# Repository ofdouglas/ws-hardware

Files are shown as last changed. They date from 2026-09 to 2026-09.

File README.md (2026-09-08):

# WireSpaces hardware

Status: draft · Owner: project maintainer · Updated: 2026-09-06

Hardware experiments for WireSpaces (WS), starting with a small four-MCU bench board. This repository is a design scaffold, not a fabrication release. Board1 has a complete draft KiCad schematic, reconciled counts and [initial unrouted PCB placement](boards/board1/kicad/placement.md). Schematic approval, detailed placement/routing and hardware qualification remain. This is not a validated fabrication or ordering package.

## Start here

1. Read [agent instructions](AGENTS.md) and [document/decision conventions](docs/DESIGN_PRINCIPLES.md).
2. Read [system context](docs/WIRESPACES_SYSTEM_CONTEXT.md) and [family architecture](docs/HARDWARE_ARCHITECTURE.md).
3. Check the [ADR index](docs/decisions/README.md) before changing a decision.
4. Work from [Board 1 requirements](boards/board1/requirements.md), then its [current design overview](boards/board1/README.md), [pinmap](boards/board1/pinmap.md) and [BOM](boards/board1/bom_internal.csv).

```text
ws-hardware/
├── AGENTS.md
├── README.md
├── docs/
│   ├── WIRESPACES_SYSTEM_CONTEXT.md
│   ├── HARDWARE_ARCHITECTURE.md
│   ├── DESIGN_PRINCIPLES.md
│   ├── PART_SELECTION_POLICY.md
│   ├── SOURCE_NOTES.md
│   └── decisions/                 # index, template, numbered ADRs
├── boards/board1/
│   ├── README.md
│   ├── requirements.md
│   ├── pinmap.md
│   ├── bom_internal.csv
│   └── kicad/                    # board CAD workspace; see board status
└── libraries/
    ├── symbols/
    └── footprints/
```

Board 1's Rev A networking scope has one STM32 gateway, three SAM leaves, two shared CAN-FD buses, an onboard multidrop UART, a private SAM UART ring, USB power/VCP, one external RS-485, signal terminals for both CANs and RS-485 with ground, and debug access. The full bench backbone is future work. Exact MVP inclusion is controlled by the requirements status rows, not by this overview.

Use **Host**, `HostId`, `SrcHostId`, and `DestHostId`. A PC is a PC/test controller; a WS Host is a protocol identity and need not be a PC.

See [source provenance](docs/SOURCE_NOTES.md). Source drafts provide context, not automatic approval for added hardware. Keep small, reviewable changes with requirement IDs and evidence. Resolve the blocking questions in Board 1 requirements before schematic freeze.

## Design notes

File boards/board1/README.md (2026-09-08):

# Board 1 Rev A

Status: complete Rev A schematic and initial unrouted PCB placement in KiCad 7.0.11; gateway corrected by ADR-043. Part acceptance does not establish electrical or fabrication readiness.

Board 1 is a four-MCU WireSpaces lab: one STM32G473RBT6 gateway and three ATSAMC21G17A-AUT leaves. Each MCU connects to both shared CAN-FD buses and the onboard multidrop UART; the SAMs also form a private UART ring. The gateway provides USB VCP and one external ST3485EBDR RS-485 port. Both CAN pairs and RS-485 have terminal-block access with ground.

USB-B powers an independent FT232HL bridge through the TPS22810 attachment ramp. FTDI PWREN# enables the TPS560430 main 3.3 V converter through MC74HC1G14DBVT1G. SN74LV125APWR isolates VCP TX/RX/RTS/CTS when main power is off. Rev A requires an active PC and must fit the 500 mA configured USB budget; full-load and startup qualification remain open.

The gateway targets 168 MHz and 12 Mbaud VCP. All four MCUs and the FTDI have independent selected 12 MHz crystals and initial load capacitors. Other link rates still need qualification. Each MCU has SWD, a dedicated 115200-baud text UART, a combined 1x8 timing/debug header and an LED; a fifth LED indicates board power. General-purpose breakouts are deferred under ADR-041. Seven 1×2 communications measurement headers expose both CAN pairs, RS-485, all three directed UART-ring hops and UART_MD per ADR-046; twelve rail/reset/boot/core pads and six ground headers remain.

## Current design documents

| Topic | Working document |
|---|---|
| Complete editable CAD and review PDF | [KiCad project](kicad/README.md) |
| Scope and authoritative question status | [Requirements](requirements.md) |
| Accepted decisions; do not routinely reopen | [ADR register](../../docs/decisions/README.md) |
| Parts, quantities, evidence | [BOM view](BOM.md), [CSV](bom_internal.csv), [remaining selections](remaining_parts.md) |
| Unfinished implementation choices | [Decision checklist](unfinished_decisions.md) |
| USB input, sequencing and current estimates | [USB input](usb_input.md), [model maintenance](models.md) |
| Bridge, EEPROM, VCP isolation and recovery | [USB VCP](usb_vcp.md) |
| Main converter and distributed capacitors | [Buck](buck_tps560430.md), [decoupling](decoupling.md) |
| PHYs, protection and UART_MD | [Interfaces](interfaces.md) |
| External bus networks | [Termination](termination.md), [RS-485 bias](rs485_bias.md) |
| Oscillators and clock trees | [Crystal networks](crystal_networks.md), [clocking](clocking.md) |
| MCU allocation and breakout details | [Pinmap](pinmap.md), [Timing headers](timing_headers.md) |
| Existing library artifacts and checks | [Symbol catalog](../../libraries/symbols/README.md), [IC coverage](../../libraries/symbols/remaining_ic_symbol_checks.md) |

Use Host/HostId terminology. Requirements own scope and question status; accepted ADRs own decisions; CSV owns parts and quantities. Topic notes explain the current implementation without accepting new circuitry. Reviewed symbols do not imply a completed, validated board schematic or layout.

## Deferred scope

External 24 V power, additional transceivers (including CAN3 and the second Board 1 point-to-point RS-485), the full bench backbone and FPGA/fault instrumentation are later work. RS_485_MULTIDROP is descoped for Board 1, retained in the overall bench architecture. No future footprint or pin reservation is implied.

All MCU, network and connector sections are captured. The review corrected STM32 physical-pad errors and finalized timing interrupts, ordinary reset/boot, interface defaults and probe access. All components are now approximately placed on the [native PCB](kicad/board1.kicad_pcb), with the terminal opposite USB; see [placement notes and preview](kicad/placement.md). Remaining work is schematic approval/ERC, detailed placement/routing and bring-up, as staged in the requirements register.

ADR-042 fixes the timing/debug header pin order and adds 330 ohm near each of its six MCU signal pins (24 total). Automated CBUS reset/BOOT0 recovery is deferred to Rev B; Rev A retains ordinary reset, BOOT0-low defaults and independent SWD programming.

Checks: native KiCad export and full-board checker pass for239 schematic objects / 879 pins; the PCB connectivity is checked against the same native schematic. Prior G474 MCU/workbook evidence is qualified by the ADR-043 correction note. Initial-placement DRC found no component collisions; expected unrouted connections, SWD internal pad-clearance findings and USB edge-silk cleanup remain. ERC has not run (KiCad7CLI lacks it); no hardware validation. See [complete capture notes](kicad/README.md) and [placement checks](kicad/placement.md#checks-performed).

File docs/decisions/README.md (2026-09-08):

# Decision register

Status: draft index · Authority: individual accepted ADRs

## Current authority map

Read this map before the chronological register. An accepted ADR may retain only some clauses; its historical decision text does not override later accepted decisions. Part selection never closes qualification questions. Retain both ADR-026 IDs and cite their filenames; no renumbering is authorized.

| Topic | Current authority and surviving scope | Implementation |
|---|---|---|
| Family terminology / Rev A boundary | ADR-003/004/007; RS_485_MULTIDROP deferred for Board 1, retained for family | [Requirements](../../boards/board1/requirements.md) |
| USB power / input | ADR-001 domain policy; ADR-013 isolation; ADR-040 direct PWREN# enable/startup; ADR-019 ramp topology; ADR-022 47 nF/no supervisor; ADR-024 inverter; ADR-015/016 ESD scope; ADR-027/028/029/030 passives | [Input](../../boards/board1/usb_input.md), [VCP](../../boards/board1/usb_vcp.md) |
| Main buck | ADR-021 TPS560430 and total 500 mA criterion; ADR-025 exact LC/passives; no 90% floor or SC189 Cout ceiling | [Buck](../../boards/board1/buck_tps560430.md) |
| Decoupling | ADR-010 MCU/bypass allocation only; [ADR-026 core](026-sam-core-ceramic.md) ceramic; ADR-027 MPNs; ADR-025 local output | [Decoupling](../../boards/board1/decoupling.md) |
| Crystals / clocks | ADR-005 timing targets; ADR-014 MCU crystals; ADR-017 separate FTDI strategy; ADR-030 exact FTDI crystal; ADR-031 initial load caps and REF correction | [Clocks](../../boards/board1/clocking.md), [crystals](../../boards/board1/crystal_networks.md) |
| CAN / RS-485 | ADR-002 TCAN3413; ADR-034 ST3485/termination; ADR-035 termination MPNs; ADR-036 bias; ADR-037 CAN TVS; ADR-038 restricted RS-485 TVS envelope; ADR-039 bias MPNs | [Interfaces](../../boards/board1/interfaces.md), [termination](../../boards/board1/termination.md), [bias](../../boards/board1/rs485_bias.md) |
| Onboard UART | ADR-033 second LV125 driver; ADR-039 support resistors; actual rate unqualified | [Interfaces](../../boards/board1/interfaces.md) |
| Debug / recovery / connectors | ADR-011 SWD; ADR-018 EEPROM; ADR-042 defers ADR-023 CBUS recovery; [ADR-026 connectors](026-reva-connectors.md); ADR-032 text UART; ADR-039 rail/reset/boot/core pads and ground access; ADR-046 communications headers; ADR-041/042 combined timing/debug headers and series resistors; USR-37 shared pull-downs (timing_headers.md) | [Pinmap](../../boards/board1/pinmap.md), [remaining work](../../boards/board1/remaining_parts.md) |
| LEDs / GPIO | ADR-007 scope; ADR-029 LEDs; ADR-039 LED resistors; ADR-041 timing interface replaces general GPIO breakouts | [BOM](../../boards/board1/BOM.md) |
| Assembly / sourcing | ADR-009 plus current maintainer package rules; DigiKey-only sourcing policy | [Part policy](../PART_SELECTION_POLICY.md) |

Completion of an earlier proposal (for example ADR-024 pulls by ADR-028/030) is not wholesale supersession. Metadata lists replacements only; implementation links and this map also show completions. New engineering changes still require explicit acceptance and a new ADR where applicable.

Allocation-note reconciliation (2026-09-07): [pinmap](../../boards/board1/pinmap.md) and its workbook now distinguish current selections from unfinished implementation. [Unfinished decisions](../../boards/board1/unfinished_decisions.md) references the existing board questions; this editorial cleanup adds no accepted decisions or verified allocations.

## Chronological register

| ID | Title | Status | Scope |
|---|---|---|---|
| [ADR-001](001-usb-power.md) | USB power and independent VCP bring-up (power/isolation architecture) | accepted | Board 1 MVP |
| [ADR-002](002-can-transceivers.md) | CAN-FD transceiver selection (TCAN3413DR) | accepted | Board 1 CAN1/CAN2 |
| [ADR-003](003-terminology-and-mvp-boundary.md) | Host terminology and reduced first PCBA | accepted | Repository / Board 1 |
| [ADR-004](004-board1-mcu-baseline.md) | MCU baseline (gateway corrected by ADR-043; SAM selection retained) | accepted | Board 1 |
| [ADR-005](005-clock-and-vcp-speed.md) | Crystal clocks and 12 Mbaud gateway VCP | accepted | Board 1 Spin A |
| [ADR-006](006-reva-external-buses.md) | Rev A links and terminal access | superseded | Board 1 Rev A |
| [ADR-007](007-board1-rs485-power-scope.md) | Board 1 RS-485 scope, LEDs and GPIO | accepted | Board 1; bench multidrop retained |
| [ADR-008](008-main-buck-efficiency.md) | Main buck efficiency proposal | superseded | Board 1 main 3.3 V rail |
| [ADR-009](009-assembly-package-policy.md) | Assembly and package policy | accepted | Project-wide |
| [ADR-010](010-sc189-and-decoupling.md) | SC189 and Rev A decoupling | accepted | Board 1 main rail |
| [ADR-011](011-swd-debug-access.md) | Independent Cortex SWD headers and owned probes | accepted | Board 1 debug |
| [ADR-012](012-common-12mhz-crystal.md) | Common leaded 12 MHz crystal | superseded | Board 1, five oscillators |
| [ADR-013](013-enable-control-uart-isolation.md) | SC189 enable control and SN74LV125APWR | accepted | Board 1 Rev A; replaces ADR-001 main-switch implementation |
| [ADR-014](014-smaller-12mhz-crystal.md) | Smaller leaded 12 MHz crystal | accepted | Four MCU crystals; FTDI scope superseded by ADR-017 |
| [ADR-015](015-usb-data-esd.md) | RCLAMP0504S.TCT USB data ESD | accepted | Board 1 Rev A |
| [ADR-016](016-usb-protection-scope.md) | USB ESD and hot-plug protection scope | accepted | Board 1 Rev A |
| [ADR-017](017-separate-ftdi-crystal.md) | Separate accurate FT232HL crystal | accepted | Strategy; exact MPN subsequently accepted ADR-030 |
| [ADR-018](018-ftdi-eeprom.md) | AT93C56B-SSHM-B configuration EEPROM | accepted | Board 1 FT232HL bridge |
| [ADR-019](019-simple-vbus-input.md) | Simple slew-controlled USB input | accepted | Board 1 Rev A; replaces direct input attachment in ADR-013 |
| [ADR-020](020-ftdi-supply-reset.md) | FTDI supply-qualified reset with TLV803E | superseded | Board 1 Rev A; adds supervision to ADR-019 |
| [ADR-021](021-tps560430-main-buck.md) | TPS560430 main buck and USB-current criterion | accepted | Replaces ADR-010 converter/filter and efficiency floor |
| [ADR-022](022-fast-input-ramp.md) | Fast TPS22810 ramp without external FTDI supervisor | accepted | Board 1 Rev A |
| [ADR-023](023-cbus-gateway-recovery.md) | Dedicated CBUS gateway reset and BOOT0 | superseded | Rev A recovery deferred by ADR-042 |
| [ADR-024](024-pwren-inverter.md) | MC74HC1G14DBVT1G PWREN# inverter | accepted | Implements ADR-013; SMF6.0A alone retained |
| [ADR-025](025-buck-passives.md) | TPS560430 local passive MPNs | accepted | Five components; four unique parts |
| [ADR-026](026-reva-connectors.md) | Rev A debug, bus and GPIO connector MPNs | accepted | Implements ADR-007/011; B1-B009/022/027 |
| [ADR-026](026-sam-core-ceramic.md) | Ceramic SAM VDDCORE capacitors | accepted | Supersedes ADR-010 dielectric restriction |
| [ADR-027](027-ceramic-capacitor-mpns.md) | General ceramic capacitor MPNs | accepted | Decoupling and input timing; completes SAM core selection |
| [ADR-028](028-10k-pullup-resistor.md) | Common 10 kohm pull-up resistor | accepted | B051/B054 and bridge support |
| [ADR-029](029-led-vbus-components.md) | Orange LEDs and VBUS damping parts | accepted | B024/025/046/047 |
| [ADR-030](030-usb-crystals-support.md) | USB connector, crystal finalization and support resistors | accepted | REF tolerance conflict resolved by ADR-031 |
| [ADR-031](031-crystal-caps-ref.md) | Crystal capacitors and corrected REF resistor | accepted | Resolves ADR-030 REF tolerance conflict |
| [ADR-032](032-debug-uarts.md) | Independent MCU text debug UARTs | accepted | Four 115200-baud TX/RX/GND headers |
| [ADR-033](033-open-drain-uart-buffer.md) | Second SN74LV125APWR for onboard open-drain UART | accepted | B1-B066; implements B1-R003 |
| [ADR-034](034-rs485-termination.md) | ST3485EBDR and Rev A bus termination | accepted | B1-B021/067–070; B1-R026 |
| [ADR-035](035-termination-parts.md) | Exact termination resistor and jumper MPNs | accepted | B1-B067–070; B1-R026 |
| [ADR-036](036-rs485-bias.md) | RS-485 330 ohm bias network | accepted | B1-B071; B1-R016/021 |
| [ADR-037](037-can-tvs.md) | ESD2CAN24DBZRQ1 CAN TVS arrays | accepted | B1-B072; B1-R009/017 |
| [ADR-038](038-rs485-tvs.md) | ESDS452DBZR and restricted bench voltage envelope | accepted | B1-B073; B1-R016/017 |
| [ADR-039](039-bom-closeout-selections.md) | Resistors, UART support, header cuts and test access | accepted | B1-B008/011/026/027/059/071/074/075 |
| [ADR-040](040-startup-and-vcp-enable.md) | Conventional FTDI startup and direct PWREN# VCP enable | accepted | Supersedes ADR-013 rail-valid /OE prerequisite only |
| [ADR-041](041-timing-debug-headers.md) | Combined per-MCU timing/debug headers; general breakouts deferred | accepted | B1-R025/027; B1-B027/059 |
| [ADR-042](042-header-resistors-recovery-scope.md) | Header series resistors and Rev A recovery scope | accepted | Exact pin order, 24 series resistors; automated recovery deferred to Rev B |

| [ADR-043](043-gateway-part-correction.md) | Gateway transcription correction to STM32G473RBT6 | accepted | Supersedes ADR-004 gateway MPN only |

| [ADR-044](044-yageo-crystal-load-capacitors.md) | YAGEO 33 pF crystal load capacitors | accepted | Supersedes ADR-031 33 pF MPN only |

| [ADR-045](045-yageo-27pf-crystal-capacitors.md) | YAGEO 27 pF FTDI crystal capacitors | accepted | Supersedes ADR-031 27 pF MPN only |

| [ADR-046](046-communications-measurement-headers.md) | Communications measurement headers | accepted | Supersedes ADR-039 communications copper-pad scope; seven 1x2 headers including all UART-ring hops |

Use [template.md](template.md); next ID: ADR-047. Numbering is permanent.

Historical collision: both [connector selection](026-reva-connectors.md) and [ceramic SAM core selection](026-sam-core-ceramic.md) carry ADR-026. Preserve both IDs and histories; use the filename-qualified reference to distinguish them. BOM references now do this explicitly.

ADR-027 accepts the exact SAM core capacitor. ADR-030 finalizes the FTDI crystal. ADR-031 resolves the REF tolerance conflict and accepts oscillator load capacitors. These subsequent decisions do not erase earlier history.

Before changing an accepted choice, read the ADR and its evidence. A superseding decision requires explicit maintainer acceptance; part-selection acceptance alone does not establish implementation verification.

Implementation evidence: [library migration and TPS22810 DBV symbol](../../libraries/symbols/README.md) implements ADR-004/019/022. Archived SC189 remains superseded by ADR-021. No ADR status or numbering changed; board qualification questions remain open.

Additional implementation evidence for ADR-002/018/021: [exact-part symbols and checks](../../libraries/symbols/symbol_checks.md). Existing accepted decisions and open board qualifications are unchanged.

Implementation evidence: [remaining IC symbols and BOM coverage](../../libraries/symbols/remaining_ic_symbol_checks.md) implements the existing selected parts, including ADR-037/038. No decision acceptance or electrical qualification is changed.

Full Rev A schematic implementation (2026-09-07): [complete native CAD](../../boards/board1/kicad/README.md) and corrected pinmap/BOM implement the existing accepted scope. Routine defaults and connector footprints are recorded as engineering choices. No ADR acceptance or scope changed.

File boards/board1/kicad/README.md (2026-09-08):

# Board 1 KiCad project — complete schematic and initial PCB placement

Gateway correction (2026-09-07): STM32G473RBT6 is selected and captured per [ADR-043](../../../docs/decisions/043-gateway-part-correction.md). DS12288 references and older workbook/PDF snapshots below are prior G474 evidence, not G473 qualification. Recheck exact G473 AF/electrical limits under B1-Q005/008 before schematic approval.

Completed 2026-09-07 with KiCad 7.0.11, native schematic format20230121, revision A-draft. Open [board1.kicad_pro](board1.kicad_pro). The editable source is the authority for implemented connectivity. The [native PCB](board1.kicad_pcb) now has all components approximately placed, with no tracks, vias or zones. See [placement notes and checks](placement.md) and the [preview](review/board1-initial-placement.png). The outline and placement are provisional; no fabrication outputs have been created.

| Page | Source | Contents |
|---|---|---|
| 1 | [Overview](board1.kicad_sch) | Hierarchy and scope |
| 2 | [Power](power.kicad_sch) | Preserved USB input/ramp, buck, enable and power LED |
| 3 | [USB](usb_bridge.kicad_sch) | Preserved FTDI/EEPROM and four-channel VCP isolation |
| 4 | [Gateway](gateway.kicad_sch) | STM32G473, supplies, crystal, reset/BOOT0, SWD and timing/debug |
| 5–7 | [SAM0](sam0.kicad_sch), [SAM1](sam1.kicad_sch), [SAM2](sam2.kicad_sch) | Three independent SAMC21 circuits and headers |
| 8–9 | [CAN A](can_a.kicad_sch), [CAN B](can_b.kicad_sch) | Eight PHYs, per-PHY standby defaults and endpoint termination |
| 10 | [Interfaces](interfaces.kicad_sch) | UART_MD quad driver, RS-485/defaults/bias/termination, shared timing pulls |
| 11 | [Access](access.kicad_sch) | External terminal block, three TVS arrays, six ground headers, twelve test pads and seven communications headers |

[Complete 11-page review PDF](review/board1-complete.pdf). The earlier two-page power/USB PDF and capture_manifest.json are retained as historical capture evidence; the complete PDF is also an older capture snapshot. Use native schematic files and [complete_manifest.json](complete_manifest.json) for current review. The revised access page is available as [SVG](review/board1-access.svg).

## Capture and component reconciliation

239 schematic component objects comprise 227 fitted components/connectors and 12 PCB copper test pads; two removable CAN shunts are assembly accessories without additional PCB footprints. The strip-stock purchase and testpad/shunt exceptions are explicit in [schematic_bom_allocations.json](schematic_bom_allocations.json). All populated components have MPNs, references and footprint assignments in [bom_internal.csv](../bom_internal.csv); no count remains TBD. Evidence status stays unverified until the relevant approval checks finish.

The original 52 power/USB components retain their pin mappings, MPNs and values. Only hierarchy and the VBUS_RAW global name scope changed. The four GW_VCP nets now reach the gateway.

PCB spacing follow-up: the SAM timing headers are farther from the terminal,
the lower IC groups use more of the lower-right area, and every testpad has
function silkscreen and nearby ground access. See [test access](placement.md#test-access).

Routine completion choices: four reset pull-ups, three SAM SWCLK pull-ups and gateway BOOT0 pull-down use10k B080; NRST uses100n B081 and each SAM RESET uses10n B082. Eight10k CAN STB pull-ups B083 establish explicit standby. Four RS-485 defaults B023 establish shutdown/idle, and four debug RX10k pull-ups B060 establish idle. These reuse selected MPNs; they are engineering choices within authorized scope, not newly maintainer-accepted decisions. No automatic CBUS recovery or future circuitry was added.

Each timing/debug header has six independent330ohm branches near its MCU. Shared SYNC/TRIG each have one10k pull-down before fanout. Six separately purchased two-pin ground headers reuse PRPC002SAAN-RC and do not consume the eight spare positions in the timing-header strip.

B036 reconciles to37 actual main-rail100n bypasses; two unused planning reserves were removed. Main nominal capacitance becomes34.41uF. B007/B010 residual aggregates now have zero parts; B023 andB060 are fully enumerated. [Decoupling](../decoupling.md) and the generated BOM use the captured counts.

## Evidence and corrections

The MCU review found and fixed an actual workbook error in STM32 pads19–29: LED PA5 is pad19, VSSA pad27, VREF+ pad28 and VDDA pad29. Stable physical-pad IDs were retained. [Pinmap](../pinmap.md) links the corrected workbook and [MCU capture plan](../mcu_capture_plan.json). All208 MCU pads were independently compared to that plan/workbook and a fresh KiCad netlist. Timing interrupts are GWPC0/PC1 EXTI0/1 and SAMPA02/PA03 EXTINT2/3; events use GWPC2/PC3 and SAMPB08/PB09.

The RS-485 RO-to-PC11 high-level screen passes: ST3485 VOH>=2.0V at4mA; PC11 FT_f supports alternate guaranteed VIH=0.49VDD+0.26, at most1.9015V with3.35V main DC rail (ST DS12288Rev6 Table54pp128–129). This is a static limit comparison, not a measured waveform margin. FTDI-to-LV125 still has the previously recorded55mV high-level DC headroom before ripple/ground error; use short paths and validate12Mbaud at bring-up.

[Footprint checks](footprint_checks.md) record manufacturer-drawing checks and the two new portable connector footprints. All source symbols are embedded. The standard STM32 exact variant is flattened from its KiCad library inheritance without changing its pins. The existing Board1 FT232HL symbol retains corrected VCCD/EECLK/EECS electrical types. PWR_FLAGs are annotations, not physical circuitry.

## Checks and remaining stages

Run `python3 scripts/check_board1_complete.py` from the repository root. It exports native KiCad XML and checks239 objects/879 pins, explicit NCs, fields, exact numbered-pad coverage, all BOM quantities and independent topology rules for MCU ownership, SWD, header branches, ring, UART_MD, CAN polarity/termination/protection, RS-485, separate SAM core rails and preserved power/USB circuitry. The fresh PCB/netlist comparison and independent topology checks pass. The full schematic/BOM check now stops at the preexisting B059 purchased-header MPN mismatch; see placement notes. The older PDF was rendered and reviewed at its original capture stage. Capture scripts are one-time provenance, not the editing authority; do not rerun over subsequent manual CAD edits.

ERC has not run: KiCad7 CLI exposes schematic export but no ERC command. Run Eeschema ERC before schematic approval. PCB DRC was run through the Python API for [initial placement](placement.md#checks-performed); it is not a clean fabrication DRC. Exact assembly/mating, detailed placement and routing remain layout checks. No hardware validation is claimed. The stale ADR-040 research link now points to its verified historical Git revision; the accepted decision text is unchanged. The current document and purchasing audits flag the preexisting B027/B059 purchase reconciliation; see ../digikey_upload_review.md.

Manual bench operating limits: external timing/debug sources must be3.3V, and drive only while3V3_SYS is on; connect after configuration and disconnect before power-off/suspend. Series resistors do not provide power-off isolation. Disable/disconnect the RS-485 peer before local power-off/suspend because the accepted330ohm bias can feed main power. SWD VTref is sense only. First programming uses connect-under-reset with external bus peers disconnected, then firmware establishes PHY defaults. These limits avoid adding automatic isolation to this prototype.

Bring-up: program/read back FTDI EEPROM per [USB VCP](../usb_vcp.md); check current/startup/suspend, MCU reset/boot, crystal start/frequency,12Mbaud VCP and chosen CAN/UART rates. SAM EIC uses synchronous active-run mode; clear flags after enable and heed DS80000740T errata for the fitted revision. Measurements are not draft-capture blockers.

Primary references: [STM32 DS12288](https://www.st.com/resource/en/datasheet/stm32g474rb.pdf), [SAM DS60001479J](https://ww1.microchip.com/downloads/aemDocuments/documents/MCU32/ProductDocuments/DataSheets/SAM-C20-C21-Family-Data-Sheet-DS60001479J.pdf), [TCAN3413](https://www.ti.com/lit/ds/symlink/tcan3413.pdf), [ST3485](https://www.st.com/resource/en/datasheet/st3485eb.pdf), [LV125](https://www.ti.com/lit/ds/symlink/sn74lv125a.pdf), [FT232H v2.2](https://www.ftdichip.cn/Support/Documents/DataSheets/ICs/DS_FT232H.pdf). FTDI current errata/on-hand silicon reconciliation remains an approval check; no retrieved source attachments were edited.

ADR-046 communications access: J19/J20 CAN H,L; J21 RS-485 A,B; J22/J23/J24 ring01/ring12/ring20 signal,GND; J25 UART_MD signal,GND. All are fitted 1×2 0.1-inch headers with function and pin-order silkscreen. TP1–TP12 remain copper pads.

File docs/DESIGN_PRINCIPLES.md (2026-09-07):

# Design principles and document conventions

Status: draft policy · Authority: repository workflow · Updated: 2026-09-06

Prefer a small board that brings up reliably, exposes the intended networking experiments, and can be inspected and reworked. Add complexity when a concrete experiment needs it. Provide debug, reset, rail measurements, and observable links before sophisticated instrumentation. Keep power-up and unpowered-interface behavior explicit.

## Authority

1. Explicit current maintainer instructions, with provenance recorded.
2. Accepted ADRs within their stated scope.
3. Accepted board requirement rows for implementation scope; family conventions apply only where that scope includes them.
4. Proposed requirements, architecture drafts, source notes, and diagrams are planning inputs.

If instructions and recorded decisions conflict, record the conflict and reconcile the affected records before implementation. An accepted ADR does not silently accept every row linked to it. Schematics encode implemented connectivity; verified pinmaps document reviewed allocation; the BOM records intended assembly. Disagreement among these is a defect to resolve, not a new decision.

## Status vocabulary

| Object | Allowed status | Meaning |
|---|---|---|
| Document | draft, reviewed | Editorial maturity; never bulk acceptance of its contents |
| Requirement / ADR | proposed, accepted, deferred, rejected, superseded | Candidate; explicit decision; outside current scope; declined; replaced with link |
| Pin/BOM evidence | unverified, verified | Primary-source checks absent or completed with evidence |
| Open question | open, resolved | Unanswered, or answered with decision/evidence link |

`TBD` means unknown; `NA` means inapplicable. Avoid blank cells except where a file schema explicitly permits them. Future means scope, not a promise to populate or reserve pins. DNP means a real designed footprint omitted from an assembly variant; it is not interchangeable with deferred.

Keep stable IDs: `B1-Nxx` nodes, `B1-Lxx` links, `B1-Rxxx` requirements, `B1-Qxxx` questions, `B1-Pxxx` pin rows, `B1-Bxxx` BOM rows, `ADR-NNN` decisions. IDs are never reused. Board requirements own question status; other documents reference question IDs rather than duplicate answers.

## Decision discipline

Check `docs/decisions/README.md` before proposing a choice. Accepted decisions stay settled until new evidence or an explicit changed requirement justifies a replacement ADR. New ADRs include alternatives, consequences, evidence, and precise acceptance criteria. Record accepted date and who/what instruction accepted it. Do not rewrite accepted history to resemble a fresh decision.

Proposals may guide reversible planning but do not authorize fabrication. Routine edits within accepted scope need no fresh decision. Keep one change focused; include requirement/ADR IDs and update derived files in the same change.

## Proportionate design and stopping rules

Rev A is a manually operated bench prototype. Use conventional manufacturer application circuits and the accepted operating scope. Distinguish behavior needed during normal operation from later bring-up observations and hypothetical faults. Do not silently strengthen requirements into guaranteed operation across arbitrary brownouts, corrupt configuration, abnormal external drive or every supply-collapse order. Actual absolute-maximum violations, incompatible logic levels and output contention in intended use remain material concerns.

A missing guarantee is uncertainty, not automatically a failure. Identify a plausible mechanism and material consequence before expanding research or proposing mitigation. Use existing engineering allowances for negligible contributions; refine a calculation when it can change a component, connection or budget decision. Do not repeatedly recheck settled evidence without a relevant change.

Routine reversible implementation choices can be made within accepted scope and documented in the circuit/BOM notes. Reserve ADRs for meaningful scope, architecture or durable policy decisions, and for changes to accepted ADRs. Maintainer acceptance and engineering evidence are separate; passing a pin check need not wait for bench tests, and an accepted circuit need not be called electrically verified.

Classify remaining work in the existing question's resolution text or working checklist without creating another authority register:

| Disposition | Treatment |
|---|---|
| Implementation detail | Resolve while capturing; record chosen wiring/value and rationale |
| Schematic check | Verify relevant pins, mux, limits and connectivity before schematic approval |
| Bring-up check | Measure on assembled hardware; does not block draft capture |
| Deferred / no change | Outside scope or insufficient reason to alter the conventional circuit |

For a blocker, state trigger, mechanism, consequence, evidence and affected gate. Block only the dependent work. A broad open question may contain a settled decision and pending measurements: record the settled subitem explicitly rather than repeatedly reopening it. No need to close the whole question prematurely.

Stop when the evidence supports an implementation and further research is unlikely to change it. If uncertainty is material, define one bounded next check. Reviews should prioritize concrete errors and can conclude “no change needed.” Extra complexity needs a demonstrated benefit against an accepted requirement.

## Review stages

- Draft capture: draw settled circuitry and resolve routine details; label unresolved connections/proposals. Do not require future measurements or complete layout qualification to start.
- Schematic approval: check exact package pins/mux, supply and logic compatibility, clocks/reset/debug, PHY behavior, connector numbering and symbol mappings; reconcile BOM and resolve or document actual ERC findings. Review relevant current/startup calculations. Mechanical footprint qualification must finish before layout commitment.
- Layout approval: review land patterns, placement/routing for intended rates, test access and silkscreen; reconcile CAD/pinmap/BOM and actual DRC findings.
- Prototype release: review assembly BOM and fabrication outputs tied to a revision, plus a finite bring-up checklist. Unperformed bring-up measurements are expected at this stage and must not be represented as passed.
- Bring-up: measure startup, power, clocks, programming and link performance under intended conditions. Investigate faults revealed by results. Broader production/compliance qualification is a separate scope decision.

These stages define when work is needed, not claims that checks have passed. Active summaries must show current decisions; remove withdrawn recommendations and their derived parts/calculations. Historical accepted ADR text remains with an explicit supersession notice.

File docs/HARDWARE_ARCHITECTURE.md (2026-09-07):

# Hardware family architecture

Status: draft · Authority: family direction, conditional on board scope · Source: SRC-ARCH

The September 1 bench draft describes a larger system than Board 1 MVP. Its “freeze summary” is not a blanket rev-1 requirement after USR-01. [Board 1 requirements](../boards/board1/requirements.md) own the MVP boundary.

## Conventions for the proposed MVP

| Area | Direction | Controlling record |
|---|---|---|
| Roles | One gateway and three leaves; physical labels are not HostIds | B1-R001; ADR-004 |
| CAN | Two independent shared CAN-FD buses, all four nodes on each | B1-R002; ADR-002 |
| UART | Shared open-drain medium plus private directed leaf ring | B1-R003, B1-R004 |
| Bring-up | USB 2.0 Standard-B power and dedicated FT232HL VCP; no dependency on native USB | B1-R005; ADR-001 |
| Power | Accepted independent bridge domain and controlled main-board power; TPS560430 selected ADR-021; TPS22810/47 nF input ramp ADR-022; SN74LV125APWR isolation ADR-013 and MC74HC1G14DBVT1G enable inverter ADR-024; qualification open | B1-R006; B1-Q002 |
| Debug | Independent SWD access to each MCU; accessible reset and rail measurements | B1-R007, B1-R008 |
| Connectors | Pinouts, polarity, voltage, and termination state documented at each interface | B1-Q004 |

No connector family, pin numbers, transceiver, oscillator, protection network, or supply capability is validated here.

## Future/full bench contract — excluded from MVP unless explicitly promoted

| Area | Inherited direction | MVP treatment |
|---|---|---|
| Signal backbone | 17 twisted pairs; short approximately 10 cm FFTP-style jumpers and polarized headers | Deferred; no connector or pin allocation implied |
| CAN1/2/3 | Passive IN-to-OUT paths; each independently terminable even without a local PHY | Applies to future backbone boards only |
| CAN3 local port | STM32 connection with initial DNP PHY in full draft | Deferred, including footprint and termination |
| RS-485 | RS_485_MULTIDROP (historical SHARED) passes through; RS_485_LEFT/RIGHT terminate separate p2p hop segments and require forwarding | Rev A one p2p port; expanded Board 1 LEFT/RIGHT only; bench multidrop retained |
| 24V_AUX | Optional separate two-conductor passive trunk; nominal 24 V, draft chain maximum 2 A | Deferred; not a Board 1 input rating |
| Local power tap | Protected branch converts to 5 V; downstream trunk never depends on local regulation/firmware | Deferred |
| Source protection | One external 24 V source per chain; reverse polarity/current protection at injection; isolate USB and local 5 V sources | Conditional on future multiple-input implementation |
| Auxiliary output | Protected 5 V, draft 500 mA maximum when supply budget permits | Deferred from Rev A; no USB-only guarantee |
| Test control | External single SPI master; ordinary DUT boards slaves; MCP23S17 family preference | Deferred |
| Triggers/timing | TEST_TRIG0/1, SYNC inputs; selected TIMING0/1 drivers, others high-Z | Deferred |
| Fault injection | External trigger plus local deterministic logic; safe inactive startup; independent of DUT firmware | Deferred |
| Ethernet/T1S | Ordinary Ethernet separately cabled; backbone pair reserved for T1S | Deferred |
| FPGA | Timing capture, traffic generation, segment bridges and controlled frame loss | Future separate instrumentation board |

The draft pair map is functional, not an approved connector pinout: 1–3 CAN1/2/3; 4 RS485_SHARED (RS_485_MULTIDROP, retained for bench); 5 RS485_HOP; 6 T1S_RESERVED; 7–10 TEST_SPI SCLK/MOSI/MISO/CS each with GND; 11 SYNC/GND; 12–13 TEST_TRIG0/1 with GND; 14–15 TIMING0/1 with GND; 16–17 spare. Pin order and electrical details remain unapproved.

Normal WS operation must remain useful without the test-control plane. A future backbone board must explicitly adopt the applicable contract; being a WireSpaces board alone does not impose every connector or PHY.

Board 1 clock/VCP requirements (ADR-005): 168 MHz gateway, 12 Mbaud VCP with RTS/CTS and four-signal power-off isolation; each MCU has its own external crystal. Crystal frequencies and remaining clock trees are implementation work in B1-Q008.

Rev A interface scope: ADR-007 includes both CANs and one RS-485 with ground, plus GPIO breakouts; additional transceivers and external power remain deferred. Canonical CAN names are FD_CAN_A/FD_CAN_B (historical CAN1/CAN2).

ADR-007 is Board 1-specific. Its omission of RS_485_MULTIDROP does not remove that function from the family architecture. Board 1 also requires five LEDs total and spare GPIO breakouts; parts and four GPIOs/MCU are selected under ADR-029/039; electrical qualification remains open.

## Future Board 1 power clarification — USR-12

The intended external-power chain is protected 24 V -> regulated 5 V -> FTDI supply branch and sequenced 3.3 V converter -> MCUs/transceivers. Thus the downstream 3.3 V converter need not accept 24 V. External power remains deferred from Rev A.

Implementation proposal for that later revision: select between USB VBUS and the locally generated 5 V with reverse-current blocking before feeding the system domains; never directly tie the two sources together. Revisit bridge USB-presence sensing, self-powered configuration and main-board enable policy for externally powered operation. Existing Rev A active-PC/suspend behavior stays authoritative until that revision adopts a new power contract. Two-stage efficiency is the product of stage efficiencies; Rev A efficiency is governed by the full-load 500 mA USB criterion in ADR-021, with no fixed 90% floor. The later 24 V path has no accepted converter efficiency target. See [current power model](../boards/board1/models.md).

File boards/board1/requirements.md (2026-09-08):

# Board 1 requirements

Status: draft · Authority: per-row status · Updated: 2026-09-07

All `proposed` rows are extracted or suggested starting requirements, not a frozen schematic specification. `accepted` applies only to explicit decisions. Unresolved values are staged according to DESIGN_PRINCIPLES.md; draft capture is now complete. Source IDs resolve in [SOURCE_NOTES](../../docs/SOURCE_NOTES.md).

The [unfinished implementation decisions](unfinished_decisions.md) checklist distinguishes remaining choices from verification of selected parts. Question status remains in this register; the 2026-09-07 allocation-note cleanup changes no acceptance or evidence status.

## Nodes — accepted MCU selection (B1-R001)

| ID | Label | Role | Exact selected MPN | Qty | Source |
|---|---|---|---|---:|---|
| B1-N01 | GW | Gateway | STM32G473RBT6 | 1 | ADR-043 maintainer correction |
| B1-N02 | SAM0 | Leaf | ATSAMC21G17A-AUT | 1 | SRC-ARCH §3.2; USR-15 / ADR-004 |
| B1-N03 | SAM1 | Leaf | ATSAMC21G17A-AUT | 1 | SRC-ARCH §3.2; USR-15 / ADR-004 |
| B1-N04 | SAM2 | Leaf | ATSAMC21G17A-AUT | 1 | SRC-ARCH §3.2; USR-15 / ADR-004 |

The PC is external test equipment. HostIds are deployment values, not physical node labels.

## Links — Rev A scope per ADR-007; implementation details pending

| ID | Net/group | Endpoints / direction | Medium | Rate | Requirement |
|---|---|---|---|---|---|
| B1-L01 | FD_CAN_A | GW, SAM0, SAM1, SAM2; shared | CAN-FD | TBD | B1-R002 |
| B1-L02 | FD_CAN_B | GW, SAM0, SAM1, SAM2; shared, separate from FD_CAN_A | CAN-FD | TBD | B1-R002 |
| B1-L03 | UART_MD | GW, SAM0, SAM1, SAM2; shared | Open-drain-equivalent UART; ADR-033 driver; ADR-039 pulls | TBD | B1-R003 |
| B1-L04 | RING_01 | SAM0 TX -> SAM1 RX | Point-to-point UART | TBD | B1-R004 |
| B1-L05 | RING_12 | SAM1 TX -> SAM2 RX | Point-to-point UART | TBD | B1-R004 |
| B1-L06 | RING_20 | SAM2 TX -> SAM0 RX | Point-to-point UART | TBD | B1-R004 |
| B1-L07 | UART_VCP | PC USB <-> bridge UART <-> GW | Dedicated USB-UART VCP | 12 Mbaud capability | B1-R005; B1-R014 |
| B1-L08 | RS485_EXT | GW <-> external endpoint | RS-485; point-to-point half-duplex; ADR-034 | Up to 12 Mbps | B1-R016; B1-R021 |
| B1-L09 | DEBUG_GW | GW MCU TX/RX to external adapter; GND | Dedicated 3.3 V logic UART proposal | 115200 baud | B1-R025 |
| B1-L10 | DEBUG_SAM0 | SAM0 MCU TX/RX to external adapter; GND | Dedicated 3.3 V logic UART proposal | 115200 baud | B1-R025 |
| B1-L11 | DEBUG_SAM1 | SAM1 MCU TX/RX to external adapter; GND | Dedicated 3.3 V logic UART proposal | 115200 baud | B1-R025 |
| B1-L12 | DEBUG_SAM2 | SAM2 MCU TX/RX to external adapter; GND | Dedicated 3.3 V logic UART proposal | 115200 baud | B1-R025 |

USR-04 targets several Mbaud for onboard UARTs, exact rates TBD. This replaces the older exploratory approximately 1 Mbit/s target; the open-drain electrical limit still requires validation. One ring UART per leaf uses TX to the next leaf and RX from the preceding leaf; GW is excluded from the ring.

## Requirement register

| ID | Scope | Status | Requirement | Verification / acceptance evidence | Basis / decision |
|---|---|---|---|---|---|
| B1-R001 | MVP | accepted | Populate exactly the four nodes above | Exact datasheets/errata, pin/resource review, schematic and BOM | USR-15; SRC-ARCH §3; ADR-004; B1-Q005 |
| B1-R002 | MVP | accepted | Attach all four nodes independently to CAN1 and CAN2; support simultaneous traffic | Eight PHY channels accounted for; electrical review; bench traffic at accepted rates | SRC-ARCH §4.1; ADR-002 |
| B1-R003 | MVP | accepted | Provide shared onboard open-drain UART among all four nodes | Review drive/pull-up/reset behavior; measure rise time and traffic at accepted rate | SRC-ARCH §5.1; USR-27; ADR-033; B1-Q003 |
| B1-R004 | MVP | accepted | Provide directed SAM0 -> SAM1 -> SAM2 -> SAM0 UART ring | Connectivity/pin review and traffic on each hop | SRC-ARCH §5.2 |
| B1-R005 | MVP | accepted | Provide USB 2.0 Standard-B power and dedicated FT232HL VCP to GW; native USB not required for bring-up | USB/interface review; PC enumeration and serial exchange | SRC-ARCH §7; USR-03; ADR-001 |
| B1-R006 | MVP | proposed | Operate normal networking from USB alone within a defined current budget | Approved startup/worst-case power analysis and measured rail/current limits | SRC-ARCH §8.4; ADR-001; B1-Q002 |
| B1-R007 | MVP | accepted | Give all four MCUs independent 10-pin Cortex SWD programming/debug headers and reset access | Independent connection, programming and reset of each MCU | USR-16; ADR-011; SRC-ARCH §7.3; B1-Q004 |
| B1-R008 | MVP | accepted | Expose twelve rail/reset/boot/core pads, six fitted ground headers and seven 1x2 0.1-inch communications headers: CAN A H/L, CAN B H/L, RS-485 A/B, each directed SAM ring hop signal/GND, and UART_MD signal/GND; provide concise functional silkscreen and local ground access | Schematic/layout accessibility, pin order and labeling review; probe access at bring-up | USR-33/38; ADR-039/046; B1-Q004 |
| B1-R009 | MVP | proposed | Define termination and protection for both CAN buses and any external interfaces | Electrical/topology review; observed bus waveforms at accepted limits | SRC-ARCH §4.3; B1-Q003/004 |
| B1-R010 | MVP boundary | accepted | Keep full inter-board signal/power backbone and deterministic fault injection out of first-PCBA requirements | Scope/BOM/CAD review shows no implicit inclusion | USR-01/02; ADR-003 |
| B1-R011 | MVP experiment | proposed | Support leaf bare-metal and RTOS experiments with simultaneous CAN/UART activity | Firmware demonstrations and recorded memory/queue use; quantitative thresholds TBD | SRC-ARCH §15; B1-Q006 |
| B1-R012 | MVP power | accepted | Use independent USB bridge power and controlled main-board power; provide power-off isolation on VCP TX/RX/RTS/CTS | Startup/suspend/resume and current/leakage measurements; circuit review | ADR-001; B1-Q002; B1-Q007 |
| B1-R013 | Spin A power scope | superseded | Exclusively USB-powered from an active PC; external connectors and advanced power architecture belong to later respins | Scope review; startup/suspend/resume validation of resulting circuit | User follow-up to USR-03; replaced by B1-R018 / ADR-006 |
| B1-R014 | Gateway VCP | accepted | Support 12 Mbaud with STM32 at 168 MHz, a 168 MHz USART kernel clock, short traces and available hardware RTS/CTS | Clock/mux review; full-duplex traffic, flow-control and isolation timing under load | USR-04; ADR-005; B1-Q008 |
| B1-R015 | MCU clocks | accepted | Give GW and each SAM its own external main crystal as the reference for high-speed link clocks | Oscillator/clock-tree review and startup/tolerance validation for all four MCUs | USR-04; ADR-005; B1-Q008 |
| B1-R016 | Rev A RS-485 | accepted | Provide one STM32 external RS-485 port alongside both CANs, all onboard UARTs and VCP | Peripheral/mux and schematic review; external link traffic | USR-05; ADR-006; B1-Q009 |
| B1-R017 | Rev A terminals | accepted | Expose FD_CAN_A, FD_CAN_B and RS-485 differential pairs plus one or two ground terminals | Connector continuity, labeling, termination and protection review | USR-05; ADR-006; B1-Q004 |
| B1-R018 | Rev A power/scope | superseded | USB-only active-PC operation; include B1-R017 signal terminals; defer external power, extra transceivers and further connectors to later revisions | Scope and power-state review | USR-03/05; ADR-001; ADR-006; replaced by B1-R022 |
| B1-R019 | Rev A LEDs | accepted | One controllable LED per MCU and one board power LED | Pin/resource and all-on current review | USR-06; ADR-007 |
| B1-R020 | Rev A GPIO | superseded | General spare-I/O breakouts deferred; replaced by B1-R027 timing interface | No general-breakout circuitry implied | USR-35; ADR-041 |
| B1-R021 | Board 1 RS-485 | accepted | External rate ceiling 12 Mbps; expanded Board 1 has LEFT/RIGHT p2p ports only; bench MULTIDROP remains in family architecture | Topology, rate and power review | USR-06; ADR-007; B1-Q009 |
| B1-R022 | Rev A power/scope | accepted | USB-only active-PC operation with bus terminals and timing/debug headers; external power and additional PHYs remain for later revisions | Scope and power-state review | ADR-001; ADR-007; replaces B1-R018 |
| B1-R023 | Main buck efficiency | accepted | Support conservative full networking load within 500 mA total USB current; no fixed 90% or light-load efficiency target | Full-load USB current and startup measurements; approx 70.7% steady-state break-even under current assumptions | ADR-021 |
| B1-R024 | Rev B recovery | deferred | Automated FTDI CBUS reset/BOOT0 recovery deferred; ordinary reset, BOOT0-low defaults and SWD remain in Rev A | Rev A has no B1-B053 parts or footprints; first programming uses SWD | USR-36; ADR-042 supersedes ADR-023; B1-Q013 |
| B1-R025 | MCU text debug | accepted | Give each MCU a dedicated 115200-baud TX/RX/GND UART on the combined eight-pin 0.1-inch header (B1-R027; ADR-041) | Pin/peripheral and clock review; simultaneous bidirectional debug/network traffic; header/adapter/off-state checks | USR-26; ADR-032; B1-Q014 |
| B1-R026 | Rev A termination | accepted | Implement the CAN fixed-plus-jumper endpoint arrangement and fixed local RS-485 120 ohm termination in ADR-034 | Review endpoint routing, jumper modes, resistor ratings and measured waveforms | USR-28; ADR-034; B1-Q003/004/009 |

| B1-R027 | Timing/debug access | accepted | One 1x8, 0.1-inch header per MCU: debug RX/TX, GND x2, shared SYNC/TRIG interrupt-capable inputs, private EVENT0/EVENT1 outputs; exact order in timing_headers.md; each of six signals has 330 ohm in series close to its MCU pin (24 total); shared SYNC and TRIG each have a pull-down to GND | Verify pads and interrupt lines before schematic approval; probe access at layout; timing response at bring-up | USR-35/36/37; ADR-041/042; B1-Q005/010/014 |

## Deferred / undecided features

| Feature | Status | MVP handling | Basis |
|---|---|---|---|
| Full 17-pair backbone, 24 V trunk/tap, test SPI, backbone trigger/fault hardware | deferred | No circuitry, connectors or reserved pins implied | ADR-003 |
| General ADC, SPI/I2C and spare GPIO breakouts | deferred | Revisit header design in later revision; no support footprints | USR-35; ADR-041 |
| CAN3 and its initial-DNP local PHY/termination | deferred | Excluded from proposed baseline; no footprint implied | SRC-ARCH §4.2; B1-Q001 |
| Second Board 1 RS-485 p2p port | deferred | Rev A has one; expanded Board 1 has LEFT/RIGHT, two total | ADR-007 |
| RS_485_MULTIDROP (historical RS485_SHARED) | deferred | Descoped for Board 1 currently; retained in overall bench architecture | USR-06 clarification; ADR-007 |
| Protected 5V_AUX_OUT | deferred | No external power output in Rev A estimate | SRC-ARCH §8.5; ADR-006 |
| Native STM32 USB option | deferred | No connector or pin reservation assumed | SRC-ARCH §7.2; B1-Q001 |
| T1S, FPGA instrumentation, wireless, Ethernet | deferred | Future experiments, no MVP implementation | SRC-ARCH §§9,14 |

## Open questions — authoritative register

| ID | Status | Owner | Question / required result | Blocks | Resolution |
|---|---|---|---|---|---|
| B1-Q001 | resolved | Maintainer | Rev A networking scope | Scope freeze | USR-05/06 / ADR-007: both CANs, onboard UARTs, VCP, one external RS-485, signal terminals and timing/debug headers; added PHYs deferred |
| B1-Q002 | open | Power designer | Complete USB-B/FT232HL/TPS560430 power proposal: budget, current datasheets/errata, support parts, protection, EN control/isolation and any auxiliary allowance | Power schematic approval; measurements at bring-up | TPS560430 selected ADR-021; ADR-040 settles startup/enable. Power/USB captured in kicad/ with enumerated support, defaults and shield bond. Electrical/errata approval remains; measurements are bring-up work |
| B1-Q003 | open | Interface designer | Choose CAN arbitration/data and onboard UART rates; qualify accepted multidrop driver/pulls, PHY behavior and termination | Interface timing and electrical review | Driver/defaults, all CAN/UART links and termination captured; pin allocation compared to exact devices. Rates, timing and firmware qualification remain. |
| B1-Q004 | open | Board designer | Define external bus access, connector pinouts, grounding/protection, debug/reset headers, test points and mechanical constraints | Connector allocation and layout | Connector numbering, twelve copper testpads, seven communications measurement headers and six ground headers are captured and approximately placed on the native PCB under ADR-046. Initial placement has no component collisions; see [placement checks](kicad/placement.md). Actual mating, final clip/mechanical clearance, SWD internal pad-clearance rule disposition and detailed placement/routing remain. |
| B1-Q005 | open | Board designer | Verify exact MCU/package peripherals, simultaneous mux use, clocks/boot/reset/debug, electrical compatibility and availability | Pinmap and schematic freeze | All208 MCU pins captured and independently compared with corrected workbook/plan; STM32pads19–29 error fixed. Ordinary reset/BOOT0/SWD complete; errata, firmware and approval checks remain. |
| B1-Q006 | open | Firmware/test owner | Define representative workloads, rates, queue/memory reporting and pass thresholds for simultaneous links and bare-metal/RTOS | Experiment acceptance | TBD |
| B1-Q007 | resolved | Maintainer | Spin A power operating scope | Power-state architecture | User: exclusively USB powered, requires PC on; advanced power deferred; bus terminals and timing/debug headers included. See current B1-R022 |
| B1-Q008 | open | Clock/firmware designer | Implement 168 MHz gateway and 12 Mbaud VCP; qualify selected crystals/load capacitors and PLL/peripheral clocks including CAN and onboard UART divisors | Clock and pinmap freeze | ADR-014/030 finalize MCU and FTDI crystal MPNs; ADR-031 accepts load capacitors; load/startup/drive and clock-tree/bench review pending |
| B1-Q009 | open | Interface designer | Qualify selected RS-485 PHY, half-duplex termination/bias/protection; finalize operating rate, DE-/RE control, cable and power-off assumptions | RS-485 schematic | ST3485EBDR and termination topology decided ADR-034; 12 Mbps ceiling retained. Bias investigation rs485_bias.md records accepted 330 ohm legs ADR-036; loading/leakage/power-off checks and owned Digi kit revision/rate remain open, alongside MCU thresholds/control/protection |
| B1-Q010 | open | Board designer | Qualify LED networks and assign SYNC/TRIG interrupt inputs plus private EVENT outputs per MCU; review external-drive and load contract | Schematic approval; waveform checks at bring-up | Timing GPIO/interrupt assignments and LEDs captured; GWEXTI0/1,SAMEXTINT2/3. Waveform/brightness/load tests remain bring-up. |
| B1-Q011 | open | Power designer | Qualify converter efficiency envelope, passives, layout and losses | Main power design approval | USR-13 limits efficiency qualification to full networking load; see buck_tps560430.md and decoupling.md; temperature/full-load corners and measurements pending |
| B1-Q012 | open | Interface designer | Qualify selected FTDI EEPROM: clock and word-program timing, supply ramp, reset/read delay, rapid power cycling, current datasheets/errata and SOIC footprint | USB bridge schematic freeze | AT93C56B-SSHM-B selected USR-23 / ADR-018; startup timing settled ADR-040. Support wiring is captured; EEPROM configuration and programming procedure are in usb_vcp.md. Program/readback and normal startup/replug measurements remain bring-up checks |
| B1-Q013 | resolved | Board designer | Rev A disposition of automated CBUS reset/BOOT0 recovery | No Rev A gate | USR-36 / ADR-042: defer to Rev B after confirmed PB14 ROM-startup/RS-485 DE conflict; no B1-B053 circuitry. Ordinary reset/boot/SWD checks remain B1-Q005. This is scope resolution, not electrical validation |
| B1-Q014 | open | Interface/firmware designer | Qualify debug UART pinmux, baud clocks, selected header cuts/footprint; implement the timing_headers.md pin order and finalize adapter interface and unpowered-input behavior | Debug UART schematic and bring-up | Four115200baud debug ports, private330ohm series branches and10k RX defaults captured. Powered3.3V bench-only adapter contract in timing_headers.md; baud and real interface behavior remain bring-up. |

Owners are roles, not assigned people. Close questions with evidence/ADR links; retain their IDs. No open question has been silently answered by a generated part or pin choice.

Naming: FD_CAN_A = historical CAN1; FD_CAN_B = historical CAN2. These are two physical buses, not additional buses.

USR-19 / ADR-014 selects the common MCU crystal for B1-R015; USR-22 / ADR-017 requires a separate accurate FTDI crystal for B1-R005, finalized by ADR-030; exact MPN and quantities are in BOM B1-B014/019/020. B1-Q008 remains open for oscillator qualification and load networks; crystal selection alone does not resolve it.

Draft implementation evidence for B1-R001/002/003/005/007/014/015/016/019/020/021: the STM32 sheet linked in [pinmap](pinmap.md#draft-stm32-gateway-allocation). All pin evidence remains unverified and no question is closed by this allocation.

USR-23 / ADR-018 selects B1-B013 for B1-R005/012. The new FTDI sheet covers bridge and EEPROM pads; B1-Q002/008/012 remain open for the linked implementation checks.

ADR-026 retains connector MPN selections. ADR-041 / USR-35 replaces the separate GPIO/debug headers with four combined 1x8 timing/debug headers. One selected 40-position strip supplies all 32 positions. General ADC, SPI/I2C and GPIO breakouts are deferred. Resistor selections and fitted scope-ground access from ADR-039 remain in force; ADR-046 replaces communications copper pads with seven headers while retaining twelve rail/reset/boot/core pads. Timing MCU pads and six ground-header assemblies are captured; electrical and physical placement checks remain under B1-Q004/005/010. B1-Q004/005 retain terminal numbering, footprints, SWD cable/key and adapter checks. See [timing headers](timing_headers.md).

[ADR-027](../../docs/decisions/027-ceramic-capacitor-mpns.md) accepts ceramic capacitor MPNs in B036–041/045/048 and bridge support mapping for B1-R001/012/023. B1-Q002/011 remain open for effective capacitance, core regulation, damping pulse and implementation qualification.

ADR-029 accepts exact LED and raw-VBUS damping MPNs for B1-R019/012; B1-Q002/010/011 retain qualification. [Remaining component decisions](remaining_parts.md) tracks unresolved procurement choices.

ADR-030 finalizes USB-B connector and crystal MPNs. The interim REF tolerance conflict was resolved by ADR-031 below; B1-Q008 retains loading/gain/drive/startup qualification. See crystal_networks.md for the accepted initial load capacitors.

ADR-031 resolves the B1-Q002 REF tolerance subissue with RMCF0805FT12K0 and accepts crystal capacitor MPNs; B1-Q002/008 remain open for other qualification. General-purpose breakouts and their support-resistor proposal are deferred by ADR-041.

BOM reconciliation exposes accepted ADR-027/028 bridge allocations as B1-B061–065, split from B1-B017 with no added scope. The power/USB capture settles rail enumeration and counts, including B1-B078/079; B1-Q002/012 retain electrical/errata and bring-up qualification. [Selected interfaces](interfaces.md) implements ADR-033/034/037/038/039; B1-Q003/009 remain open for electrical qualification.

USR-27 / [ADR-033](../../docs/decisions/033-open-drain-uart-buffer.md) accepts B1-B066 for B1-R003. B1-B008 support values are accepted by ADR-039; B1-Q003/005 remain open for timing, reset/power, thresholds and implementation. [Termination proposal](termination.md) records the CAN jumper and fixed local RS-485 evaluation under B1-Q003/004/009; topology and nominal 120 ohm values subsequently accepted by USR-28 / ADR-034 / B1-R026; exact resistor/jumper MPNs subsequently accepted ADR-035.

[ADR-035](../../docs/decisions/035-termination-parts.md) / USR-29 accepts the exact termination MPNs in B1-B067–070. [RS-485 bias investigation](rs485_bias.md) records the accepted network, calculations and remote-kit rate check; B1-Q009 remains open.

Library implementation evidence for B1-R001/006/012: [local symbols](../../libraries/symbols/README.md) and [migration/conflict record](../../libraries/imports/README.md). B1-Q002/005 remain open; the archived STM32G473 bench schematic does not supersede the accepted STM32G474 selection.

Symbol implementation evidence for B1-R002/005/006/012/023: [three exact-part library checks](../../libraries/symbols/symbol_checks.md), implementing ADR-002/018/021. This does not close B1-Q002/003/004/011/012 or change requirement status.

[ADR-036](../../docs/decisions/036-rs485-bias.md) / USR-30 accepts two 330 ohm 1% bias resistors in B1-B071: 3V3_SYS to A (ST3485EBDR pin6), B (pin7) to GND. Exact MPN and implementation remain unverified. [TVS selections](interfaces.md) are accepted ADR-037/038; qualification remains open under B1-Q004/009.

[ADR-037](../../docs/decisions/037-can-tvs.md) / USR-31 accepts B1-B072: two ESD2CAN24DBZRQ1 arrays near the CAN terminal pairs, DBZ pins1/2 to CANH/CANL and pin3 to GND, independent of termination jumpers. Exact CAD connectivity/footprint and transient qualification remain B1-Q004. [RS-485 TVS selection](interfaces.md) is accepted ADR-038; qualification remains open under B1-Q009.

[ADR-038](../../docs/decisions/038-rs485-tvs.md) / USR-32 accepts ESDS452DBZR B1-B073: DBZ pins1/2 to A/B, pin3 GND. Normal operation requires both RS-485 wires within +/-5.5 V of local Board 1 ground. Actual endpoint/offset and transient qualification remain B1-Q009. See [remaining selections and qualification](remaining_parts.md).

[Complete selected IC/array symbol coverage](../../libraries/symbols/remaining_ic_symbol_checks.md) supports schematic capture for the existing requirements. These library checks do not close B1-Q002/003/004/005/009 or change requirement acceptance/verification.

ADR-041 / USR-35 replaces the separate GPIO/debug headers with four combined 1x8 timing/debug headers. One selected 40-position strip supplies all 32 positions. General ADC, SPI/I2C and GPIO breakouts are deferred. Resistor selections and fitted scope-ground access from ADR-039 remain in force; ADR-046 replaces communications copper pads with seven headers while retaining twelve rail/reset/boot/core pads. Timing MCU pads and six ground-header assemblies are captured; electrical and physical placement checks remain under B1-Q004/005/010.

Current disposition: ADR-040 settles startup/direct PWREN# enable. [ADR-042](../../docs/decisions/042-header-resistors-recovery-scope.md) records the exact header wiring and defers automated recovery to Rev B. Remaining ordinary reset/boot wiring belongs to B1-Q005; no broad recovery review blocks Rev A capture.

Historical initial full-schematic completion (2026-09-07): eleven native sheets and 872 pins passed the then-current netlist checks, with a 208 MCU-pad comparison. ADR-046 adds communications headers, bringing current connectivity to 879 pins; see current CAD checks. Conventional defaults are fully enumerated; no new architecture or maintainer acceptance claimed. B1-Q002–012/014 retain their approval/bring-up portions.

Gateway correction: [ADR-043](../../docs/decisions/043-gateway-part-correction.md) supersedes ADR-004 for B1-N01/B1-B001 only. Native G473 symbol and BOM now agree; G474-specific prior evidence and workbook/PDF snapshots do not verify G473. B1-Q005/008 retain exact G473 pinmux/electrical/errata review before schematic approval.

[ADR-044](../../docs/decisions/044-yageo-crystal-load-capacitors.md) records the maintainer-selected YAGEO 33 pF MPN for B1-B042/043 under B1-R015. Values/counts/footprints remain unchanged; B1-Q008 retains oscillator qualification.

[ADR-045](../../docs/decisions/045-yageo-27pf-crystal-capacitors.md) selects YAGEO CC0805FRNPO9BN270 for the two B1-B058 FTDI load capacitors. Existing initial values and B1-Q008 qualification remain.

[ADR-046](../../docs/decisions/046-communications-measurement-headers.md) / USR-38 replaces communications copper pads with J19–J25, including all three UART-ring hops; exact pin order is in [pinmap](pinmap.md#communications-measurement-access). TP13–TP19 are retired, twelve copper pads and six ground headers retained. B1-Q004 retains final clip clearance, silkscreen and routed branch review.

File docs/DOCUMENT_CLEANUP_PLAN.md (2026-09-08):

# Proposed documentation cleanup

Status: steps 1–6 implemented through ADR-039. Maintainer instructed deletion instead of archiving for step 3; Git retains history. Data separation, reproducible BOM generation and cleanup audit complete; electrical qualification remains open. No ADR renumbering, hardware changes or qualification sign-off.

## Findings from the pre-cleanup review

- ST3485EBDR is already accepted in B1-B021/ADR-034; no duplicate selection ADR needed.
- BOM has 75 unique rows: 64 accepted (61 exact MPN rows and three category/non-purchased rows), five proposed residual networks and six zero-quantity superseded rows. Readable BOM covers every CSV row once. Counts are rows, not purchasing quantities; cut headers and PCB pads require special treatment.
- Board README still describes SC189 and a 90% efficiency target as current, then appends contradictory newer decisions. It also says crystals are unselected in older paragraphs.
- BOM.md tables are current, but trailing prose still says bias MPNs are open and B008 is residual support, both superseded by ADR-039. Similar overlays occur in research notes.
- decoupling.md mixes obsolete converter/Cout limits with still-current MCU decoupling rationale. It cannot be archived whole until that live material is extracted.
- ADR-010 and ADR-013 are partially superseded, but a flat accepted status obscures which clauses survive. Both connector and SAM-core decisions use ADR-026.
- Power JSON contains legacy and current models together; research notes contain old stock snapshots. Neither should silently drive new calculations or procurement.
- Libraries now contain real implementation artifacts and symbol checks. Old statements that no CAD/library work exists must be narrowed: no completed board schematic/layout validation is implied by symbol completion.

## Proposed sequence

1. **Completed — repair current entry points.** Rewrite board README as a short current topology/status/navigation page. Keep BOM.md generated from bom_internal.csv, with one allocation-notes section. Remove superseded prose rather than prepend more overrides. requirements.md remains the sole owner of open-question status; remaining_parts.md becomes its concise selection-focused index. Cross-link existing symbol validation instead of duplicating it.

2. **Completed — consolidate current implementation notes.** Retain buck_tps560430.md, crystal_networks.md, clocking.md, pinmap.md and current bus/protection details. Extract current MCU/core decoupling into decoupling.md from decoupling.md and the BOM. Consolidate USB/VCP and input sequencing into clearly named current notes (usb_vcp.md and usb_input.md). Merge termination.md + termination.md into termination.md; retain rs485_bias.md. Add one current interface/protection note covering the accepted ST PHY, CAN/RS485 TVS and UART_MD circuit. Preserve assumptions and open electrical checks.

3. **Completed — delete obsolete research after extraction.** At maintainer direction, removed 22 redundant research/review/legacy circuit notes. Current checks and primary evidence are consolidated into the live topic notes. ADR/source citations use immutable Git links to the original research. No archive directory created; source attachments and working symbol libraries retained.

4. **Completed — clarify decision authority without rewriting history.** Keep ADR files and stable IDs in place. Add a topic-based current-authority map to the ADR index: power, decoupling, clocks, buses, debug, assembly and sourcing. Record clause-level successors for partly superseded ADR-010/013/019; preserve still-active decisions. Add reciprocal supersedes/superseded_by metadata only where existing decisions provide evidence. Use filename-qualified ADR-026 references consistently; avoid silently renumbering previously referenced decisions. Later engineering changes still require new ADRs; editorial consolidation does not invent new acceptance.

5. **Completed — separate live data from historical scenarios.** Audit consumers of power_budget.json and vbus_hotplug_model.py before moving or renaming data keys. Give current Rev A calculations an explicit active entry; retain future expanded-board scenarios separately from obsolete converter assumptions. Keep machine-readable BOM status accepted/proposed and evidence unverified/verified independent. Make readable BOM generation reproducible and distinguish purchase quantity from placement quantity for B027/B059 and zero-purchase PCB pads. Do not infer unknown bridge counts or close qualification questions in this cleanup.

6. **Completed — check the result.** Validate internal links, unique IDs, BOM/view coverage, accepted MPN preservation, supersession references, symbol/footprint links and quantity exclusions. Search current documents for SC189/90%/30 uF/TLV803 and old candidate parts: retain only clearly labeled historical references. Confirm Board 1 RS_485_MULTIDROP stays deferred while remaining in family architecture. Run existing model checks if paths change. Preserve all source files, accepted design choices and open qualification requirements.

## Scope and completion criteria

Start with entry-point corrections and the authority map, then delete superseded research after extraction in a separate reviewable change. Finish data/model restructuring last. No new parts, schematic changes or electrical sign-off are included. Done means a new agent can identify the current design from README, requirements, BOM and topic notes without reading historical proposals; history remains accessible and no accepted choice is reopened.

## Implemented scope

Steps 1–2 add current usb_input.md, usb_vcp.md, decoupling.md, termination.md and interfaces.md; rewrite board entry points/BOM view; reconcile retained bias and buck notes. At step 2, historical bodies stayed in place with successor banners; step 3 subsequently removed these redundant notes. Root README maturity wording and the live converter-qualification pointer are corrected. Steps 1–2 did not change BOM CSV, ADR files/index, power data/models or question statuses. Basic link and BOM-view checks accompany these edits; the broader step-6 audit remains proposed.

## Steps 3–4 record

Deleted research is recoverable at Git revision `dbcaba10831ade0516dba825d2c97d3f0017e0f5`. Added a topic authority map and partial-supersession metadata/current-scope notes, preserving historical ADR decision bodies and both filename-qualified ADR-026 identities. Retained current electrical checks and repaired document citations. BOM selections, quantities, evidence status, question status and power model data are unchanged.

## Steps 5–6 record

Current Rev A power data is explicit schema v2; deferred expanded scenarios are separate and obsolete converter goals removed. Numerical assumptions/operating points remain unchanged. BOM CSV is unchanged; the generated view makes purchase/placement exceptions explicit. Standard-library generator/audit and model commands are documented in boards/board1/models.md. The exploratory hotplug snapshot is reproduced independently of current-board qualification. See [audit report](CLEANUP_AUDIT.md) for coverage and remaining limitations.

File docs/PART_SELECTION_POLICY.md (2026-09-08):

# Part selection policy

Status: draft policy · Authority: selection/review workflow

Prefer readily sourced parts, inspectable/reworkable packages, documented electrical behavior, and a small set of reusable library components. Existing MCU choices are accepted selections (USR-15 / ADR-004), not an invitation to re-optimize the architecture every session. Check ADR-004 before revisiting them.

Collect the following evidence at the relevant review stage in DESIGN_PRINCIPLES.md. Do not make procurement, layout or bench evidence a prerequisite for proposing or capturing a conventional circuit. Reuse existing checked evidence; investigate only limits relevant to the intended use.

For each selected part, record in the BOM or linked evidence:

- Exact manufacturer and orderable MPN, package, quantity, assembly variant, symbol and footprint.
- Primary manufacturer datasheet URL, revision/date and relevant pages; applicable errata.
- Required versus supported electrical limits: supply, I/O levels, timing, temperature, load, startup/reset, and unpowered behavior as relevant.
- Distributor, dated stock/price evidence, currency and quantity break when procurement is evaluated. Stock and prices expire; never infer them from a past architecture draft.
- Reason for selection, requirement/ADR references, evidence status, and any separately reviewed alternatives.

Compare PHYs against the actual bus rates, rails, common-mode/fault needs, control pins, package, termination, and power budget. Compare USB bridge options against target PC support and dependable bring-up. Do not fill missing specifications from memory or a neighboring part.

An alternate requires pin, footprint, electrical and firmware compatibility review; a similar name is insufficient. CAD library review must check pad numbering, exposed pads, orientation, package dimensions and land pattern against the exact part. Use project-local libraries and `${KIPRJMOD}`-relative paths; record upstream source/license for imported assets.

## BOM schema

`bom_internal.csv` is an initial functional planning BOM. `item_id` is stable. `quantity` is total per board for that row; `TBD` is permitted until resolved. `references=TBD` means schematic designators do not exist yet. Split grouped rows when actual parts/designators are assigned.

`assembly`: `fit` (planned populated), `dnp` (designed footprint, omitted), `tbd` (undecided). `selection_status`: `proposed`, `accepted`, `rejected`, `superseded`. `evidence_status`: `unverified`, `verified`. `TBD` marks unknown fields. A planned `fit` row is not evidence of an accepted design. Deferred architecture is omitted from the BOM rather than represented as DNP.

Do not order from this scaffold. Procurement readiness requires accepted selections, exact MPNs/quantities/references, verified packages and footprints, current availability evidence, and reconciliation against the released schematic/assembly variant.

## Assembly and package constraints — accepted USR-09 / ADR-009

- Available assembly/rework tools: soldering iron and hot-air station. Choose parts and layouts that can be assembled, inspected and reworked with these tools.
- Prefer SMT IC packages with exposed leads, such as SOIC, TSSOP/MSOP/VSSOP and appropriately sized SOT packages. An exposed thermal pad is not an exposed lead; evaluate any mandatory underside solder joint separately.
- QFN and other leadless packages can be considered only with a documented justification explaining why the benefit outweighs assembly/rework difficulty and why suitable leaded alternatives are inadequate.
- Exclude BGA unless it is existential to the intended function: no viable alternative can realize an essential requirement. Document that necessity and the required assembly/rework approach; convenience, density or incremental performance is insufficient.
- Accepted USR-17 size guidance: default to 0805 imperial (2012 metric), which the maintainer finds easy; 0603 (1608 metric) is acceptable but small. Use 1206 or larger where electrical requirements or handling warrant it. Exclude 0402 and smaller from new selections. Smaller crystal packages are acceptable if they retain accessible leads; package dimensions alone do not establish solderability.
- Judge the actual footprint, lead pitch and access for rework, not just the package-family name. Keep room around components for iron/hot-air access. Do not silently assume a reflow oven or outsourced BGA assembly is available.

## Sourcing constraint — accepted USR-12

Source all project parts from DigiKey for procurement simplicity. Record exact DigiKey order codes alongside manufacturer MPNs in the BOM or linked procurement evidence. Confirm current availability before purchase; a catalog listing alone does not establish stock. Do not select an alternative supplier without an explicit maintainer change to this constraint. Historical candidate notes are research history, not procurement approval; recheck any candidate against this constraint before selection.

## Decoupling value preference — USR-14

Prefer 100 nF, 1 uF and 4.7 uF for BOM consolidation when electrically appropriate. This is secondary to electrical requirements; retain justified exceptions such as buck input 10 uF and output 22 uF, analog 10 nF and crystal-load capacitors. Equal nominal values do not imply interchangeable dielectrics, ESR, packages or voltage ratings.

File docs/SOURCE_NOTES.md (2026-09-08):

# Source provenance and interpretation

Status: draft provenance record · Reviewed for this scaffold: 2026-09-06

The source attachments were read from the referenced conversation “Design Board 1 MVP”, conversation ID `6a9db131-0c14-83e8-a243-a4fee3e7eb7e`. Original files are not edited or copied into this repository. This scaffold is self-contained for planning; recover the exact originals from that conversation or the project source mirror for detailed review. Temporary attachment paths are not repository dependencies.

| ID | Source | Authority / treatment |
|---|---|---|
| SRC-ARCH | WireSpaces_Board1_Bench_Architecture_First_Draft_v2.md; dated 2026-09-01 | First draft; written MCU/topology baseline plus full future bench; not a schematic spec |
| SRC-INTRO | introduction.md; “WireSpaces — Introduction” | Provisional protocol orientation; normalize terminology in authored summaries |
| SRC-DIAGRAM | WS_Board1.drawio(1).png | Topology sketch; MCU labels differ from written source |
| USR-01 | Initial user message in referenced conversation | Explicit Host terminology and reduced first-PCBA scope |
| USR-02 | Current repository setup request | Requested tree, corrected context filename, concise status/authority conventions and ADR discipline |

## Source fingerprints (SHA-256)

- `SRC-ARCH`: `22bbe6904402d59bc3ea00866a3a29f58cf57fb0ac0338f02b116f973b3e5988`
- `SRC-INTRO`: `bf625af21dbffad43e1a756068084ceab8a076983a71b15e26e32f382d7e9ebb`
- `SRC-DIAGRAM`: `29028b82e6f701de227ac75ce9e915da4024b4e5d40087c3879c0641036911a4`

## Interpretation limits

The diagram labels STM32G473CBT6 and SAMC21E15A; the written draft specifies STM32G474RBT6 and ATSAMC21G17A-AUT. The MCU selection follows the written text and is now explicitly accepted by USR-15 (ADR-004). The written ring is directed and excludes the gateway; do not derive direction from the sketch's arrowheads.

The full draft's freeze summary includes backbone, power and test features beyond the user's reduced MVP. ADR-003 records the override; Board 1 requirements explicitly mark remaining scope questions. USB/VCP, debug and the four-node networking core are proposed carry-forward items, not newly claimed approvals.

No current manufacturer datasheet, erratum, distributor inventory, KiCad symbol or footprint was validated in this setup pass. Source-stated packages/resources and electrical targets remain unverified until the corresponding design work is completed. The protocol documents mentioned by the introduction were not supplied and are not treated as reviewed.

## USR-03 — USB design input (2026-09-06)

User has FT232HL (DigiKey 768-1101-1-ND) and is considering SC189ZSKTRT (SC189ZSKCT-ND; ownership corrected by USR-11), prefers USB-B, and requests USB power/VCP design. The circuit proposal records manufacturer-indexed evidence and retrieval limitations. Earlier statements about no datasheet validation describe the initial scaffold; this follow-up adds limited excerpt review, not complete part/pin validation.

User follow-up resolves B1-Q007: Board 1 Spin A can be exclusively USB-powered and requires the PC on; later respins add external connectors and advanced power. Prefer adaptable components but defer detailed future-power design. This accepts operating scope, not every part or circuit in the proposal.

## USR-04 — accepted power architecture, VCP speed and crystals (2026-09-06)

User accepts the power architecture and power-off UART isolation. Requests 12 Mbaud gateway VCP, STM32 at 168 MHz, short traces and hardware flow-control signals. All four MCUs must have external crystals. Onboard UARTs target several Mbaud with exact rates unspecified; only gateway VCP needs 12 Mbaud. ADR-001 records power acceptance; ADR-005 records clock/speed requirements. Calculations and reviewed primary-source excerpts are linked in boards/board1/clocking.md; acceptance is distinct from component/pin/bench validation.

## USR-05 — Rev A external buses and expanded USB estimate (2026-09-06)

User specifies FD_CAN_A, FD_CAN_B, all onboard UARTs, VCP and one external RS-485 in Rev A. Both CANs and RS-485 go to terminal connections with ground(s). Added transceivers and connections belong to later revisions. Requests a transceiver search and 500 mA USB estimate for all planned RS-485 plus STM32-only CAN3. Expanded calculation assumes three total RS-485 PHYs from the full draft and nine CAN PHYs total. Primary-source links, dated sourcing limitations and numerical assumptions are in https://github.com/ofdouglas/ws-hardware/blob/dbcaba10831ade0516dba825d2c97d3f0017e0f5/boards/board1/transceivers_and_power.md. ADR-006 records scope; part choices remain proposed.

## USR-06 — Board 1 power reduction and family-scope clarification

User selects TCAN3413DR, limits external RS-485 to 12 Mbps, and descopes the multidrop RS-485 from Board 1's expanded design while retaining LEFT/RIGHT p2p ports. Explicit follow-up: this does not remove RS_485_MULTIDROP from the overall WS bench architecture. Requires one LED per MCU, a board power LED and a few GPIOs per MCU on breakouts. LED current, exact GPIO count/load allowance and THVD1420 selection are assistant proposals, not accepted component specifications.

## USR-07 — Rev A dual-gateway lab rationale

User reaffirms one external STM32 RS-485 port in Rev A after considering its removal for power savings. User owns a Digi ConnectCore 93 development kit, reported to expose two CAN-FD interfaces and one RS-485 interface. Connecting Board 1 to all three enables a dual-gateway lab. This is user-provided equipment context; exact kit revision, pinout, electrical mode, supported rates and termination have not been verified. The zero-RS485 alternative was discussed but not accepted. Existing USB-only Rev A scope remains in force; adding 24 V was discussed, not accepted.

## USR-08 — converter efficiency design target

User requests a concrete buck converter design to meet the new 90% worst-case efficiency target and permits an alternate IC. This accepts the efficiency objective, not the assistant-proposed TPS62902, passive choices, 92% internal qualification margin or temperature/load envelope. Manufacturer sources and USB maximum-voltage correction are recorded in https://github.com/ofdouglas/ws-hardware/blob/dbcaba10831ade0516dba825d2c97d3f0017e0f5/boards/board1/buck_converter.md.

## USR-09 — assembly constraints and brief converter search

User finds the proposed QFN difficult to solder and requests a brief search for efficient, easier-to-solder bucks. Explicit project rule: prefer exposed SMT leads; QFN needs justification; BGA excluded unless existential. Available tools are soldering iron and hot air; avoid the smallest passives. ADR-009 records this. No replacement converter is selected by this instruction.

## USR-10 — SC189 evaluation

User supplies typical SC189 efficiency plots and requests further evaluation. The plots are reference data, not instructions or approval. Full SOT23-specific curves and passive/startup constraints are discussed in https://github.com/ofdouglas/ws-hardware/blob/dbcaba10831ade0516dba825d2c97d3f0017e0f5/boards/board1/sc189_evaluation.md. No MPN is newly accepted and the 90% target is not narrowed.

## USR-11 — SC189 ownership correction and TPS62046 candidate

User explicitly corrects earlier ownership interpretation: SC189 is not on hand and was only being considered. FT232HL ownership is unchanged. User proposes TPS62046DGQR for evaluation, noting its underside pad. No converter is selected by this message. Current notes have been corrected; ADR-001 historical text has a correction addendum.

## USR-12 — DigiKey sourcing and future two-stage power

User requires all parts to be sourced from DigiKey, proposes TPSM84203EAB for consideration, and clarifies the intended future power chain: 24 V input -> protection -> 5 V buck -> bridge/sequencing and 3.3 V buck -> MCUs/transceivers. This records future direction, not promotion of external power into Rev A or acceptance of the candidate converter. See https://github.com/ofdouglas/ws-hardware/blob/dbcaba10831ade0516dba825d2c97d3f0017e0f5/boards/board1/tpsm84203_evaluation.md.

## USR-13 — full-load efficiency and SC189 capacitance

User clarifies that light-load efficiency is irrelevant: efficiency matters to support all transceivers at full load from VBUS. SC189 is promising if capacitance permits; asks for a decoupling proposal under 30 uF. B1-R023 now explicitly uses this full-load criterion. Earlier 100–600 mA efficiency-floor interpretations are superseded by this clarification; no exact SC189/passive selection is accepted yet.

## USR-14 — SC189 selection and current BOM

User accepts proceeding with SC189 and the proposed decoupling, and requests a readable BOM containing exact and category-only selections. The accepted conversation revision shares STM32 analog bulk and increases each SAM bulk to 1 uF. Retain the 10 uF buck capacitor; 2x4.7 uF was not accepted. Preferred values are a convenience, not a reason to violate electrical requirements. ADR-010 records selection separately from pending validation.

## USR-15 — official MCU selection (2026-09-06)

In the current MCU-pinout task, the maintainer states: “`STM32G474RBT6` and three `ATSAMC21G17A-AUT` are officially selected, update the documents to record that.” This accepts one gateway and three leaves under ADR-004 / B1-R001. The accompanying request for oscillator and SWD/debug/flash options authorizes proposals, not acceptance of those implementation choices. Pin allocations and exact-device implementation evidence remain unverified.

## USR-16 — owned probes, SWD headers and common crystal preference

Maintainer owns a J-Link EDU and plans to use it for this project, has a PICkit 5 if needed, and accepts the proposed 10-pin Cortex SWD headers. ADR-011 records the debug access choice. Maintainer prefers the same 12 MHz crystal for all devices and requests candidates available from DigiKey in quantity one. No exact crystal MPN is selected.

## USR-17 — common crystal selection and assembly sizes

Maintainer accepts ECS-120-18-5PX-CKM-TR in the context of a common crystal for the gateway, three SAMs and FT232HL. Smaller crystal packages are acceptable if they have leads. Maintainer finds 0805 easy, 0603 doable but small, and 0402 or smaller too small. The abbreviated “06” and “04” are interpreted as imperial 0603 and 0402 in this package discussion. ADR-012 records the crystal selection; ADR-009 has an assembly-preference clarification. Electrical qualification and load capacitors remain open.

## USR-18 — enable-only main power and UART buffer selection

Maintainer explicitly accepts omission of AP22653 from Rev A and selects SN74LV125APWR. USB protection remains open; previously suggested ESD options were unavailable at DigiKey. See ADR-013.

## USR-19 — smaller crystal selection and draft SAM allocation

On 2026-09-06 the maintainer explicitly says “commit to ECS-120-20-3X-EN-TR” after the smaller-package comparison, and requests a draft SAMC21 pin-allocation spreadsheet. ADR-014 records the replacement common-part selection. The previously disclosed FT232HL accuracy conflict remains open; this instruction does not establish electrical compatibility or acceptance of the generated pin assignments.

## USR-20 — USB ESD selection and protection scope

Maintainer selects RCLAMP0504S.TCT and requests polarity protection plus an assessment of required overvoltage robustness against USB 2.0. SMF6.0A is not selected. ADR-015 records data ESD selection; exact VBUS polarity/overvoltage circuit remains open.

## USR-21 — Rev A ESD / hot-plug scope

Maintainer explicitly omits polarity and high-voltage protection, retaining only ESD / hot-plug protection. ADR-016 records this scope. USB ESD source and ADR identifiers were renumbered to resolve collisions with the independent crystal records; crystal decisions are unchanged.

## USR-22 — FT232HL crystal accuracy exception

Maintainer asks to continue the SAM spreadsheet and find a crystal within the FT232HL accuracy budget. This authorizes a separate FTDI candidate while retaining the smaller selected MCU crystals. The proposed exact FTDI replacement is not yet expressly selected. See ADR-017.

## USR-23 — FTDI EEPROM selection and pin allocation

Maintainer has AT93C56B-SSHM-B selected on DigiKey and instructs: review it and, if suitable, commit to using it and add an FTDI pinout sheet to the existing workbook. ADR-018 records selection following compatibility review. The generated per-pad allocation is a draft, not maintainer acceptance of implemented connectivity.

## USR-24 — dedicated CBUS recovery controls

Maintainer explicitly instructs: “add dedicated CBUS GPIOs for both reset and BOOT0,” accepting the preceding ACBUS5/reset and ACBUS6/BOOT0 proposal. The maintainer confirms UART buffers are enabled after USB configuration, with the main 3.3 V domain off beforehand. ADR-023 records the selection; interface components/polarity and hardware qualification remain open.

## USR-25 — Rev A connector MPN selections (2026-09-06)

In the connector-selection task, the maintainer explicitly requests adding CNC Tech 3220-10-0100-00 (DigiKey 1175-1627-ND), Phoenix Contact 1989803, and Sullins PRPC040SAAN-RC (DigiKey S1011EC-40-ND) to the BOM as “decided.” ADR-026 (026-reva-connectors.md) records these exact MPNs as accepted in the existing debug, bus-terminal and GPIO rows. This does not accept the preceding proposed terminal order or GPIO cut schedule, or assert verified footprints/pin allocations.

## USR-26 — per-MCU debug UARTs

Maintainer requests each MCU expose a TX/RX/GND text-debug UART, assumes 115200 baud, and accepts 0.1-inch headers. ADR-032 records the scope; 8N1, electrical interface and numbered header order are implementation proposals.

## BOM reconciliation request (2026-09-06)

Maintainer requests review/correction of the BOM, promotion of already-decided choices, and candidate research for RS-485 and UART multidrop. This authorizes documentation reconciliation and proposals, not acceptance of new driver/transceiver parts. Existing ADR-027/028 authority supports splitting bridge allocations into B1-B061–065.

## USR-27 — second buffer for open-drain UART

Maintainer explicitly instructs: “commit the second SN74LV125APWR for OD UART to record,” following the grounded-A/TX-to-/OE discussion and confirmation that all four MCUs are close together. ADR-033 records the selected extra quad buffer separately from the VCP device. The accompanying CAN jumper/RS-485 fixed-termination note is a topology question and proposal, not acceptance of exact termination parts or final topology.

## USR-28 — RS-485 PHY and termination acceptance

2026-09-06: Maintainer instructs “Commit to ST3485EBDR. Commit to the termination proposal. Suggest parts for the termination resistors and jumpers.” ADR-034 accepts the PHY and previously proposed topology/counts/120 ohm value; exact resistor, header and shunt candidates remain proposed.

## USR-29 — termination part acceptance and bias investigation

2026-09-06: Maintainer asks to commit all three recommended termination parts to the BOM and investigate RS-485 idle-bus bias. ADR-035 records explicit MPN acceptance. Bias values remain recommendations pending review.

## USR-30 — RS-485 bias acceptance and TVS research

2026-09-06: Maintainer accepts the recommended 330 ohm RS-485 bias and requests CAN/RS-485 TVS recommendations. ADR-036 accepts network/value, not an unspecified bias MPN or TVS selection.

## USR-31 — CAN TVS acceptance and RS-485 TVS alternatives

2026-09-06: Maintainer selects TI ESD2CAN24DBZRQ1 and asks for another RS-485 part that fits better. In the TVS discussion this authorizes alternative protection research; it does not select a replacement transceiver or restricted common-mode envelope. ADR-037 records CAN acceptance.

## USR-32 — RS-485 TVS acceptance and remaining BOM review

2026-09-06: Maintainer accepts TI ESDS452DBZR following disclosure of its +/-5.5 V working range, then requests suggestions for unresolved BOM items. ADR-038 records selection and its disclosed interface restriction. Additional closeout proposals are not accepted.

## USR-33 — closeout selections and scope ground pins

2026-09-06: Maintainer accepts TE CRGP0805F330R, RK73H2ATTD3301F, the multidrop plan and header plan. Regular PCB test pads are accepted with an explicit addition: pins for clipping scope-probe ground leads. ADR-039 records selections; ground-pin MPN/count remain open.

## USR-34 — startup/enable resolution and proportional design workflow

2026-09-07: Maintainer states FTDI startup timing is fine and VCP buffers can be enabled by PWREN#, then explicitly requests correction of both settled items and the workflow rules. ADR-040 records the circuit decision. Design workflow now prioritizes conventional bench-prototype circuits, concrete failure evidence and stage-appropriate checks. This does not accept other research proposals or claim bench validation.

## USR-35 — combined timing/debug headers

Maintainer requests one 1x8, 0.1-inch header per MCU: debug UART RX/TX, two grounds, shared SYNC and TRIG inputs routed to interrupt-capable GPIO on each MCU, and private EVENT0/EVENT1 outputs for timing response measurements. General ADC, SPI/I2C and GPIO breakouts can wait for a later revision. ADR-041 records this replacement scope; exact pin order and MCU pad choices were not specified by the maintainer.

## USR-36 — exact header wiring and bounded recovery work

2026-09-07: Maintainer specifies header pins 1 debug RX, 2 debug TX, 3 GND, 4 SYNC, 5 TRIG, 6 GND, 7 EVENT0, 8 EVENT1. SYNC/TRIG are global MCU inputs; EVENT0/1 are private outputs. Each non-ground signal requires 330 ohm in series close to its MCU pin. Maintainer asks to resolve reset/BOOT0 easily or defer it to Rev B. ADR-042 records the exact header requirements and the engineering decision to exercise that conditional recovery deferral after checking ROM pin behavior.

## USR-37 — shared timing input pull-downs

2026-09-07: Maintainer requires pull-down resistors on global SYNC and TRIG and asks whether anything else must be settled before draft schematic capture. One pull-down on each shared net is recorded under B1-R027/B1-B077; the 10 kohm value and existing RMCF0805FT10K0 MPN are routine implementation choices, not separately maintainer-specified values.

## USR-38 — communications measurement headers

2026-09-07: In this conversation the maintainer states: “communications test points should use 2-pin 0.1" headers” and “we need test points for the UART ring”. The supplied table specifies CAN A CANH/CANL, CAN B CANH/CANL, RS-485 A/B, each of SAM0→SAM1, SAM1→SAM2, SAM2→SAM0 signal/GND, and shared UART_MD signal/GND. ADR-046 records this explicit replacement/addition scope. Reference assignments J19–J25 and reuse of selected PRPC002SAAN-RC are routine implementation choices; the maintainer did not separately select that MPN. The preceding placement feedback requests logical measurement locations, uncrowded probe access, nearby ground headers and concise function silkscreen.

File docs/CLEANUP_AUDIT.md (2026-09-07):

# Documentation cleanup audit

2026-09-07 · Scope: cleanup steps 5–6; no electrical sign-off.

- Preserved all 75 CSV BOM rows byte-for-byte, including MPNs, quantities, acceptance and unverified evidence. Generated view covers every row once and explicitly excludes superseded purchases.
- Added repeatable generation and drift detection. ADR-039 strip cuts total 32/40 positions: one purchased strip, four GPIO and four included debug pieces. PCB pad purchases are zero; actual pad count and fitted scope-ground pin count stay TBD.
- Current Rev A numerical operating points, load assumptions and approximately 70.71% break-even are preserved and checked against the DC path equation. Expanded scenarios retain original no-path-loss arithmetic separately. Obsolete converter targets are removed, recoverable from Git.
- Reproduced all 81 exploratory cable/RC cases and their retained JSON snapshot exactly. That model excludes the protection/switch/load circuit and cannot qualify the FTDI rail.
- Checked repository Markdown local file targets, ADR identifier references and the explicitly retained duplicate ADR-026 filenames. Reviewed the partial-supersession map for ADR-010/013/019/021 and its reciprocal records; completion references remain distinct from supersession.
- Checked local symbol file references and existing selected footprint resources. This is resource availability, not pin/geometry/ERC/DRC verification. B1-B004 FTDI footprint and other TBD allocations remain unresolved.
- Corrected stale TPS62902/SC189 references in the pinmap resource overview and the obsolete 90% target in family architecture. Remaining SC189/30 uF/TLV803 mentions are explicit history, exclusions or supersession boundaries. Family RS_485_MULTIDROP remains retained and Board 1-deferred.
- Requirement and question statuses and ADR IDs/statuses are preserved; current resolution prose reflects existing accepted GPIO/header choices. No fresh parts, rate approval or source-CAD changes.

Run `python3 scripts/board1_documents.py` and `python3 boards/board1/vbus_hotplug_model.py --check` from the repository root. See [model maintenance](../boards/board1/models.md) for inputs and generation commands.

Limits: external links/stock, every Markdown fragment, workbook internals, physical footprints, circuit behavior and hardware immunity were not requalified. Library research history is retained as explicitly labeled implementation evidence. Existing B1-Q002–006 and B1-Q008–014 remain open. The power model still needs real load, bias, startup/suspend and efficiency qualification; reproducing its arithmetic does not close those questions.

## Review follow-up — 2026-09-07

Corrected the GPIO follow-up allocation to B1-B027 and the unallocated resistor proposal (B1-Q010), and restored immutable TPS62902 research links for historical B1-B032–035. The pinmap converter overview was already corrected by PR #5. Quantity overrides now validate CSV purchase/placement meaning and header cut counts under ADR-039. Power results explicitly identify scenarios and validate their load/bridge inputs, including the conservative break-even allowance under ADR-021. Added seven regression tests covering rejected inconsistencies and valid data updates. No selected parts, counts, numerical power results, ADR authority or hardware qualification changed.

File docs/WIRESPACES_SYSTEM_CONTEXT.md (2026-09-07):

# WireSpaces system context

Status: draft · Authority: orientation only · Sources: SRC-INTRO, USR-01

WireSpaces (WS) is a lightweight embedded communication fabric for small MCU networks, gateways, multicore devices, and FPGA implementations. It carries bounded datagrams such as commands, telemetry, events, logs, and firmware segments across different physical media while preserving an Endpoint/Service model.

A **Wire** is a loop-free logical bus formed from configured Links. It may span heterogeneous Links, coincide with one Link, or exist inside one device. Several Wires may overlap on a Link. Forwarding follows static/read-mostly Wire topology; destination identity controls acceptance rather than ordinary next-hop routing.

An Endpoint Domain has one deployment-scoped **HostId**, used on every Wire it joins. Addressed PDUs identify `SrcHostId` and `DestHostId`. Multiple Hosts can originate traffic. Gateway/leaf are hardware roles, not distinct identity classes. Physical node labels such as `SAM0` do not assign numeric HostIds; deployment configuration does that.

The model favors bounded storage, visible resource exhaustion, simple local execution, and PC-side configuration/validation. A single PC-to-device Link should be useful before a full deployment is modeled. `kLocalBus` supports local one-Link bring-up with valid Host identity; it is not transparently forwarded. Exact packet layouts, bindings, and protocol conformance belong to the protocol project, not this hardware repository.

## Why these boards exist

Board 1 provides real simultaneous links on constrained MCUs so WS can be measured while forwarding, buffering, and servicing traffic. It supports comparisons between bare-metal/superloop and RTOS execution. It does not establish the smallest supported WS device.

The proposed first platform is a PC/VCP-connected STM32 gateway and three SAM leaves. All four share two CAN-FD buses and an open-drain UART; the leaves additionally form a directed UART ring. See the board requirements for node/link IDs and inclusion status.

A physical ring or two parallel CAN buses do not make cyclic logical Wires valid. Firmware deployment must construct loop-free propagation domains even when the hardware offers cycles or redundant paths.
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

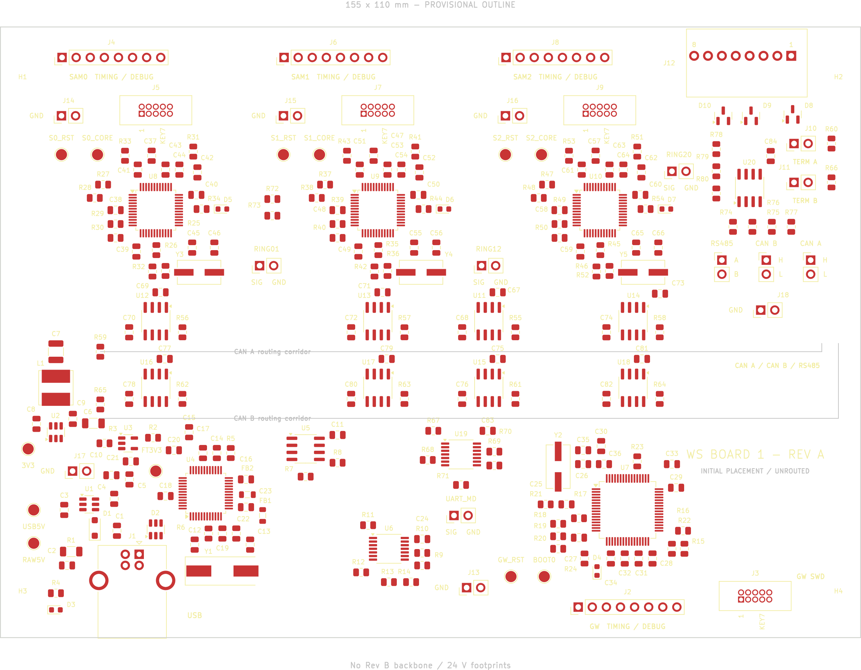
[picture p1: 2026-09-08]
boards/board1/kicad/review/board1-initial-placement.png

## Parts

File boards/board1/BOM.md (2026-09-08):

# Board 1 Rev A bill of materials

<!-- Generated by scripts/board1_documents.py; edit bom_internal.csv, bom_quantity_rules.json or bom_allocation_notes.md. -->

Status: planning BOM; selected baseline through ADR-042. [CSV](bom_internal.csv) owns parts and evidence. [Quantity rules](bom_quantity_rules.json) distinguish purchased source stock from placed pieces. Unknown counts stay TBD. All sourcing is through DigiKey; refresh order codes/stock before purchase. Acceptance is not electrical verification or an ordering release.

## Accepted selections

| ID | Buy qty | Place qty | Function | MPN | Value / package | Quantity basis | Evidence | Authority |
|---|---:|---:|---|---|---|---|---|---|
| B1-B001 | 1 | 1 | Gateway MCU | STM32G473RBT6 | NA; LQFP64 (source; verify) | components; planning allocation | unverified | ADR-004; ADR-043 |
| B1-B002 | 3 | 3 | Leaf MCU | ATSAMC21G17A-AUT | NA; TQFP48 (source; verify) | components; planning allocation | unverified | ADR-004 |
| B1-B003 | 8 | 8 | CAN-FD PHYs | TCAN3413DR | TBD; SOIC-8; footprint review pending | components; planning allocation | unverified | ADR-002 |
| B1-B004 | 1 | 1 | USB-UART bridge | FT232HL-REEL | TBD; LQFP48; footprint review pending | components; planning allocation | unverified | ADR-001 |
| B1-B005 | 1 | 1 | USB 2.0 Standard-B receptacle | USB-B1HSB6 | TBD; TBD | components; planning allocation | unverified | ADR-001; ADR-030 |
| B1-B006 | 1 | 1 | VBUS TVS | SMF6.0A | Unidirectional TVS; 6 V standoff; 200 W (10/1000 us); SOD-123FL | components; planning allocation | unverified | ADR-019; ADR-022; ADR-024 |
| B1-B008 | 4 | 4 | UART_MD driver /OE pull-up resistors | RMCF0805FT10K0 | 10 kohm +/-1%; 0.125 W; 0805 | components; planning allocation | unverified | ADR-033; ADR-039 |
| B1-B009 | 4 | 4 | Independent Cortex SWD/reset headers | 3220-10-0100-00 | 10 positions; Through-hole; 2 x 5; 1.27 mm; shrouded keyed header; footprint TBD | components; planning allocation | unverified | ADR-011; ADR-026 (026-reva-connectors.md) |
| B1-B011 | 0 | 12 | PCB test pads; no purchased components | NA | 2 mm exposed copper test pad; 12 placements; PCB copper pads | PCB pads; no purchased part | unverified | ADR-039; ADR-046 |
| B1-B012 | 1 | 1 | 3.3 V buck regulator | TPS560430X3FDBVR | 3.3 V fixed; 600 mA; 1.1 MHz FPWM; SOT-23-6 | components; planning allocation | unverified | ADR-021 |
| B1-B013 | 1 | 1 | FTDI configuration EEPROM | AT93C56B-SSHM-B | 2 Kbit; 128 x 16; 3.3 V; SOIC-8; 3.9 mm body; 1.27 mm pitch; footprint TBD | components; planning allocation | unverified | ADR-001; ADR-018 |
| B1-B014 | 1 | 1 | FTDI crystal | ECS-120-18-5PX-CKM-TR | 12 MHz; CL 18 pF; HC-49/US leaded SMT; 11.4 x 4.8 x 4.3 mm; footprint TBD | components; planning allocation | unverified | ADR-001; ADR-017; ADR-030 |
| B1-B015 | 1 | 1 | Main buck enable control | MC74HC1G14DBVT1G | Single Schmitt inverter; SC-74A; 0.95 mm pitch | components; planning allocation | unverified | ADR-013; ADR-024 |
| B1-B016 | 1 | 1 | UART power-off isolation | SN74LV125APWR | TBD; TSSOP-14; footprint review pending | components; planning allocation | unverified | ADR-001; ADR-013 |
| B1-B018 | 1 | 1 | USB data-line ESD protection | RCLAMP0504S.TCT | TBD; SOT-23-6; footprint review pending | components; planning allocation | unverified | ADR-015 |
| B1-B019 | 1 | 1 | Gateway main crystal | ECS-120-20-3X-EN-TR | 12 MHz; CL 20 pF; Miniature HC-49/US leaded SMT; 7.0 x 4.1 x 2.3 mm; footprint TBD | components; planning allocation | unverified | ADR-005; ADR-014 |
| B1-B020 | 3 | 3 | SAM main crystals | ECS-120-20-3X-EN-TR | 12 MHz; CL 20 pF; Miniature HC-49/US leaded SMT; 7.0 x 4.1 x 2.3 mm; footprint TBD | components; planning allocation | unverified | ADR-005; ADR-014 |
| B1-B021 | 1 | 1 | Rev A external RS-485 PHY | ST3485EBDR | 3.0-3.6 V; half-duplex; guaranteed 12 Mbps; SO8; 3.9 mm body; footprint review pending | components; planning allocation | unverified | ADR-007; ADR-034 |
| B1-B022 | 1 | 1 | Signal terminal block | 1989803 | PTSA 0.5/8-2.5-F; Through-hole; 8 positions; 2.5 mm pitch; 45-degree wire entry; footprint TBD | components; planning allocation | unverified | ADR-007; ADR-026 (026-reva-connectors.md) |
| B1-B024 | 4 | 4 | MCU status LEDs | CSL1901DW1 | Orange LED; 1.8 V typ at 2 mA; 0603; 1.6 x 0.8 x 0.55 mm | components; planning allocation | unverified | ADR-007; ADR-029 |
| B1-B025 | 1 | 1 | Board main-power LED | CSL1901DW1 | Orange LED; 1.8 V typ at 2 mA; 0603; 1.6 x 0.8 x 0.55 mm | components; planning allocation | unverified | ADR-007; ADR-029 |
| B1-B026 | 5 | 5 | LED resistors | RK73H2ATTD3301F | 3.3 kohm +/-1%; 0.25 W; 0805 | components; planning allocation | unverified | ADR-007; ADR-039 |
| B1-B028 | 1 | 1 | Buck inductor | SRN6045TA-120M | 12 uH +/-20%; 6 x 6 mm semi-shielded SMT | components; planning allocation | unverified | ADR-021; ADR-025 |
| B1-B029 | 1 | 1 | Buck input capacitor | C3216X7R1V106K160AC | 10 uF 35 V X7R +/-10%; 1206 | components; planning allocation | unverified | ADR-021; ADR-025 |
| B1-B030 | 1 | 1 | Buck output capacitor | C3225X7R1C226M250AC | 22 uF 16 V X7R +/-20%; 1210 | components; planning allocation | unverified | ADR-021; ADR-025 |
| B1-B031 | 1 | 1 | TPS560430 bootstrap capacitor | C0805C104K5RACTU | 100 nF 50 V X7R +/-10%; 0805 | components; planning allocation | unverified | ADR-021; ADR-025 |
| B1-B036 | 37 | 37 | Main 3.3 V pin bypass capacitors | KGM21NR71E104KT | 100 nF 25 V X7R +/-10%; 0805 | components; planning allocation | unverified | ADR-010; ADR-027 |
| B1-B037 | 4 | 4 | Shared STM32 analog bulk and SAM local bulk | CL21B105KAFNFNE | 1 uF 25 V X7R +/-10%; 0805 | components; planning allocation | unverified | ADR-010; ADR-027 |
| B1-B038 | 1 | 1 | STM32 digital bulk | GRM21BR71C475KE51L | 4.7 uF 16 V X7R +/-10%; 0805 | components; planning allocation | unverified | ADR-010; ADR-027 |
| B1-B039 | 1 | 1 | STM32 VDDA HF bypass | CL21B103KBANNNC | 10 nF 50 V X7R +/-10%; 0805 | components; planning allocation | unverified | ADR-010; ADR-027 |
| B1-B040 | 3 | 3 | SAM VDDCORE regulator capacitors | CL21B105KAFNFNE | 1 uF 25 V X7R +/-10%; 0805 | components; planning allocation | unverified | ADR-010; ADR-026 (026-sam-core-ceramic.md); ADR-027 |
| B1-B041 | 3 | 3 | SAM VDDCORE HF bypass | KGM21NR71E104KT | 100 nF 25 V X7R +/-10%; 0805 | components; planning allocation | unverified | ADR-010; ADR-027 |
| B1-B042 | 2 | 2 | Gateway crystal load capacitors | CC0805FRNPO9BN330 | 33 pF +/-1%; 50 V C0G; 0805 | components; planning allocation | unverified | ADR-005; ADR-014; ADR-031; ADR-044 |
| B1-B043 | 6 | 6 | Three SAM crystal load capacitors (two per MCU) | CC0805FRNPO9BN330 | 33 pF +/-1%; 50 V C0G; 0805 | components; planning allocation | unverified | ADR-005; ADR-014; ADR-031; ADR-044 |
| B1-B044 | 1 | 1 | Input attachment-ramp switch | TPS22810DBVT | NA; SOT-23-6 | components; planning allocation | unverified | ADR-019; ADR-022 |
| B1-B045 | 1 | 1 | Raw VBUS direct bypass | CL21B105KAFNFNE | 1 uF 25 V X7R +/-10%; 0805 | components; planning allocation | unverified | ADR-019; ADR-027 |
| B1-B046 | 1 | 1 | Raw VBUS damping capacitor | CL21A475KBQNNNE | 4.7 uF 50 V X5R +/-10%; 0805 | components; planning allocation | unverified | ADR-019; ADR-029 |
| B1-B047 | 1 | 1 | Raw VBUS damping resistor | SG73P2BTTD1R0J | 1 ohm +/-5%; anti-surge pulse resistor; 1206 | components; planning allocation | unverified | ADR-019; ADR-029 |
| B1-B048 | 1 | 1 | Input switch slew capacitor | CL21B473KBCNNNC | 47 nF 50 V X7R +/-10%; 0805 | components; planning allocation | unverified | ADR-022; ADR-027 |
| B1-B051 | 1 | 1 | FTDI reset pull-up | RMCF0805FT10K0 | 10 kohm +/-1%; 0.125 W; 0805 | components; planning allocation | unverified | ADR-022; ADR-028 |
| B1-B052 | 1 | 1 | Buck input HF bypass | C0805C104K5RACTU | 100 nF 50 V X7R +/-10%; 0805 | components; planning allocation | unverified | ADR-021; ADR-025 |
| B1-B054 | 1 | 1 | PWREN# inverter input pull-up | RMCF0805FT10K0 | 10 kohm +/-1%; 0.125 W; 0805 | components; planning allocation | unverified | ADR-024; ADR-028 |
| B1-B055 | 1 | 1 | Main buck EN pull-down | ERJ-6GEYJ473V | 47 kohm +/-5%; 0.125 W; 0805 | components; planning allocation | unverified | ADR-024; ADR-030 |
| B1-B056 | 1 | 1 | EEPROM DO series resistor | RC0805FR-072K2L | 2.2 kohm +/-1%; 0.125 W; 0805 | components; planning allocation | unverified | ADR-030 |
| B1-B057 | 1 | 1 | FTDI REF resistor | RMCF0805FT12K0 | 12 kohm +/-1%; 0.125 W; 0805 | components; planning allocation | unverified | ADR-030; ADR-031 |
| B1-B058 | 2 | 2 | FTDI crystal load capacitors | CC0805FRNPO9BN270 | 27 pF +/-1%; 50 V C0G; 0805 | components; planning allocation | unverified | ADR-031; ADR-045 |
| B1-B059 | 0 | 4 | Per-MCU combined timing/debug headers | PH1-08-UA | 1x8; 2.54 mm; Through-hole; 1x8 discrete male header; 2.54 mm pitch | four 1x8 timing/debug sections included in B1-B027 | unverified | ADR-032; ADR-039; ADR-041; ADR-042 |
| B1-B061 | 11 | 11 | Bridge-domain 100 nF bypass capacitors | KGM21NR71E104KT | 100 nF 25 V X7R +/-10%; 0805 | components; planning allocation | unverified | ADR-027 |
| B1-B062 | 0 | 0 | Bridge-domain 1 uF capacitors | CL21B105KAFNFNE | 1 uF 25 V X7R +/-10%; 0805 | components; planning allocation | unverified | ADR-027 |
| B1-B063 | 2 | 2 | Bridge-domain 4.7 uF capacitors | GRM21BR71C475KE51L | 4.7 uF 16 V X7R +/-10%; 0805 | components; planning allocation | unverified | ADR-027 |
| B1-B064 | 1 | 1 | FTDI RESET# capacitor | CL21B103KBANNNC | 10 nF 50 V X7R +/-10%; 0805 | components; planning allocation | unverified | ADR-022; ADR-027 |
| B1-B065 | 1 | 1 | EEPROM DO pull-up resistor | RMCF0805FT10K0 | 10 kohm +/-1%; 0.125 W; 0805 | components; planning allocation | unverified | ADR-028 |
| B1-B066 | 1 | 1 | Onboard open-drain UART quad driver | SN74LV125APWR | 4 channels; A=GND; TX drives /OE; TSSOP-14; footprint review pending | components; planning allocation | unverified | ADR-033 |
| B1-B067 | 4 | 4 | CAN termination resistors | CRGP0805F120R | 120 ohm +/-1%; 1/3 W; 0805 | components; planning allocation | unverified | ADR-034; ADR-035 |
| B1-B068 | 1 | 1 | Fixed local RS-485 termination resistor | CRGP0805F120R | 120 ohm +/-1%; 1/3 W; 0805 | components; planning allocation | unverified | ADR-034; ADR-035 |
| B1-B069 | 2 | 2 | CAN termination jumper headers | PRPC002SAAN-RC | 2 positions; gold flash; Through-hole; 1x2; 2.54 mm | components; planning allocation | unverified | ADR-034; ADR-035 |
| B1-B070 | 2 | 2 | CAN termination shunts | SPC02SYAN | Gold flash; 1x2; 2.54 mm; closed-top shunt | components; planning allocation | unverified | ADR-034; ADR-035 |
| B1-B071 | 2 | 2 | RS-485 idle-bus bias resistors | CRGP0805F330R | 330 ohm +/-1%; 1/3 W; 0805 | components; planning allocation | unverified | ADR-036; ADR-039 |
| B1-B072 | 2 | 2 | External CAN pair TVS arrays | ESD2CAN24DBZRQ1 | Two channels; +/-24 V standoff; SOT-23-3 DBZ; footprint review pending | components; planning allocation | unverified | ADR-037 |
| B1-B073 | 1 | 1 | External RS-485 pair TVS array | ESDS452DBZR | Two channels; +/-5.5 V standoff; SOT-23-3 DBZ; footprint review pending | components; planning allocation | unverified | ADR-038 |
| B1-B074 | 1 | 1 | UART_MD shared bus pull-up resistor | RMCF0805FT470R | 470 ohm +/-1%; 0.125 W; 0805 | components; planning allocation | unverified | ADR-039 |
| B1-B075 | 6 | 6 | Fitted scope-probe ground clip pins | PRPC002SAAN-RC | 2 positions; gold flash; Through-hole; 1x2; 2.54 mm | components; planning allocation | unverified | ADR-039 |
| B1-B076 | 24 | 24 | Per-MCU timing/debug signal series resistors | CRGP0805F330R | 330 ohm +/-1%; 1/3 W; 0805 | components; planning allocation | unverified | ADR-042 |
| B1-B077 | 2 | 2 | Shared SYNC and TRIG pull-down resistors | RMCF0805FT10K0 | 10 kohm +/-1%; 0.125 W; 0805 | components; planning allocation | unverified | ADR-041; ADR-042 |
| B1-B084 | 7 | 7 | Communications measurement headers | PRPC002SAAN-RC | 2 positions; gold flash; Through-hole; 1x2; 2.54 mm | components; planning allocation | unverified | ADR-046 |

## Draft engineering selections and residual records

| ID | Buy qty | Place qty | Function | MPN | Value / package | Quantity basis | Evidence | Authority |
|---|---:|---:|---|---|---|---|---|---|
| B1-B007 | 0 | 0 | Remaining CAN interface protection | TBD | TBD; TBD | components; planning allocation | unverified | ADR-002; ADR-034; ADR-037 |
| B1-B010 | 0 | 0 | Remaining MCU boot/reset support | TBD | TBD; TBD | components; planning allocation | unverified | ADR-004 |
| B1-B017 | 0 | 0 | Remaining unenumerated USB/bridge support network | TBD | TBD; TBD | components; planning allocation | unverified | ADR-001; ADR-018; ADR-024 |
| B1-B023 | 4 | 4 | RS-485 logic default resistors | RMCF0805FT10K0 | 10 kohm +/-1%; 0.125 W; 0805 | components; planning allocation | unverified | ADR-007; ADR-034; ADR-036; ADR-038 |
| B1-B060 | 4 | 4 | Debug RX idle pull-up resistors | RMCF0805FT10K0 | 10 kohm +/-1%; 0.125 W; 0805 | components; planning allocation | unverified | ADR-032 |
| B1-B078 | 2 | 2 | FTDI VPHY/VPLL supply ferrites | BLM21AG601SN1D | 600 ohm at 100 MHz; 0805 | components; planning allocation | unverified | ADR-001 |
| B1-B079 | 6 | 6 | VCP receiving-domain idle/default pull-ups | RMCF0805FT10K0 | 10 kohm +/-1%; 0.125 W; 0805 | components; planning allocation | unverified | ADR-024; ADR-040 |
| B1-B080 | 8 | 8 | MCU reset/boot and SAM SWCLK defaults | RMCF0805FT10K0 | 10 kohm +/-1%; 0.125 W; 0805 | components; planning allocation | unverified | ADR-004; ADR-011; ADR-042 |
| B1-B081 | 1 | 1 | Gateway NRST filter capacitor | KGM21NR71E104KT | 100 nF 25 V X7R +/-10%; 0805 | components; planning allocation | unverified | ADR-004; ADR-011; ADR-042 |
| B1-B082 | 3 | 3 | SAM reset filter capacitors | CL21B103KBANNNC | 10 nF 50 V X7R +/-10%; 0805 | components; planning allocation | unverified | ADR-004; ADR-011; ADR-042 |
| B1-B083 | 8 | 8 | CAN standby default pull-ups | RMCF0805FT10K0 | 10 kohm +/-1%; 0.125 W; 0805 | components; planning allocation | unverified | ADR-002 |

## Superseded; excluded from assembly and procurement

| ID | Buy qty | Place qty | Function | MPN | Value / package | Quantity basis | Evidence | Authority |
|---|---:|---:|---|---|---|---|---|---|
| B1-B027 | 0 | 0 | Superseded timing/debug header source strip; historical allocation only | PRPC040SAAN-RC | 40 positions; 32 allocated; Through-hole; 1 x 40 breakaway male strip; 2.54 mm pitch; cut lengths/footprints TBD | excluded | unverified | ADR-007; ADR-026 (026-reva-connectors.md); ADR-039; ADR-041; ADR-042 |
| B1-B032 | 0 | 0 | Buck mode strap | TBD | 61.9 kohm 1%; 0603 | excluded | unverified | ADR-008 |
| B1-B033 | 0 | 0 | Buck output strap | TBD | 249 kohm 1%; 0603 | excluded | unverified | ADR-008 |
| B1-B034 | 0 | 0 | Buck soft-start capacitor | TBD | 10 nF 5% C0G; 0603 | excluded | unverified | ADR-008 |
| B1-B035 | 0 | 0 | Buck PG pullup | TBD | 100 kohm; 0603 | excluded | unverified | ADR-008 |
| B1-B049 | 0 | 0 | FTDI USB_5V reset supervisor | TLV803EA42RDBZR | 4.2 V falling threshold; 200 ms nominal; SOT-23-3; R pinout | excluded | unverified | ADR-020; ADR-022 |
| B1-B050 | 0 | 0 | Supervisor supply bypass | TBD | 100 nF X7R; <=10%; >=10 V; 0805 preferred | excluded | unverified | ADR-020; ADR-022 |
| B1-B053 | 0 | 0 | Deferred Rev B CBUS reset/BOOT0; excluded from Rev A | TBD | TBD; TBD | excluded | unverified | ADR-023; ADR-042 |

## Allocation and sourcing notes

- B1-B027 buys one 40-position PRPC040SAAN-RC strip; B1-B059 counts four included 1x8 timing/debug placement pieces (32 positions). Eight positions remain unallocated. Dedicated CAN jumper headers B1-B069 are separate.
- B1-B011 represents PCB test pads and has zero purchased components. B1-B011 has 12 CAD pads (TP1–TP12); TP13–TP19 are retired. B1-B084 adds seven fitted communications measurement headers J19–J25 under ADR-046, reusing PRPC002SAAN-RC. B1-B075 is six dedicated two-post PRPC002SAAN-RC ground headers; spare strip posts remain unallocated.
- B1-B061–065 expose existing bridge allocations formerly in B1-B017. Power/USB capture settles B1-B061=11, B1-B062=0 and B1-B063=2; B1-B017 has zero residual parts after adding ferrites B1-B078 and VCP defaults B1-B079. B1-B053 is excluded from Rev A by ADR-042 (zero components/footprints).
- B1-B036 contains37 actual main-rail100nF positions, including one each at VCP/UART_MD. Two unused auxiliary reserves were removed. [Decoupling](decoupling.md) owns the allocation explanation and 34.41 uF nominal main-rail calculation. Core, bridge, buck-input and bootstrap capacitance are separate.
- Two SN74LV125APWR ICs serve VCP and UART_MD separately. B1-B008 is exactly four accepted 10 kohm /OE pull-ups; B1-B074 is the accepted shared 470 ohm pull-up.
- [Termination](termination.md), [bias](rs485_bias.md) and [interfaces](interfaces.md) describe accepted bus networks. B1-B007 has zero residual parts; B1-B023 is four RS-485 logic-default10k resistors. B1-B010 has zero residual parts after split into B080/B081/B082; B083 holds eight CAN STB pull-ups.
- Superseded rows preserve stable IDs with zero quantities. Their assembly=tbd field does not authorize fitted or DNP footprints.
- [Symbol catalog](../../libraries/symbols/README.md), [exact-part checks](../../libraries/symbols/symbol_checks.md) and [remaining IC coverage](../../libraries/symbols/remaining_ic_symbol_checks.md) describe real library artifacts. Library checks do not verify board allocation or complete schematic/layout sign-off.
- [Remaining selections](remaining_parts.md) indexes unresolved work; [requirements](requirements.md) owns question status. The generated view reflects the CSV; capture details and complete references are in [KiCad notes](kicad/README.md).

- B1-B076 adds 24 CRGP0805F330R series resistors: six per MCU beside its signal pins. B1-B071 retains two separate RS-485 bias resistors, giving 26 of this MPN total. B1-B060 excludes the eight debug series resistors already in B1-B076. No static pull-up load is added by a series resistor alone; retain the existing provisional external-load allowance until actual loads are specified.

- B1-B077 is two shared timing-input pull-downs, one per global SYNC/TRIG net. Each is 10 kohm to GND, on the header side of the four series branches. Reuse RMCF0805FT10K0; these are additional to existing FTDI/UART pull resistors. Their high-state load is supplied by the external timing driver, so no permanent 3V3_SYS pull-up current is added.

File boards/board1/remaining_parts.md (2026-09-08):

# Board 1 remaining qualification

Complete schematic capture has enumerated all components, connectors and support networks. [CSV](bom_internal.csv) owns quantities/MPNs; [CAD notes](kicad/README.md) describe 239 objects / 879 pins and checks. No fitted-component count or connectivity choice remains TBD. B007/B010/B017 are zero residual aggregates; B023/B060 are actual default resistors; B075 is six dedicated two-post ground headers. B084 is seven communications headers; B011 retains twelve rail/reset/boot/core copper pads.

Remaining work is approval and bring-up: Eeschema ERC, exact electrical/errata checks, final connector sample/cable/land-pattern and probe-clearance review, layout/DRC, power/current/startup measurements, oscillator qualification, firmware and link-rate tests. [Requirements](requirements.md) owns question status. Measurements and physical layout do not prevent complete draft capture.

Selection/evidence status is intentionally not upgraded merely because a part was captured. New default networks reuse existing selected MPNs as routine engineering choices. All sourcing remains DigiKey, with stock refresh before ordering. No fabrication release or procurement-ready BOM is claimed.

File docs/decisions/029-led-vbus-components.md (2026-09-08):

---
id: ADR-029
title: Orange LEDs and raw-VBUS damping components
status: accepted
scope: Board 1 Rev A
created: 2026-09-06
accepted_by: Explicit user instruction "Commit to those candidates."
supersedes: ADR-019 raw damping capacitor dielectric/package and resistor tolerance requirements only
superseded_by: none
---

Accept CSL1901DW1 for four MCU LEDs plus the main-power LED, CL21A475KBQNNNE for B046 (4.7 uF, 50 V, X5R, +/-10%, 0805), and SG73P2BTTD1R0J for B047 (1 ohm, +/-5%, pulse-rated, 1206). X5R replaces X7R for B046 only; 5% replaces 1% for B047. The LED's 0603 body is accepted. Sources and exact allocation are in bom_internal.csv and https://github.com/ofdouglas/ws-hardware/blob/dbcaba10831ade0516dba825d2c97d3f0017e0f5/boards/board1/passive_review.md.

No topology or nominal capacitance changes. At maximum simple capacitor tolerance/temperature screen, B046 is 5.9455 uF; ideal 5.5 V step energy is 89.93 uJ. With Rmin 0.95 ohm, initial power is 31.84 W. Effective capacitance, local temperature, pulse/ringing/repeated-hotplug validation and LED visibility remain open under B1-Q002/010/011. No hardware qualification is claimed.

RK73H2ATTD3301F is a new recommended LED-resistor candidate, not accepted by this instruction. Preserve the approximately 0.5 mA-per-LED budget until actual worst-case current is reconciled.

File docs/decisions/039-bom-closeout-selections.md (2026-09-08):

---
id: ADR-039
title: Bias and LED resistors, UART support, headers and test access
status: accepted
scope: Board 1 Rev A
created: 2026-09-06
accepted_on: 2026-09-06
accepted_by: Explicit maintainer instruction USR-33
supersedes: none
superseded_by: ADR-041 (header/general-breakout clauses only); ADR-046 (communications copper-testpad scope only)
requirements: [B1-R003, B1-R008, B1-R019, B1-R020, B1-R025]
questions: [B1-Q003, B1-Q004, B1-Q009, B1-Q010, B1-Q014]
sources: [USR-33]
---

# ADR-039: BOM closeout selections

Accept two TE CRGP0805F330R for RS-485 bias B1-B071 and five KOA RK73H2ATTD3301F LED resistors B1-B026.

Accept the multidrop support plan: four Stackpole RMCF0805FT10K0 pull-ups from driver /OE to 3V3_SYS in B1-B008, and one RMCF0805FT470R shared UART_MD bus pull-up in B1-B074. The second SN74LV125APWR and allocated bypass remain separately counted. Acceptance does not qualify a baud rate or rail-ramp behavior.

Accept the header plan: four 1x5 GPIO headers (four GPIOs plus ground per MCU) and four 1x3 debug UART headers from one PRPC040SAAN-RC 40-position strip. B1-B027 is the one-strip purchasing allocation; B1-B059 is four cut placement pieces included in that strip, not four extra purchases. 32 positions are allocated; actual cuts and final GPIO mux remain to verify. No GPIO series-resistor MPN is accepted by agreeing to the header plan.

Accept ordinary PCB signal/rail test pads B1-B011, with no purchased component for those pads. The maintainer additionally requires fitted pins for scope-probe ground clips, recorded separately as B1-B075. Exact pin MPN, count and positions remain TBD until layout/clip access is resolved. Spare strip posts are a proposal only; do not assume their consumption or silently add a new connector purchase.

[Closeout review](https://github.com/ofdouglas/ws-hardware/blob/dbcaba10831ade0516dba825d2c97d3f0017e0f5/boards/board1/bom_closeout.md) supplies part and sourcing references. Retain thermal, bias, reset, timing, GPIO load and debug power-off qualification questions. No ERC/DRC or hardware validation was performed; evidence remains unverified.

Header/general-breakout clauses are partially superseded by [ADR-041](041-timing-debug-headers.md). Other decisions remain in force.

The communications copper-testpad scope is superseded by [ADR-046](046-communications-measurement-headers.md). Rail/reset/boot/core copper pads and fitted scope-ground access remain in force.

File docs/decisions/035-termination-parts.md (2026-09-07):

---
id: ADR-035
title: Exact termination resistor and jumper parts
status: accepted
scope: Board 1 Rev A
created: 2026-09-06
accepted_on: 2026-09-06
accepted_by: Explicit maintainer instruction USR-29
supersedes: none
superseded_by: none
requirements: [B1-R026]
questions: [B1-Q003, B1-Q004, B1-Q009]
sources: [USR-29]
---

# ADR-035: Termination parts

Accept all three previously recommended MPNs: five TE CRGP0805F120R resistors across B1-B067/068, two Sullins PRPC002SAAN-RC headers B1-B069, and two Sullins SPC02SYAN shunts B1-B070. Counts and topology remain ADR-034. Use the dedicated two-pin headers, without counting additional GPIO strip consumption for these placements.

[Part specifications, manufacturer drawings and dated DigiKey evidence](https://github.com/ofdouglas/ws-hardware/blob/dbcaba10831ade0516dba825d2c97d3f0017e0f5/boards/board1/termination_parts.md) remain the supporting record. Selection does not establish thermal, fault, mating or CAD-footprint qualification; evidence remains unverified. No ERC/DRC or hardware validation performed.

The accompanying instruction to investigate idle-bus bias authorizes research, not acceptance of new bias resistor MPNs or a change to termination. See [bias investigation](../../boards/board1/rs485_bias.md), B1-Q009.

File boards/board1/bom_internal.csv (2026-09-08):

item_id | references | quantity | function | manufacturer | mpn | package | value | assembly | selection_status | evidence_status | symbol | footprint | requirements | adr | datasheet_evidence | sourcing_evidence | notes
B1-B001 | U7 | 1 | Gateway MCU | STMicroelectronics | STM32G473RBT6 | LQFP64 (source; verify) | NA | fit | accepted | unverified | MCU_ST_STM32G4:STM32G473RBTx | Package_QFP:LQFP-64_10x10mm_P0.5mm | B1-R001 | ADR-004; ADR-043 | ST DS12712 Rev5 https://www.st.com/resource/en/datasheet/stm32g473rb.pdf; exact G473 AF/electrical review pending B1-Q005; native symbol 64-pin geometry/name/type matches prior symbol | TBD | Maintainer correction 2026-09-07 / ADR-043: G473 was intended; G474 was transcription error. Draft U7 symbol/MPN corrected without wire changes; electrical/errata qualification remains unverified.
B1-B002 | U8; U9; U10 | 3 | Leaf MCU | Microchip | ATSAMC21G17A-AUT | TQFP48 (source; verify) | NA | fit | accepted | unverified | ATSAMC21G17A-AUT:ATSAMC21G17A-AUT | Package_QFP:TQFP-48_7x7mm_P0.5mm | B1-R001 | ADR-004 | DS60001479J sec.4.2.1 p.22; Table 6-2 pp.29-30; draft spreadsheet linked from pinmap.md; errata/footprint/electrical qualification pending B1-Q005; ../../libraries/symbols/ATSAMC21G17A-AUT/README.md (symbol evidence only; allocation remains unverified) | TBD | Selected USR-15 / ADR-004; exact-device implementation and sourcing verification pending
B1-B003 | U11; U12; U13; U14; U15; U16; U17; U18 | 8 | CAN-FD PHYs | Texas Instruments | TCAN3413DR | SOIC-8; footprint review pending | TBD | fit | accepted | unverified | TCAN3413DR:TCAN3413DR | Package_SO:SOIC-8_3.9x4.9mm_P1.27mm | B1-R002 | ADR-002 | usb_input.md; TI SLLSFS8A; ../../libraries/symbols/TCAN3413DR/README.md (symbol pin evidence; board allocation unverified) | 2026-09-06 TI active; distributor stock/price TBD | TCAN3413DR selected USR-06; eight Rev A; ninth only in expanded Board 1; implementation unverified
B1-B004 | U4 | 1 | USB-UART bridge | FTDI | FT232HL-REEL | LQFP48; footprint review pending | TBD | fit | accepted | unverified | Board1:FT232HL_BusPowered | Package_QFP:LQFP-48_7x7mm_P0.5mm | B1-R005 | ADR-001 | FT232H DS_FT232H v2.2 pp.6-10 and Fig.6.1 p.45; kicad/README.md; full current errata/inventory reconciliation pending | Maintainer reports purchase of 5 FT232HL in this conversation; attached eBay purchase screenshot: seller CIDITTO; five-piece listing USD 33.00. Purchase inventory only; fitted quantity remains 1. Original DigiKey code 768-1101-1-ND retained as reference; purchased packaging suffix not established. | Captured U4 with project-local bus-powered symbol correcting VCCD/EECLK/EECS electrical types; pin numbers unchanged. Purchased FT232HL per maintainer; receipt and exact inventory suffix/silicon revision remain to reconcile. FT232HL-REEL remains the design ordering MPN; screenshot does not establish REEL packaging. Workbook B1-P233-280 remains unverified; see pinmap.md for CAD naming mapping.
B1-B005 | J1 | 1 | USB 2.0 Standard-B receptacle | On Shore Technology Inc. | USB-B1HSB6 | TBD | TBD | fit | accepted | unverified | Connector:USB_B | Connector_USB:USB_B_OST_USB-B1HSxx_Horizontal | B1-R005 | ADR-001; ADR-030 | TBD | DigiKey ED2983-ND; https://www.digikey.com/en/products/detail/on-shore-technology-inc/USB-B1HSB6/2677744 | J1 pins 1 VBUS, 2 DM, 3 DP, 4 GND, 5 shell. Draft connects shell directly to ground at entry. KiCad OST USB-B1HSxx footprint selected; exact housing/drill/land-pattern approval before layout remains B1-Q004.
B1-B006 | D1 | 1 | VBUS TVS | Shenzhen Slkormicro Semicon Co., Ltd. | SMF6.0A | SOD-123FL | Unidirectional TVS; 6 V standoff; 200 W (10/1000 us) | fit | accepted | unverified | Device:D | Diode_SMD:D_SOD-123F | B1-R006 | ADR-019; ADR-022; ADR-024 | https://www.slkoric.com/upload/file/20240826/SMF11CA%20SOD-123FL.PDF ; SMF5.0A(CA)-SMF58A(CA) family sheet pp.1-2, SMF6.0A row; revision not stated; 6.67-7.37 V breakdown at 10 mA; 10.3 V clamp at 19.4 A; 400 uA maximum leakage at 6 V. Schematic/footprint approval remains B1-Q002/004. | DigiKey 5399-SMF6.0ACT-ND (cut tape); https://www.digikey.com/en/products/detail/shenzhen-slkormicro-semicon-co-ltd/SMF6-0A/26370977 ; substitution purchased per maintainer in this conversation. | Slkor replaces Littelfuse by explicit maintainer instruction in this conversation to record purchased cheaper substitutions. Earlier ADRs retain circuit authority; this instruction changes manufacturer selection only. Cathode to VBUS_RAW; anode to GND. ESD/hotplug only; not a guaranteed <=6 V clamp or polarity/OVP circuit. CAD manufacturer field still names Littelfuse and needs reconciliation before release. Evidence remains unverified; existing schematic/footprint approval and bring-up transient checks remain.
B1-B007 | NA | 0 | Remaining CAN interface protection | TBD | TBD | TBD | TBD | tbd | proposed | unverified | TBD | TBD | B1-R009 | ADR-002; ADR-034; ADR-037 | termination.md; B1-Q003/004 | TBD | Residual allocation fully enumerated in completed schematic; no unassigned components or DNP footprints. See complete capture notes.
B1-B008 | R67; R68; R69; R70 | 4 | UART_MD driver /OE pull-up resistors | Stackpole Electronics Inc. | RMCF0805FT10K0 | 0805 | 10 kohm +/-1%; 0.125 W | fit | accepted | unverified | Device:R | Resistor_SMD:R_0805_2012Metric | B1-R003 | ADR-033; ADR-039 | https://www.seielect.com/Catalog/SEI-RMCF_RMCP.pdf ; ADR-033; B1-Q003 | RMCF0805FT10K0CT-ND; refresh before purchase | USR-33 accepts multidrop plan. Four /OE pull-ups to 3V3_SYS, one per driver channel. Shared bus pull-up split to B1-B074; driver B1-B066 and bypass B1-B036 counted separately. Reset/ramp/timing and baud remain unverified.
B1-B009 | J3; J5; J7; J9 | 4 | Independent Cortex SWD/reset headers | CNC Tech | 3220-10-0100-00 | Through-hole; 2 x 5; 1.27 mm; shrouded keyed header; footprint TBD | 10 positions | fit | accepted | unverified | Connector_Generic:Conn_02x05_Odd_Even | Board1:CNC_Tech_3220-10-0100-00_2x05_P1.27mm_Vertical | B1-R007 | ADR-011; ADR-026 (026-reva-connectors.md) | https://www.cnctech.us/pdfs/3220-XX-0100-00_.pdf ; p.1; revision and footprint review TBD B1-Q004 | DigiKey 1175-1627-ND; https://www.digikey.com/en/products/detail/cnc-tech/3220-10-0100-00/3883661 ; refresh stock/price before purchase | Exact MPN selected USR-25 / ADR-026; four independent MCU headers. All ten contacts supplied; review position-7 removal against actual cable. Adapter/probe support and USB-only target-power behavior pending B1-Q004/005. Manufacturer drawing matched to native footprint; see kicad/footprint_checks.md. Physical sample/mating checks remain before layout approval.
B1-B010 | NA | 0 | Remaining MCU boot/reset support | TBD | TBD | TBD | TBD | tbd | proposed | unverified | TBD | TBD | B1-R001 | ADR-004 | TBD | TBD | Residual allocation fully enumerated in completed schematic; no unassigned components or DNP footprints. See complete capture notes.
B1-B011 | TP1; TP2; TP3; TP4; TP5; TP6; TP7; TP8; TP9; TP10; TP11; TP12 | 0 | PCB test pads; no purchased components | NA | NA | PCB copper pads | 2 mm exposed copper test pad; 12 placements | tbd | accepted | unverified | Connector:TestPoint | TestPoint:TestPoint_Pad_D2.0mm | B1-R008 | ADR-039; ADR-046 | TBD | TBD | Twelve rail/reset/boot/core pads, zero purchased parts. TP13-TP19 retired by ADR-046; seven communications headers now in B1-B084. Concise functional silkscreen and nearby ground access required.
B1-B012 | U2 | 1 | 3.3 V buck regulator | Texas Instruments | TPS560430X3FDBVR | SOT-23-6 | 3.3 V fixed; 600 mA; 1.1 MHz FPWM | fit | accepted | unverified | TPS560430X3FDBVR:TPS560430X3FDBVR | Package_TO_SOT_SMD:SOT-23-6 | B1-R006; B1-R012; B1-R023 | ADR-021 | https://www.ti.com/lit/ds/symlink/tps560430.pdf; ../../libraries/symbols/TPS560430X3FDBVR/README.md (symbol pin evidence; board allocation unverified) | DigiKey 296-51994-1-ND | Explicit user selection ADR-021; replaces SC189. Filter MPNs accepted ADR-025; electrical filter/startup qualification remains open. Captured in KiCad power/USB section; see kicad/README.md. Evidence remains unverified pending schematic/footprint approval.
B1-B013 | U5 | 1 | FTDI configuration EEPROM | Microchip Technology | AT93C56B-SSHM-B | SOIC-8; 3.9 mm body; 1.27 mm pitch; footprint TBD | 2 Kbit; 128 x 16; 3.3 V | fit | accepted | unverified | AT93C56B-SSHM-B:AT93C56B-SSHM-B | Package_SO:SOIC-8_3.9x4.9mm_P1.27mm | B1-R005; B1-R006; B1-R012 | ADR-001; ADR-018 | DS20006260B pp.3-9 and 31; FT_000288 v2.2 Table 3.3 and section 7; ADR-018; ../../libraries/symbols/AT93C56B-SSHM-B/README.md (symbol pin evidence; board allocation unverified) | DigiKey AT93C56B-SSHM-B-ND; https://www.digikey.com/en/products/detail/microchip-technology/AT93C56B-SSHM-B/3046221 ; quantity-one tube listing; refresh stock/price before purchase | Selected USR-23; ORG to VCC for x16; powered from FTDI VCCD. B1-P281-288 draft sheet. Clock/startup/word-program/footprint qualification B1-Q012; supports 1 MHz at 3.3 V. DO series resistor B1-B056; pull-up B1-B065; bypass B1-B061; residual support B1-B017. Captured in KiCad power/USB section; see kicad/README.md. Evidence remains unverified pending schematic/footprint approval.
B1-B014 | Y1 | 1 | FTDI crystal | ECS Inc. | ECS-120-18-5PX-CKM-TR | HC-49/US leaded SMT; 11.4 x 4.8 x 4.3 mm; footprint TBD | 12 MHz; CL 18 pF | fit | accepted | unverified | Device:Crystal | Crystal:Crystal_SMD_HC49-SD | B1-R005; B1-R006; B1-R012 | ADR-001; ADR-017; ADR-030 | CSM-7X Rev.2020 p.1; 25 ppm first-year screen before loading; crystal_networks.md | DigiKey 50-ECS-120-18-5PX-CKM-CT-ND; 2026-09-06 browser stock 2149; qty1 USD 0.54; recheck before purchase | Exact ECS-120-18-5PX-CKM-TR finalized by user ADR-030. Loading/startup/drive and temperature/lifetime qualification remain B1-Q008. Captured in KiCad power/USB section; see kicad/README.md. Evidence remains unverified pending schematic/footprint approval.
B1-B015 | U3 | 1 | Main buck enable control | onsemi | MC74HC1G14DBVT1G | SC-74A; 0.95 mm pitch | Single Schmitt inverter | fit | accepted | unverified | MC74HC1G14DBVT1G:MC74HC1G14DBVT1G | Package_TO_SOT_SMD:SOT-23-5 | B1-R005; B1-R006; B1-R012 | ADR-013; ADR-024 | https://www.onsemi.com/pdf/datasheet/mc74hc1g14-d.pdf; ../../libraries/symbols/MC74HC1G14DBVT1G/README.md (symbol evidence only; allocation unverified) | TBD | Selected by explicit user instruction; FTDI_3V3 supply; pin1 NC pin2 PWREN# pin3 GND pin4 buck EN pin5 VCC. Support resistors selected in B1-B054/055; local bypass in B1-B061; startup qualification remains B1-Q002. Captured in KiCad power/USB section; see kicad/README.md. Evidence remains unverified pending schematic/footprint approval.
B1-B016 | U6 | 1 | UART power-off isolation | Texas Instruments | SN74LV125APWR | TSSOP-14; footprint review pending | TBD | fit | accepted | unverified | SN74LV125APWR:SN74LV125APWR | Package_SO:TSSOP-14_4.4x5mm_P0.65mm | B1-R005; B1-R006; B1-R012 | ADR-001; ADR-013 | https://www.ti.com/lit/ds/symlink/sn74lv125a.pdf; ../../libraries/symbols/SN74LV125APWR/README.md (symbol evidence only; allocation unverified) | TBD | Selected USR-18; two channels each direction TX/RX/RTS/CTS; VCC=3V3_SYS; default-disabled /OE; one 100 nF from B1-B036 auxiliary reserve; level/ramp/timing qualification pending Captured in KiCad power/USB section; see kicad/README.md. Evidence remains unverified pending schematic/footprint approval.
B1-B017 | NA | 0 | Remaining unenumerated USB/bridge support network | TBD | TBD | TBD | TBD | tbd | proposed | unverified | TBD | TBD | B1-R005; B1-R006; B1-R012 | ADR-001; ADR-018; ADR-024 | usb_vcp.md; full circuit/pin verification pending | TBD | Residual allocation closed by power/USB capture: all support enumerated in B1-B051/054-058/061-065/078/079. Zero purchases/placements; aggregate is not a physical part. No DNP footprints.
B1-B018 | D2 | 1 | USB data-line ESD protection | Semtech Corporation | RCLAMP0504S.TCT | SOT-23-6; footprint review pending | TBD | fit | accepted | unverified | RCLAMP0504S.TCT:RCLAMP0504S.TCT | Package_TO_SOT_SMD:SOT-23-6 | B1-R005; B1-R006; B1-R012 | ADR-015 | https://www.semtech.com/products/circuit-protection/low-capacitance/rclamp0504s; ../../libraries/symbols/RCLAMP0504S.TCT/README.md (symbol evidence only; allocation unverified) | TBD | Selected USR-20; D+/D- ESD; internal TVS reference (pin 5 NC) proposal; unused I/O NC; not VBUS overvoltage protection; placement and ESD qualification pending Captured in KiCad power/USB section; see kicad/README.md. Evidence remains unverified pending schematic/footprint approval.
B1-B019 | Y2 | 1 | Gateway main crystal | ECS Inc. | ECS-120-20-3X-EN-TR | Miniature HC-49/US leaded SMT; 7.0 x 4.1 x 2.3 mm; footprint TBD | 12 MHz; CL 20 pF | fit | accepted | unverified | Device:Crystal | Crystal:Crystal_SMD_ECS_CSM3X-2Pin_7.6x4.1mm | B1-R015 | ADR-005; ADR-014 | crystal_networks.md; CSM-3X Rev.2017 pp.1-2; qualification pending | DigiKey XC1787CT-ND; 2026-09-06 observed stock 499092; qty1 USD 0.37; recheck before purchase | Selected USR-19; common MPN for four independent MCU crystals; FTDI separate ADR-017; load/startup/drive pending B1-Q008 Manufacturer drawing matched to native footprint; see kicad/footprint_checks.md. Physical sample/mating checks remain before layout approval.
B1-B020 | Y3; Y4; Y5 | 3 | SAM main crystals | ECS Inc. | ECS-120-20-3X-EN-TR | Miniature HC-49/US leaded SMT; 7.0 x 4.1 x 2.3 mm; footprint TBD | 12 MHz; CL 20 pF | fit | accepted | unverified | Device:Crystal | Crystal:Crystal_SMD_ECS_CSM3X-2Pin_7.6x4.1mm | B1-R015 | ADR-005; ADR-014 | crystal_networks.md; CSM-3X Rev.2017 pp.1-2; qualification pending | DigiKey XC1787CT-ND; 2026-09-06 observed stock 499092; qty1 USD 0.37; recheck before purchase | Selected USR-19; common MPN for four independent MCU crystals; FTDI separate ADR-017; load/startup/drive pending B1-Q008 Manufacturer drawing matched to native footprint; see kicad/footprint_checks.md. Physical sample/mating checks remain before layout approval.
B1-B021 | U20 | 1 | Rev A external RS-485 PHY | STMicroelectronics | ST3485EBDR | SO8; 3.9 mm body; footprint review pending | 3.0-3.6 V; half-duplex; guaranteed 12 Mbps | fit | accepted | unverified | ST3485EBDR:ST3485EBDR | Package_SO:SOIC-8_3.9x4.9mm_P1.27mm | B1-R016; B1-R017; B1-R021 | ADR-007; ADR-034 | https://www.st.com/resource/en/datasheet/st3485eb.pdf ; DS2947 Rev12 March 2021 pp.2-6/16/18; B1-Q009; ../../libraries/symbols/ST3485EBDR/README.md (symbol evidence only; allocation unverified) | DigiKey 497-2080-1-ND; https://www.digikey.com/en/products/detail/stmicroelectronics/ST3485EBDR/599328 ; 2026-09-06 observed 23827 stock; USD 1.48 qty1; refresh before order | Selected USR-28. Replaces unaccepted THVD1420DR candidate. Existing B1-B036 RS485 bypass allocation retained. Floating-input fail-safe only; terminated-idle bias, MCU thresholds, DE-/RE defaults/timing, protection, loaded current and exact footprint remain B1-Q009. Termination split to B1-B068.
B1-B022 | J12 | 1 | Signal terminal block | Phoenix Contact | 1989803 | Through-hole; 8 positions; 2.5 mm pitch; 45-degree wire entry; footprint TBD | PTSA 0.5/8-2.5-F | fit | accepted | unverified | Connector_Generic:Conn_01x08 | Board1:PhoenixContact_PTSA_0.5_8-2.5-F_1989803 | B1-R016; B1-R017 | ADR-007; ADR-026 (026-reva-connectors.md) | https://www.phoenixcontact.com/en-us/products/printed-circuit-board-terminal-ptsa-05-8-25-f-1989803 ; technical data and dimensions; revision/footprint review TBD B1-Q004 | DigiKey 277-7678-ND; https://www.digikey.com/en/products/detail/phoenix-contact/1989803/3597015 ; order code checked 2026-09-06; refresh stock/price before purchase | Exact MPN selected USR-25 / ADR-026; one fixed push-in block for two CAN pairs plus one RS-485 pair and two grounds. Terminal order/polarity and mechanical qualification pending B1-Q004; no power/backbone terminal added. Manufacturer drawing matched to native footprint; see kicad/footprint_checks.md. Physical sample/mating checks remain before layout approval.
B1-B023 | R74; R75; R76; R77 | 4 | RS-485 logic default resistors | Stackpole Electronics Inc. | RMCF0805FT10K0 | 0805 | 10 kohm +/-1%; 0.125 W | fit | proposed | unverified | Device:R | Resistor_SMD:R_0805_2012Metric | B1-R016; B1-R017; B1-R021 | ADR-007; ADR-034; ADR-036; ADR-038 | https://www.seielect.com/Catalog/SEI-RMCF_RMCP.pdf | DigiKey RMCF0805FT10K0CT-ND; refresh before purchase | 10k DE pulldown, /RE pullup, DI pullup and RO pullup; conventional reset shutdown and idle-high RX.
B1-B024 | D4; D5; D6; D7 | 4 | MCU status LEDs | ROHM Semiconductor | CSL1901DW1 | 0603; 1.6 x 0.8 x 0.55 mm | Orange LED; 1.8 V typ at 2 mA | fit | accepted | unverified | Device:LED | LED_SMD:LED_0603_1608Metric | B1-R019 | ADR-007; ADR-029 | https://www.rohm.com/products/led/chip-leds-mono-color-type/standard/csl1901dw-product | https://www.digikey.com/en/products/detail/rohm-semiconductor/CSL1901DW1/16685592 | Exact LED selected ADR-029; target approximately 0.5 mA; brightness and resistor/current qualification pending. One independently controlled per MCU.
B1-B025 | D3 | 1 | Board main-power LED | ROHM Semiconductor | CSL1901DW1 | 0603; 1.6 x 0.8 x 0.55 mm | Orange LED; 1.8 V typ at 2 mA | fit | accepted | unverified | Device:LED | LED_SMD:LED_0603_1608Metric | B1-R019 | ADR-007; ADR-029 | https://www.rohm.com/products/led/chip-leds-mono-color-type/standard/csl1901dw-product | https://www.digikey.com/en/products/detail/rohm-semiconductor/CSL1901DW1/16685592 | Exact LED selected ADR-029; target approximately 0.5 mA; brightness and resistor/current qualification pending. Powered from 3V3_SYS; off during suspend. Captured in KiCad power/USB section; see kicad/README.md. Evidence remains unverified pending schematic/footprint approval.
B1-B026 | R4; R24; R34; R44; R54 | 5 | LED resistors | KOA Speer Electronics Inc. | RK73H2ATTD3301F | 0805 | 3.3 kohm +/-1%; 0.25 W | fit | accepted | unverified | Device:R | Resistor_SMD:R_0805_2012Metric | B1-R019 | ADR-007; ADR-039 | https://www.koaspeer.com/catimages/Products/RK73H/RK73H.pdf | DigiKey 2019-RK73H2ATTD3301FCT-ND | USR-33 accepts five RK73H2ATTD3301F LED resistors. Low-current LED brightness and GPIO output drop remain unverified. Captured in KiCad power/USB section; see kicad/README.md. Evidence remains unverified pending schematic/footprint approval.
B1-B027 | TBD | 1 | Superseded timing/debug header source strip; historical allocation only | Sullins Connector Solutions | PRPC040SAAN-RC | Through-hole; 1 x 40 breakaway male strip; 2.54 mm pitch; cut lengths/footprints TBD | 40 positions; 32 allocated | tbd | superseded | unverified | TBD | TBD | B1-R025; B1-R027 | ADR-007; ADR-026 (026-reva-connectors.md); ADR-039; ADR-041; ADR-042 | https://mm.digikey.com/Volume0/opasdata/d220001/medias/docus/386/xRxCzzzSxxN-RC_ST_11635-B.pdf ; drawing 11635 Rev.B p.1; cut-footprint review TBD B1-Q004/010 | Historical DigiKey S1011EC-40-ND; do not purchase. Replaced by four discrete Adam Tech PH1-08-UA headers in B1-B059. | Explicit maintainer instruction in this conversation replaces the cut-strip purchase with discrete 1x8 headers. Quantity 1 is retained unchanged as historical source-strip allocation only; it is not an active purchase or placement. B1-B059 now owns all four fitted and purchased headers. No spare strip positions remain allocated. Existing bom_quantity_rules.json and cut-strip documents still describe the old purchase scheme and need reconciliation before regenerating procurement outputs.
B1-B028 | L1 | 1 | Buck inductor | Bourns | SRN6045TA-120M | 6 x 6 mm semi-shielded SMT | 12 uH +/-20% | fit | accepted | unverified | Device:L | Inductor_SMD:L_Bourns_SRN6045TA | B1-R023 | ADR-021; ADR-025 | buck_tps560430.md; manufacturer sources linked there | DigiKey 118-SRN6045TA-120MCT-ND; listing found 2026-09-06; recheck at purchase | 65 milliohm +/-20%; Irms 3 A typ; Isat 4 A typ at 30% L drop. Semi-shielded, not fully shielded. User accepted exact part; electrical qualification remains open. Captured in KiCad power/USB section; see kicad/README.md. Evidence remains unverified pending schematic/footprint approval.
B1-B029 | C6 | 1 | Buck input capacitor | TDK | C3216X7R1V106K160AC | 1206 | 10 uF 35 V X7R +/-10% | fit | accepted | unverified | Device:C | Capacitor_SMD:C_1206_3216Metric | B1-R023 | ADR-021; ADR-025 | buck_tps560430.md; manufacturer sources linked there | DigiKey 445-14799-1-ND; listing found 2026-09-06; recheck at purchase | Retains accepted nominal 10 uF category; exact MPN accepted by ADR-025; verify effective input capacitance. User accepted exact part; electrical qualification remains open. Captured in KiCad power/USB section; see kicad/README.md. Evidence remains unverified pending schematic/footprint approval.
B1-B030 | C7 | 1 | Buck output capacitor | TDK | C3225X7R1C226M250AC | 1210 | 22 uF 16 V X7R +/-20% | fit | accepted | unverified | Device:C | Capacitor_SMD:C_1210_3225Metric | B1-R023 | ADR-021; ADR-025 | buck_tps560430.md; manufacturer sources linked there | DigiKey 445-3955-1-ND; listing found 2026-09-06; recheck at purchase | Local output capacitor; effective C, total rail C and transient/loop verification pending; no SC189 30 uF limit. User accepted exact part; electrical qualification remains open. Captured in KiCad power/USB section; see kicad/README.md. Evidence remains unverified pending schematic/footprint approval.
B1-B031 | C8 | 1 | TPS560430 bootstrap capacitor | KEMET | C0805C104K5RACTU | 0805 | 100 nF 50 V X7R +/-10% | fit | accepted | unverified | Device:C | Capacitor_SMD:C_0805_2012Metric | B1-R023 | ADR-021; ADR-025 | buck_tps560430.md; manufacturer sources linked there | DigiKey 399-C0805C104K5RACTUCT-ND; listing found 2026-09-06; recheck at purchase | VIN-to-GND bypass adjacent to chip. User accepted exact part; electrical qualification remains open. Captured in KiCad power/USB section; see kicad/README.md. Evidence remains unverified pending schematic/footprint approval. Function description reconciled to existing CAD: C8 is bootstrap (B031), C9 input bypass (B052); identical selected 100n MPN, no circuit/value change.
B1-B032 | NA | 0 | Buck mode strap | TBD | TBD | 0603 | 61.9 kohm 1% | tbd | superseded | unverified | TBD | TBD | B1-R023 | ADR-008 | https://github.com/ofdouglas/ws-hardware/blob/dbcaba10831ade0516dba825d2c97d3f0017e0f5/boards/board1/buck_converter.md | TBD | Historical TPS62902-only part; excluded from current procurement/population; ADR-010
B1-B033 | NA | 0 | Buck output strap | TBD | TBD | 0603 | 249 kohm 1% | tbd | superseded | unverified | TBD | TBD | B1-R023 | ADR-008 | https://github.com/ofdouglas/ws-hardware/blob/dbcaba10831ade0516dba825d2c97d3f0017e0f5/boards/board1/buck_converter.md | TBD | Historical TPS62902-only part; excluded from current procurement/population; ADR-010
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

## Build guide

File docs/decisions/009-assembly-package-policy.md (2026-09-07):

---
id: ADR-009
title: Packages compatible with available assembly and rework tools
status: accepted
scope: Hardware project part selection and layout
created: 2026-09-06
accepted_on: 2026-09-06
accepted_by: Explicit user instruction USR-09
supersedes: none
superseded_by: none
requirements: []
questions: []
sources: [USR-09]
---

# ADR-009: Assembly and package policy

## Decision
Prefer SMT packages with exposed leads. QFN can be considered only with justification. Exclude BGA unless it is existential to an essential function. Available tools are a soldering iron and hot-air station. Avoid the smallest SMT passives; medium sizes are suitable.

## Consequences
Apply [part selection policy](../PART_SELECTION_POLICY.md#assembly-and-package-constraints--accepted-usr-09--adr-009) to new selections. The proposed TPS62902 is not accepted and must not become the default without package justification. Evaluate leaded alternatives first. Future FPGA interest does not itself authorize BGA or change this rule. Numeric passive-size defaults in the policy are an implementation interpretation, not separately user-frozen dimensions.

## Revisit trigger
An essential function cannot be realized under these constraints, or the user changes available tools/preferences. Record evidence; do not reopen merely for a smaller footprint.

## Maintainer clarification — USR-17

0805 imperial is easy to hand solder; 0603 is doable but small; exclude 0402 and smaller from new selections. Smaller crystal packages are acceptable when they have accessible leads. This makes the earlier medium-passive preference explicit; it does not accept leadless crystals or reopen the existing QFN/BGA policy. Historical text is retained.

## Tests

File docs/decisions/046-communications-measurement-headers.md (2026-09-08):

---
id: ADR-046
title: Communications measurement headers
status: accepted
scope: Board 1 Rev A measurement access
created: 2026-09-07
accepted_on: 2026-09-07
accepted_by: Explicit maintainer instruction USR-38 in this conversation
supersedes: ADR-039 (communications copper-testpad scope only)
superseded_by: none
requirements: [B1-R008, B1-R004]
questions: [B1-Q004]
sources: [USR-38]
---

# ADR-046: Communications measurement headers

The maintainer requests: “communications test points should use 2-pin 0.1\" headers” and “we need test points for the UART ring”, then supplies the seven interface arrangements below. This explicitly authorizes replacing communications copper pads and adding three UART-ring observation headers. It supersedes only the communications copper-pad portion of ADR-039; ordinary rail/reset/boot/core pads, fitted ground headers and its other surviving decisions remain.

| Header | Interface | Pin 1 | Pin 2 |
|---|---|---|---|
| J19 | CAN A | FD_CAN_A_H | FD_CAN_A_L |
| J20 | CAN B | FD_CAN_B_H | FD_CAN_B_L |
| J21 | RS-485 | RS485_A | RS485_B |
| J22 | SAM0 → SAM1 UART ring | RING_01 | GND |
| J23 | SAM1 → SAM2 UART ring | RING_12 | GND |
| J24 | SAM2 → SAM0 UART ring | RING_20 | GND |
| J25 | Shared UART_MD | UART_MD | GND |

Retire TP13–TP19 without reusing their designators. Retain TP1–TP12 and the six dedicated two-post ground headers J13–J18. B1-B011 therefore has twelve PCB pads and no purchased components. New stable BOM item B1-B084 contains seven fitted headers. Reuse the already selected Sullins PRPC002SAAN-RC and its 1×2 2.54 mm vertical through-hole footprint as a routine implementation choice, not a separately maintainer-specified MPN. Existing manufacturer references are in [termination notes](../../boards/board1/termination.md).

Place headers near the measured link with short observation branches, reasonable clip clearance, concise function/polarity silkscreen and nearby ground access for differential headers. UART headers carry their own ground. These are observation connectors, not termination jumpers; fit no shunts. No resistor, PHY, protection or termination circuit changes follow from this decision. Layout approval checks physical access, polarity and routing; link waveform qualification remains bring-up work. Header selection does not assert ERC/DRC, mechanical qualification or hardware validation.

The alternatives were retaining the copper pads or using larger connectors. The requested 1×2 headers provide removable probe/lead access with a small conventional footprint and add seven purchased pieces. No additional architecture review is needed for this bounded bench-access change.

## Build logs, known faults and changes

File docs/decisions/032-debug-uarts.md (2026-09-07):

---
id: ADR-032
title: Independent MCU text debug UARTs
status: accepted
scope: Board 1 all four MCUs
created: 2026-09-06
accepted_by: Explicit maintainer instruction USR-26
supersedes: none
superseded_by: ADR-041 (header/general-breakout clauses only)
requirements: [B1-R025]
questions: [B1-Q014]
---

# Decision

Expose a dedicated TX/RX/GND text-debug UART for each of the four MCUs at 115200 baud, on a three-position 0.1-inch (2.54 mm) header. These are additional to SWD, gateway VCP, multidrop, ring and RS-485. Header category and rate are accepted by USR-26; exact header MPN and implemented pin allocation remain unverified.

Propose 3.3 V non-inverted logic, idle high, 8N1 and no flow control. Number each header 1=MCU TX, 2=MCU RX, 3=GND; no power pin. Silkscreen identifies GW/SAM0/SAM1/SAM2 and directions from the MCU perspective. Adapter RX connects to MCU TX and adapter TX to MCU RX. Use a 3.3 V logic USB-UART adapter, not an RS-232-voltage interface. Off-state adapter drive and protection require B1-Q014 review before connection to an unpowered target.

# Draft allocation and evidence

SAM0/1/2 each use SERCOM2: PA12 pad21 TX/PAD0 and PA13 pad22 RX/PAD1, mux C, TXPO=0 and RXPO=1. This leaves SERCOM0 multidrop and SERCOM1 ring intact. [DS60001479J](https://ww1.microchip.com/downloads/en/DeviceDoc/SAM-C20-C21-Family-Data-Sheet-DS60001479J.pdf), p.22, Table 6-2 p.30 and USART CTRLA p.505.

STM32G474RBT6 uses LPUART1: PB11 pad33 TX and PB10 pad30 RX, AF8. The low-power UART can serve as an ordinary asynchronous debug port; this does not replace USART2 VCP. [DS12288 Rev.6](https://www.st.com/resource/en/datasheet/stm32g474vb.pdf), pp.50,63,74. LPUART kernel source/prescaler/baud and SAM SERCOM baud setup still need validation at 115200.

# Consequences and remaining checks

Eight unused MCU pads become debug signals; existing link and breakout allocations remain intact. Keep stable per-pad IDs in the workbook. B1-B059 covers four fitted headers (source strip MPN/cut quantity TBD), B1-B060 covers support/protection as required. Do not count cut headers and source strips twice or reuse occupied UART-buffer channels.

B1-Q014 covers header order/footprint/MPN, input defaults, off-state/back-power behavior, short bench cable assumptions, current limits, clock/baud error, firmware resource use and simultaneous UART/CAN traffic. Confirm exact current datasheets/errata, electrical compatibility and footprint before marking any row verified. No schematic, ERC/DRC or hardware validation is claimed.

Alternatives: multiplexing debug over network/VCP would not provide the requested dedicated per-MCU interface; SWD remains complementary. 8N1 and header ordering are implementation proposals, not separately accepted maintainer requirements.

Header/general-breakout clauses are partially superseded by [ADR-041](041-timing-debug-headers.md). Other decisions remain in force.

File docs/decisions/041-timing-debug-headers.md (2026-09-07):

---
id: ADR-041
title: Combined per-MCU timing and debug headers
status: accepted
scope: Board 1 Rev A
created: 2026-09-07
accepted_by: Explicit maintainer instruction USR-35
supersedes: ADR-007 general breakout scope; ADR-032 three-pin connector format; ADR-039 header cut plan only
requirements: [B1-R020, B1-R025, B1-R027]
sources: [USR-35]
---

# Current authority

ADR-042 records the maintainer-specified pin order and series resistors. Header scope and cut plan below remain accepted; the historical description of pin order as an engineering choice is superseded.

# Decision

Provide one 1x8, 0.1-inch male header per MCU: debug UART RX/TX, two grounds, global SYNC and TRIG inputs to interrupt-capable GPIO on every MCU, and two private EVENT0/EVENT1 outputs per MCU. General ADC, SPI/I2C and GPIO breakouts are deferred to a later revision; no associated support parts or DNP footprints are implied.

Retain the selected Sullins PRPC040SAAN-RC. Four eight-position pieces use 32 positions from one 40-position strip. B1-B027 owns the source-strip purchase; B1-B059 owns all four placed headers. Eight spare positions remain unallocated. Keep independent SWD headers, 115200-baud text UARTs, LEDs, selected resistors and scope-ground access.

[Timing header implementation](../../boards/board1/timing_headers.md) defines the routine pin order and implementation checks. Exact timing pads are not yet verified. The requested interface is accepted; the engineering pin order is a reversible implementation choice. No schematic connectivity or hardware validation is claimed.

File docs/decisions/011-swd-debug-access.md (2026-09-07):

---
id: ADR-011
title: Independent Cortex SWD headers and owned debug probes
status: accepted
scope: Board 1 programming and debug access
created: 2026-09-06
accepted_on: 2026-09-06
accepted_by: Explicit maintainer instruction USR-16
supersedes: none
superseded_by: none
requirements: [B1-R007]
questions: [B1-Q004, B1-Q005]
sources: [USR-16]
---

# Independent Cortex SWD headers and owned debug probes

Use the four independent keyed 10-pin, 1.27 mm Cortex SWD headers proposed in https://github.com/ofdouglas/ws-hardware/blob/dbcaba10831ade0516dba825d2c97d3f0017e0f5/boards/board1/oscillator_debug_options.md, one per MCU, with individual reset access. The maintainer accepts the 10-pin Cortex SWD header approach and plans to use an owned J-Link EDU; a PICkit 5 is also on hand if necessary. These are external bench tools, not new onboard circuitry or procurement items.

Exact connector MPN/footprint, numbering, cable/adapter compatibility, probe revision/software device support and unpowered-target behavior remain B1-Q004/005. No successful flashing or debug test is asserted. Preserve USB-only target power. Do not infer an additional onboard debug connector for PICkit 5; evaluate an external adapter if needed.

The accompanying preference for one common 12 MHz crystal MPN is a selection objective, not acceptance or qualification of a crystal. See the candidate research in https://github.com/ofdouglas/ws-hardware/blob/dbcaba10831ade0516dba825d2c97d3f0017e0f5/boards/board1/crystal_candidates.md.

## Implementation selection — USR-25 / ADR-026 (026-reva-connectors.md)

[ADR-026](026-reva-connectors.md) selects the exact B1-B009 connector MPN. The original decision and its history remain intact; footprint, numbering, adapter/cable and probe behavior checks remain B1-Q004/005.

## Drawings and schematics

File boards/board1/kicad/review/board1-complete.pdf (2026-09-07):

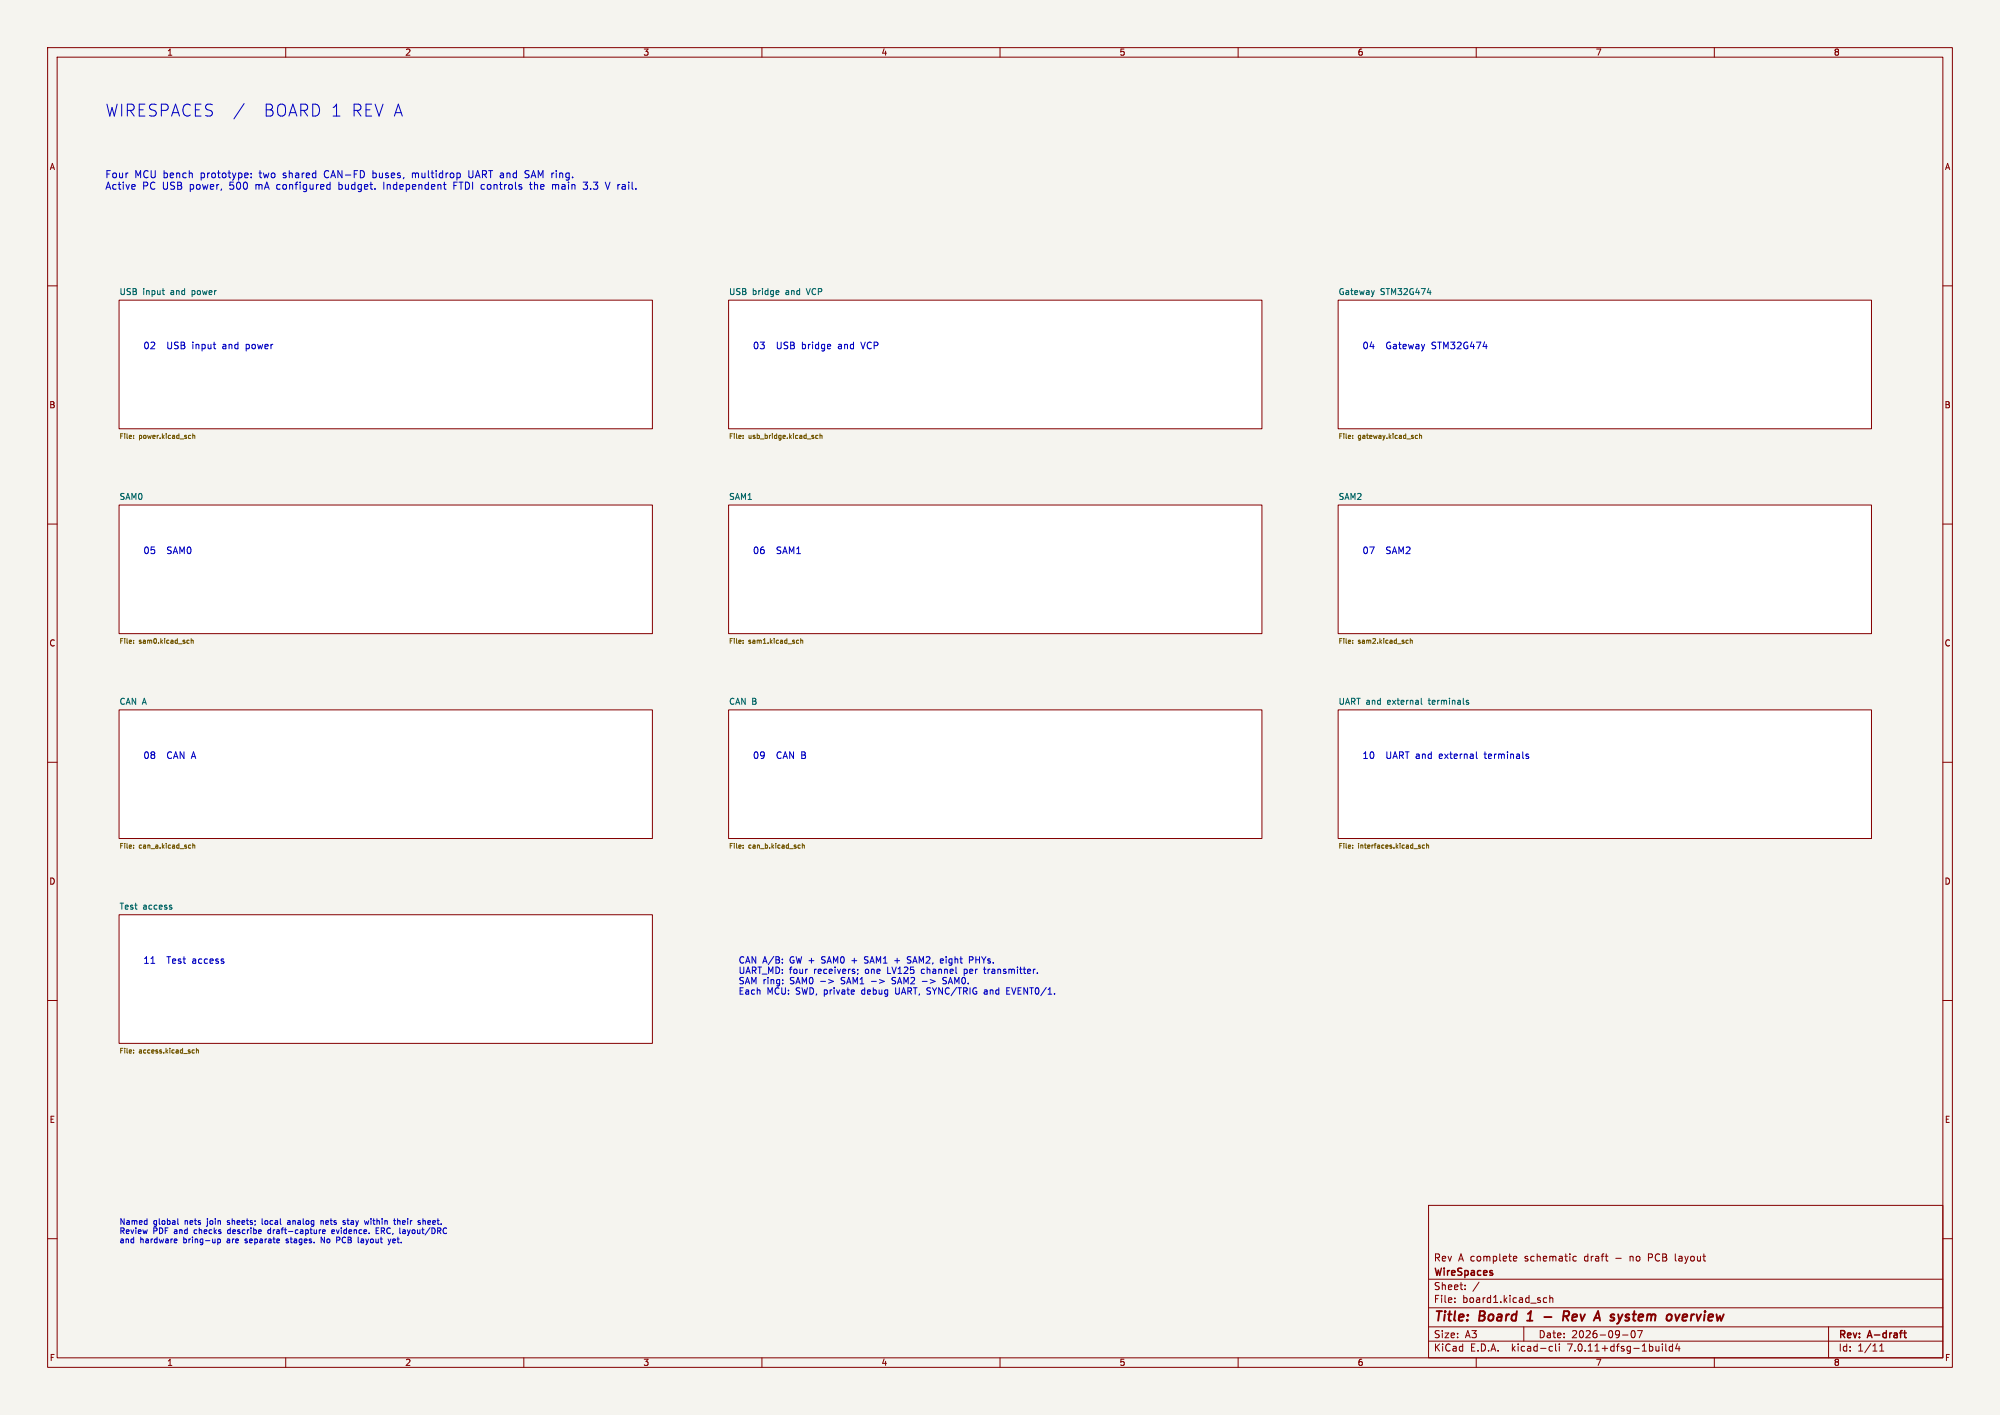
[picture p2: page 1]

USB input and power File: power.kicad_sch Test access

Id: 1/11 Title: Board 1 - Rev A system overview

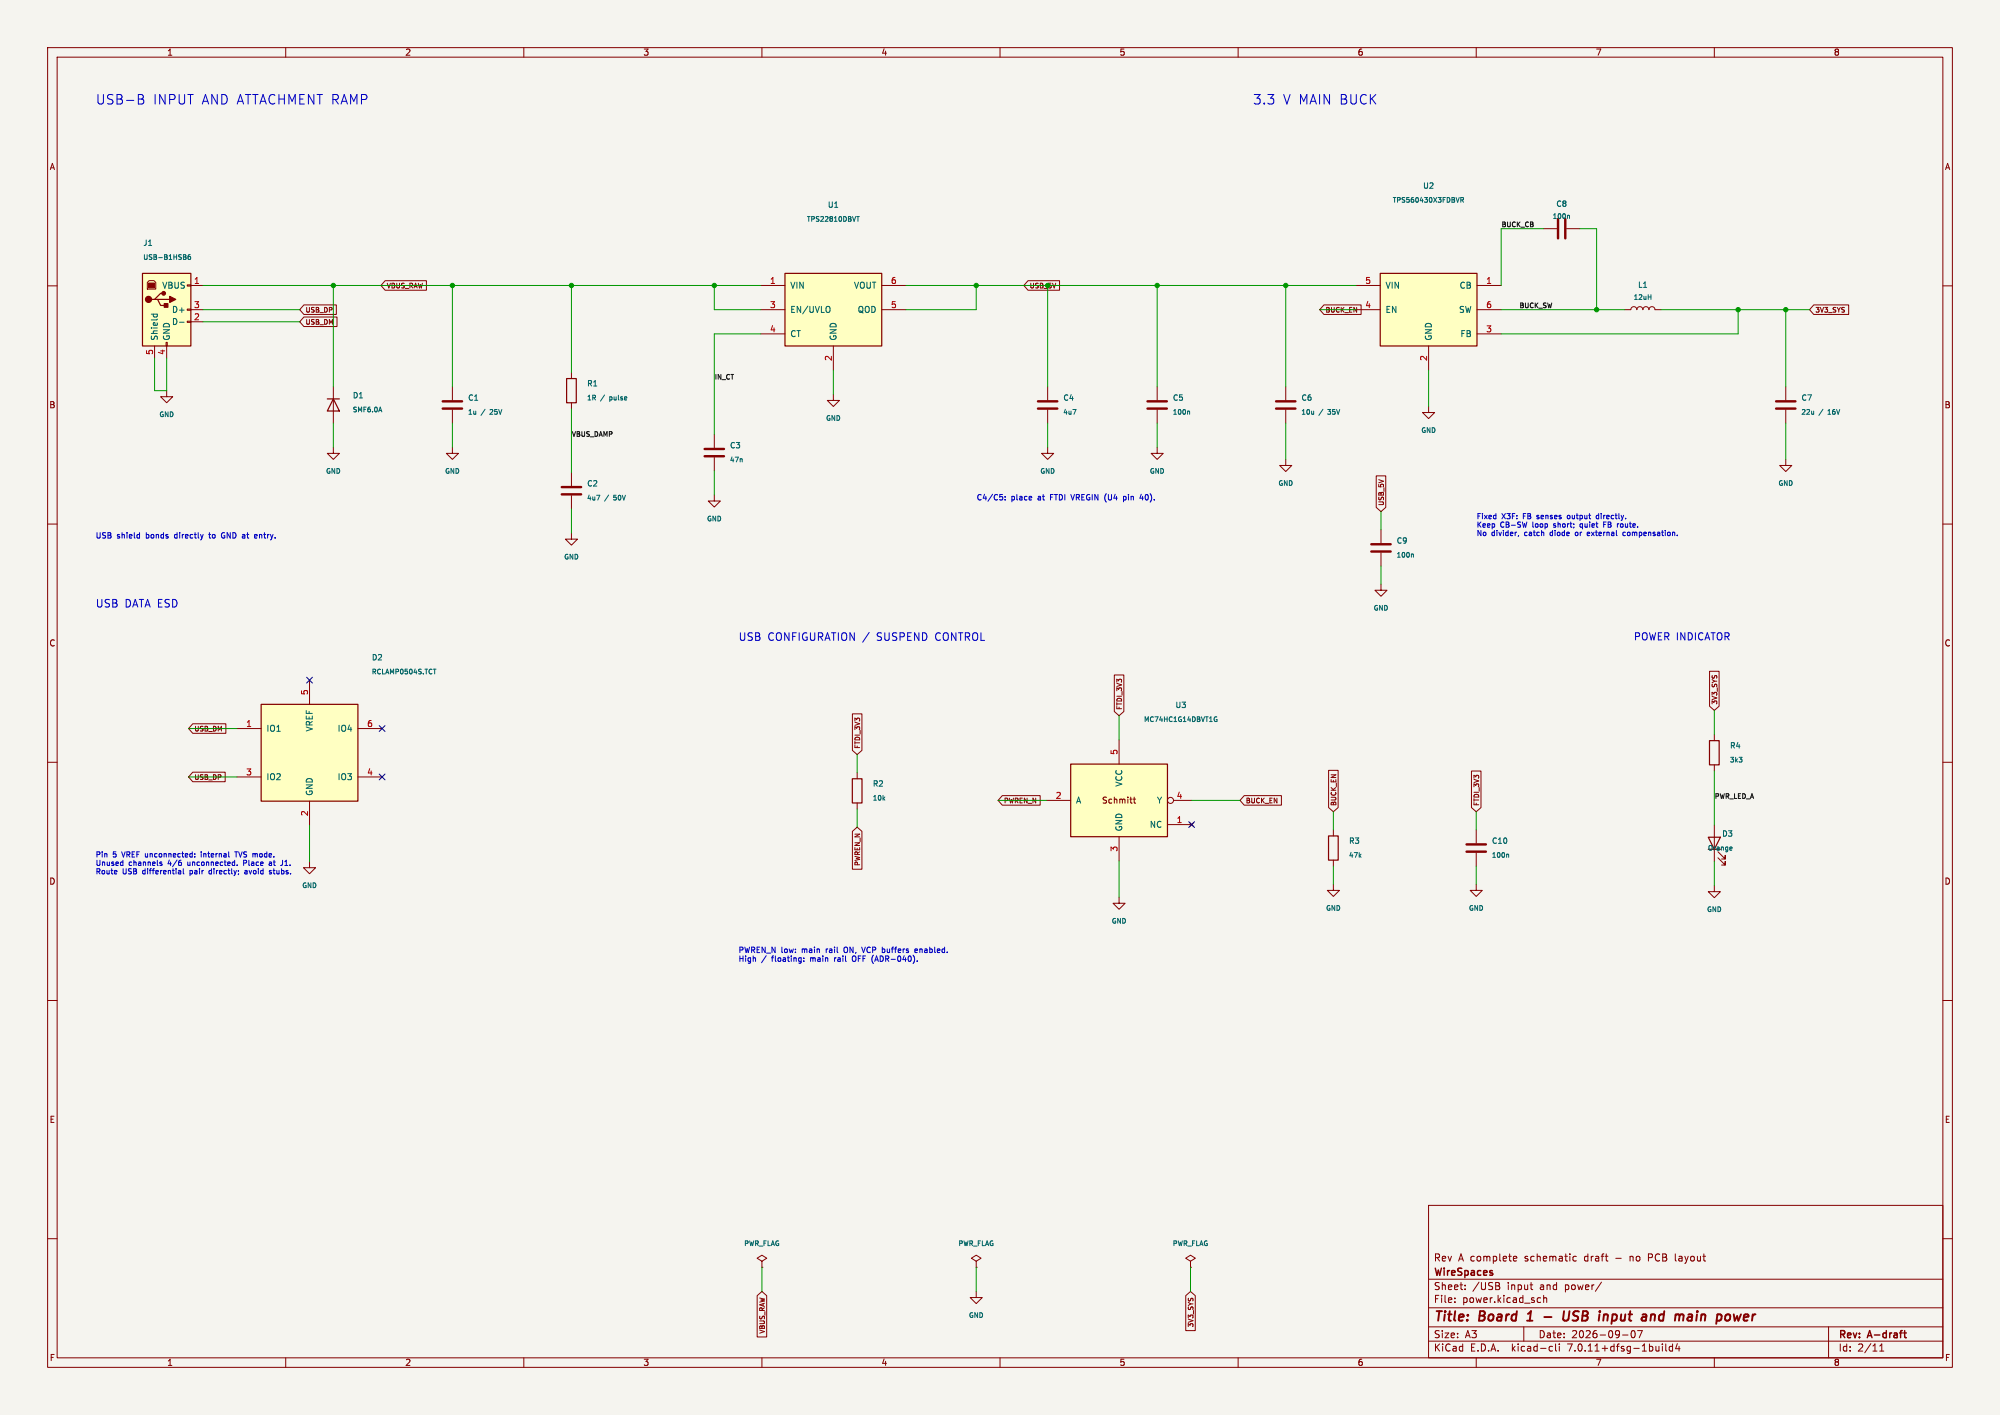
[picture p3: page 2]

USB-B INPUT AND ATTACHMENT RAMP

2 FB 3 EN 4 VIN 5 SW 6 U2

2 EN/UVLO 3 CT 4 QOD 5 VOUT 6 U1

USB CONFIGURATION / SUSPEND CONTROL

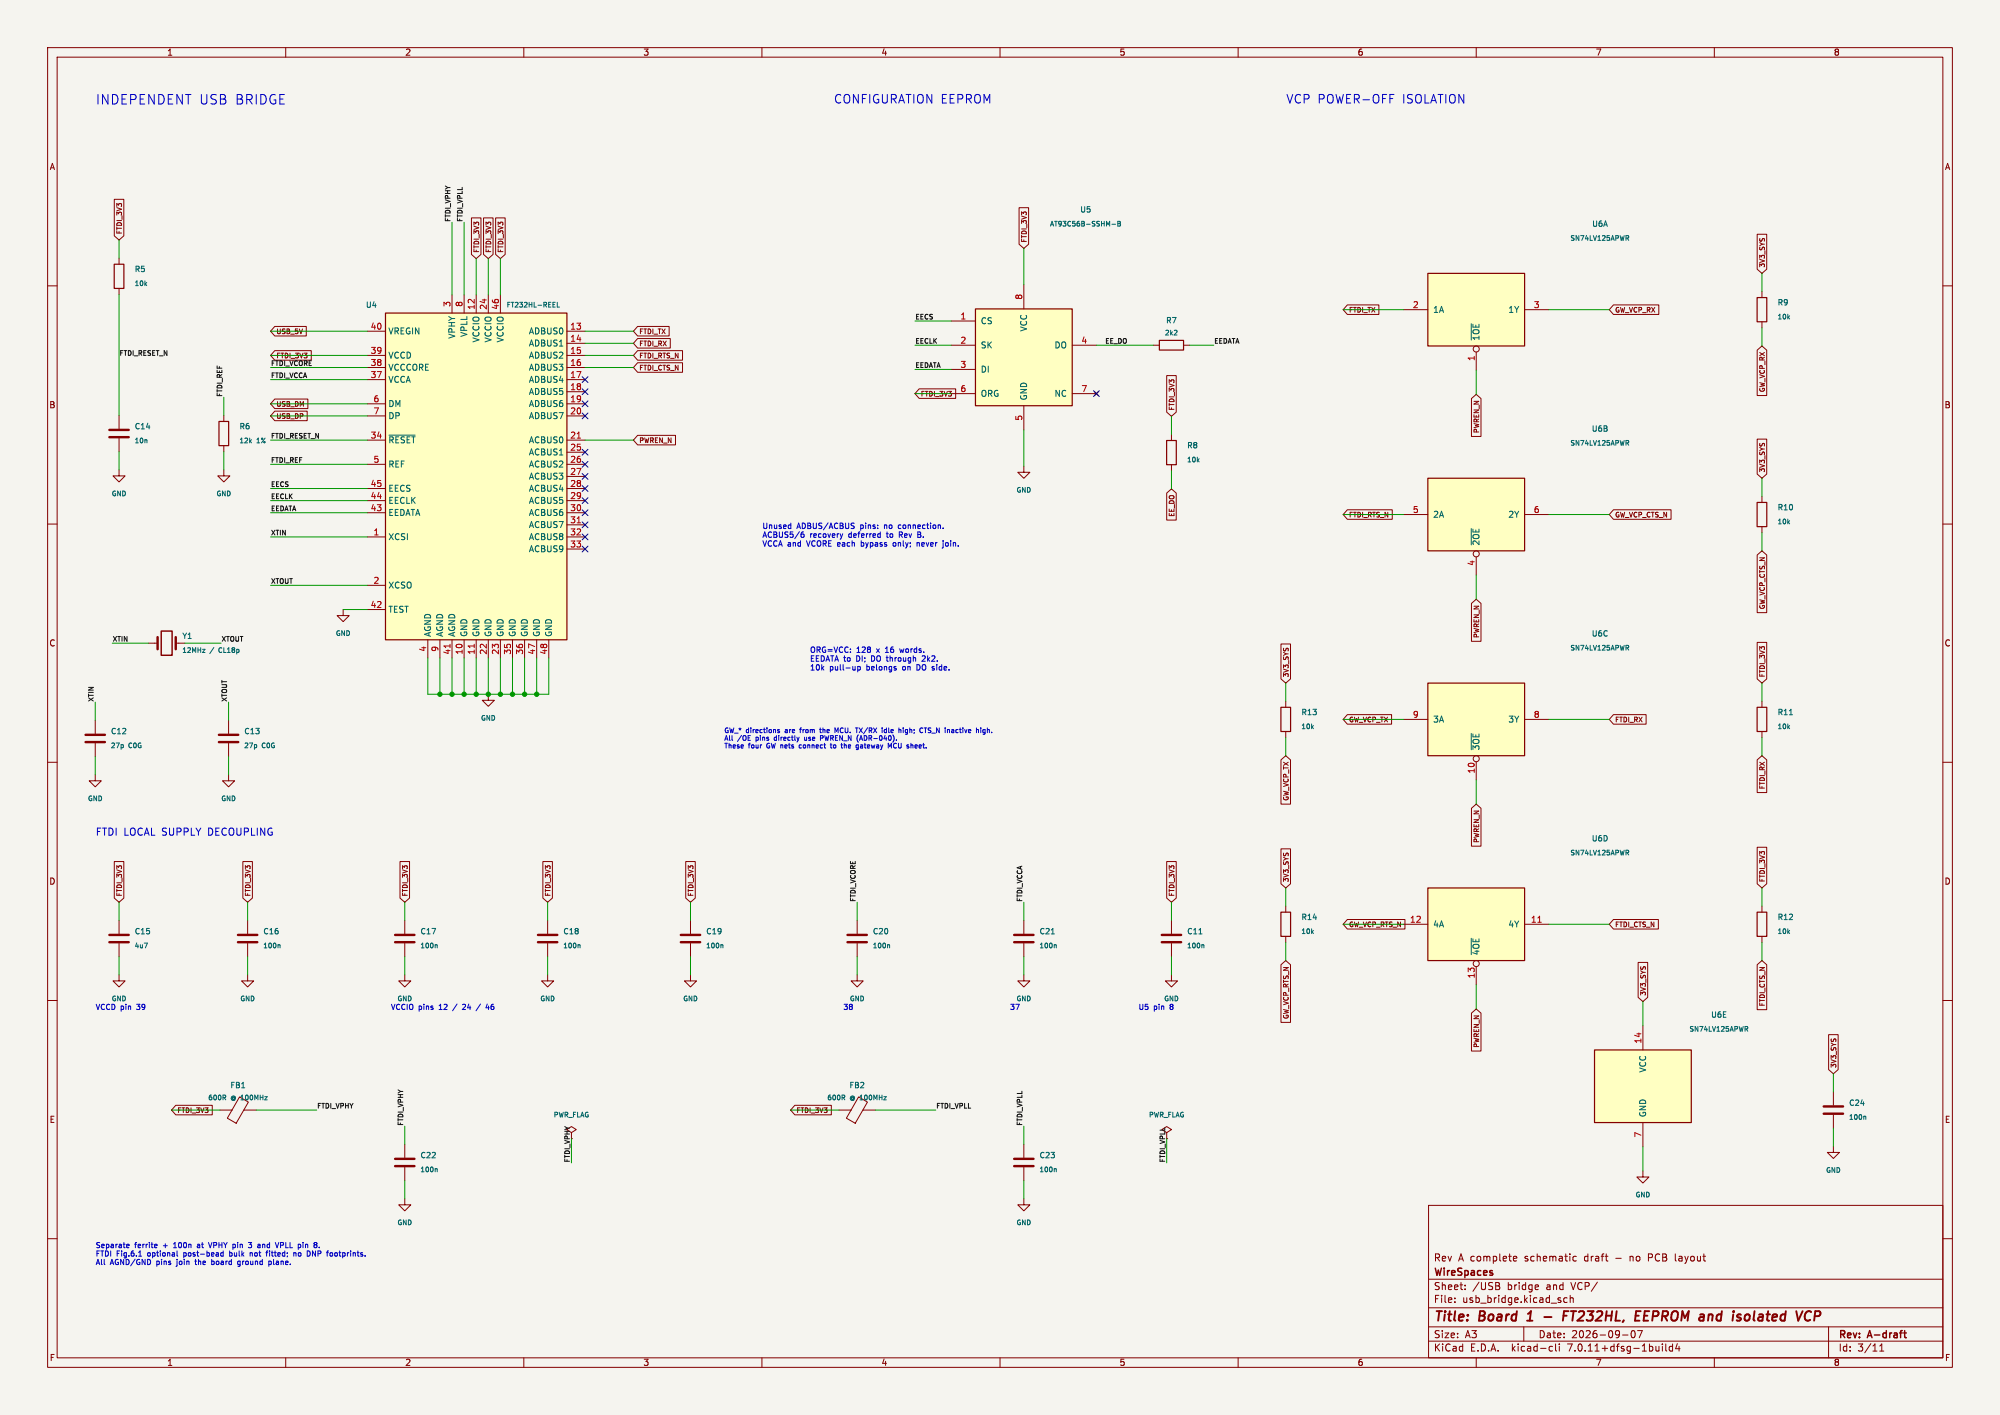
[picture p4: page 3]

VCP POWER-OFF ISOLATION

4 VREGIN 40 AGND 41 TEST 42 EEDATA 43 EECLK 44 EECS 45 VCCIO 46 GND 47 GND 48 REF 5 DM 6 DP 7 VPLL

3 ACBUS6 30 ACBUS7 31 ACBUS8 32 ACBUS9 33 ~{RESET} 34 GND 35 GND 36 VCCA 37 VCCCORE 38 VCCD 39 AGND

U5 pin 8 FTDI LOCAL SUPPLY DECOUPLING

Id: 3/11 Title: Board 1 - FT232HL, EEPROM and isolated VCP

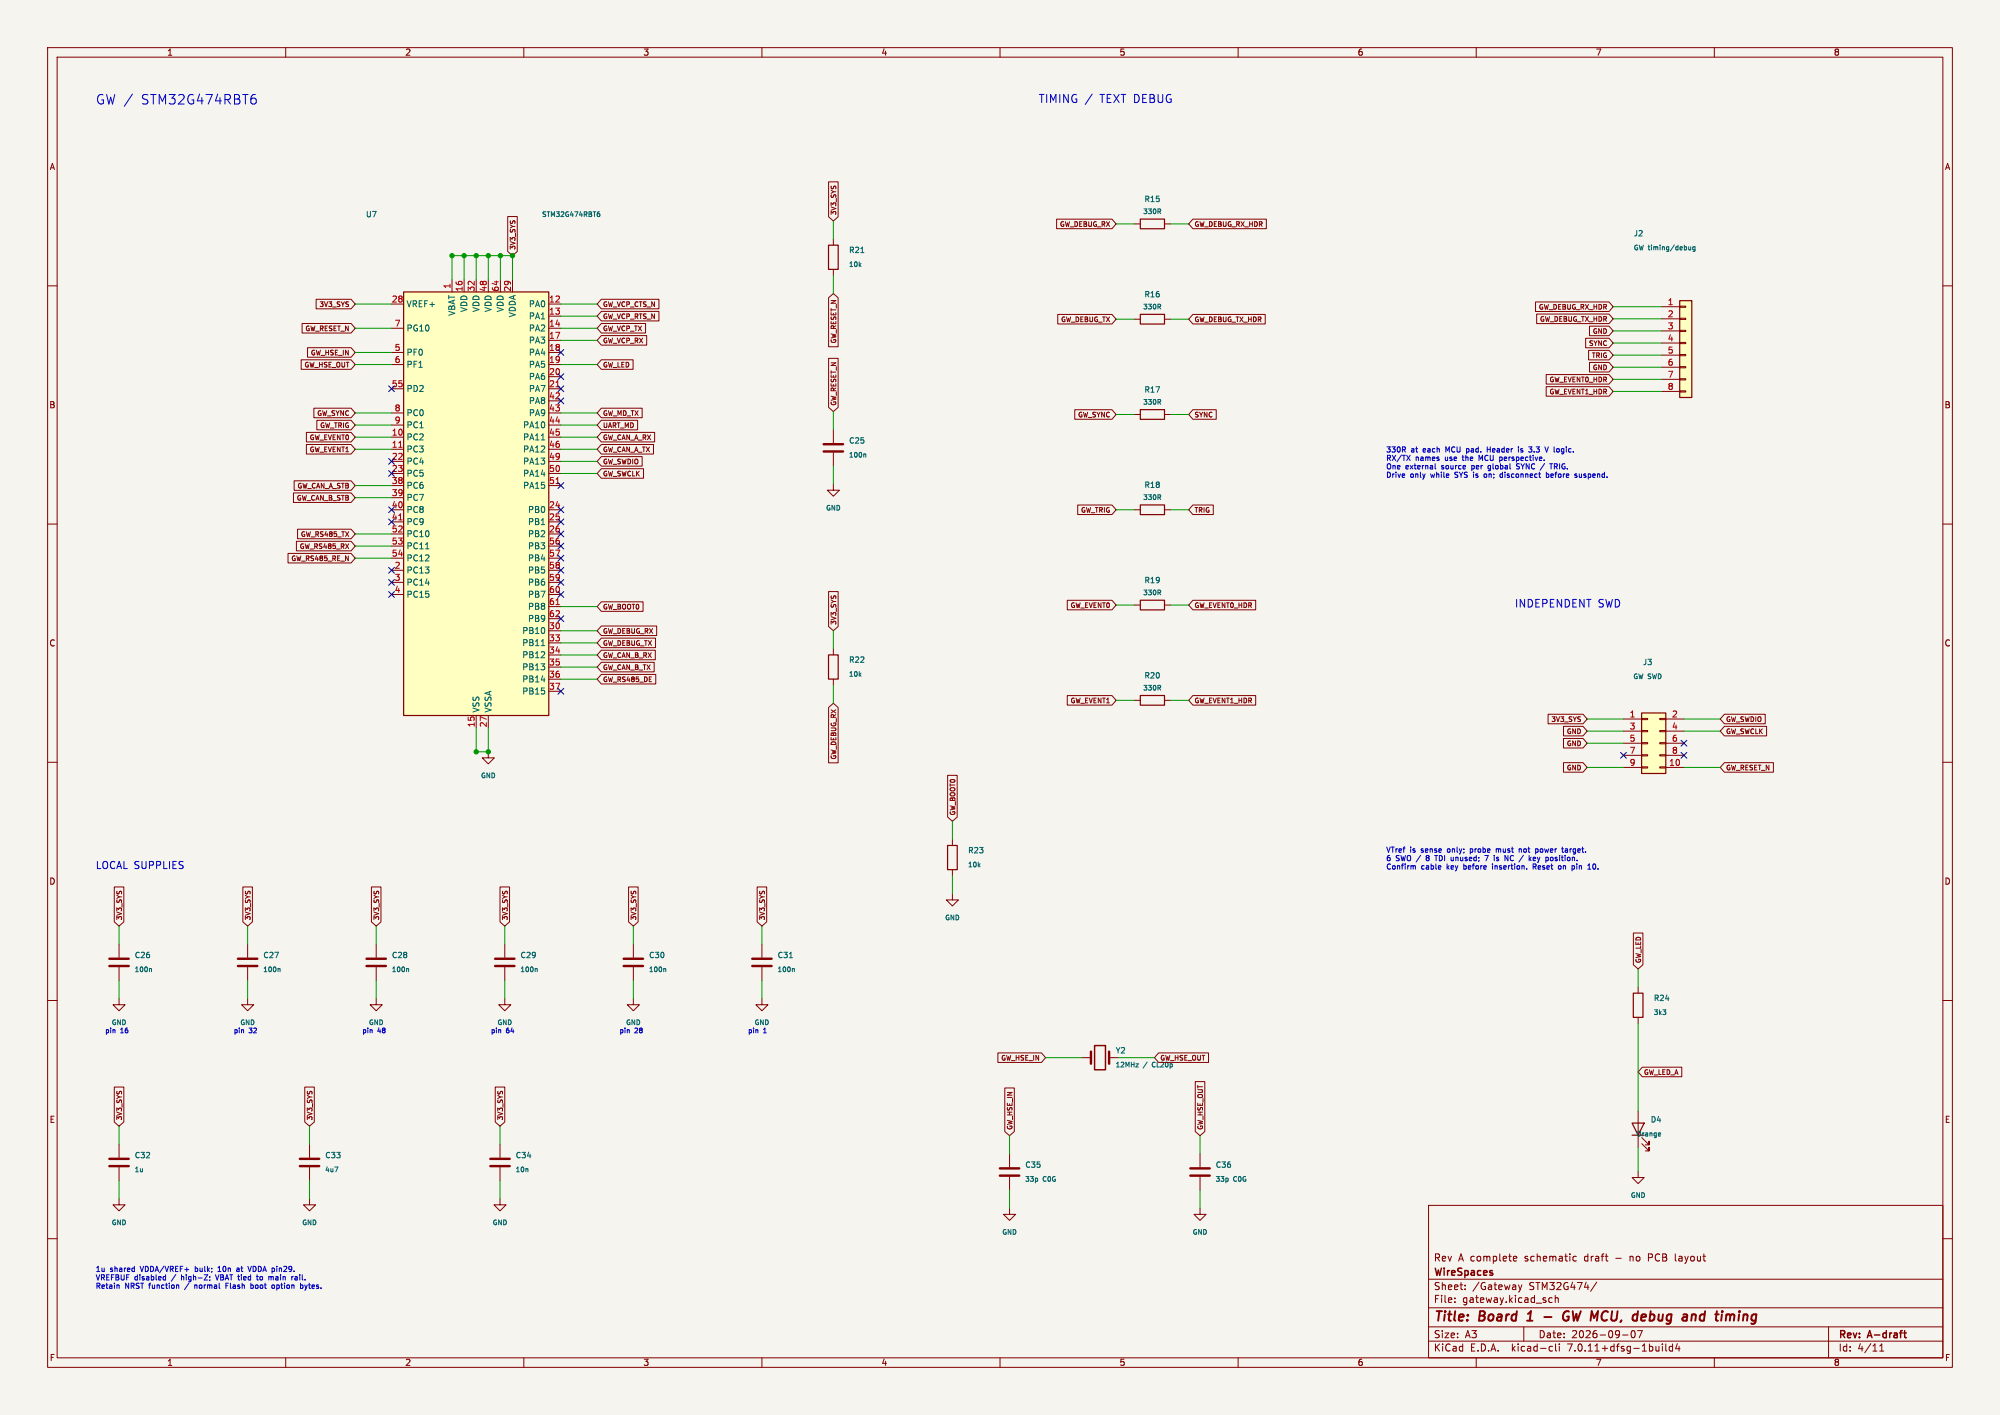
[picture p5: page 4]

1 PC2 10 PC3 11 PA0 12 PA1 13 PA2 14 VSS 15 VDD 16 PA3 17 PA4 18 PA5 19 PC13 2 PA6 20 PA7 21 PC4 22 PC5 23 PB0 24 PB1 25 PB2 26 VSSA 27 VREF+ 28 VDDA 29 PC14 3 PB10 30 VDD 32 PB11 33 PB12 34 PB13 35 PB14 36 PB15 37 PC6 38 PC7 39 PC15 4 PC8 40 PC9 41 PA8 42 PA9 43 PA10 44 PA11 45 PA12 46 VDD 48 PA13 49 PF0 5 PA14 50 PA15 51 PC10 52 PC11 53 PC12 54 PD2 55 PB3 56 PB4 57 PB5 58 PB6 59 PF1 6 PB7 60 PB8 61 PB9 62 VDD 64 PG10 7 PC0 8 PC1 9 U7 STM32G474RBT6

Id: 4/11 Title: Board 1 - GW MCU, debug and timing

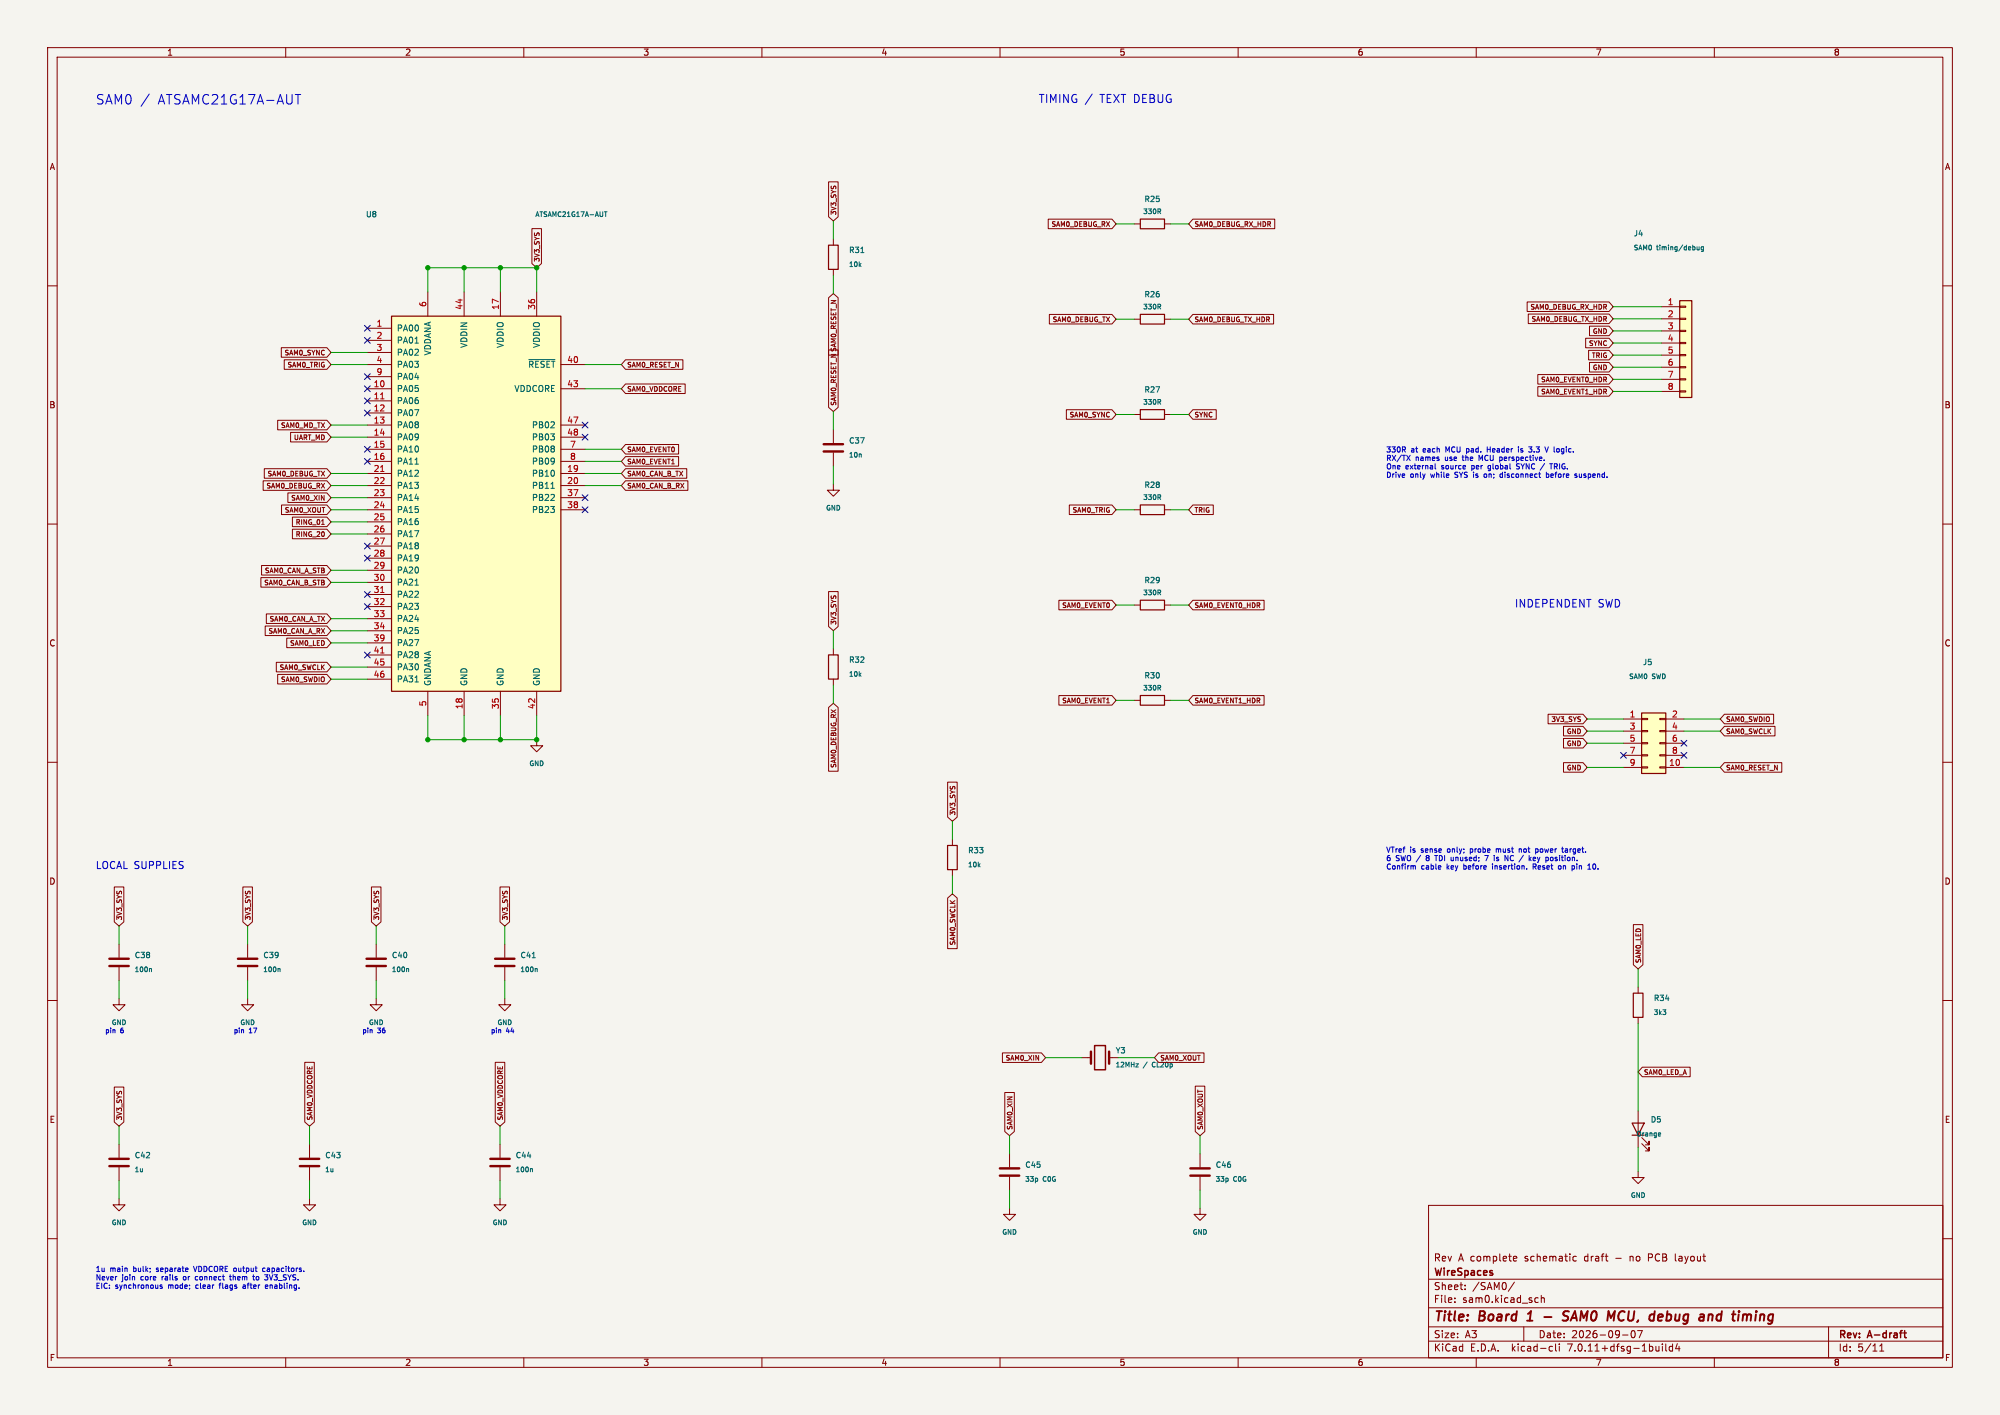
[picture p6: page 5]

Id: 5/11 Title: Board 1 - SAM0 MCU, debug and timing

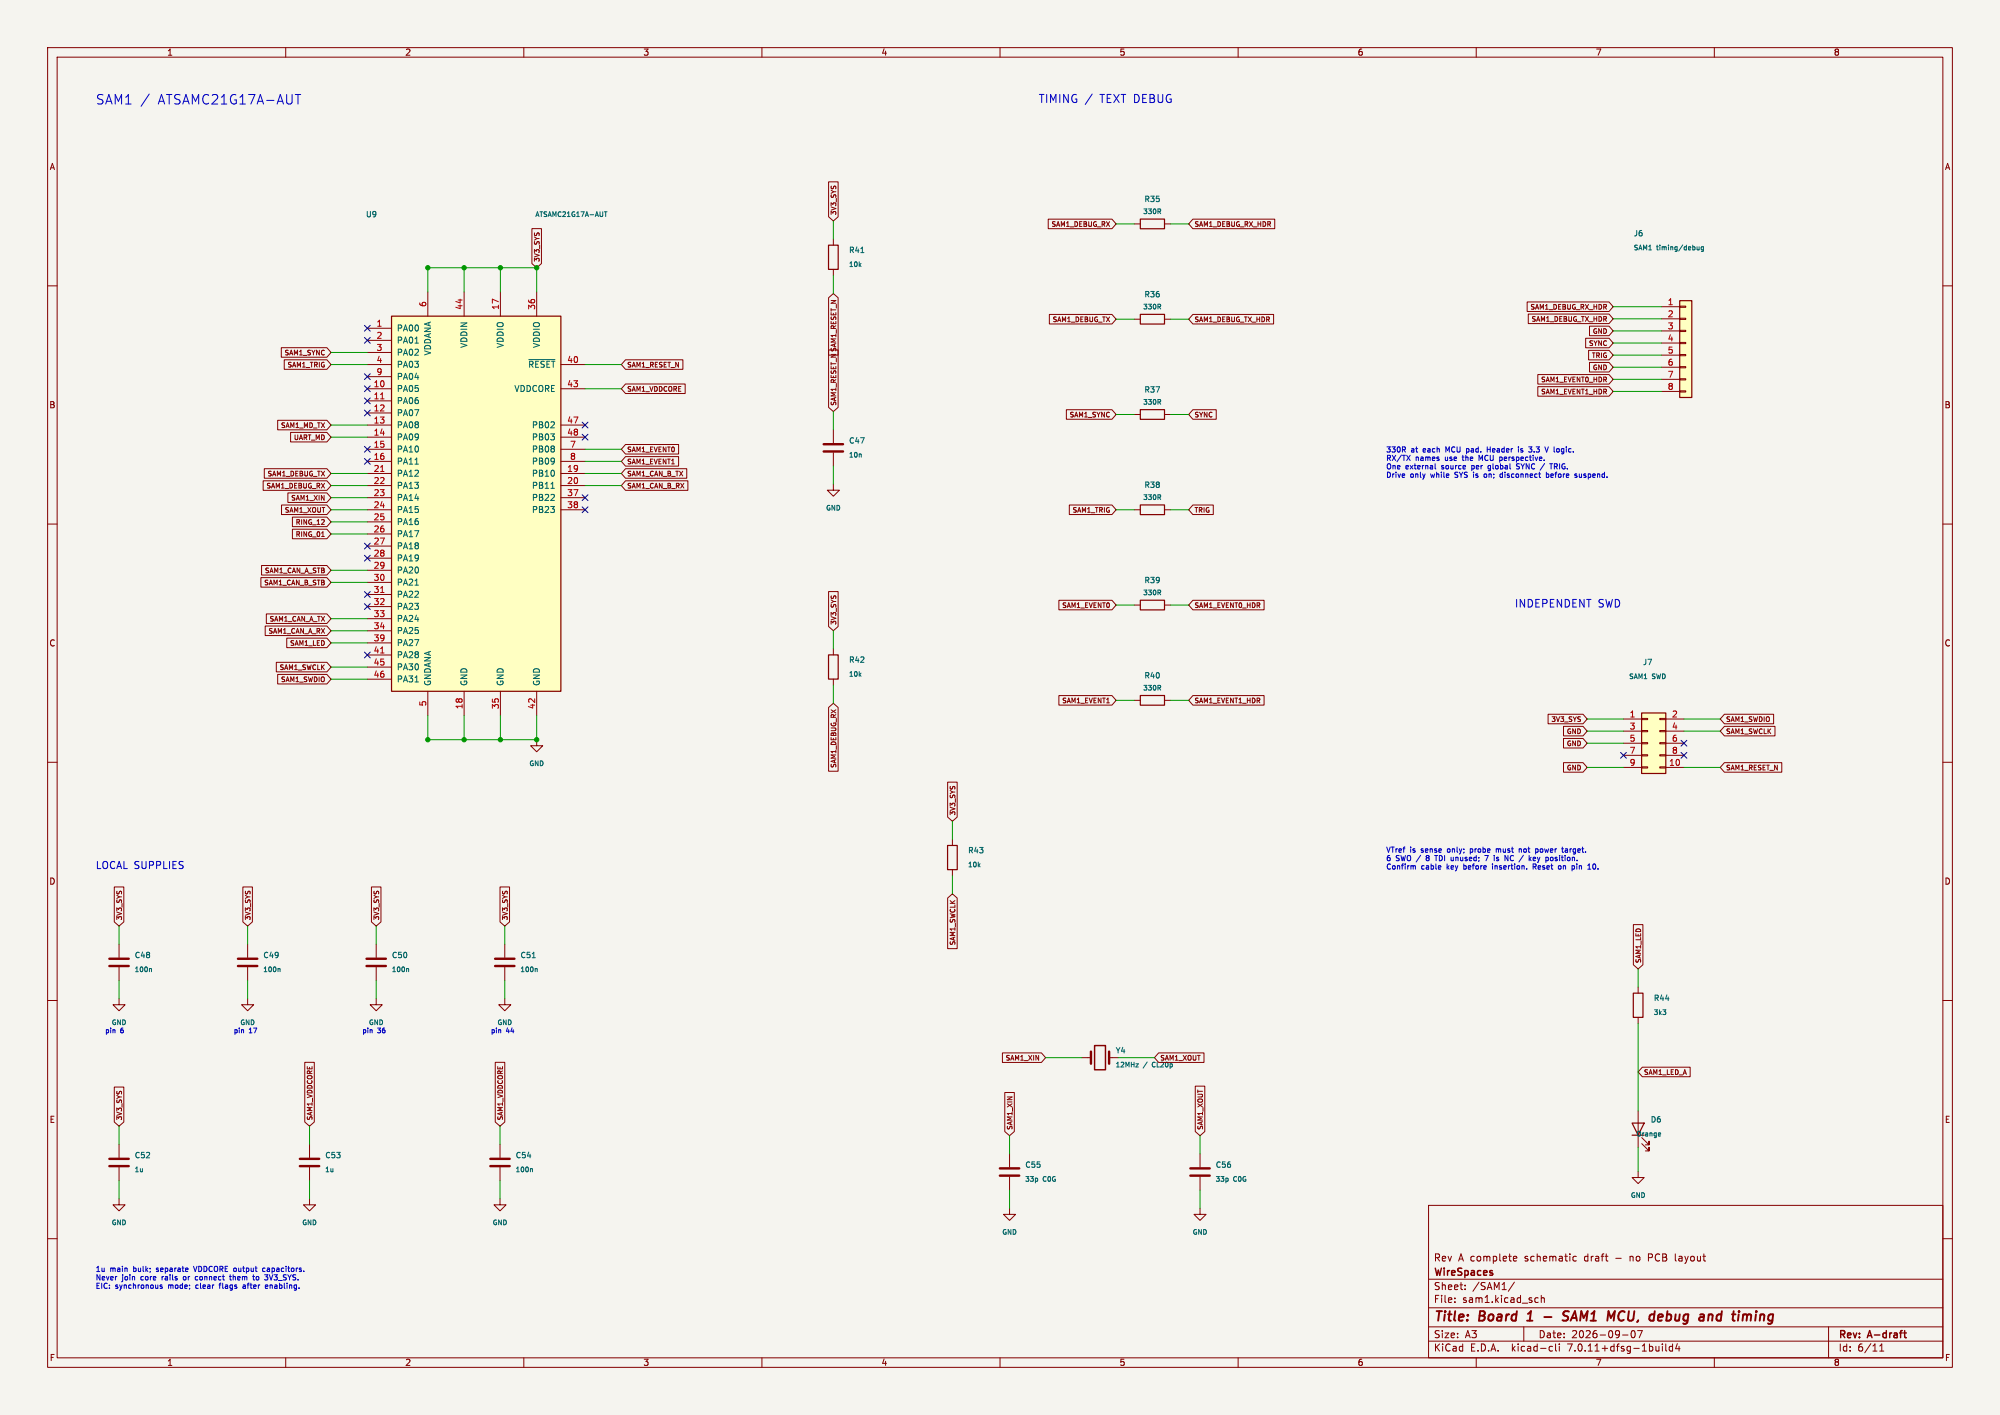
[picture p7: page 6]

Id: 6/11 Title: Board 1 - SAM1 MCU, debug and timing

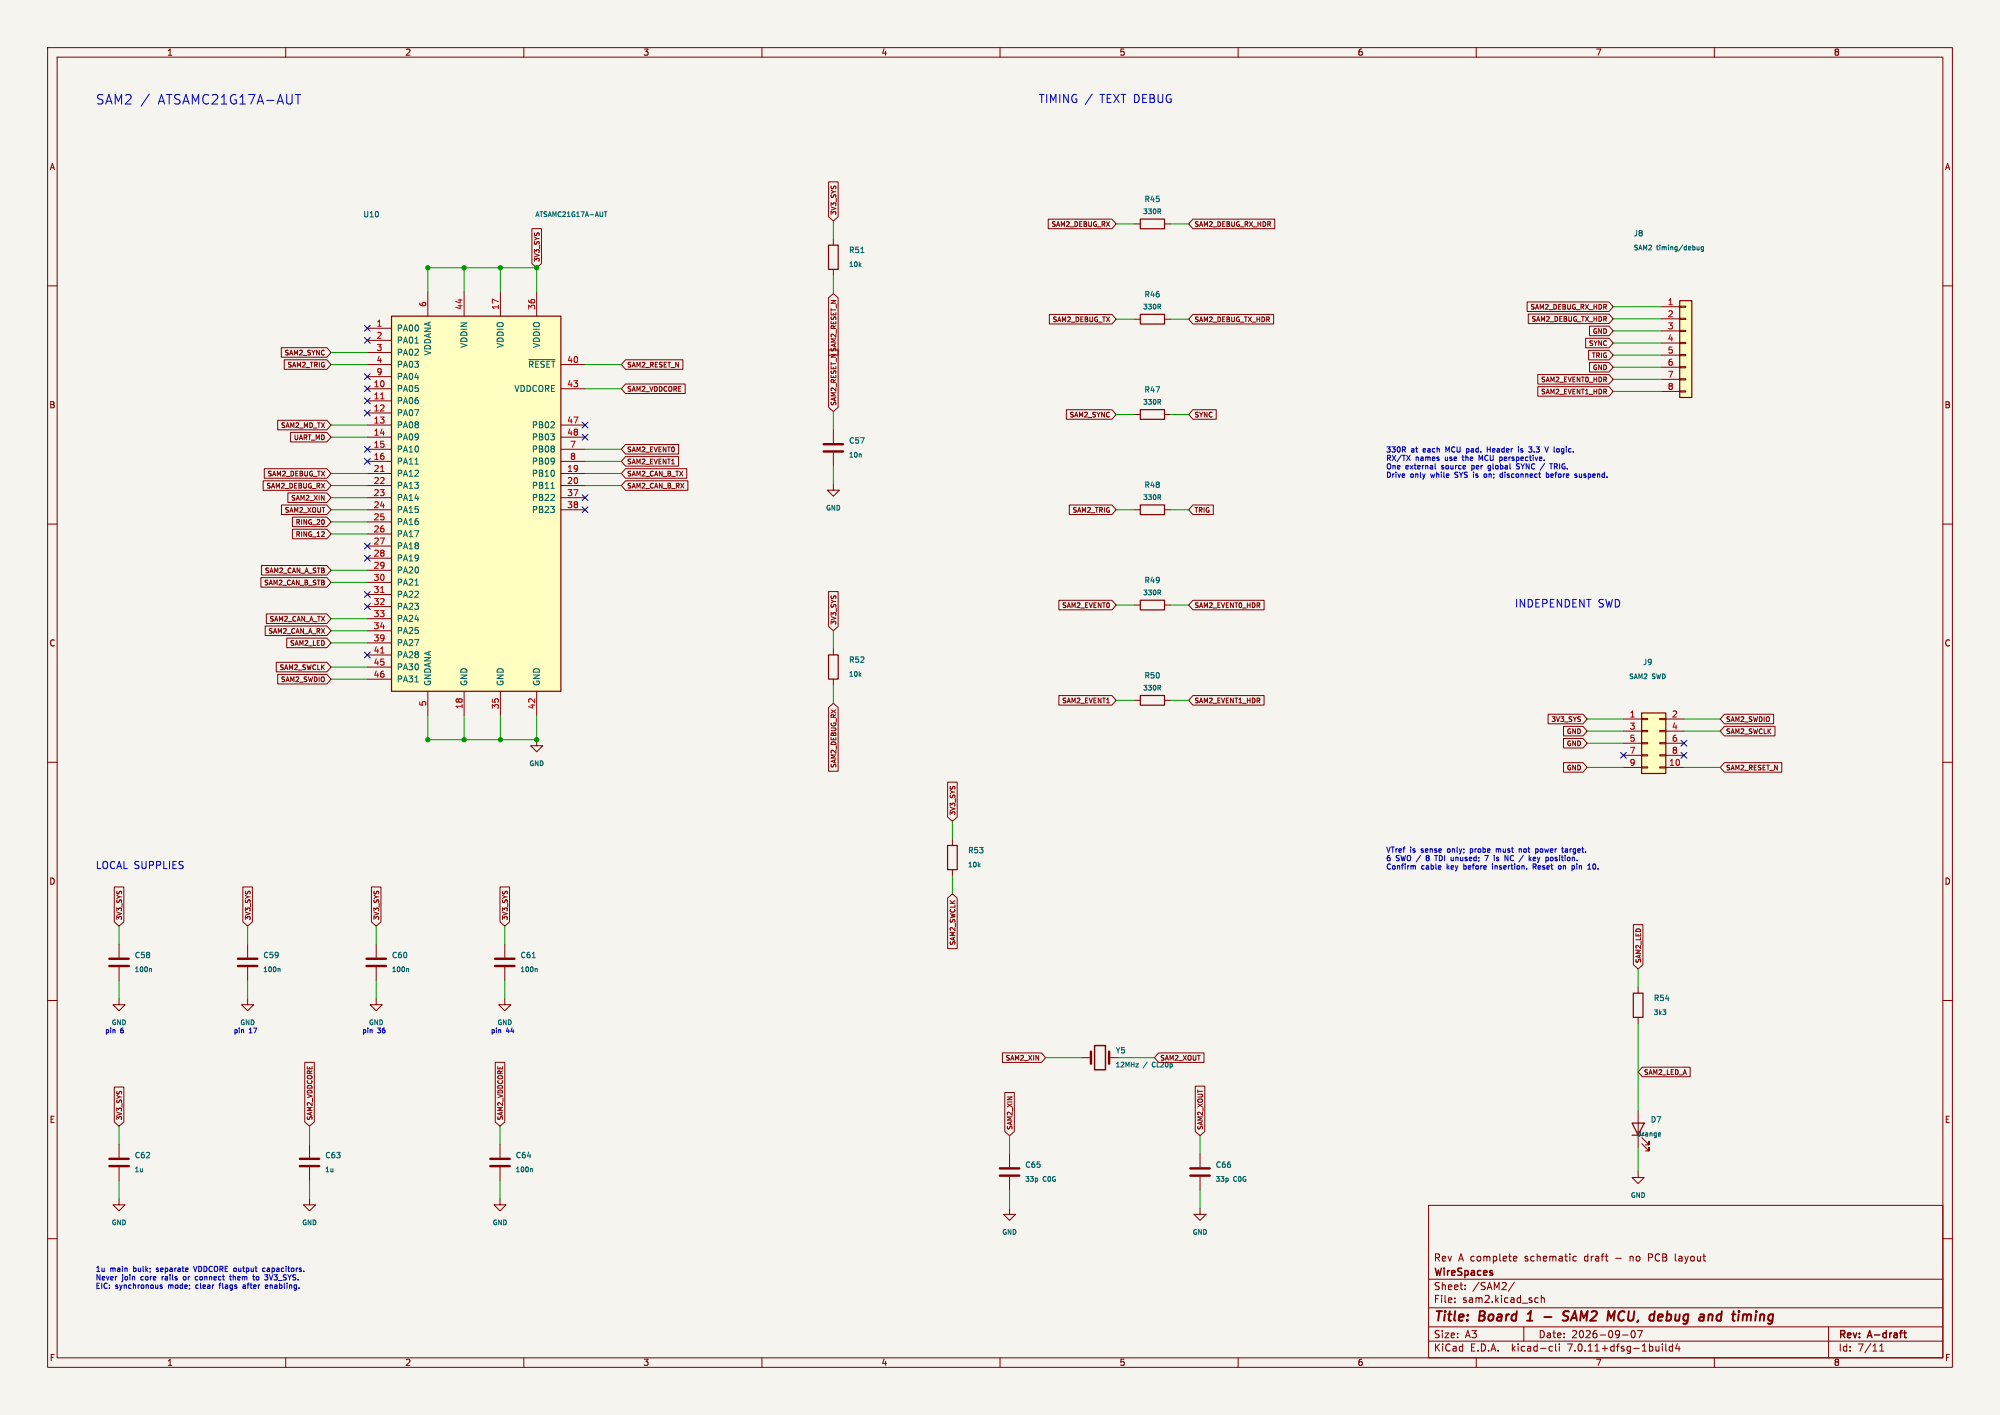
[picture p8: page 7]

Id: 7/11 Title: Board 1 - SAM2 MCU, debug and timing

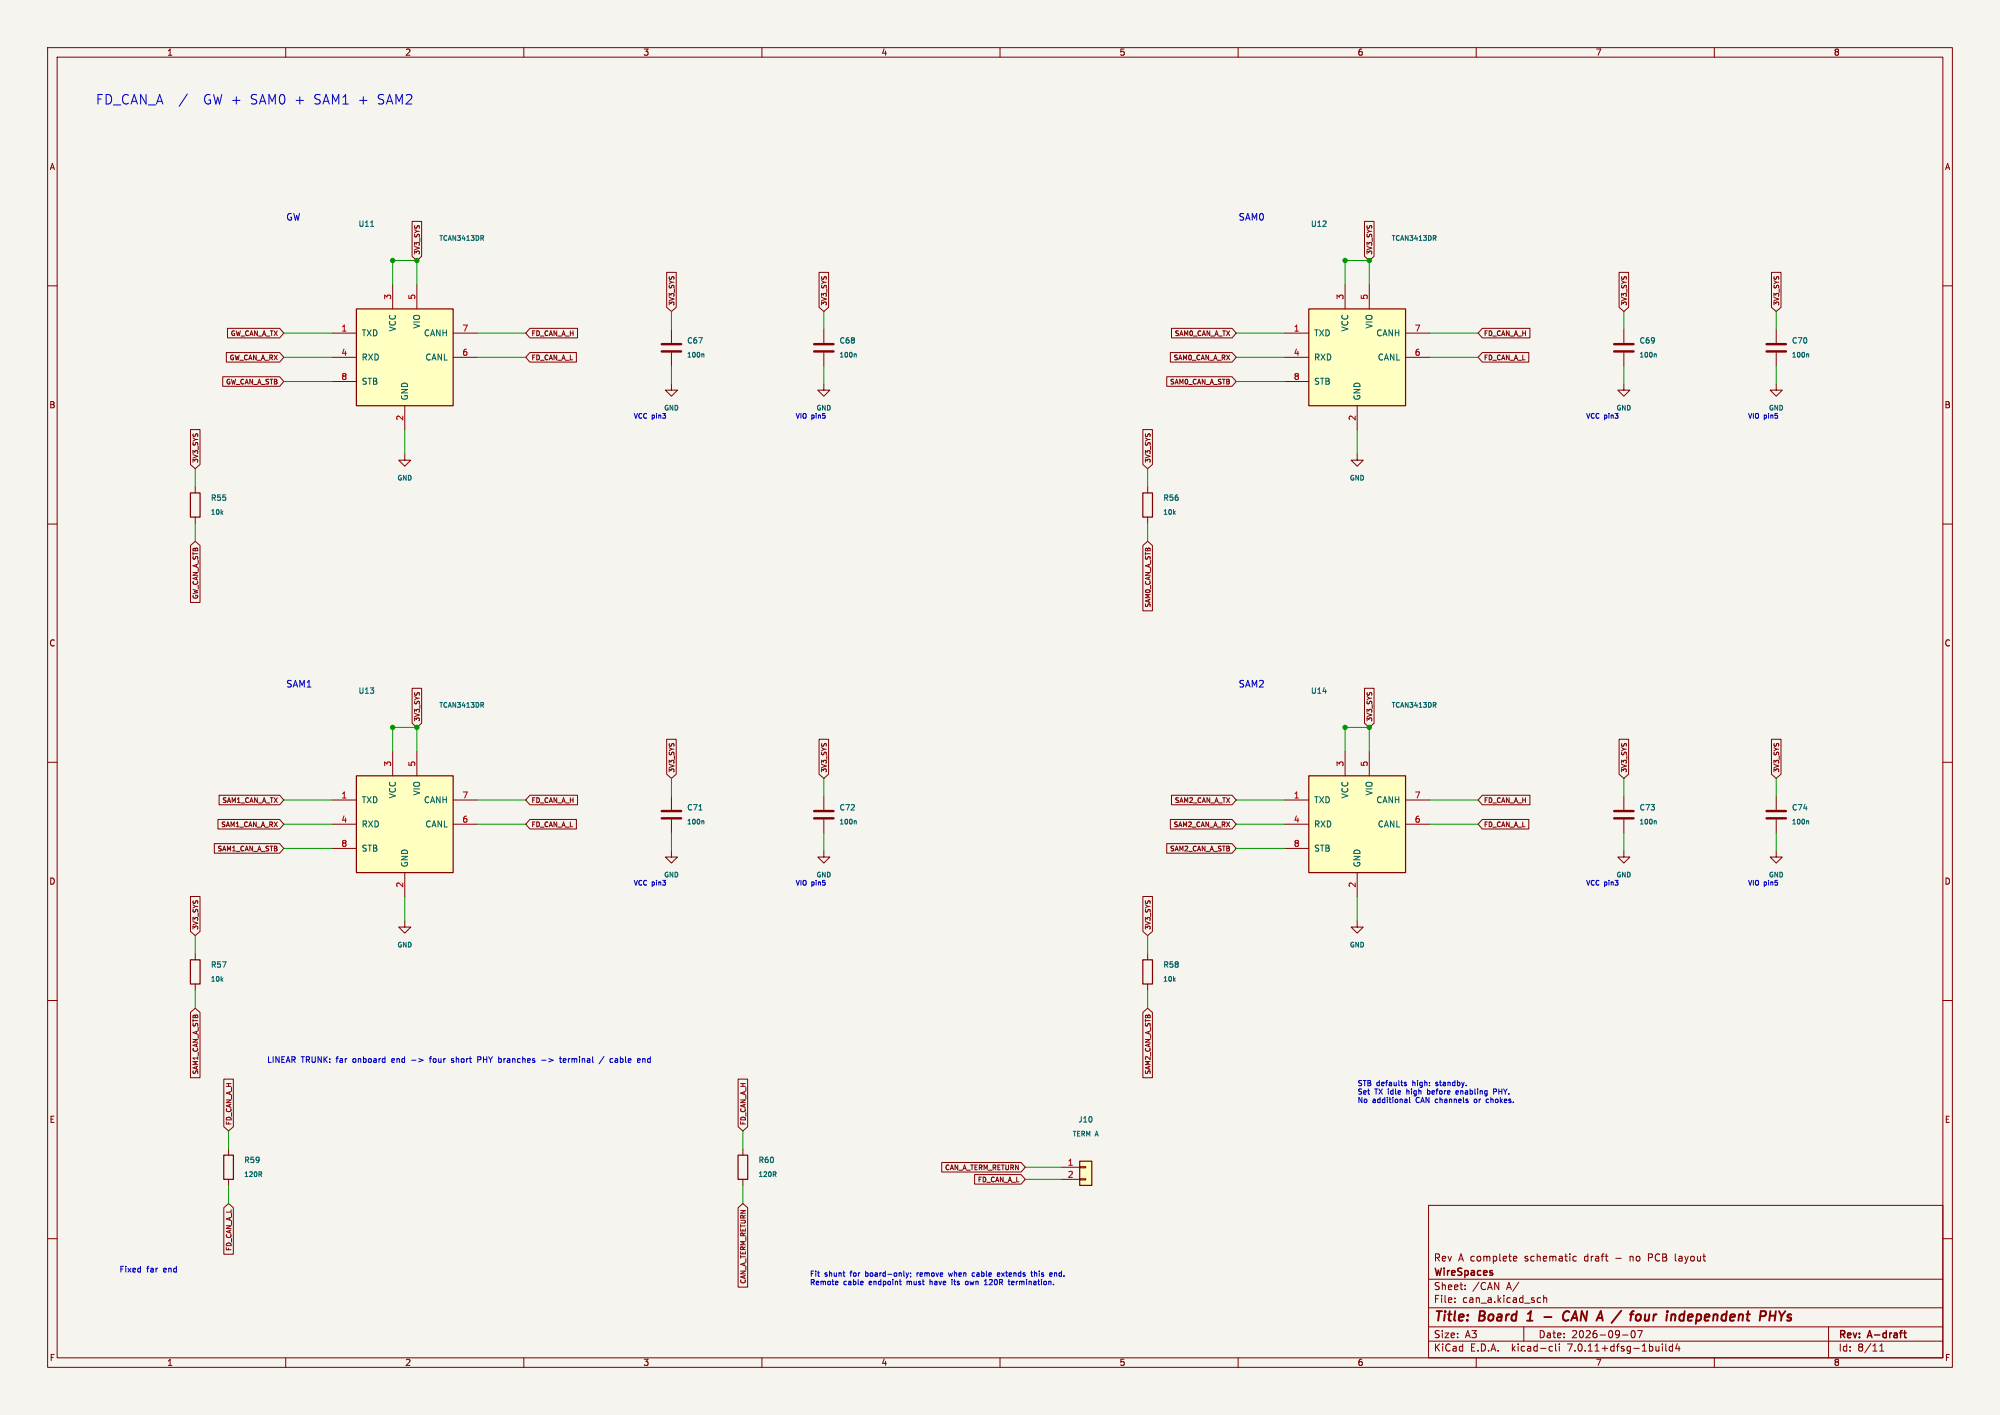
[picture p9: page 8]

Id: 8/11 Title: Board 1 - CAN A / four independent PHYs

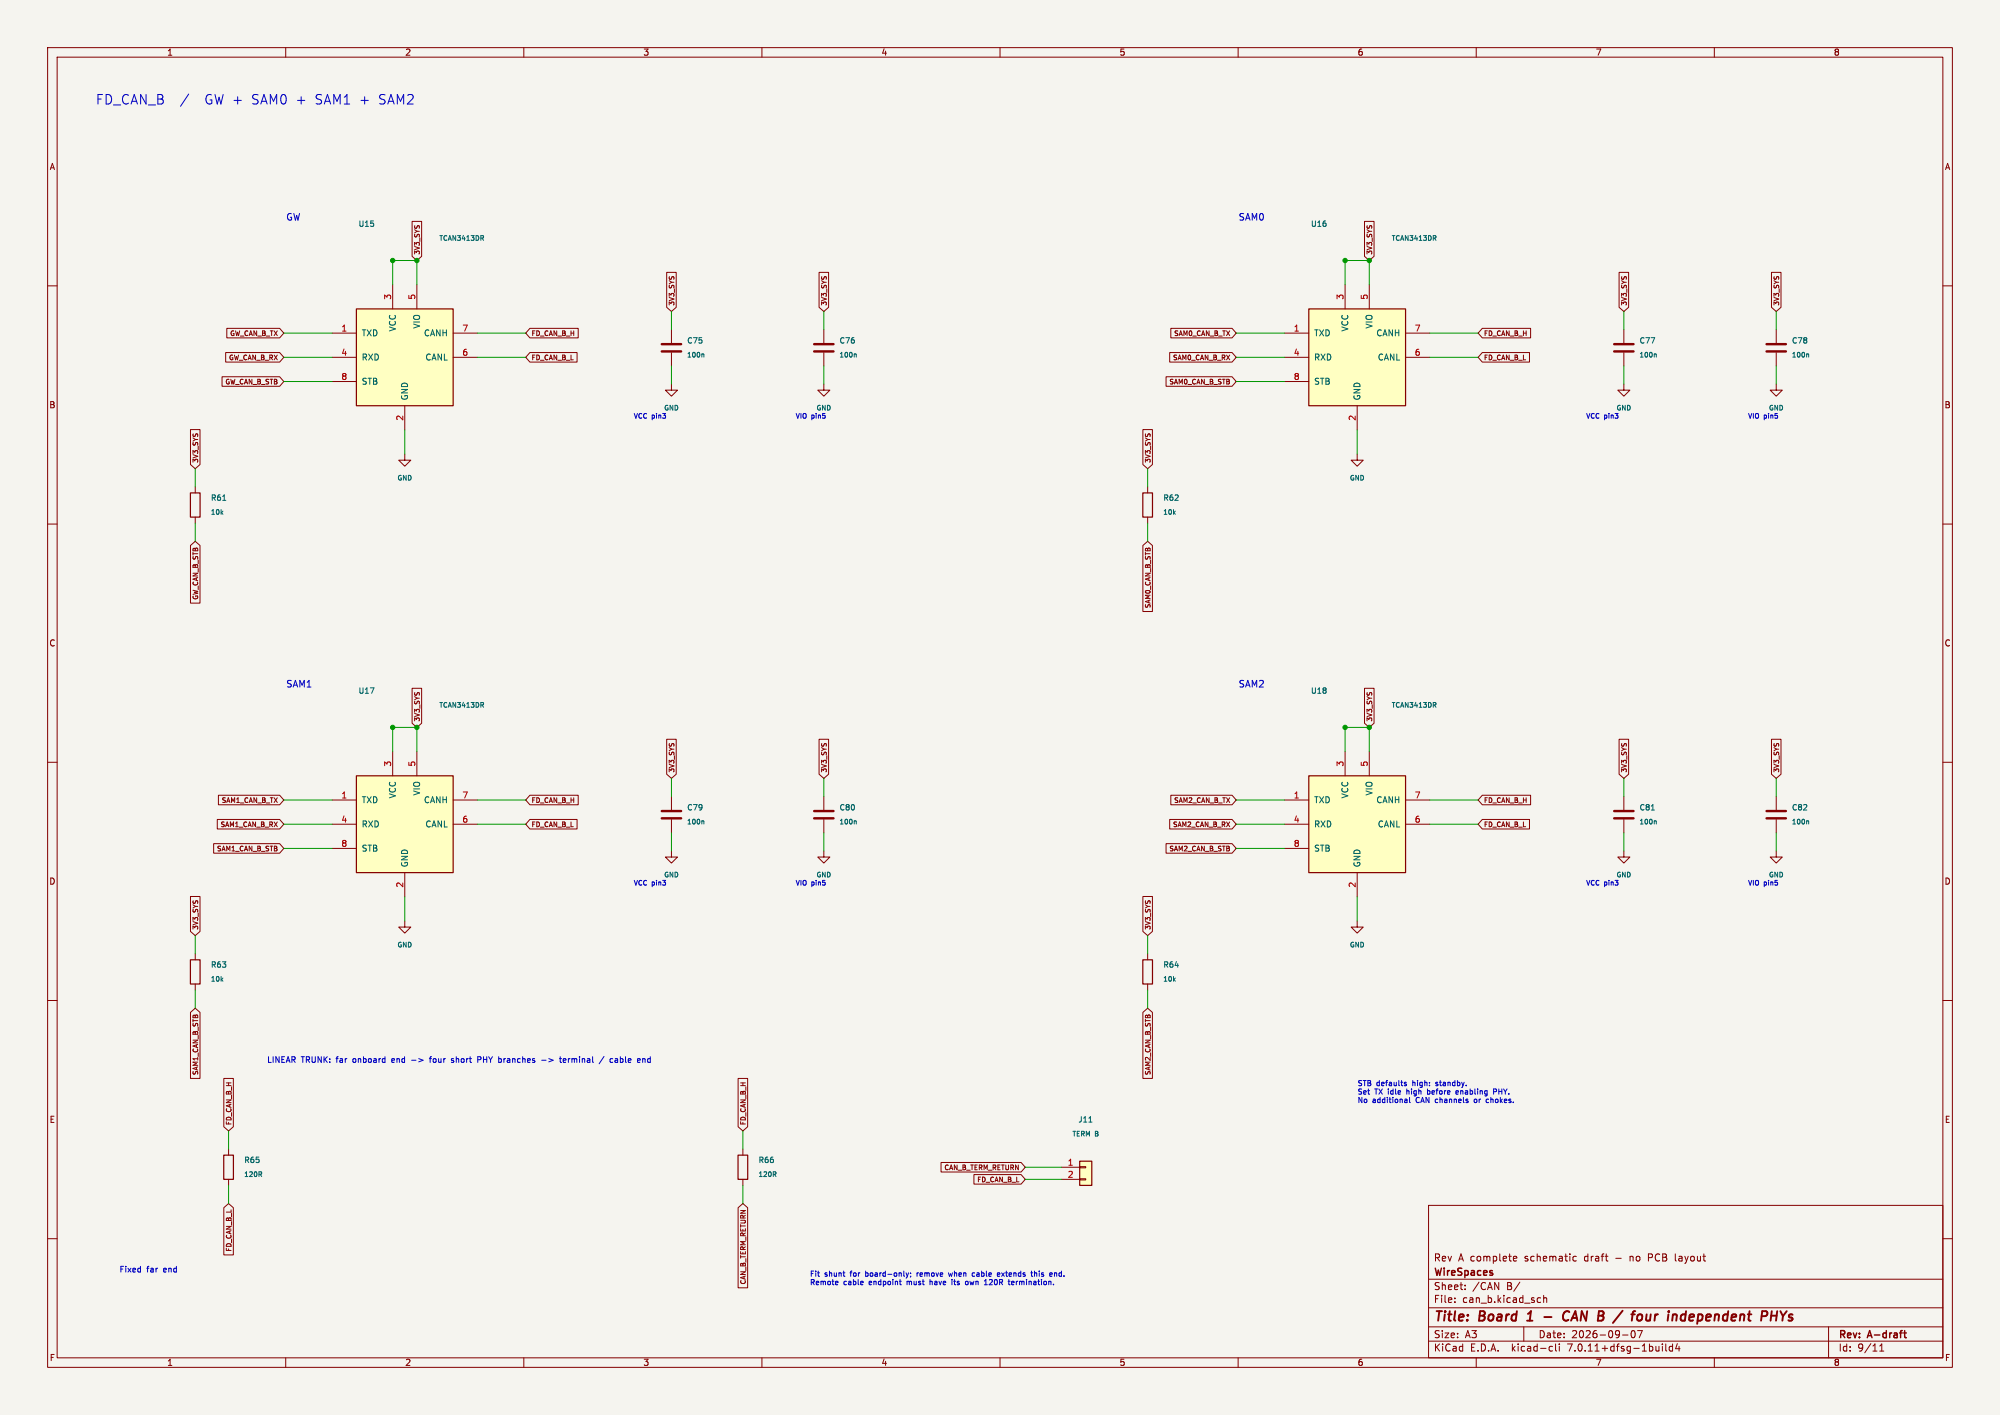
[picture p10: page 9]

Id: 9/11 Title: Board 1 - CAN B / four independent PHYs

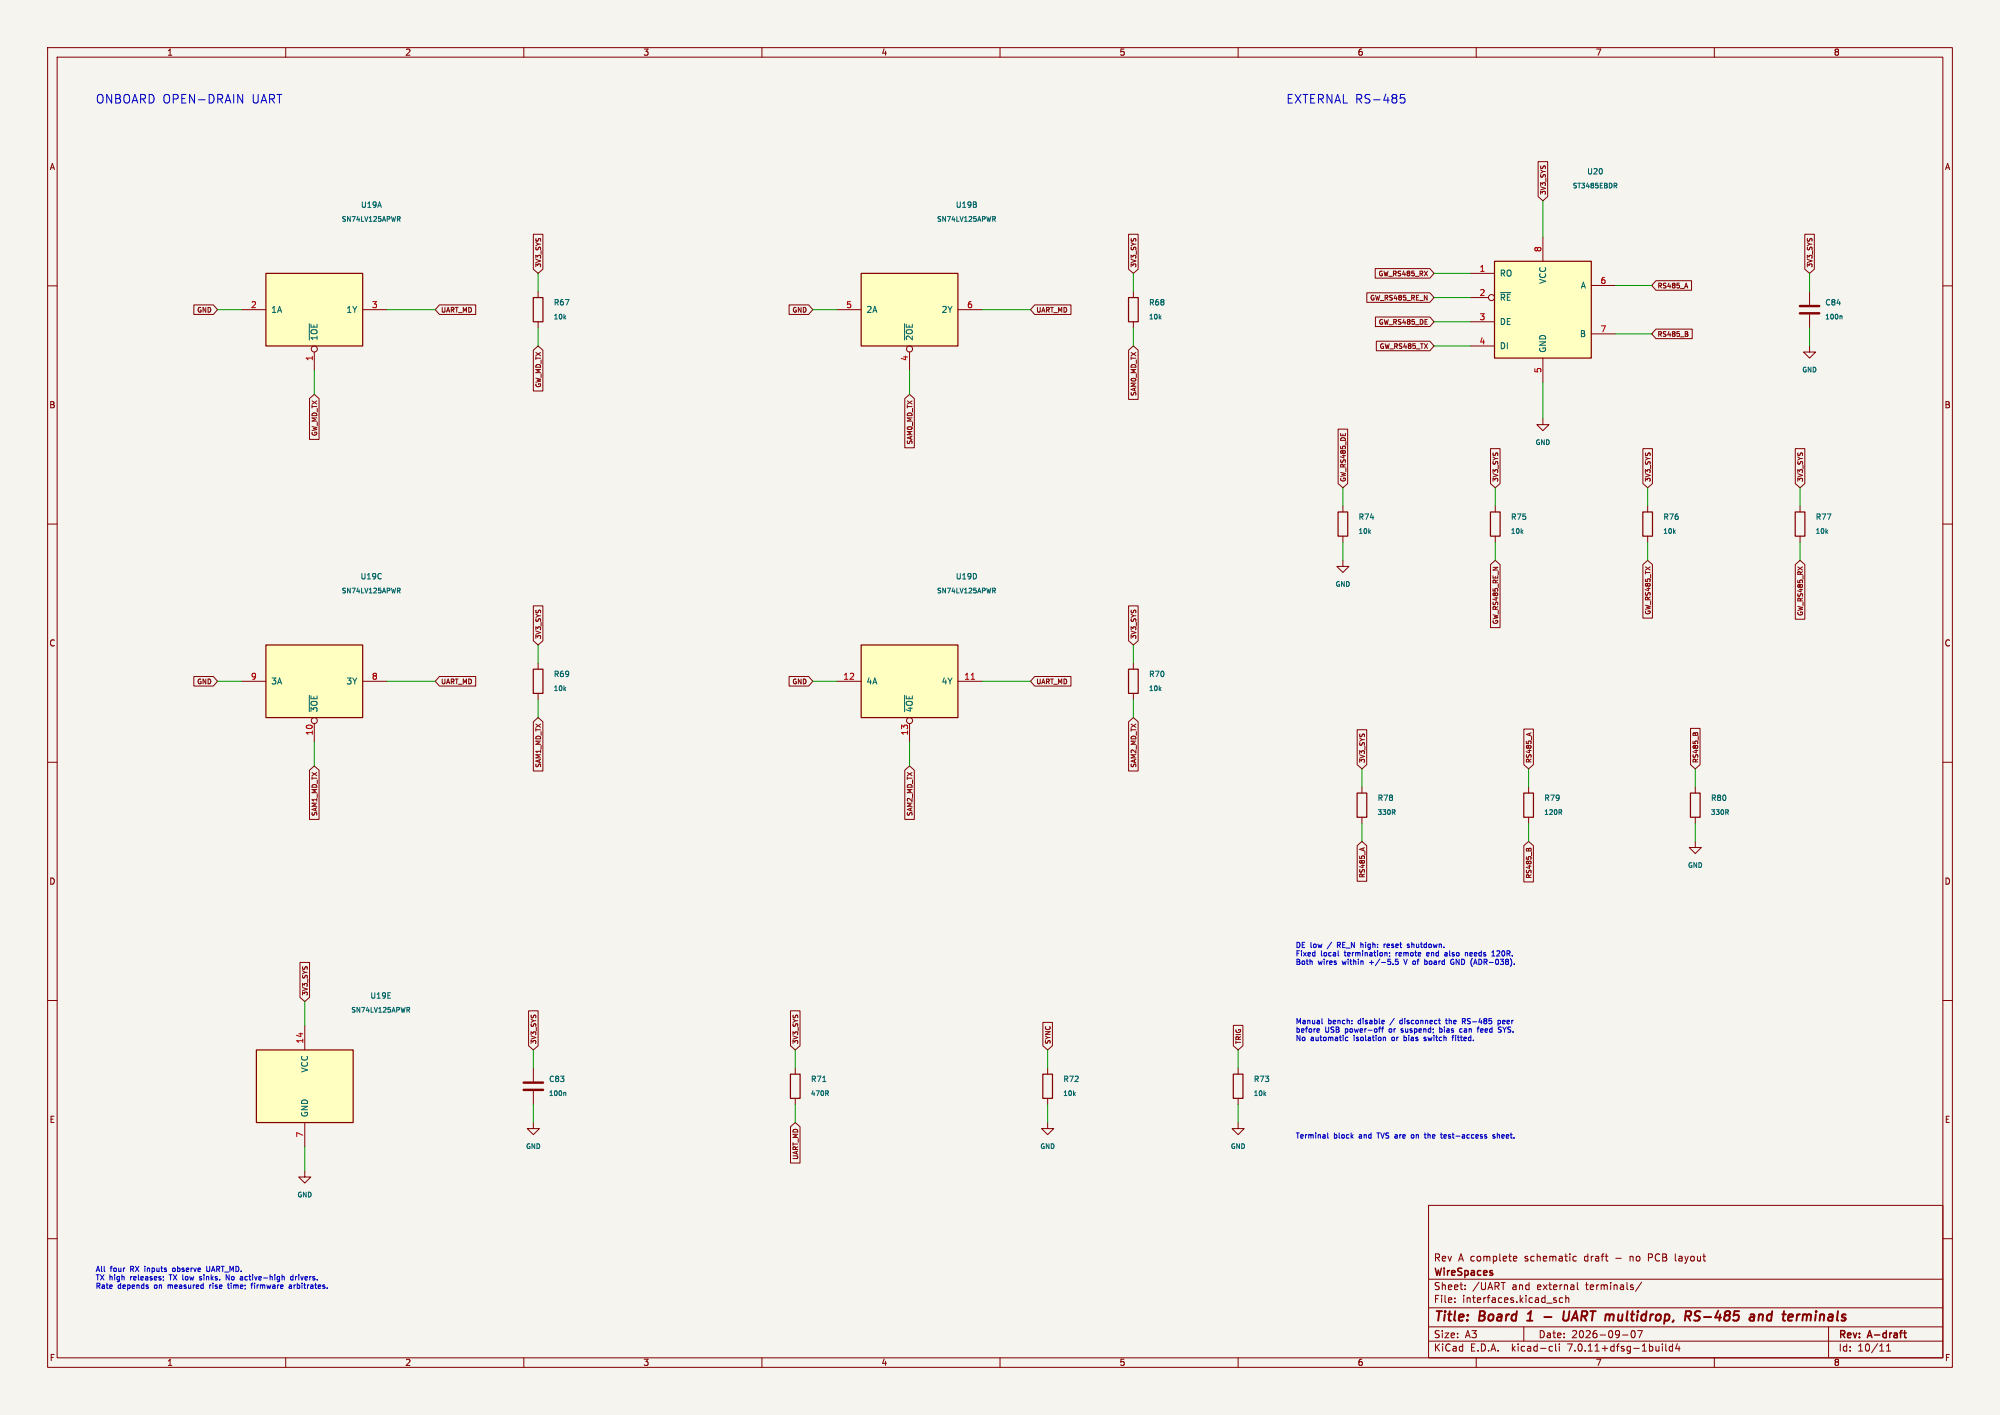
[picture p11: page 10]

ONBOARD OPEN-DRAIN UART

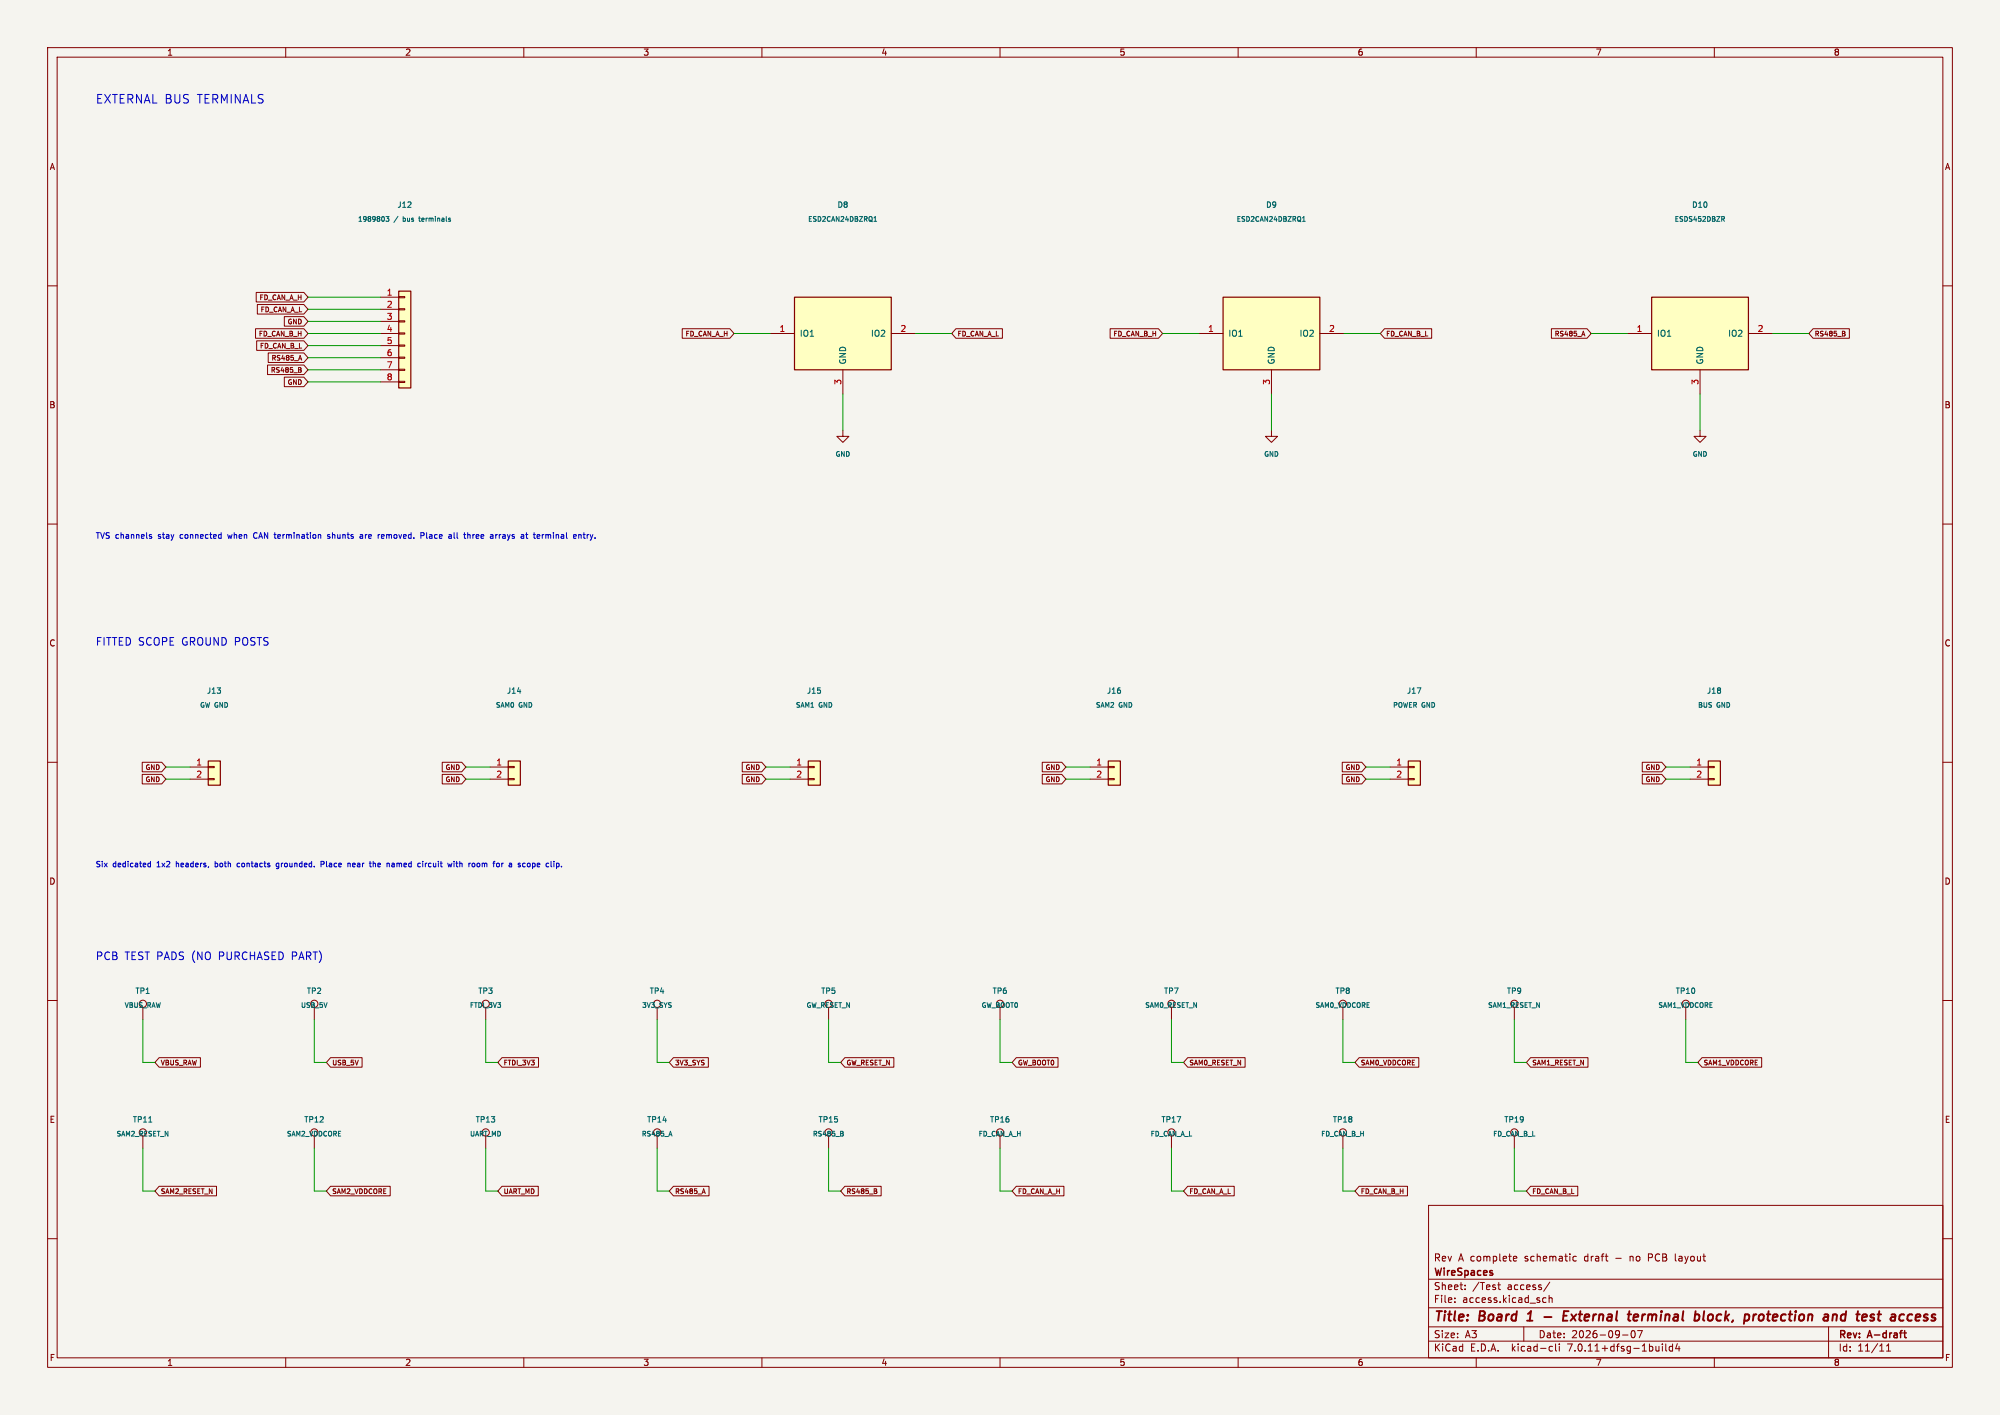
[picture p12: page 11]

FITTED SCOPE GROUND POSTS

RS485_B PCB TEST PADS (NO PURCHASED PART)

Id: 11/11 Title: Board 1 - External terminal block, protection and test access

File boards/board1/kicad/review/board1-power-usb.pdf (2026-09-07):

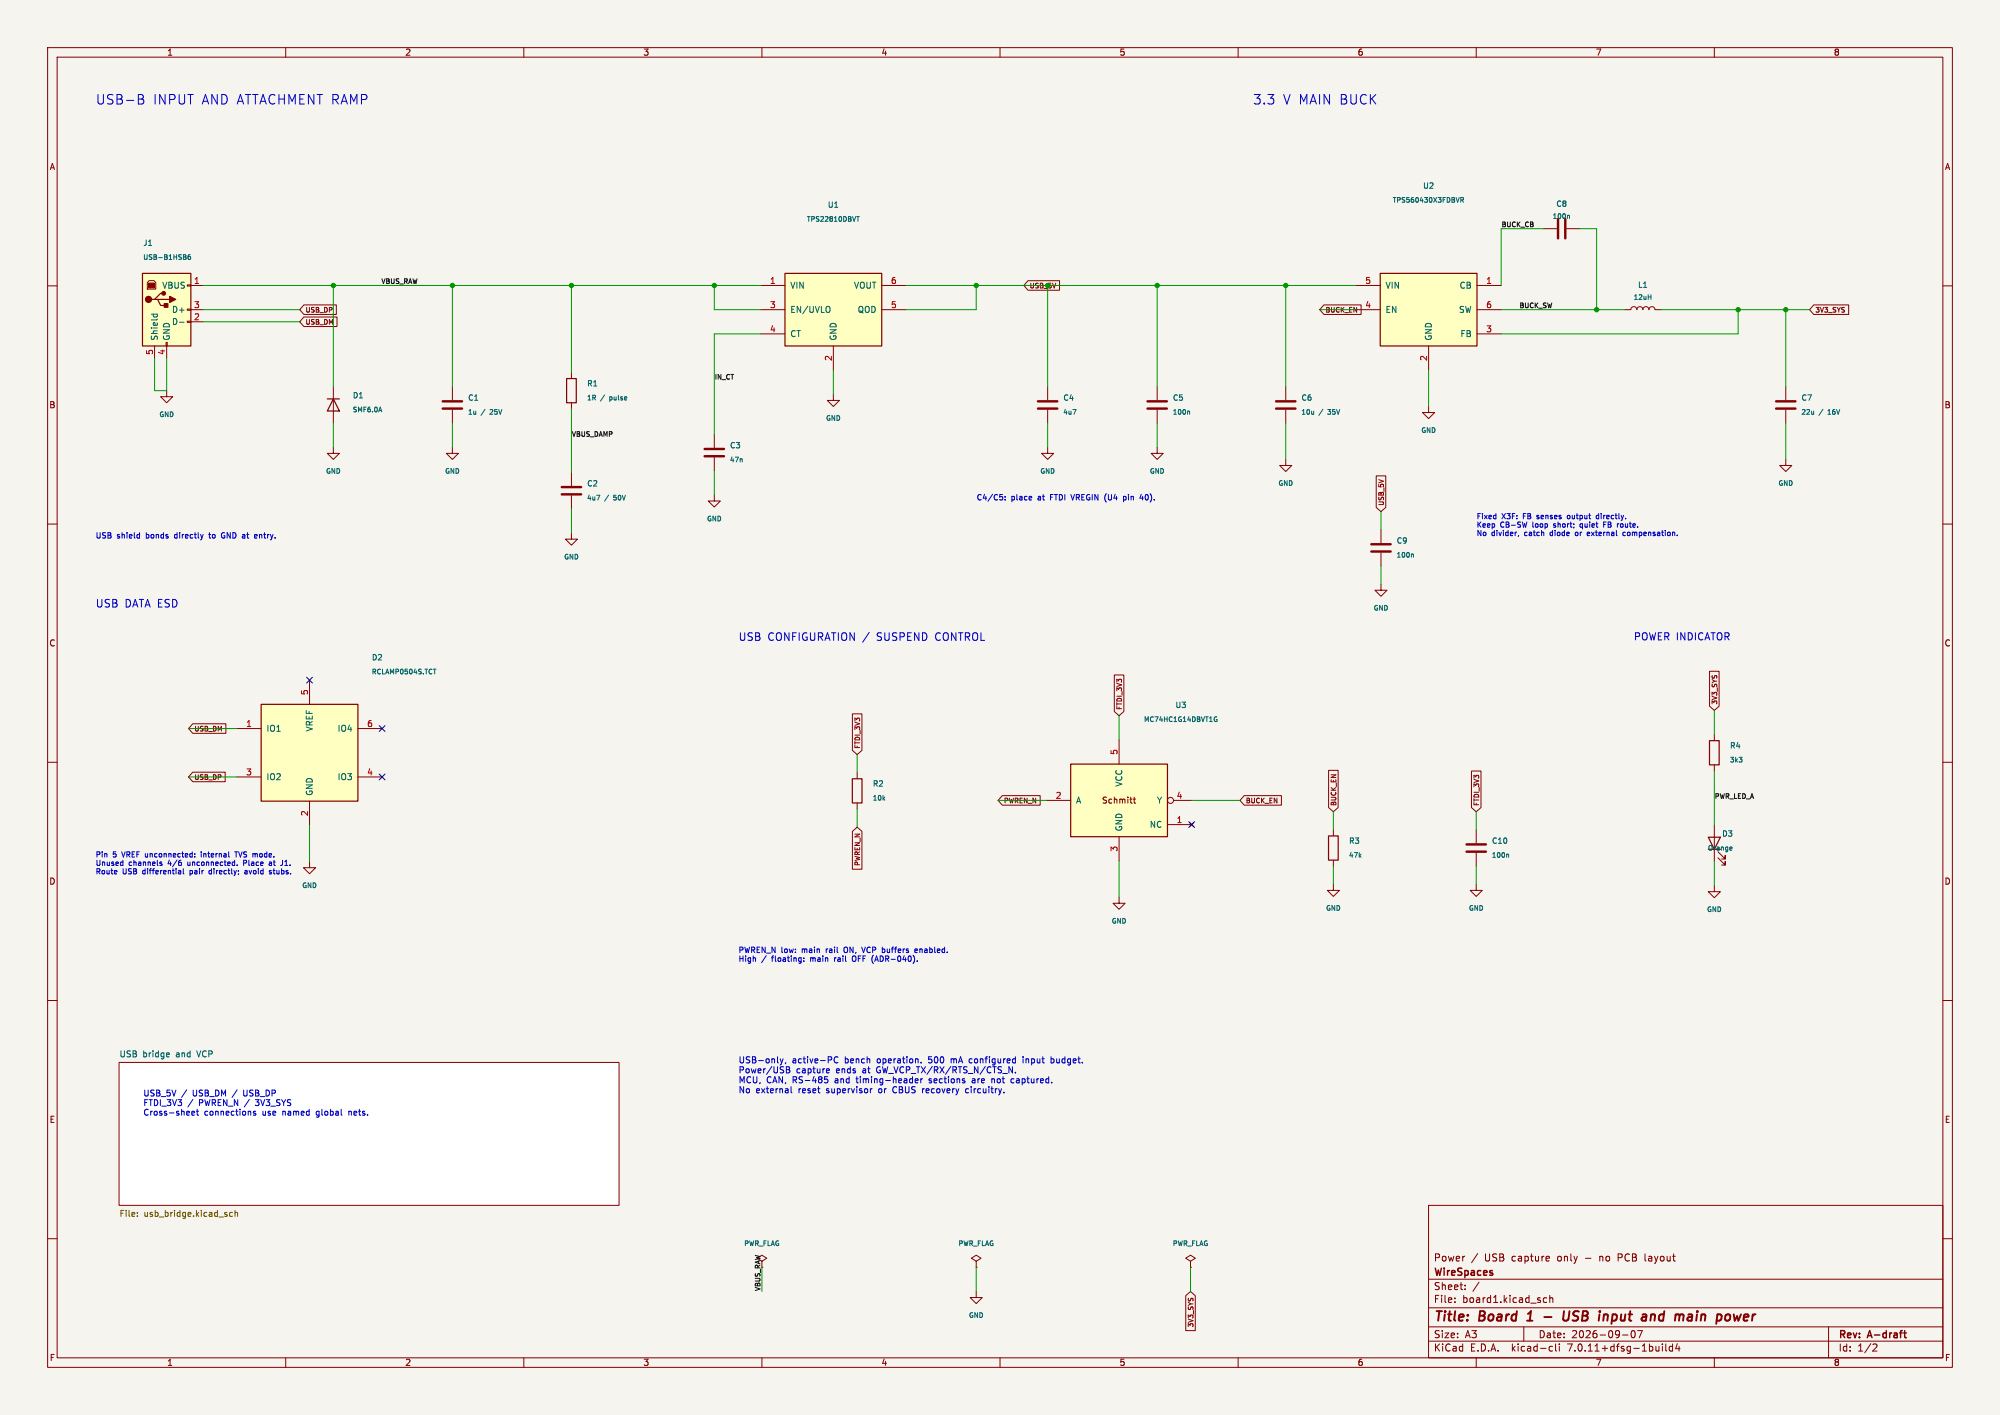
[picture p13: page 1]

USB-B INPUT AND ATTACHMENT RAMP

2 FB 3 EN 4 VIN 5 SW 6 U2

2 EN/UVLO 3 CT 4 QOD 5 VOUT 6 U1
TPS22810DBVT GND


VCP POWER-OFF ISOLATION

4 VREGIN 40 AGND 41 TEST 42 EEDATA 43 EECLK 44 EECS 45 VCCIO 46 GND 47 GND 48 REF 5 DM 6 DP 7 VPLL

3 ACBUS6 30 ACBUS7 31 ACBUS8 32 ACBUS9 33 ~{RESET} 34 GND 35 GND 36 VCCA 37 VCCCORE 38 VCCD 39 AGND

U5 pin 8 FTDI LOCAL SUPPLY DECOUPLING

Id: 2/2 Title: Board 1 - FT232HL, EEPROM and isolated VCP

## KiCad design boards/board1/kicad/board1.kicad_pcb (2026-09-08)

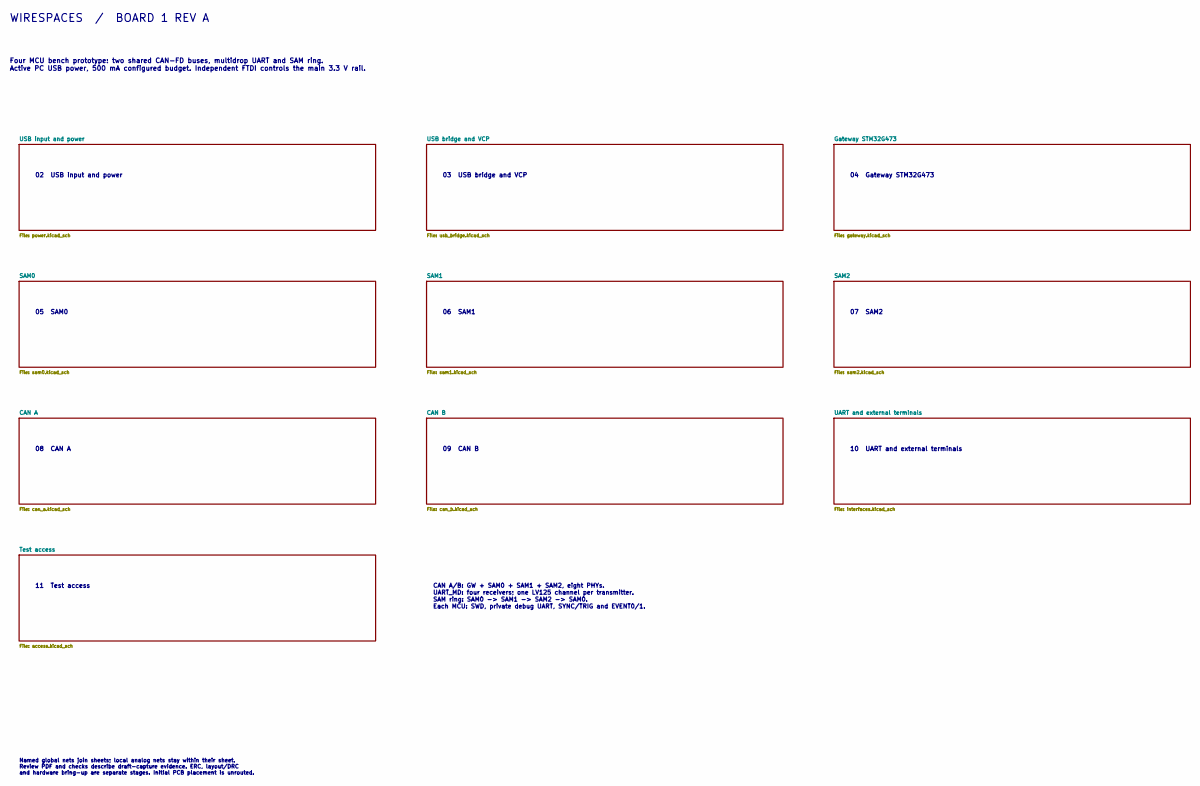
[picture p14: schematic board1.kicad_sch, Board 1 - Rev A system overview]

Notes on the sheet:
WIRESPACES / BOARD 1 REV A
Four MCU bench prototype: two shared CAN-FD buses, multidrop UART and SAM ring. Active PC USB power, 500 mA configured budget. Independent FTDI controls the main 3.3 V rail.
02 USB input and power
03 USB bridge and VCP
04 Gateway STM32G473
05 SAM0
06 SAM1
07 SAM2
08 CAN A
09 CAN B
10 UART and external terminals
11 Test access
CAN A/B: GW + SAM0 + SAM1 + SAM2, eight PHYs. UART_MD: four receivers; one LV125 channel per transmitter. SAM ring: SAM0 -> SAM1 -> SAM2 -> SAM0. Each MCU: SWD, private debug UART, SYNC/TRIG and EVENT0/1.
Named global nets join sheets; local analog nets stay within their sheet. Review PDF and checks describe draft-capture evidence. ERC, layout/DRC and hardware bring-up are separate stages. Initial PCB placement is unrouted.

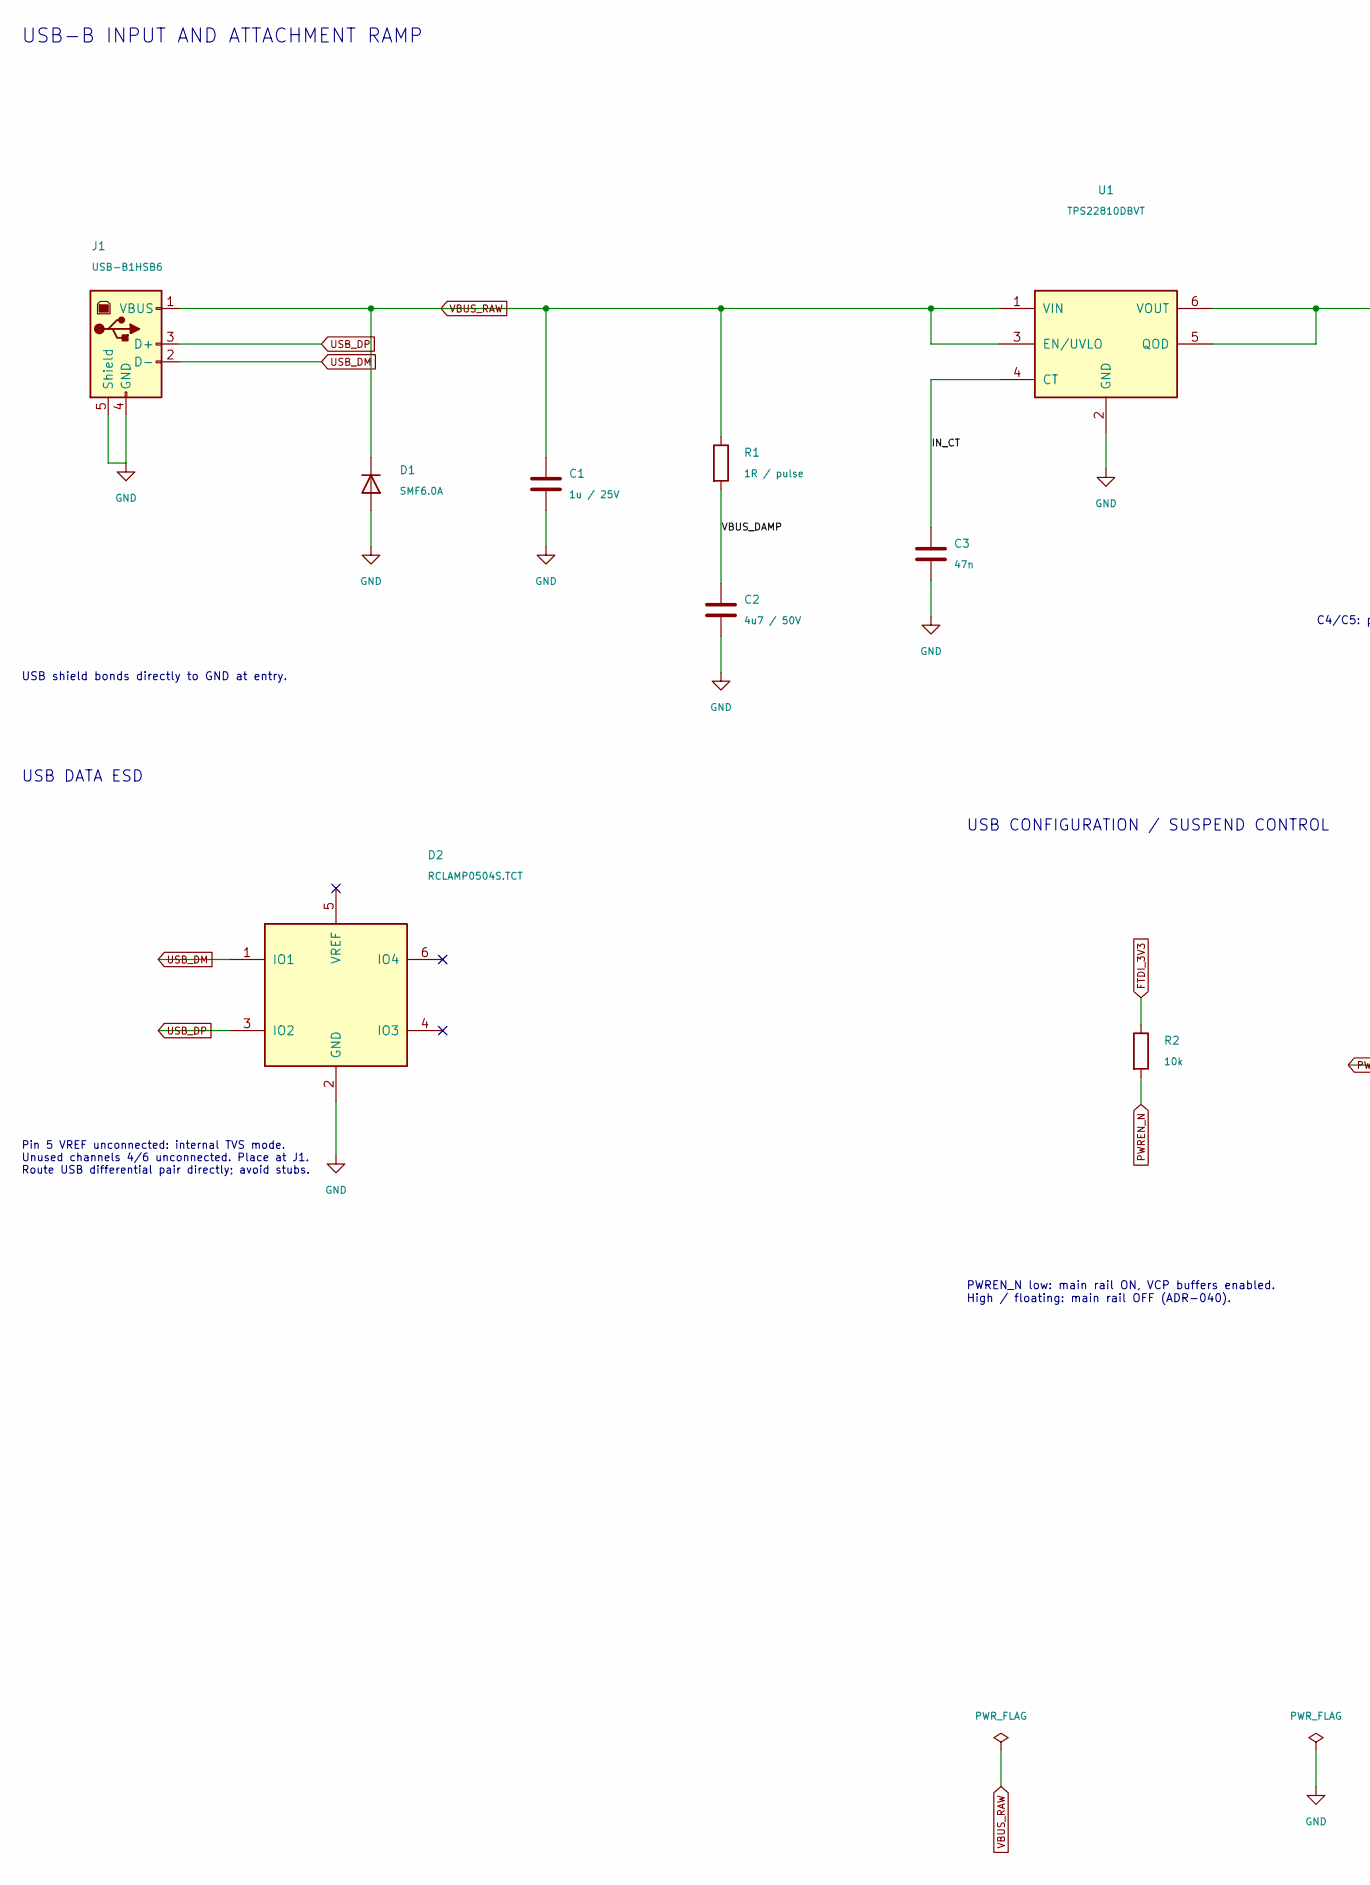
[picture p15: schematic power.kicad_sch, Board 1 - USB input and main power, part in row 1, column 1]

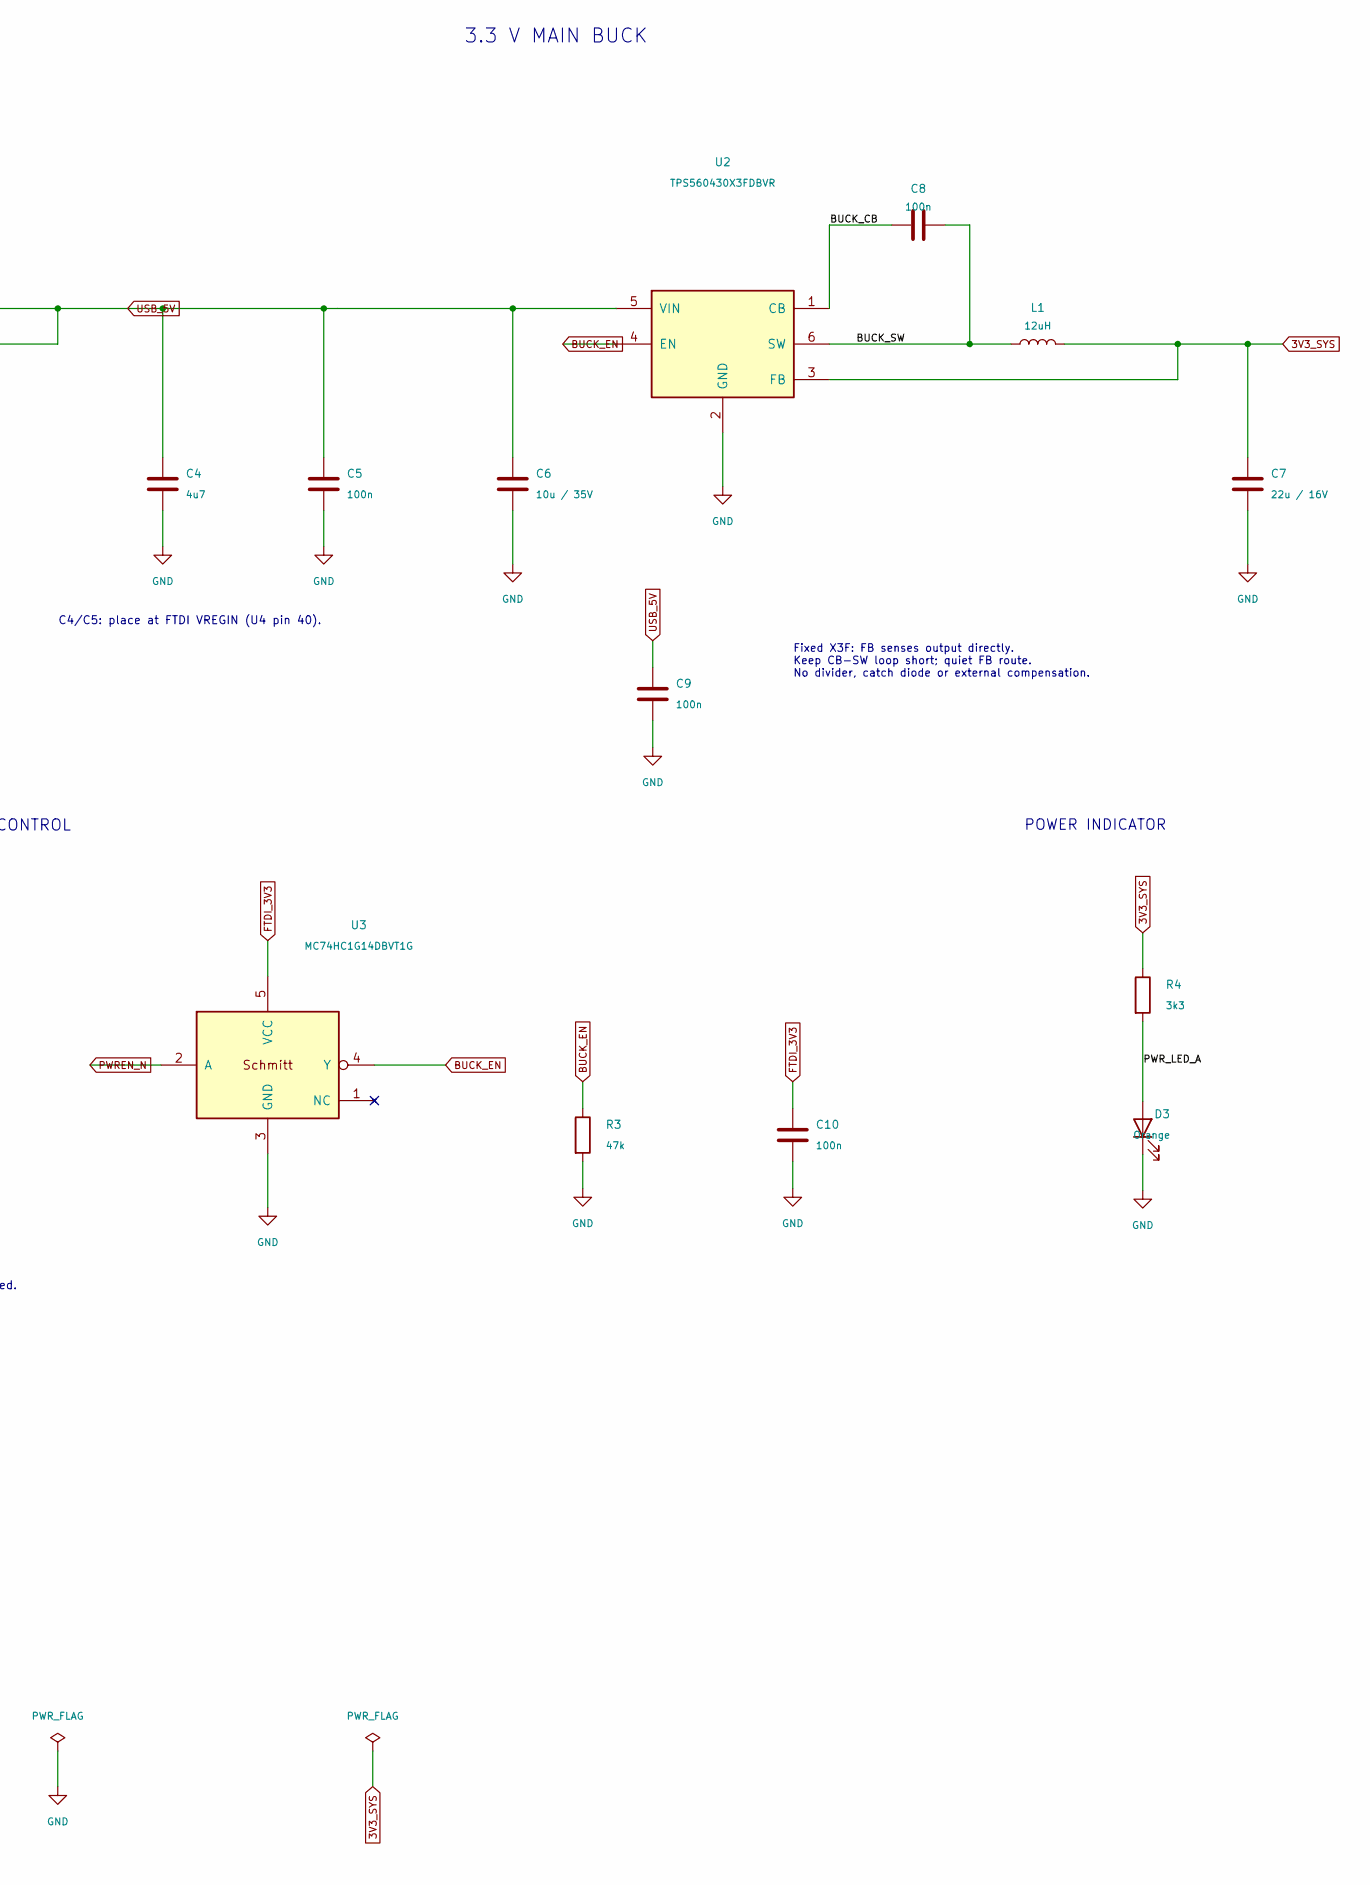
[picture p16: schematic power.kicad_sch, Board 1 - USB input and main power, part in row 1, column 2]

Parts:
C1: 1u / 25V; C_0805_2012Metric; MPN CL21B105KAFNFNE
C2: 4u7 / 50V; C_0805_2012Metric; MPN CL21A475KBQNNNE
C3: 47n; C_0805_2012Metric; MPN CL21B473KBCNNNC
C4: 4u7; C_0805_2012Metric; MPN GRM21BR71C475KE51L
C5, C10: 100n; C_0805_2012Metric; MPN KGM21NR71E104KT
C6: 10u / 35V; C_1206_3216Metric; MPN C3216X7R1V106K160AC
C7: 22u / 16V; C_1210_3225Metric; MPN C3225X7R1C226M250AC
C8, C9: 100n; C_0805_2012Metric; MPN C0805C104K5RACTU
D1: SMF6.0A; D_SOD-123F; MPN SMF6.0A
D2: RCLAMP0504S.TCT; SOT-23-6; MPN RCLAMP0504S.TCT
D3: Orange; LED_0603_1608Metric; MPN CSL1901DW1
J1: USB-B1HSB6; USB_B_OST_USB-B1HSxx_Horizontal; MPN USB-B1HSB6
L1: 12uH; L_Bourns_SRN6045TA; MPN SRN6045TA-120M
R1: 1R / pulse; R_1206_3216Metric; MPN SG73P2BTTD1R0J
R2: 10k; R_0805_2012Metric; MPN RMCF0805FT10K0
R3: 47k; R_0805_2012Metric; MPN ERJ-6GEYJ473V
R4: 3k3; R_0805_2012Metric; MPN RK73H2ATTD3301F
U1: TPS22810DBVT; SOT-23-6; MPN TPS22810DBVT
U2: TPS560430X3FDBVR; SOT-23-6; MPN TPS560430X3FDBVR
U3: MC74HC1G14DBVT1G; SOT-23-5; MPN MC74HC1G14DBVT1G

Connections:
3V3_SYS: C7.1, L1.2, R4.1, U2.3 (FB); also elsewhere on the board
/USB input and power/BUCK_CB: C8.1, U2.1 (CB)
/USB input and power/BUCK_SW: C8.2, L1.1, U2.6 (SW)
/USB input and power/IN_CT: C3.1, U1.4 (CT)
/USB input and power/PWR_LED_A: D3.2 (A), R4.2
/USB input and power/VBUS_DAMP: C2.1, R1.2
BUCK_EN: R3.1, U2.4 (EN), U3.4 (Y)
FTDI_3V3: C10.1, R2.1, U3.5 (VCC); also elsewhere on the board
GND: C1.2, C2.2, C3.2, C4.2, C5.2, C6.2, C7.2, C9.2, C10.2, D1.2 (A), D2.2 (GND), D3.1 (K), J1.4 (GND), J1.5 (Shield), R3.2, U1.2 (GND), U2.2 (GND), U3.3 (GND); also elsewhere on the board
PWREN_N: R2.2, U3.2 (A); also elsewhere on the board
USB_5V: C4.1, C5.1, C6.1, C9.1, U1.5 (QOD), U1.6 (VOUT), U2.5 (VIN); also elsewhere on the board
USB_DM: D2.1 (IO1), J1.2 (D-); also elsewhere on the board
USB_DP: D2.3 (IO2), J1.3 (D+); also elsewhere on the board
VBUS_RAW: C1.1, D1.1 (K), J1.1 (VBUS), R1.1, U1.1 (VIN), U1.3 (EN/UVLO); also elsewhere on the board

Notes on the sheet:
USB-B INPUT AND ATTACHMENT RAMP
3.3 V MAIN BUCK
C4/C5: place at FTDI VREGIN (U4 pin 40).
USB shield bonds directly to GND at entry.
USB DATA ESD
Pin 5 VREF unconnected: internal TVS mode. Unused channels 4/6 unconnected. Place at J1. Route USB differential pair directly; avoid stubs.
Fixed X3F: FB senses output directly. Keep CB-SW loop short; quiet FB route. No divider, catch diode or external compensation.
USB CONFIGURATION / SUSPEND CONTROL
PWREN_N low: main rail ON, VCP buffers enabled. High / floating: main rail OFF (ADR-040).
POWER INDICATOR

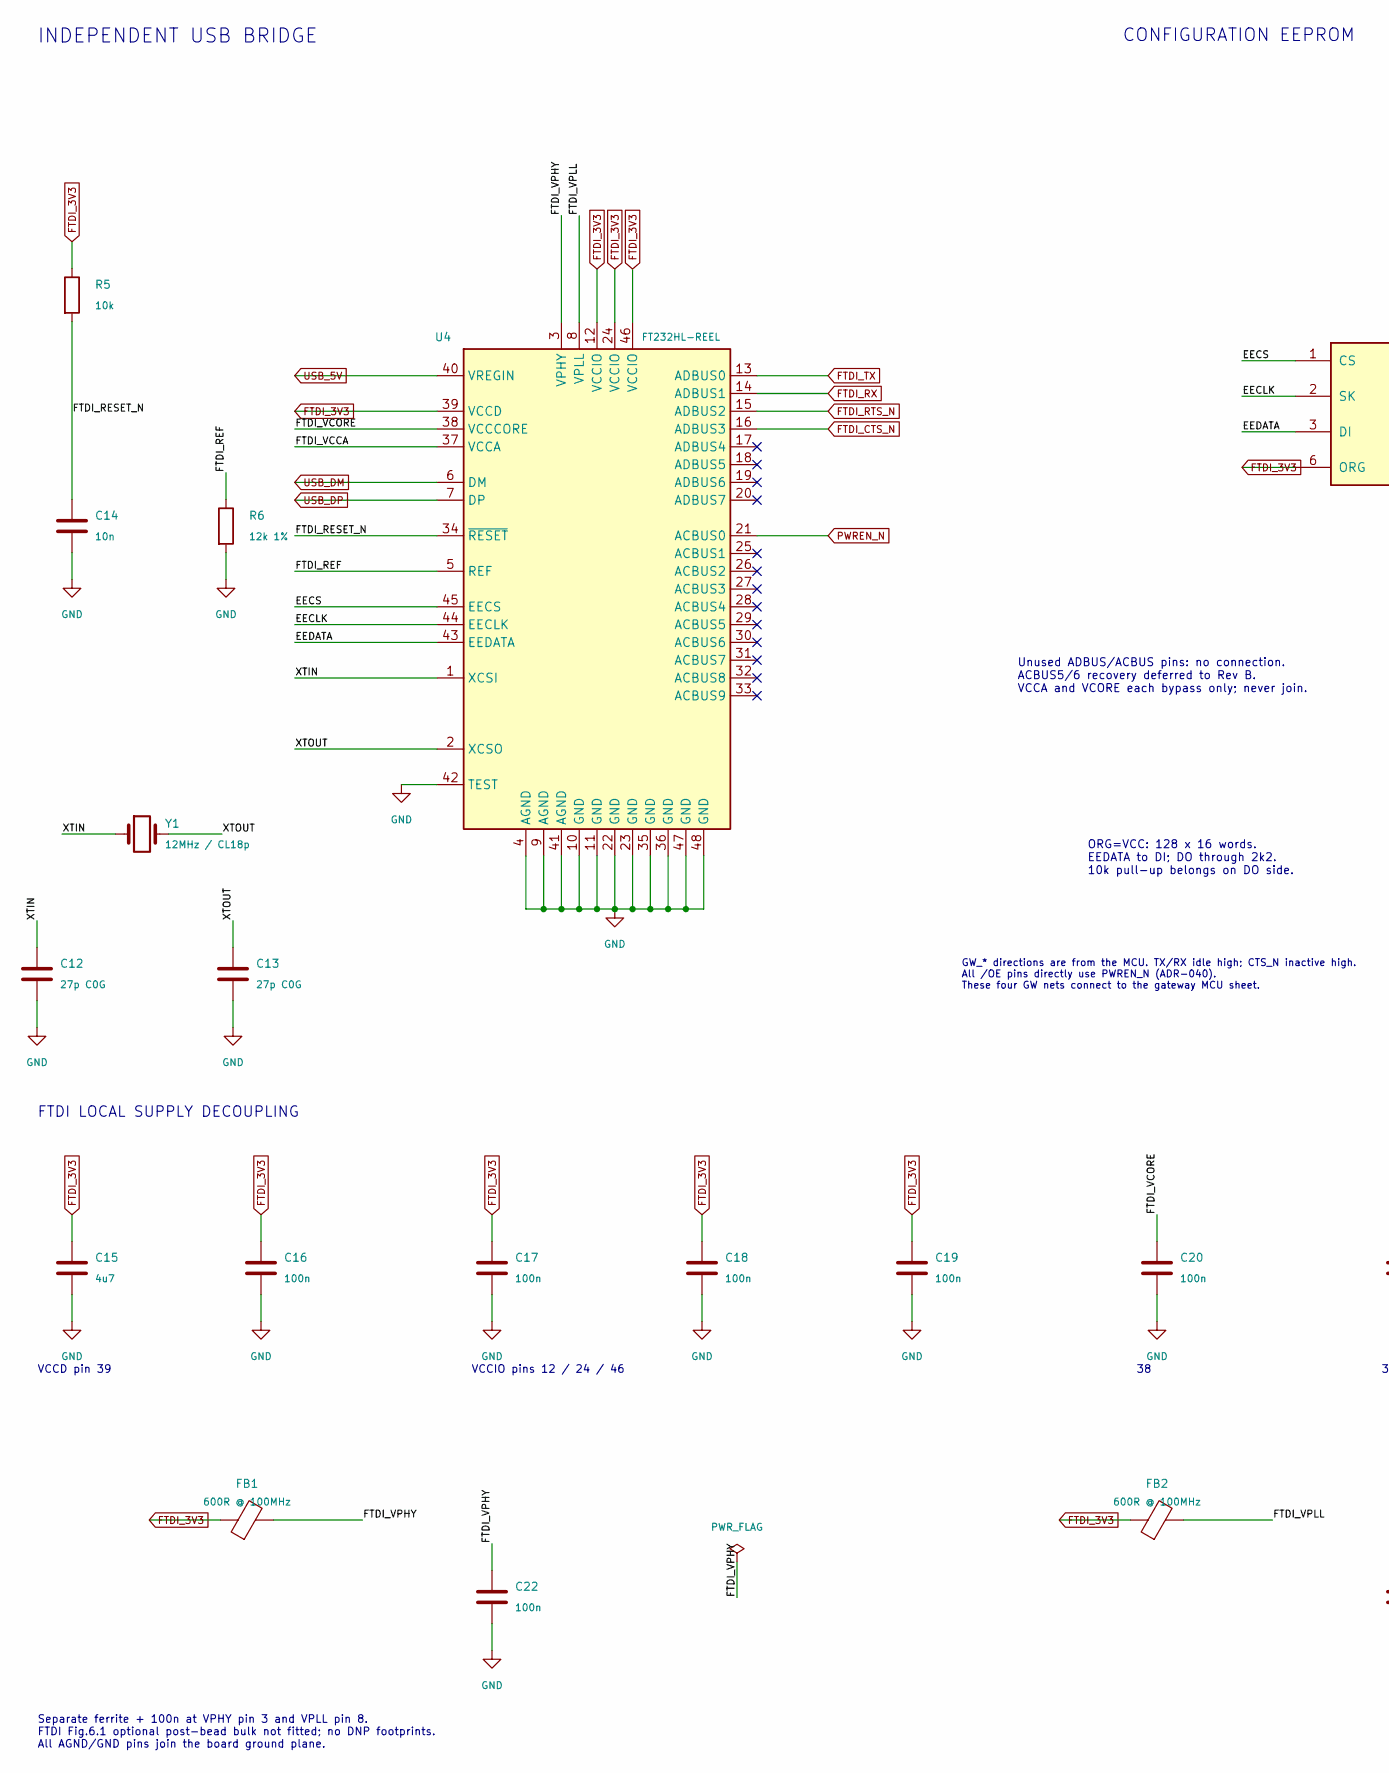
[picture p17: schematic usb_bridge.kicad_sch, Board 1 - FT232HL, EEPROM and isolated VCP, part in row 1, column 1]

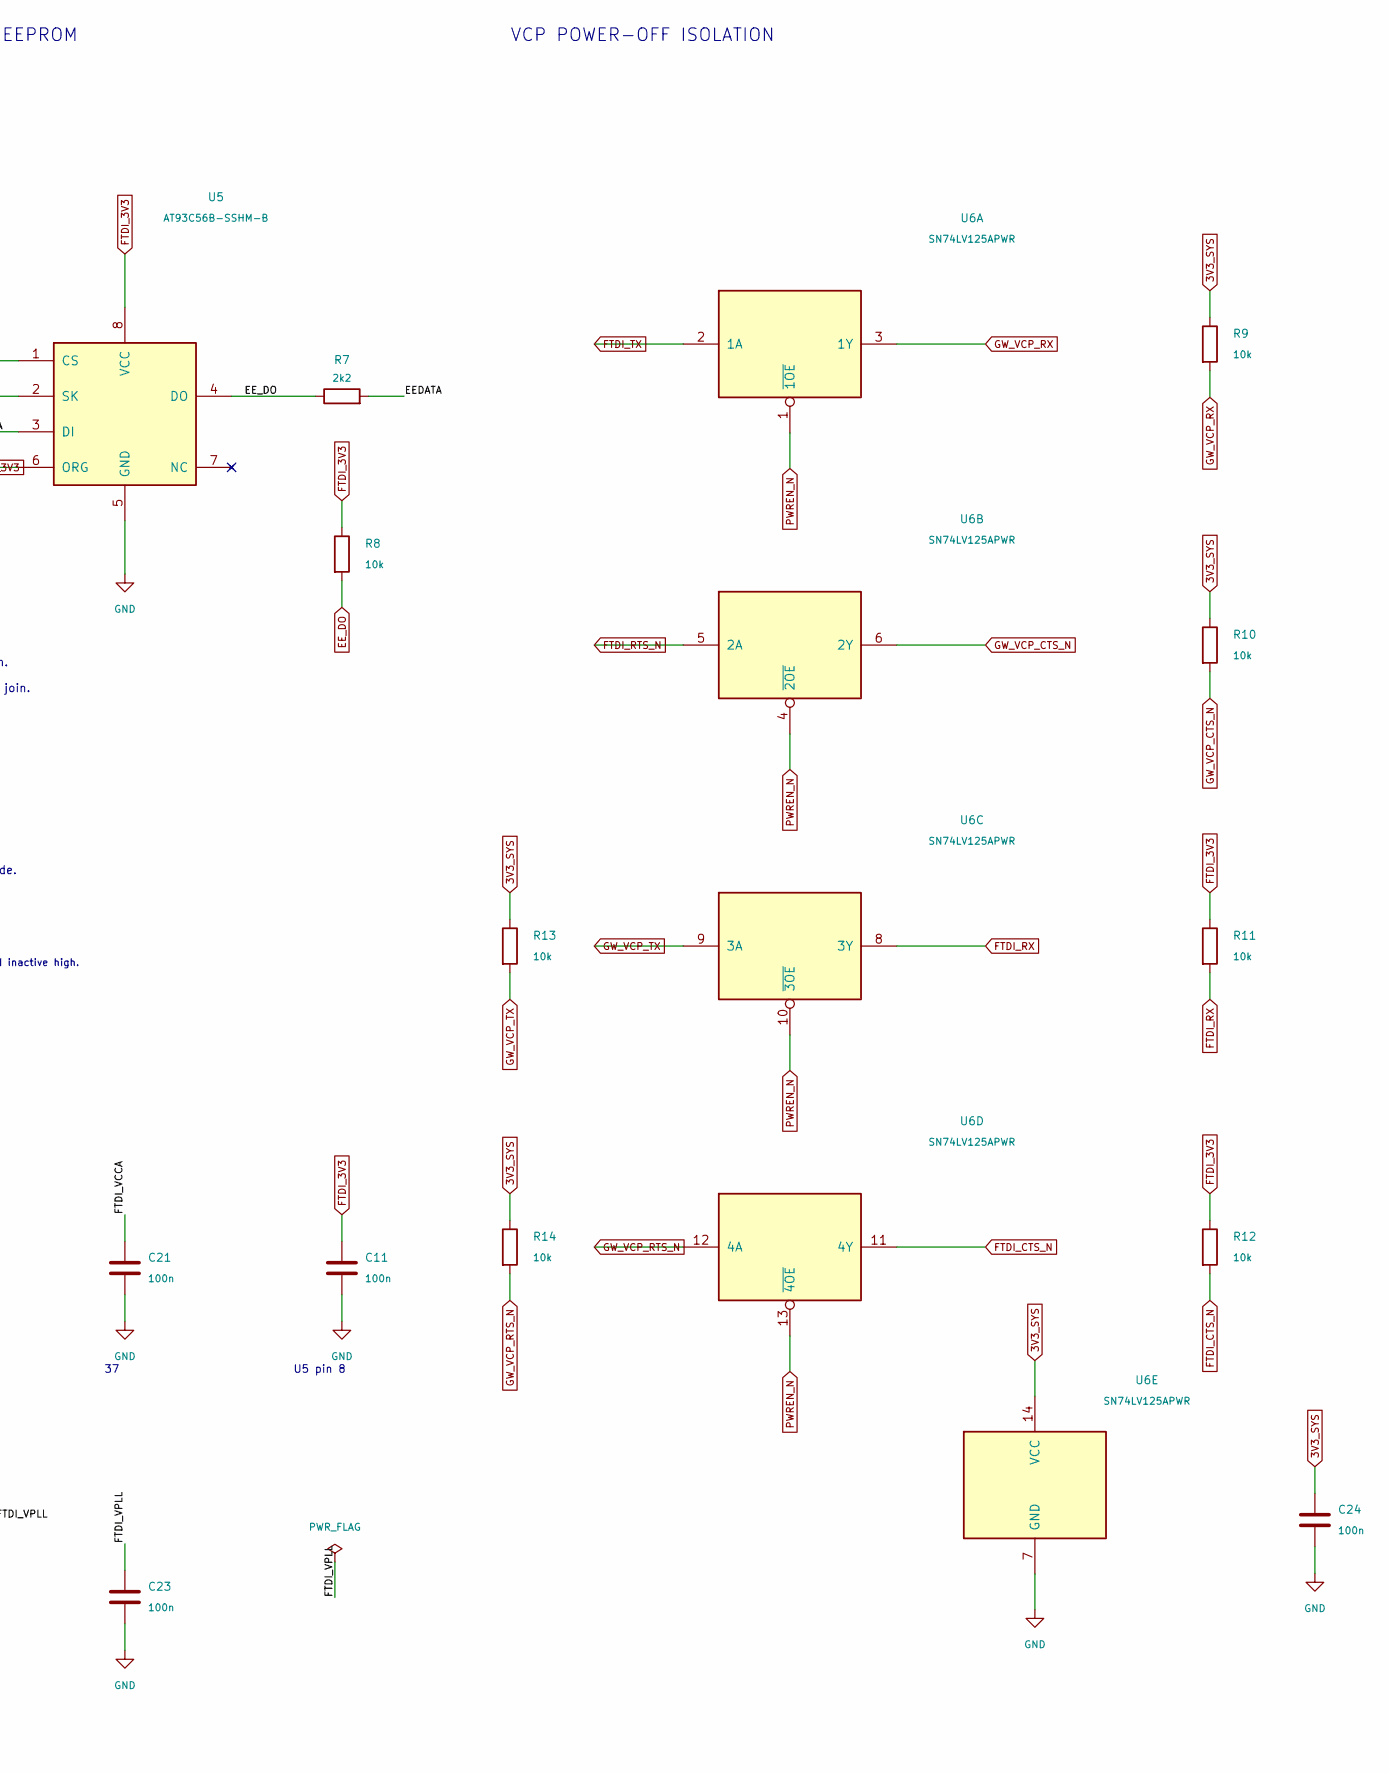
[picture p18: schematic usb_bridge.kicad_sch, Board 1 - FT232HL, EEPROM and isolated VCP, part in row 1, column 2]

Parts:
C11, C16, C17, C18, C19, C20, C21, C22, C23, C24: 100n; C_0805_2012Metric; MPN KGM21NR71E104KT
C12, C13: 27p C0G; C_0805_2012Metric; MPN CC0805FRNPO9BN270
C14: 10n; C_0805_2012Metric; MPN CL21B103KBANNNC
C15: 4u7; C_0805_2012Metric; MPN GRM21BR71C475KE51L
FB1, FB2: 600R @ 100MHz; L_0805_2012Metric; MPN BLM21AG601SN1D
R5, R8, R9, R10, R11, R12, R13, R14: 10k; R_0805_2012Metric; MPN RMCF0805FT10K0
R6: 12k 1%; R_0805_2012Metric; MPN RMCF0805FT12K0
R7: 2k2; R_0805_2012Metric; MPN RC0805FR-072K2L
U4: FT232HL-REEL; LQFP-48_7x7mm_P0.5mm; MPN FT232HL-REEL
U5: AT93C56B-SSHM-B; SOIC-8_3.9x4.9mm_P1.27mm; MPN AT93C56B-SSHM-B
U6: SN74LV125APWR; TSSOP-14_4.4x5mm_P0.65mm; MPN SN74LV125APWR
Y1: 12MHz / CL18p; Crystal_SMD_HC49-SD; MPN ECS-120-18-5PX-CKM-TR

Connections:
3V3_SYS: C24.1, R9.1, R10.1, R13.1, R14.1, U6.14 (VCC); also elsewhere on the board
/USB bridge and VCP/EECLK: U4.44 (EECLK), U5.2 (SK)
/USB bridge and VCP/EECS: U4.45 (EECS), U5.1 (CS)
/USB bridge and VCP/EEDATA: R7.2, U4.43 (EEDATA), U5.3 (DI)
/USB bridge and VCP/FTDI_REF: R6.1, U4.5 (REF)
/USB bridge and VCP/FTDI_RESET_N: C14.1, R5.2, U4.34 (~RESET)
/USB bridge and VCP/FTDI_VCCA: C21.1, U4.37 (VCCA)
/USB bridge and VCP/FTDI_VCORE: C20.1, U4.38 (VCCCORE)
/USB bridge and VCP/FTDI_VPHY: C22.1, FB1.2, U4.3 (VPHY)
/USB bridge and VCP/FTDI_VPLL: C23.1, FB2.2, U4.8 (VPLL)
/USB bridge and VCP/XTIN: C12.1, U4.1 (XCSI), Y1.1
/USB bridge and VCP/XTOUT: C13.1, U4.2 (XCSO), Y1.2
EE_DO: R7.1, R8.2, U5.4 (DO)
FTDI_3V3: C11.1, C15.1, C16.1, C17.1, C18.1, C19.1, FB1.1, FB2.1, R5.1, R8.1, R11.1, R12.1, U4.12 (VCCIO), U4.24 (VCCIO), U4.39 (VCCD), U4.46 (VCCIO), U5.6 (ORG), U5.8 (VCC); also elsewhere on the board
FTDI_CTS_N: R12.2, U4.16 (ADBUS3), U6.11 (4Y)
FTDI_RTS_N: U4.15 (ADBUS2), U6.5 (2A)
FTDI_RX: R11.2, U4.14 (ADBUS1), U6.8 (3Y)
FTDI_TX: U4.13 (ADBUS0), U6.2 (1A)
GND: C11.2, C12.2, C13.2, C14.2, C15.2, C16.2, C17.2, C18.2, C19.2, C20.2, C21.2, C22.2, C23.2, C24.2, R6.2, U4.4 (AGND), U4.9 (AGND), U4.10 (GND), U4.11 (GND), U4.22 (GND), U4.23 (GND), U4.35 (GND), U4.36 (GND), U4.41 (AGND), U4.42 (TEST), U4.47 (GND), U4.48 (GND), U5.5 (GND), U6.7 (GND); also elsewhere on the board
GW_VCP_CTS_N: R10.2, U6.6 (2Y); also elsewhere on the board
GW_VCP_RTS_N: R14.2, U6.12 (4A); also elsewhere on the board
GW_VCP_RX: R9.2, U6.3 (1Y); also elsewhere on the board
GW_VCP_TX: R13.2, U6.9 (3A); also elsewhere on the board
PWREN_N: U4.21 (ACBUS0), U6.1 (~1OE), U6.4 (~2OE), U6.10 (~3OE), U6.13 (~4OE); also elsewhere on the board
USB_5V: U4.40 (VREGIN); also elsewhere on the board
USB_DM: U4.6 (DM); also elsewhere on the board
USB_DP: U4.7 (DP); also elsewhere on the board

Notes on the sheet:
INDEPENDENT USB BRIDGE
CONFIGURATION EEPROM
VCP POWER-OFF ISOLATION
Unused ADBUS/ACBUS pins: no connection. ACBUS5/6 recovery deferred to Rev B. VCCA and VCORE each bypass only; never join.
ORG=VCC: 128 x 16 words. EEDATA to DI; DO through 2k2. 10k pull-up belongs on DO side.
FTDI LOCAL SUPPLY DECOUPLING
VCCD pin 39
VCCIO pins 12 / 24 / 46
U5 pin 8
Separate ferrite + 100n at VPHY pin 3 and VPLL pin 8. FTDI Fig.6.1 optional post-bead bulk not fitted; no DNP footprints. All AGND/GND pins join the board ground plane.
GW_* directions are from the MCU. TX/RX idle high; CTS_N inactive high. All /OE pins directly use PWREN_N (ADR-040). These four GW nets connect to the gateway MCU sheet.

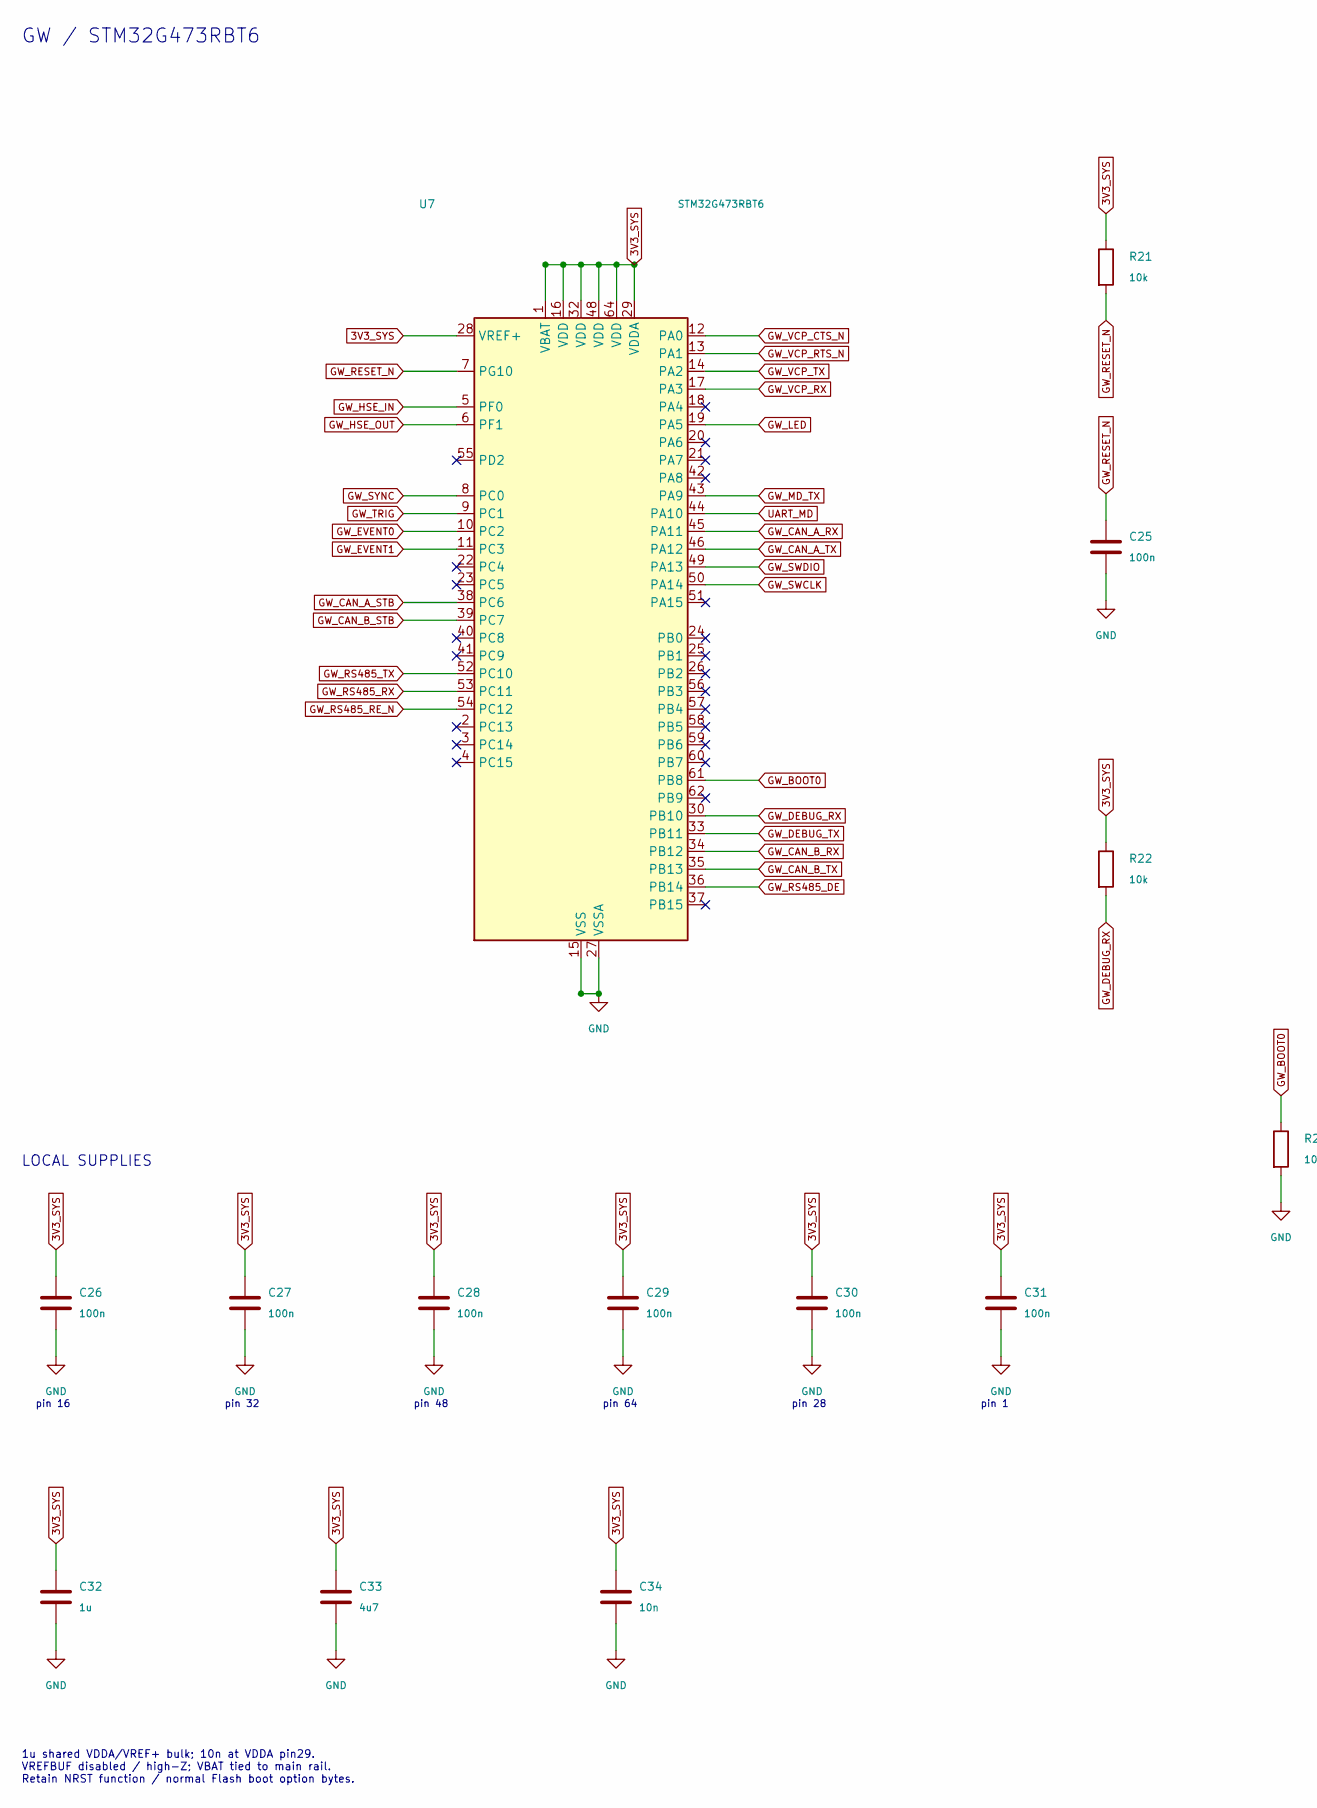
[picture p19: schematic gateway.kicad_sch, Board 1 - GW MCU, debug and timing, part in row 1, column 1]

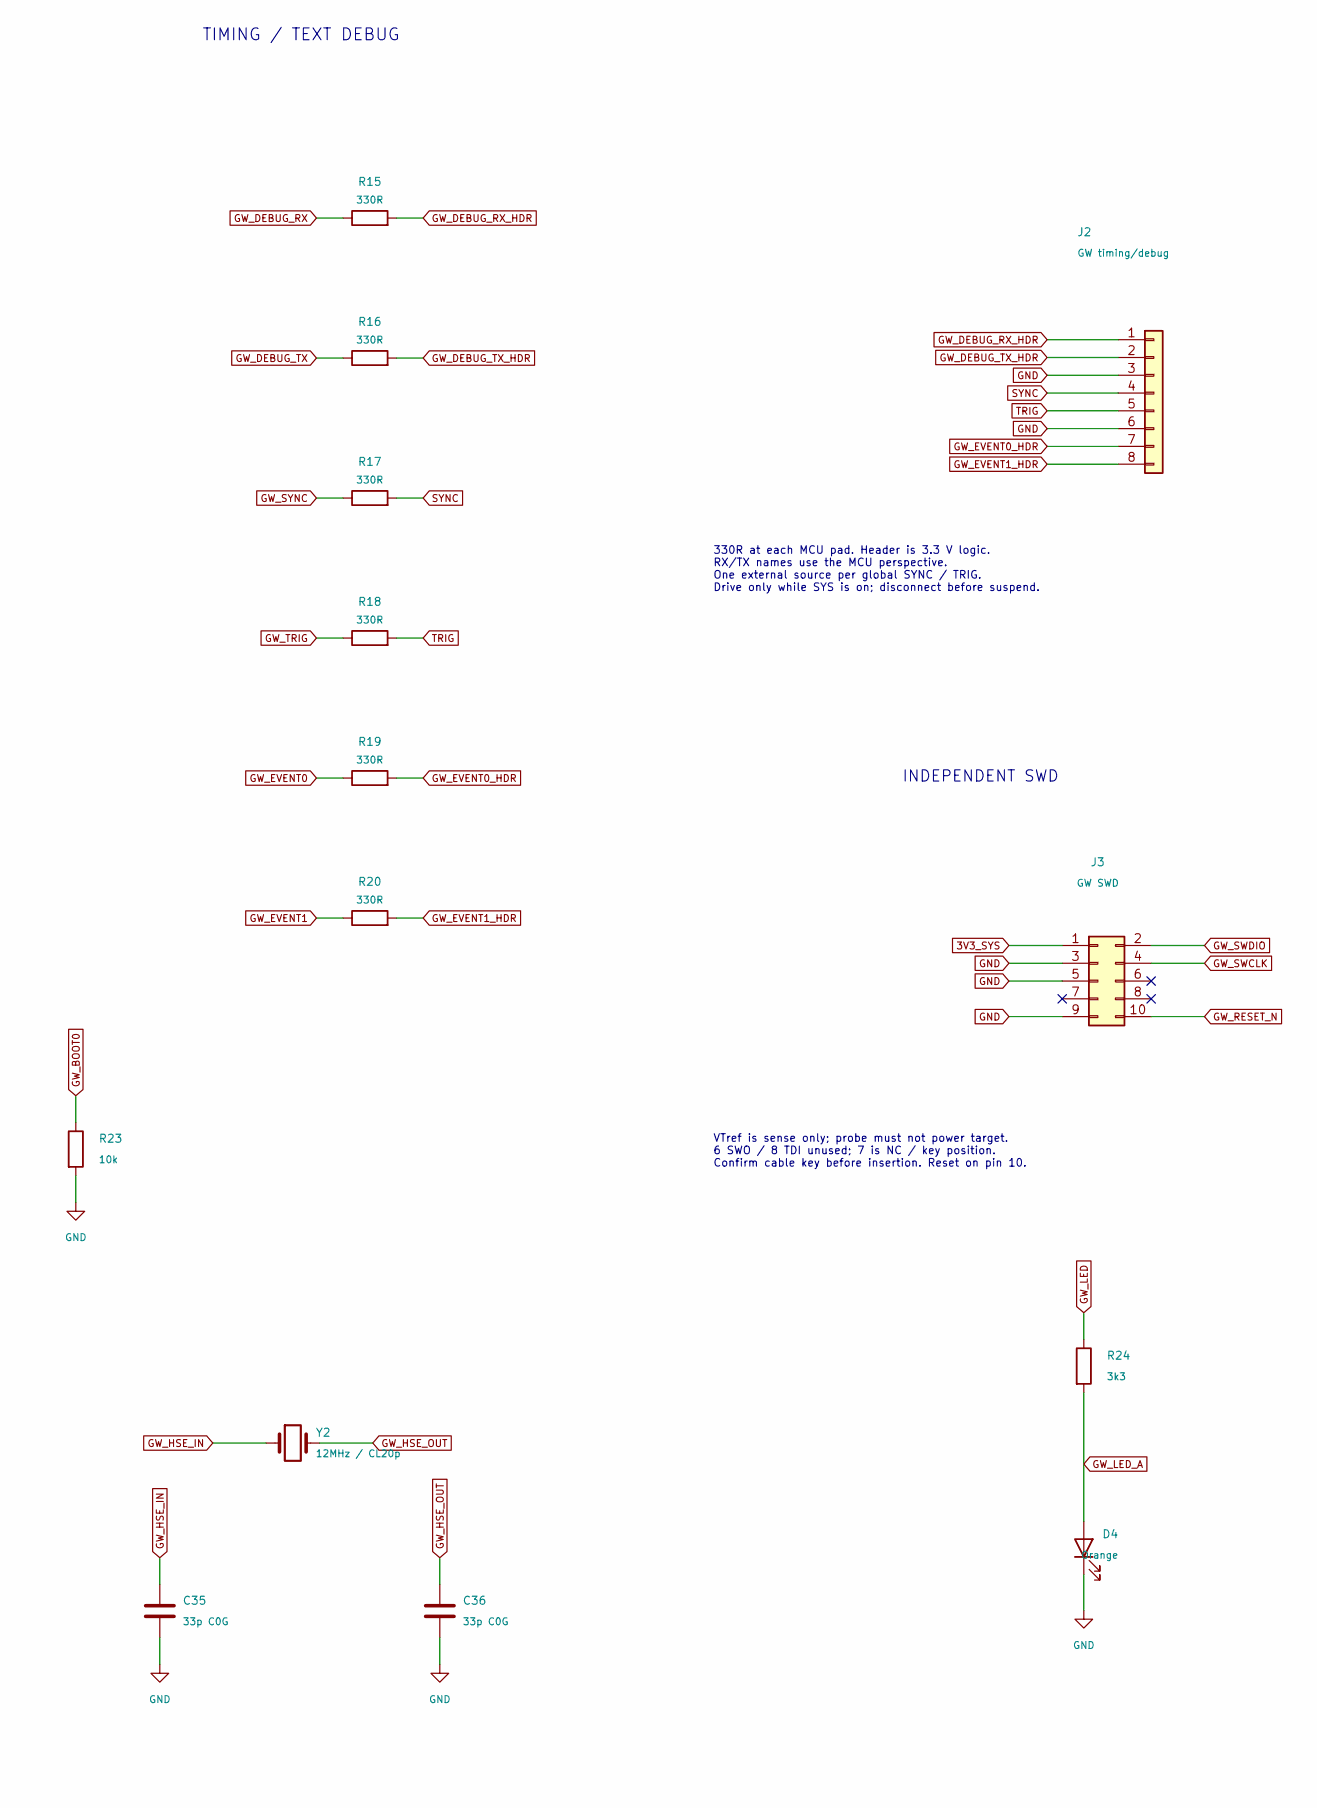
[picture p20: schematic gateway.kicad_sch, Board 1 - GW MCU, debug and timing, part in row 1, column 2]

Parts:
C25, C26, C27, C28, C29, C30, C31: 100n; C_0805_2012Metric; MPN KGM21NR71E104KT
C32: 1u; C_0805_2012Metric; MPN CL21B105KAFNFNE
C33: 4u7; C_0805_2012Metric; MPN GRM21BR71C475KE51L
C34: 10n; C_0805_2012Metric; MPN CL21B103KBANNNC
C35, C36: 33p C0G; C_0805_2012Metric; MPN CC0805FRNPO9BN330
D4: Orange; LED_0603_1608Metric; MPN CSL1901DW1
J2: GW timing/debug; PinHeader_1x08_P2.54mm_Vertical; MPN PRPC040SAAN-RC
J3: GW SWD; CNC_Tech_3220-10-0100-00_2x05_P1.27mm_Vertical; MPN 3220-10-0100-00
R15, R16, R17, R18, R19, R20: 330R; R_0805_2012Metric; MPN CRGP0805F330R
R21, R22, R23: 10k; R_0805_2012Metric; MPN RMCF0805FT10K0
R24: 3k3; R_0805_2012Metric; MPN RK73H2ATTD3301F
U7: STM32G473RBT6; LQFP-64_10x10mm_P0.5mm; MPN STM32G473RBT6
Y2: 12MHz / CL20p; Crystal_SMD_ECS_CSM3X-2Pin_7.6x4.1mm; MPN ECS-120-20-3X-EN-TR

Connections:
3V3_SYS: C26.1, C27.1, C28.1, C29.1, C30.1, C31.1, C32.1, C33.1, C34.1, J3.1, R21.1, R22.1, U7.1 (VBAT), U7.16 (VDD), U7.28 (VREF+), U7.29 (VDDA), U7.32 (VDD), U7.48 (VDD), U7.64 (VDD); also elsewhere on the board
GND: C25.2, C26.2, C27.2, C28.2, C29.2, C30.2, C31.2, C32.2, C33.2, C34.2, C35.2, C36.2, D4.1 (K), J2.3, J2.6, J3.3, J3.5, J3.9, R23.2, U7.15 (VSS), U7.27 (VSSA), U7.31 (VSS), U7.47 (VSS), U7.63 (VSS); also elsewhere on the board
GW_BOOT0: R23.1, U7.61 (PB8); also elsewhere on the board
GW_CAN_A_RX: U7.45 (PA11); also elsewhere on the board
GW_CAN_A_STB: U7.38 (PC6); also elsewhere on the board
GW_CAN_A_TX: U7.46 (PA12); also elsewhere on the board
GW_CAN_B_RX: U7.34 (PB12); also elsewhere on the board
GW_CAN_B_STB: U7.39 (PC7); also elsewhere on the board
GW_CAN_B_TX: U7.35 (PB13); also elsewhere on the board
GW_DEBUG_RX: R15.1, R22.2, U7.30 (PB10)
GW_DEBUG_RX_HDR: J2.1, R15.2
GW_DEBUG_TX: R16.1, U7.33 (PB11)
GW_DEBUG_TX_HDR: J2.2, R16.2
GW_EVENT0: R19.1, U7.10 (PC2)
GW_EVENT0_HDR: J2.7, R19.2
GW_EVENT1: R20.1, U7.11 (PC3)
GW_EVENT1_HDR: J2.8, R20.2
GW_HSE_IN: C35.1, U7.5 (PF0), Y2.1
GW_HSE_OUT: C36.1, U7.6 (PF1), Y2.2
GW_LED: R24.1, U7.19 (PA5)
GW_LED_A: D4.2 (A), R24.2
GW_MD_TX: U7.43 (PA9); also elsewhere on the board
GW_RESET_N: C25.1, J3.10, R21.2, U7.7 (PG10); also elsewhere on the board
GW_RS485_DE: U7.36 (PB14); also elsewhere on the board
GW_RS485_RE_N: U7.54 (PC12); also elsewhere on the board
GW_RS485_RX: U7.53 (PC11); also elsewhere on the board
GW_RS485_TX: U7.52 (PC10); also elsewhere on the board
GW_SWCLK: J3.4, U7.50 (PA14)
GW_SWDIO: J3.2, U7.49 (PA13)
GW_SYNC: R17.1, U7.8 (PC0)
GW_TRIG: R18.1, U7.9 (PC1)
GW_VCP_CTS_N: U7.12 (PA0); also elsewhere on the board
GW_VCP_RTS_N: U7.13 (PA1); also elsewhere on the board
GW_VCP_RX: U7.17 (PA3); also elsewhere on the board
GW_VCP_TX: U7.14 (PA2); also elsewhere on the board
SYNC: J2.4, R17.2; also elsewhere on the board
TRIG: J2.5, R18.2; also elsewhere on the board
UART_MD: U7.44 (PA10); also elsewhere on the board

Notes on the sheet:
GW / STM32G473RBT6
TIMING / TEXT DEBUG
INDEPENDENT SWD
330R at each MCU pad. Header is 3.3 V logic. RX/TX names use the MCU perspective. One external source per global SYNC / TRIG. Drive only while SYS is on; disconnect before suspend.
VTref is sense only; probe must not power target. 6 SWO / 8 TDI unused; 7 is NC / key position. Confirm cable key before insertion. Reset on pin 10.
LOCAL SUPPLIES
pin 16
pin 32
pin 48
pin 64
pin 28
pin 1
1u shared VDDA/VREF+ bulk; 10n at VDDA pin29. VREFBUF disabled / high-Z; VBAT tied to main rail. Retain NRST function / normal Flash boot option bytes.

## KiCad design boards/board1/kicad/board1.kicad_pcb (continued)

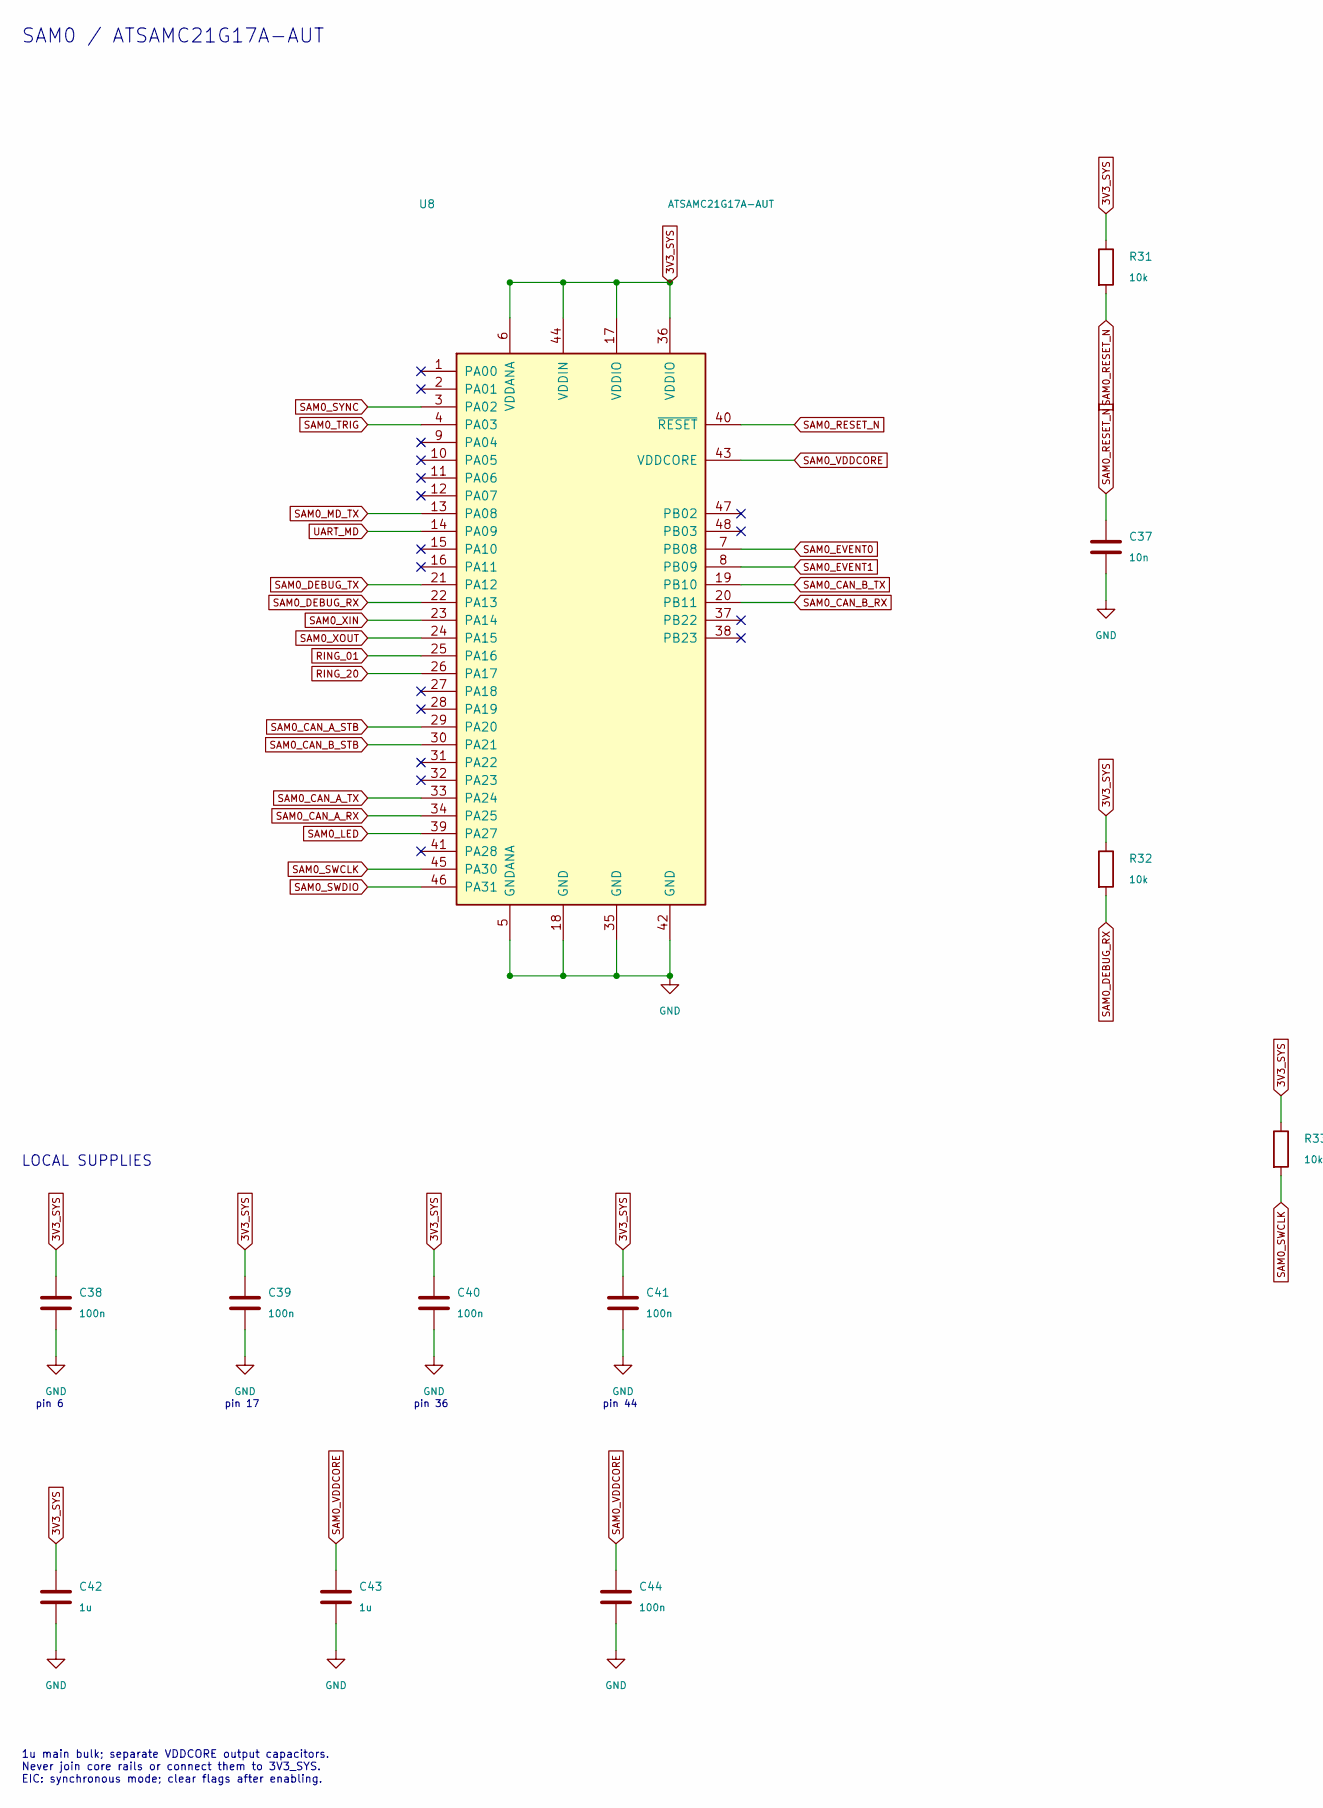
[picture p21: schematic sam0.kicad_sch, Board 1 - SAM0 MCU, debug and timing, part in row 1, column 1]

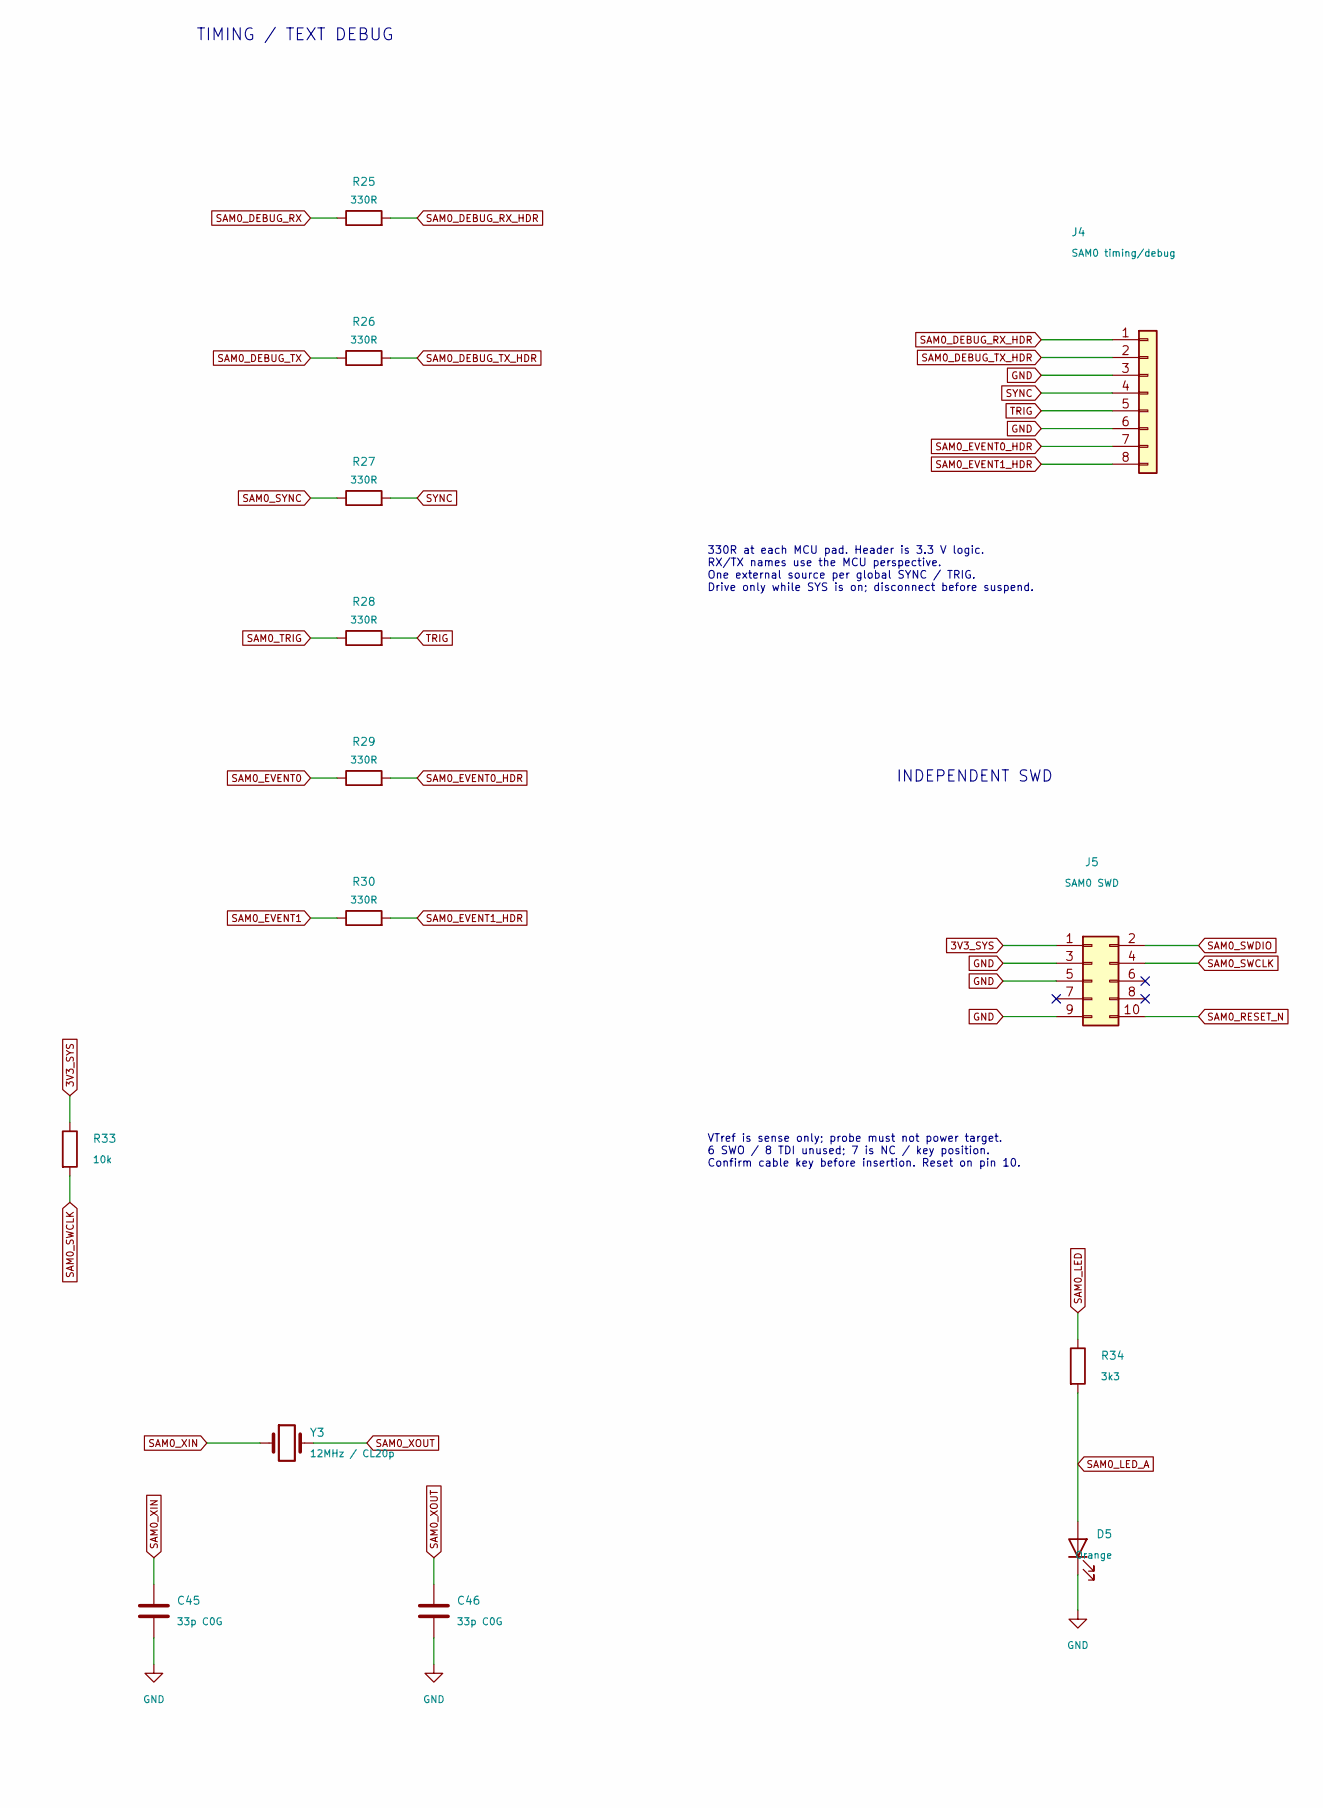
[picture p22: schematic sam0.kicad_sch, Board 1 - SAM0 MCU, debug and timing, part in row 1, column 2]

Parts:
C37: 10n; C_0805_2012Metric; MPN CL21B103KBANNNC
C38, C39, C40, C41, C44: 100n; C_0805_2012Metric; MPN KGM21NR71E104KT
C42, C43: 1u; C_0805_2012Metric; MPN CL21B105KAFNFNE
C45, C46: 33p C0G; C_0805_2012Metric; MPN CC0805FRNPO9BN330
D5: Orange; LED_0603_1608Metric; MPN CSL1901DW1
J4: SAM0 timing/debug; PinHeader_1x08_P2.54mm_Vertical; MPN PRPC040SAAN-RC
J5: SAM0 SWD; CNC_Tech_3220-10-0100-00_2x05_P1.27mm_Vertical; MPN 3220-10-0100-00
R25, R26, R27, R28, R29, R30: 330R; R_0805_2012Metric; MPN CRGP0805F330R
R31, R32, R33: 10k; R_0805_2012Metric; MPN RMCF0805FT10K0
R34: 3k3; R_0805_2012Metric; MPN RK73H2ATTD3301F
U8: ATSAMC21G17A-AUT; TQFP-48_7x7mm_P0.5mm; MPN ATSAMC21G17A-AUT
Y3: 12MHz / CL20p; Crystal_SMD_ECS_CSM3X-2Pin_7.6x4.1mm; MPN ECS-120-20-3X-EN-TR

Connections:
3V3_SYS: C38.1, C39.1, C40.1, C41.1, C42.1, J5.1, R31.1, R32.1, R33.1, U8.6 (VDDANA), U8.17 (VDDIO), U8.36 (VDDIO), U8.44 (VDDIN); also elsewhere on the board
GND: C37.2, C38.2, C39.2, C40.2, C41.2, C42.2, C43.2, C44.2, C45.2, C46.2, D5.1 (K), J4.3, J4.6, J5.3, J5.5, J5.9, U8.5 (GNDANA), U8.18 (GND), U8.35 (GND), U8.42 (GND); also elsewhere on the board
RING_01: U8.25 (PA16); also elsewhere on the board
RING_20: U8.26 (PA17); also elsewhere on the board
SAM0_CAN_A_RX: U8.34 (PA25); also elsewhere on the board
SAM0_CAN_A_STB: U8.29 (PA20); also elsewhere on the board
SAM0_CAN_A_TX: U8.33 (PA24); also elsewhere on the board
SAM0_CAN_B_RX: U8.20 (PB11); also elsewhere on the board
SAM0_CAN_B_STB: U8.30 (PA21); also elsewhere on the board
SAM0_CAN_B_TX: U8.19 (PB10); also elsewhere on the board
SAM0_DEBUG_RX: R25.1, R32.2, U8.22 (PA13)
SAM0_DEBUG_RX_HDR: J4.1, R25.2
SAM0_DEBUG_TX: R26.1, U8.21 (PA12)
SAM0_DEBUG_TX_HDR: J4.2, R26.2
SAM0_EVENT0: R29.1, U8.7 (PB08)
SAM0_EVENT0_HDR: J4.7, R29.2
SAM0_EVENT1: R30.1, U8.8 (PB09)
SAM0_EVENT1_HDR: J4.8, R30.2
SAM0_LED: R34.1, U8.39 (PA27)
SAM0_LED_A: D5.2 (A), R34.2
SAM0_MD_TX: U8.13 (PA08); also elsewhere on the board
SAM0_RESET_N: C37.1, J5.10, R31.2, U8.40 (~RESET); also elsewhere on the board
SAM0_SWCLK: J5.4, R33.2, U8.45 (PA30)
SAM0_SWDIO: J5.2, U8.46 (PA31)
SAM0_SYNC: R27.1, U8.3 (PA02)
SAM0_TRIG: R28.1, U8.4 (PA03)
SAM0_VDDCORE: C43.1, C44.1, U8.43 (VDDCORE); also elsewhere on the board
SAM0_XIN: C45.1, U8.23 (PA14), Y3.1
SAM0_XOUT: C46.1, U8.24 (PA15), Y3.2
SYNC: J4.4, R27.2; also elsewhere on the board
TRIG: J4.5, R28.2; also elsewhere on the board
UART_MD: U8.14 (PA09); also elsewhere on the board

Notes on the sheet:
SAM0 / ATSAMC21G17A-AUT
TIMING / TEXT DEBUG
INDEPENDENT SWD
330R at each MCU pad. Header is 3.3 V logic. RX/TX names use the MCU perspective. One external source per global SYNC / TRIG. Drive only while SYS is on; disconnect before suspend.
VTref is sense only; probe must not power target. 6 SWO / 8 TDI unused; 7 is NC / key position. Confirm cable key before insertion. Reset on pin 10.
LOCAL SUPPLIES
pin 6
pin 17
pin 36
pin 44
1u main bulk; separate VDDCORE output capacitors. Never join core rails or connect them to 3V3_SYS. EIC: synchronous mode; clear flags after enabling.

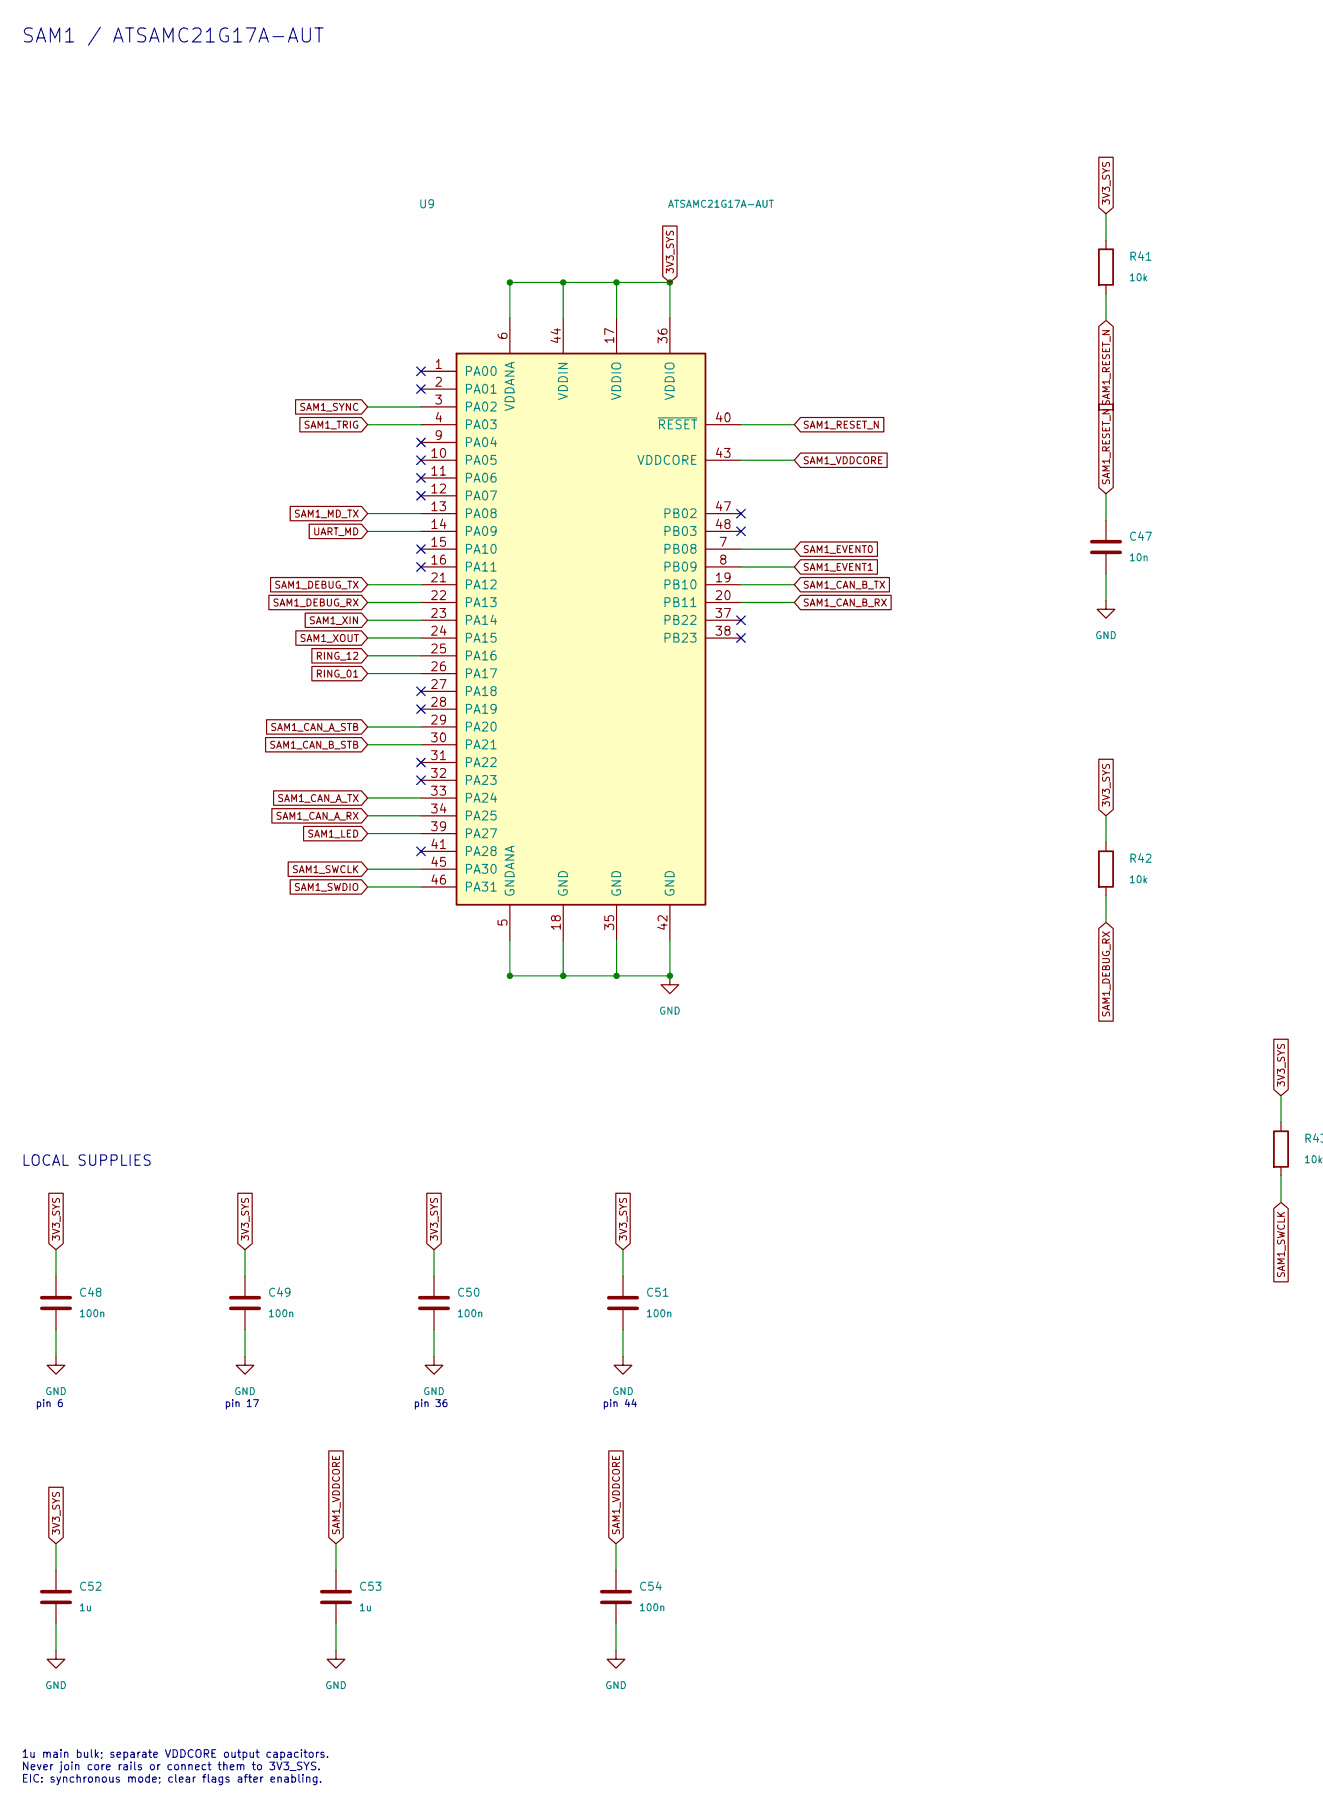
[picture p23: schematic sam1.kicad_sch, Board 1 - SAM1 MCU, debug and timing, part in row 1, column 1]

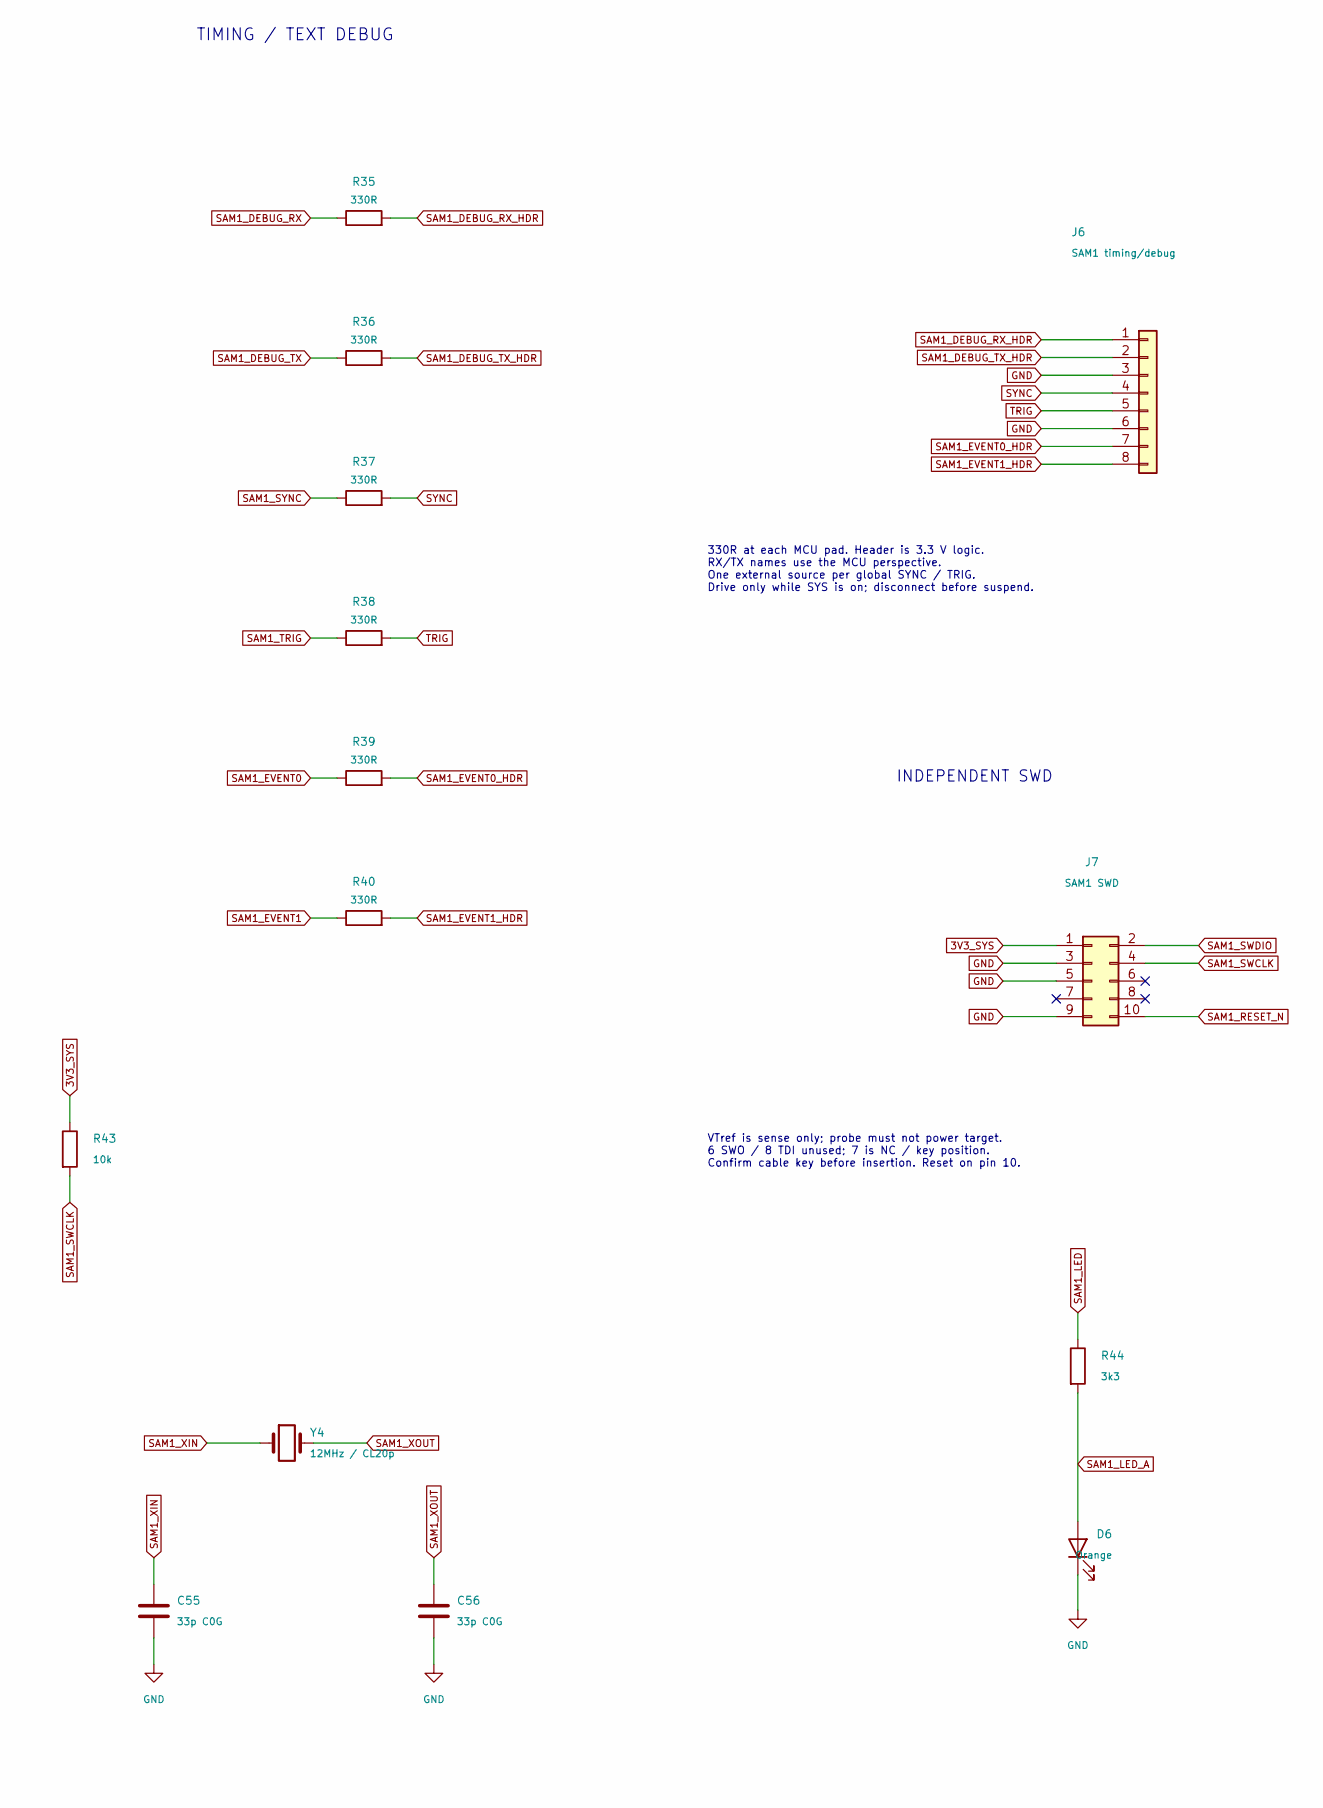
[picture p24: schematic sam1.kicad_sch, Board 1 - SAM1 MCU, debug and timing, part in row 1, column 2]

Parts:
C47: 10n; C_0805_2012Metric; MPN CL21B103KBANNNC
C48, C49, C50, C51, C54: 100n; C_0805_2012Metric; MPN KGM21NR71E104KT
C52, C53: 1u; C_0805_2012Metric; MPN CL21B105KAFNFNE
C55, C56: 33p C0G; C_0805_2012Metric; MPN CC0805FRNPO9BN330
D6: Orange; LED_0603_1608Metric; MPN CSL1901DW1
J6: SAM1 timing/debug; PinHeader_1x08_P2.54mm_Vertical; MPN PRPC040SAAN-RC
J7: SAM1 SWD; CNC_Tech_3220-10-0100-00_2x05_P1.27mm_Vertical; MPN 3220-10-0100-00
R35, R36, R37, R38, R39, R40: 330R; R_0805_2012Metric; MPN CRGP0805F330R
R41, R42, R43: 10k; R_0805_2012Metric; MPN RMCF0805FT10K0
R44: 3k3; R_0805_2012Metric; MPN RK73H2ATTD3301F
U9: ATSAMC21G17A-AUT; TQFP-48_7x7mm_P0.5mm; MPN ATSAMC21G17A-AUT
Y4: 12MHz / CL20p; Crystal_SMD_ECS_CSM3X-2Pin_7.6x4.1mm; MPN ECS-120-20-3X-EN-TR

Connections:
3V3_SYS: C48.1, C49.1, C50.1, C51.1, C52.1, J7.1, R41.1, R42.1, R43.1, U9.6 (VDDANA), U9.17 (VDDIO), U9.36 (VDDIO), U9.44 (VDDIN); also elsewhere on the board
GND: C47.2, C48.2, C49.2, C50.2, C51.2, C52.2, C53.2, C54.2, C55.2, C56.2, D6.1 (K), J6.3, J6.6, J7.3, J7.5, J7.9, U9.5 (GNDANA), U9.18 (GND), U9.35 (GND), U9.42 (GND); also elsewhere on the board
RING_01: U9.26 (PA17); also elsewhere on the board
RING_12: U9.25 (PA16); also elsewhere on the board
SAM1_CAN_A_RX: U9.34 (PA25); also elsewhere on the board
SAM1_CAN_A_STB: U9.29 (PA20); also elsewhere on the board
SAM1_CAN_A_TX: U9.33 (PA24); also elsewhere on the board
SAM1_CAN_B_RX: U9.20 (PB11); also elsewhere on the board
SAM1_CAN_B_STB: U9.30 (PA21); also elsewhere on the board
SAM1_CAN_B_TX: U9.19 (PB10); also elsewhere on the board
SAM1_DEBUG_RX: R35.1, R42.2, U9.22 (PA13)
SAM1_DEBUG_RX_HDR: J6.1, R35.2
SAM1_DEBUG_TX: R36.1, U9.21 (PA12)
SAM1_DEBUG_TX_HDR: J6.2, R36.2
SAM1_EVENT0: R39.1, U9.7 (PB08)
SAM1_EVENT0_HDR: J6.7, R39.2
SAM1_EVENT1: R40.1, U9.8 (PB09)
SAM1_EVENT1_HDR: J6.8, R40.2
SAM1_LED: R44.1, U9.39 (PA27)
SAM1_LED_A: D6.2 (A), R44.2
SAM1_MD_TX: U9.13 (PA08); also elsewhere on the board
SAM1_RESET_N: C47.1, J7.10, R41.2, U9.40 (~RESET); also elsewhere on the board
SAM1_SWCLK: J7.4, R43.2, U9.45 (PA30)
SAM1_SWDIO: J7.2, U9.46 (PA31)
SAM1_SYNC: R37.1, U9.3 (PA02)
SAM1_TRIG: R38.1, U9.4 (PA03)
SAM1_VDDCORE: C53.1, C54.1, U9.43 (VDDCORE); also elsewhere on the board
SAM1_XIN: C55.1, U9.23 (PA14), Y4.1
SAM1_XOUT: C56.1, U9.24 (PA15), Y4.2
SYNC: J6.4, R37.2; also elsewhere on the board
TRIG: J6.5, R38.2; also elsewhere on the board
UART_MD: U9.14 (PA09); also elsewhere on the board

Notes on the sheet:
SAM1 / ATSAMC21G17A-AUT
TIMING / TEXT DEBUG
INDEPENDENT SWD
330R at each MCU pad. Header is 3.3 V logic. RX/TX names use the MCU perspective. One external source per global SYNC / TRIG. Drive only while SYS is on; disconnect before suspend.
VTref is sense only; probe must not power target. 6 SWO / 8 TDI unused; 7 is NC / key position. Confirm cable key before insertion. Reset on pin 10.
LOCAL SUPPLIES
pin 6
pin 17
pin 36
pin 44
1u main bulk; separate VDDCORE output capacitors. Never join core rails or connect them to 3V3_SYS. EIC: synchronous mode; clear flags after enabling.

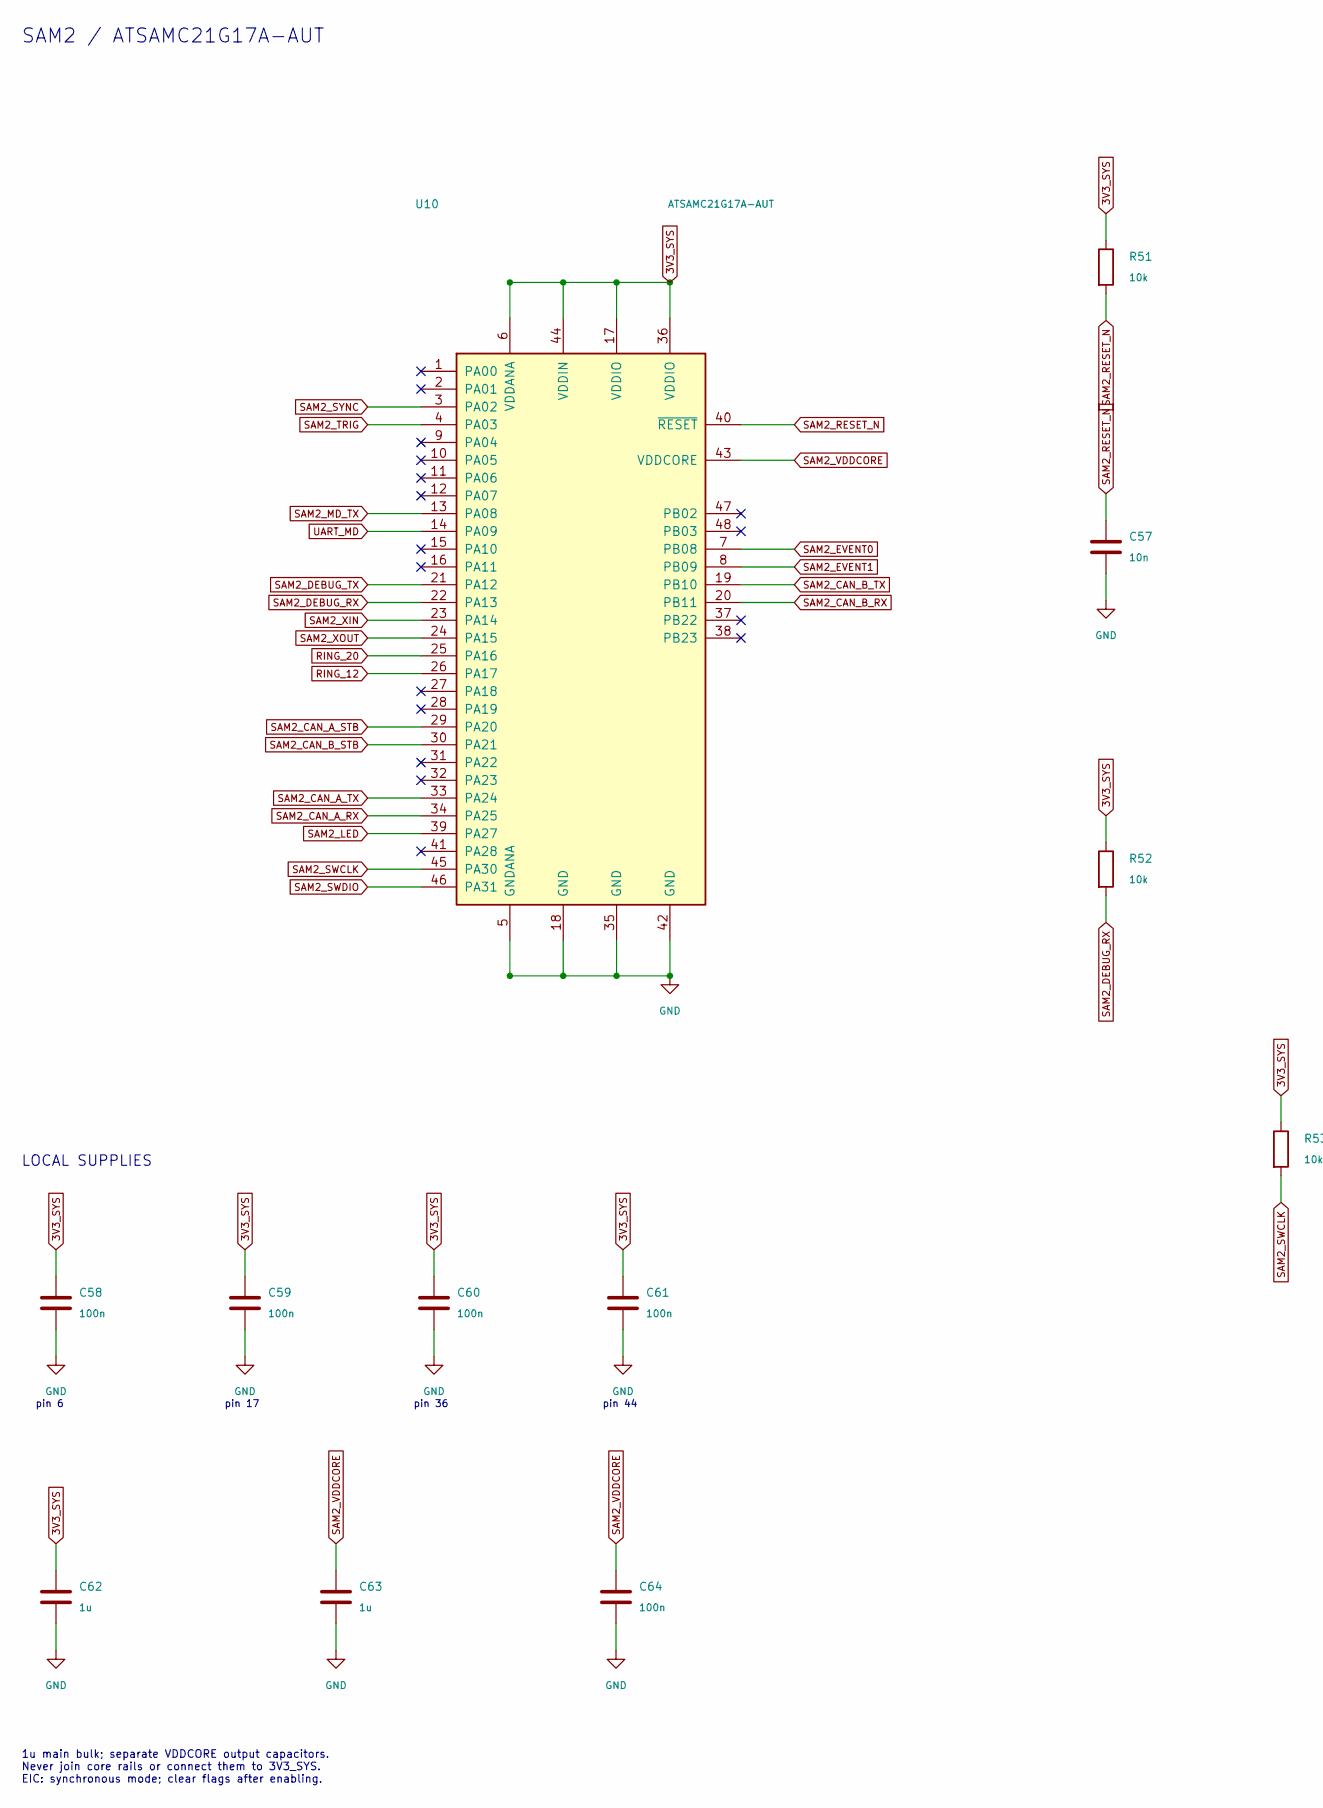
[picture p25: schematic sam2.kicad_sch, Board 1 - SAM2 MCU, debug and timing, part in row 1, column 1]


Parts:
C57: 10n; C_0805_2012Metric; MPN CL21B103KBANNNC
C58, C59, C60, C61, C64: 100n; C_0805_2012Metric; MPN KGM21NR71E104KT
C62, C63: 1u; C_0805_2012Metric; MPN CL21B105KAFNFNE
C65, C66: 33p C0G; C_0805_2012Metric; MPN CC0805FRNPO9BN330
D7: Orange; LED_0603_1608Metric; MPN CSL1901DW1
J8: SAM2 timing/debug; PinHeader_1x08_P2.54mm_Vertical; MPN PRPC040SAAN-RC
J9: SAM2 SWD; CNC_Tech_3220-10-0100-00_2x05_P1.27mm_Vertical; MPN 3220-10-0100-00
R45, R46, R47, R48, R49, R50: 330R; R_0805_2012Metric; MPN CRGP0805F330R
R51, R52, R53: 10k; R_0805_2012Metric; MPN RMCF0805FT10K0
R54: 3k3; R_0805_2012Metric; MPN RK73H2ATTD3301F
U10: ATSAMC21G17A-AUT; TQFP-48_7x7mm_P0.5mm; MPN ATSAMC21G17A-AUT
Y5: 12MHz / CL20p; Crystal_SMD_ECS_CSM3X-2Pin_7.6x4.1mm; MPN ECS-120-20-3X-EN-TR

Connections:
3V3_SYS: C58.1, C59.1, C60.1, C61.1, C62.1, J9.1, R51.1, R52.1, R53.1, U10.6 (VDDANA), U10.17 (VDDIO), U10.36 (VDDIO), U10.44 (VDDIN); also elsewhere on the board
GND: C57.2, C58.2, C59.2, C60.2, C61.2, C62.2, C63.2, C64.2, C65.2, C66.2, D7.1 (K), J8.3, J8.6, J9.3, J9.5, J9.9, U10.5 (GNDANA), U10.18 (GND), U10.35 (GND), U10.42 (GND); also elsewhere on the board
RING_12: U10.26 (PA17); also elsewhere on the board
RING_20: U10.25 (PA16); also elsewhere on the board
SAM2_CAN_A_RX: U10.34 (PA25); also elsewhere on the board
SAM2_CAN_A_STB: U10.29 (PA20); also elsewhere on the board
SAM2_CAN_A_TX: U10.33 (PA24); also elsewhere on the board
SAM2_CAN_B_RX: U10.20 (PB11); also elsewhere on the board
SAM2_CAN_B_STB: U10.30 (PA21); also elsewhere on the board
SAM2_CAN_B_TX: U10.19 (PB10); also elsewhere on the board
SAM2_DEBUG_RX: R45.1, R52.2, U10.22 (PA13)
SAM2_DEBUG_RX_HDR: J8.1, R45.2
SAM2_DEBUG_TX: R46.1, U10.21 (PA12)
SAM2_DEBUG_TX_HDR: J8.2, R46.2
SAM2_EVENT0: R49.1, U10.7 (PB08)
SAM2_EVENT0_HDR: J8.7, R49.2
SAM2_EVENT1: R50.1, U10.8 (PB09)
SAM2_EVENT1_HDR: J8.8, R50.2
SAM2_LED: R54.1, U10.39 (PA27)
SAM2_LED_A: D7.2 (A), R54.2
SAM2_MD_TX: U10.13 (PA08); also elsewhere on the board
SAM2_RESET_N: C57.1, J9.10, R51.2, U10.40 (~RESET); also elsewhere on the board
SAM2_SWCLK: J9.4, R53.2, U10.45 (PA30)
SAM2_SWDIO: J9.2, U10.46 (PA31)
SAM2_SYNC: R47.1, U10.3 (PA02)
SAM2_TRIG: R48.1, U10.4 (PA03)
SAM2_VDDCORE: C63.1, C64.1, U10.43 (VDDCORE); also elsewhere on the board
SAM2_XIN: C65.1, U10.23 (PA14), Y5.1
SAM2_XOUT: C66.1, U10.24 (PA15), Y5.2
SYNC: J8.4, R47.2; also elsewhere on the board
TRIG: J8.5, R48.2; also elsewhere on the board
UART_MD: U10.14 (PA09); also elsewhere on the board

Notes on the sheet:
SAM2 / ATSAMC21G17A-AUT
TIMING / TEXT DEBUG
INDEPENDENT SWD
330R at each MCU pad. Header is 3.3 V logic. RX/TX names use the MCU perspective. One external source per global SYNC / TRIG. Drive only while SYS is on; disconnect before suspend.
VTref is sense only; probe must not power target. 6 SWO / 8 TDI unused; 7 is NC / key position. Confirm cable key before insertion. Reset on pin 10.
LOCAL SUPPLIES
pin 6
pin 17
pin 36
pin 44
1u main bulk; separate VDDCORE output capacitors. Never join core rails or connect them to 3V3_SYS. EIC: synchronous mode; clear flags after enabling.

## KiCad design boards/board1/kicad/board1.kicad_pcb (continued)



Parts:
C67, C68, C69, C70, C71, C72, C73, C74: 100n; C_0805_2012Metric; MPN KGM21NR71E104KT
J10: TERM A; PinHeader_1x02_P2.54mm_Vertical; MPN PRPC002SAAN-RC
R55, R56, R57, R58: 10k; R_0805_2012Metric; MPN RMCF0805FT10K0
R59, R60: 120R; R_0805_2012Metric; MPN CRGP0805F120R
U11, U12, U13, U14: TCAN3413DR; SOIC-8_3.9x4.9mm_P1.27mm; MPN TCAN3413DR

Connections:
3V3_SYS: C67.1, C68.1, C69.1, C70.1, C71.1, C72.1, C73.1, C74.1, R55.1, R56.1, R57.1, R58.1, U11.3 (VCC), U11.5 (VIO), U12.3 (VCC), U12.5 (VIO), U13.3 (VCC), U13.5 (VIO), U14.3 (VCC), U14.5 (VIO); also elsewhere on the board
CAN_A_TERM_RETURN: J10.1, R60.2
FD_CAN_A_H: R59.1, R60.1, U11.7 (CANH), U12.7 (CANH), U13.7 (CANH), U14.7 (CANH); also elsewhere on the board
FD_CAN_A_L: J10.2, R59.2, U11.6 (CANL), U12.6 (CANL), U13.6 (CANL), U14.6 (CANL); also elsewhere on the board
GND: C67.2, C68.2, C69.2, C70.2, C71.2, C72.2, C73.2, C74.2, U11.2 (GND), U12.2 (GND), U13.2 (GND), U14.2 (GND); also elsewhere on the board
GW_CAN_A_RX: U11.4 (RXD); also elsewhere on the board
GW_CAN_A_STB: R55.2, U11.8 (STB); also elsewhere on the board
GW_CAN_A_TX: U11.1 (TXD); also elsewhere on the board
SAM0_CAN_A_RX: U12.4 (RXD); also elsewhere on the board
SAM0_CAN_A_STB: R56.2, U12.8 (STB); also elsewhere on the board
SAM0_CAN_A_TX: U12.1 (TXD); also elsewhere on the board
SAM1_CAN_A_RX: U13.4 (RXD); also elsewhere on the board
SAM1_CAN_A_STB: R57.2, U13.8 (STB); also elsewhere on the board
SAM1_CAN_A_TX: U13.1 (TXD); also elsewhere on the board
SAM2_CAN_A_RX: U14.4 (RXD); also elsewhere on the board
SAM2_CAN_A_STB: R58.2, U14.8 (STB); also elsewhere on the board
SAM2_CAN_A_TX: U14.1 (TXD); also elsewhere on the board

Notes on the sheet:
FD_CAN_A / GW + SAM0 + SAM1 + SAM2
VCC pin3
VIO pin5
SAM0
SAM1
SAM2
LINEAR TRUNK: far onboard end -> four short PHY branches -> terminal / cable end
Fixed far end
Fit shunt for board-only; remove when cable extends this end. Remote cable endpoint must have its own 120R termination.
STB defaults high: standby. Set TX idle high before enabling PHY. No additional CAN channels or chokes.

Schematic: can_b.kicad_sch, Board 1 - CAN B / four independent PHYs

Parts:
C75, C76, C77, C78, C79, C80, C81, C82: 100n; C_0805_2012Metric; MPN KGM21NR71E104KT
J11: TERM B; PinHeader_1x02_P2.54mm_Vertical; MPN PRPC002SAAN-RC
R61, R62, R63, R64: 10k; R_0805_2012Metric; MPN RMCF0805FT10K0
R65, R66: 120R; R_0805_2012Metric; MPN CRGP0805F120R
U15, U16, U17, U18: TCAN3413DR; SOIC-8_3.9x4.9mm_P1.27mm; MPN TCAN3413DR

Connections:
3V3_SYS: C75.1, C76.1, C77.1, C78.1, C79.1, C80.1, C81.1, C82.1, R61.1, R62.1, R63.1, R64.1, U15.3 (VCC), U15.5 (VIO), U16.3 (VCC), U16.5 (VIO), U17.3 (VCC), U17.5 (VIO), U18.3 (VCC), U18.5 (VIO); also elsewhere on the board
CAN_B_TERM_RETURN: J11.1, R66.2
FD_CAN_B_H: R65.1, R66.1, U15.7 (CANH), U16.7 (CANH), U17.7 (CANH), U18.7 (CANH); also elsewhere on the board
FD_CAN_B_L: J11.2, R65.2, U15.6 (CANL), U16.6 (CANL), U17.6 (CANL), U18.6 (CANL); also elsewhere on the board
GND: C75.2, C76.2, C77.2, C78.2, C79.2, C80.2, C81.2, C82.2, U15.2 (GND), U16.2 (GND), U17.2 (GND), U18.2 (GND); also elsewhere on the board
GW_CAN_B_RX: U15.4 (RXD); also elsewhere on the board
GW_CAN_B_STB: R61.2, U15.8 (STB); also elsewhere on the board
GW_CAN_B_TX: U15.1 (TXD); also elsewhere on the board
SAM0_CAN_B_RX: U16.4 (RXD); also elsewhere on the board
SAM0_CAN_B_STB: R62.2, U16.8 (STB); also elsewhere on the board
SAM0_CAN_B_TX: U16.1 (TXD); also elsewhere on the board
SAM1_CAN_B_RX: U17.4 (RXD); also elsewhere on the board
SAM1_CAN_B_STB: R63.2, U17.8 (STB); also elsewhere on the board
SAM1_CAN_B_TX: U17.1 (TXD); also elsewhere on the board
SAM2_CAN_B_RX: U18.4 (RXD); also elsewhere on the board
SAM2_CAN_B_STB: R64.2, U18.8 (STB); also elsewhere on the board
SAM2_CAN_B_TX: U18.1 (TXD); also elsewhere on the board

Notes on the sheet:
FD_CAN_B / GW + SAM0 + SAM1 + SAM2
VCC pin3
VIO pin5
SAM0
SAM1
SAM2
LINEAR TRUNK: far onboard end -> four short PHY branches -> terminal / cable end
Fixed far end
Fit shunt for board-only; remove when cable extends this end. Remote cable endpoint must have its own 120R termination.
STB defaults high: standby. Set TX idle high before enabling PHY. No additional CAN channels or chokes.

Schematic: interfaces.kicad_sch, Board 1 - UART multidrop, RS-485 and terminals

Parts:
C83, C84: 100n; C_0805_2012Metric; MPN KGM21NR71E104KT
R67, R68, R69, R70, R72, R73, R74, R75, R76, R77: 10k; R_0805_2012Metric; MPN RMCF0805FT10K0
R71: 470R; R_0805_2012Metric; MPN RMCF0805FT470R
R78, R80: 330R; R_0805_2012Metric; MPN CRGP0805F330R
R79: 120R; R_0805_2012Metric; MPN CRGP0805F120R
U19: SN74LV125APWR; TSSOP-14_4.4x5mm_P0.65mm; MPN SN74LV125APWR
U20: ST3485EBDR; SOIC-8_3.9x4.9mm_P1.27mm; MPN ST3485EBDR

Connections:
3V3_SYS: C83.1, C84.1, R67.1, R68.1, R69.1, R70.1, R71.1, R75.1, R76.1, R77.1, R78.1, U19.14 (VCC), U20.8 (VCC); also elsewhere on the board
GND: C83.2, C84.2, R72.2, R73.2, R74.2, R80.2, U19.2 (1A), U19.5 (2A), U19.7 (GND), U19.9 (3A), U19.12 (4A), U20.5 (GND); also elsewhere on the board
GW_MD_TX: R67.2, U19.1 (~1OE); also elsewhere on the board
GW_RS485_DE: R74.1, U20.3 (DE); also elsewhere on the board
GW_RS485_RE_N: R75.2, U20.2 (~RE); also elsewhere on the board
GW_RS485_RX: R77.2, U20.1 (RO); also elsewhere on the board
GW_RS485_TX: R76.2, U20.4 (DI); also elsewhere on the board
RS485_A: R78.2, R79.1, U20.6 (A); also elsewhere on the board
RS485_B: R79.2, R80.1, U20.7 (B); also elsewhere on the board
SAM0_MD_TX: R68.2, U19.4 (~2OE); also elsewhere on the board
SAM1_MD_TX: R69.2, U19.10 (~3OE); also elsewhere on the board
SAM2_MD_TX: R70.2, U19.13 (~4OE); also elsewhere on the board
SYNC: R72.1; also elsewhere on the board
TRIG: R73.1; also elsewhere on the board
UART_MD: R71.2, U19.3 (1Y), U19.6 (2Y), U19.8 (3Y), U19.11 (4Y); also elsewhere on the board

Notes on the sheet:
ONBOARD OPEN-DRAIN UART
All four RX inputs observe UART_MD. TX high releases; TX low sinks. No active-high drivers. Rate depends on measured rise time; firmware arbitrates.
EXTERNAL RS-485
DE low / RE_N high: reset shutdown. Fixed local termination; remote end also needs 120R. Both wires within +/-5.5 V of board GND (ADR-038).
Manual bench: disable / disconnect the RS-485 peer before USB power-off or suspend; bias can feed SYS. No automatic isolation or bias switch fitted.
Terminal block and TVS are on the test-access sheet.

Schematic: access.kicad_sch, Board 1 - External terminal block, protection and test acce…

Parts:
D8, D9: ESD2CAN24DBZRQ1; SOT-23; MPN ESD2CAN24DBZRQ1
D10: ESDS452DBZR; SOT-23; MPN ESDS452DBZR
J12: 1989803 / bus terminals; PhoenixContact_PTSA_0.5_8-2.5-F_1989803; MPN 1989803
J13: GW GND; PinHeader_1x02_P2.54mm_Vertical; MPN PRPC002SAAN-RC
J14: SAM0 GND; PinHeader_1x02_P2.54mm_Vertical; MPN PRPC002SAAN-RC
J15: SAM1 GND; PinHeader_1x02_P2.54mm_Vertical; MPN PRPC002SAAN-RC
J16: SAM2 GND; PinHeader_1x02_P2.54mm_Vertical; MPN PRPC002SAAN-RC
J17: POWER GND; PinHeader_1x02_P2.54mm_Vertical; MPN PRPC002SAAN-RC
J18: BUS GND; PinHeader_1x02_P2.54mm_Vertical; MPN PRPC002SAAN-RC
J19: CAN A; PinHeader_1x02_P2.54mm_Vertical; MPN PRPC002SAAN-RC
J20: CAN B; PinHeader_1x02_P2.54mm_Vertical; MPN PRPC002SAAN-RC
J21: RS485; PinHeader_1x02_P2.54mm_Vertical; MPN PRPC002SAAN-RC
J22: RING01; PinHeader_1x02_P2.54mm_Vertical; MPN PRPC002SAAN-RC
J23: RING12; PinHeader_1x02_P2.54mm_Vertical; MPN PRPC002SAAN-RC
J24: RING20; PinHeader_1x02_P2.54mm_Vertical; MPN PRPC002SAAN-RC
J25: UART_MD; PinHeader_1x02_P2.54mm_Vertical; MPN PRPC002SAAN-RC
TP1: VBUS_RAW; TestPoint_Pad_D2.0mm; MPN NA
TP2: USB_5V; TestPoint_Pad_D2.0mm; MPN NA
TP3: FTDI_3V3; TestPoint_Pad_D2.0mm; MPN NA
TP4: 3V3_SYS; TestPoint_Pad_D2.0mm; MPN NA
TP5: GW_RESET_N; TestPoint_Pad_D2.0mm; MPN NA
TP6: GW_BOOT0; TestPoint_Pad_D2.0mm; MPN NA
TP7: SAM0_RESET_N; TestPoint_Pad_D2.0mm; MPN NA
TP8: SAM0_VDDCORE; TestPoint_Pad_D2.0mm; MPN NA
TP9: SAM1_RESET_N; TestPoint_Pad_D2.0mm; MPN NA
TP10: SAM1_VDDCORE; TestPoint_Pad_D2.0mm; MPN NA
TP11: SAM2_RESET_N; TestPoint_Pad_D2.0mm; MPN NA
TP12: SAM2_VDDCORE; TestPoint_Pad_D2.0mm; MPN NA

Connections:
3V3_SYS: TP4.1; also elsewhere on the board
FD_CAN_A_H: D8.1 (IO1), J12.1, J19.1; also elsewhere on the board
FD_CAN_A_L: D8.2 (IO2), J12.2, J19.2; also elsewhere on the board
FD_CAN_B_H: D9.1 (IO1), J12.4, J20.1; also elsewhere on the board
FD_CAN_B_L: D9.2 (IO2), J12.5, J20.2; also elsewhere on the board
FTDI_3V3: TP3.1; also elsewhere on the board
GND: D8.3 (GND), D9.3 (GND), D10.3 (GND), J12.3, J12.8, J13.1, J13.2, J14.1, J14.2, J15.1, J15.2, J16.1, J16.2, J17.1, J17.2, J18.1, J18.2, J22.2, J23.2, J24.2, J25.2; also elsewhere on the board
GW_BOOT0: TP6.1; also elsewhere on the board
GW_RESET_N: TP5.1; also elsewhere on the board
RING_01: J22.1; also elsewhere on the board
RING_12: J23.1; also elsewhere on the board
RING_20: J24.1; also elsewhere on the board
RS485_A: D10.1 (IO1), J12.6, J21.1; also elsewhere on the board
RS485_B: D10.2 (IO2), J12.7, J21.2; also elsewhere on the board
SAM0_RESET_N: TP7.1; also elsewhere on the board
SAM0_VDDCORE: TP8.1; also elsewhere on the board
SAM1_RESET_N: TP9.1; also elsewhere on the board
SAM1_VDDCORE: TP10.1; also elsewhere on the board
SAM2_RESET_N: TP11.1; also elsewhere on the board
SAM2_VDDCORE: TP12.1; also elsewhere on the board
UART_MD: J25.1; also elsewhere on the board
USB_5V: TP2.1; also elsewhere on the board
VBUS_RAW: TP1.1; also elsewhere on the board

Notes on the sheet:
EXTERNAL BUS TERMINALS
TVS channels stay connected when CAN termination shunts are removed. Place all three arrays at terminal entry.
FITTED SCOPE GROUND POSTS
Six dedicated 1x2 headers, both contacts grounded. Place near the named circuit with room for a scope clip.
PCB TEST PADS — power / reset / core rails (TP1–TP12)

Board: 2 copper layers, 243 parts (0 on the bottom side), 152 nets, no tracks yet.

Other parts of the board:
H1, H2, H3, H4: M3 NPTH; MountingHole_3.2mm_M3

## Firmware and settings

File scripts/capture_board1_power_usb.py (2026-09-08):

#!/usr/bin/env python3
"""Initial Board 1 power/USB capture. Native KiCad 7 schematics; no PCB layout.

The .kicad_sch files become the editing authority after capture. This script is
retained as capture provenance; do not rerun over subsequent manual CAD edits.
"""
import csv, json, math, re, uuid, copy
from pathlib import Path

ROOT=Path(__file__).resolve().parents[1]
OUT=ROOT/'boards/board1/kicad'
SYS=Path('/usr/share/kicad/symbols')
class Atom(str): pass
def parse(s):
    ts=re.findall(r'"(?:\\.|[^"\\])*"|[()]|[^\s()]+',s); i=0
    def one():
        nonlocal i
        t=ts[i]; i+=1
        if t=='(':
            a=[]
            while ts[i]!=')':a.append(one())
            i+=1;return a
        return json.loads(t) if t.startswith('"') else Atom(t)
    return one()
def dump(x):
    if isinstance(x,list):return '('+' '.join(map(dump,x))+')'
    if isinstance(x,Atom):return x
    return json.dumps(x,ensure_ascii=False)
def items(x,k):return [a for a in x if isinstance(a,list) and a and a[0]==k]
def item(x,k):return items(x,k)[0]
def uid(s):return str(uuid.uuid5(uuid.NAMESPACE_URL,'ws-hardware/board1/reva/power-usb/'+s))
def q(s):return json.dumps(str(s),ensure_ascii=False)
def fmt(x):return f'{x:.4f}'.rstrip('0').rstrip('.') if isinstance(x,float) else str(x)
def xy(p):return f'{fmt(p[0])} {fmt(p[1])}'
def effects(size=1.0,justify='',hide=False):
    return f'(effects (font (size {size} {size}))'+(f' (justify {justify})' if justify else '')+(' hide' if hide else '')+')'

rows={r['item_id']:r for r in csv.DictReader((ROOT/'boards/board1/bom_internal.csv').open())}
cache={}
def lib(libid):
    if libid not in cache:
        if libid=='Board1:FT232HL_BusPowered':
            symbol=copy.deepcopy(lib('Interface_USB:FT232H'));symbol[1]=libid
            for part in items(symbol,'symbol'):
                part[1]=part[1].replace('FT232H_', 'FT232HL_BusPowered_')
                for p in items(part,'pin'):
                    n=item(p,'number')[1]
                    if n in ['39','44','45']:p[1]=Atom({'39':'power_out','44':'output','45':'bidirectional'}[n])
            cache[libid]=symbol
            return symbol
        a,b=libid.split(':');p=ROOT/f'libraries/symbols/{a}/{a}.kicad_sym'
        if not p.exists():p=SYS/f'{a}.kicad_sym'
        symbol=copy.deepcopy(next(s for s in items(parse(p.read_text()),'symbol') if s[1]==b))
        assert not items(symbol,'extends'),libid
        symbol[1]=libid;cache[libid]=symbol
    return cache[libid]

manifest={}; counts={}
class Sheet:
    def __init__(self,name,title,page):
        self.name=name;self.title=title;self.page=page;self.id=uid(name);self.body=[];self.wires=[];self.libs=set();self.components={};self.pins={};self.nc=set();self.serial=0
        self.path='/'+uid('board1')+(('/'+uid('usb-sheet')) if name!='board1' else '')
    def unique(self,kind):self.serial+=1;return uid(self.name+kind+str(self.serial))
    def add(self,s):self.body.append(s)
    def wire(self,*pts):
        for a,b in zip(pts,pts[1:]):
            if a==b:continue
            assert a[0]==b[0] or a[1]==b[1],(a,b)
            self.wires.append((a,b))
    def junction(self,p):self.add(f'(junction (at {xy(p)}) (diameter 0) (color 0 0 0 0) (uuid {self.unique("j")}))')
    def text(self,s,x,y,size=1.4):self.add(f'(text {q(s)} (at {x} {y} 0) {effects(size,"left top")} (uuid {self.unique("txt")}))')
    def label(self,net,p,angle=0,glob=False):
        if glob:
            self.add(f'(global_label {q(net)} (shape input) (at {xy(p)} {angle}) {effects(1.0,"left" if angle in (0,90) else "right")} (uuid {self.unique("gl")}))')
        else:self.add(f'(label {q(net)} (at {xy(p)} {angle}) {effects(1.0,"left bottom")} (uuid {self.unique("label")}))')
    def symbol(self,libid,ref,x,y,bom=None,val=None,angle=0,unit=1,fp=None,fields=None,show=None):
        l=lib(libid);self.libs.add(libid);rootname=libid.split(':')[1]
        props={s[1]:s[2] for s in items(l,'property')}
        r=rows.get(bom,{})
        value=val or r.get('mpn') or props.get('Value',rootname)
        foot=fp if fp is not None else props.get('Footprint','')
        if foot=='TBD':foot=''
        instuid=uid(f'{self.name}/{ref}/{unit}')
        # Component data fields are in the native CAD and exported BOM.
        props={'Reference':ref,'Value':value,'Footprint':foot,'Datasheet':props.get('Datasheet','')}
        if bom:props.update({'BOM_ID':bom,'MPN':r.get('mpn',value),'Manufacturer':r.get('manufacturer','TBD')})
        if fields:props.update(fields)
        if ref.startswith('#'):ib='no'; ob='no'
        else:ib=ob='yes'
        ss=[f'(symbol (lib_id {q(libid)}) (at {x} {y} {angle}) (unit {unit}) (in_bom {ib}) (on_board {ob}) (dnp no) (uuid {instuid})']
        if show is None:
            if ref.startswith(('R','C','L','FB','Y','D')):show=((x+3.2,y-1.5),(x+3.2,y+1.5),'left') if angle==0 else ((x,y-5.2),(x,y-2.6),'')
            else:show=((x,y-19),(x,y-16),'')
        for idx,(key,v) in enumerate(props.items()):
            if key in ('Reference','Value'):
                pos=show[0 if key=='Reference' else 1];eff=effects(1.15 if key=='Reference' else 1.0,show[2],hide=ref.startswith('#') and key=='Reference')
            else:pos=(x,y);eff=effects(1.0,hide=True)
            ss.append(f'(property {q(key)} {q(v)} (at {xy(pos)} {angle % 180}) {eff})')
        pins=[]
        for part in items(l,'symbol'):
            match=re.search(r'_(\d+)_(\d+)$',part[1])
            if match and int(match[1]) in (0,unit):pins+=items(part,'pin')
        for p in pins:
            n=item(p,'number')[1];a=item(p,'at');px,py,pa=map(float,a[1:4]);rad=math.radians(angle)
            loc=(round(x+px*math.cos(rad)-py*math.sin(rad),4),round(y-px*math.sin(rad)-py*math.cos(rad),4))
            self.pins[(ref,n)]=(loc,(pa+angle)%360)
            ss.append(f'(pin {q(n)} (uuid {uid(ref+"/pin/"+n)}))')
        ss.append(f'(instances (project "board1" (path {q(self.path)} (reference {q(ref)}) (unit {unit})))) )')
        self.add('\n'.join(ss));self.components[ref]={'lib_id':libid,'BOM_ID':bom,'MPN':props.get('MPN',value),'value':value,'footprint':foot,'sheet':self.name}
        manifest.setdefault(ref,dict(self.components[ref],pins={}))
        return ref
    def pt(self,ref,pin):return self.pins[(ref,str(pin))][0]
    def net(self,ref,pin,net,length=7.62,glob=False):
        pin=str(pin);p,a=self.pins[(ref,pin)];rad=math.radians(a)
        end=(round(p[0]-length*math.cos(rad),4),round(p[1]+length*math.sin(rad),4))
        self.wire(p,end)
        if net=='GND':self.ground(end)
        else:self.label(net,end,90 if a==270 else 270 if a==90 else 0,glob)
        manifest[ref]['pins'][pin]=net
        return end
    def mark(self,ref,pins,net):
        for pin in pins:manifest[ref]['pins'][str(pin)]=net
    def noconnect(self,ref,pin):
        p=self.pt(ref,pin);self.add(f'(no_connect (at {xy(p)}) (uuid {self.unique("nc")}))');self.nc.add((ref,str(pin)));manifest[ref]['pins'][str(pin)]=None
    def ground(self,p):
        self.serial+=1;ref=f'#PWR{self.page}{self.serial:03}'
        self.symbol('power:GND',ref,*p,val='GND',show=((p[0],p[1]+5),(p[0],p[1]+5),''))
    def passive(self,kind,ref,x,y,bom,value,net1,net2,angle=0,fp=None,glob=False):
        self.symbol('Device:'+kind,ref,x,y,bom,val=value,angle=angle,fp=fp)
        self.net(ref,1,net1,3.81,glob);self.net(ref,2,net2,3.81,glob)
    def save(self):
        # KiCad connectivity requires segments to terminate at each T junction.
        ends={p for ab in self.wires for p in ab}|{v[0] for v in self.pins.values()}
        for a,b in self.wires:
            pts=sorted(p for p in ends if min(a[0],b[0])<=p[0]<=max(a[0],b[0]) and min(a[1],b[1])<=p[1]<=max(a[1],b[1]))
            for p1,p2 in zip(pts,pts[1:]):
                self.add(f'(wire (pts (xy {xy(p1)}) (xy {xy(p2)})) (stroke (width 0) (type default)) (uuid {self.unique("wire")}))')
        libtext='\n'.join(dump(cache[n]) for n in sorted(self.libs))
        header=f'(kicad_sch (version 20230121) (generator ws_hardware_capture) (uuid {self.id}) (paper "A3")\n(title_block (title {q(self.title)}) (date "2026-09-07") (rev "A-draft") (company "WireSpaces") (comment 1 "Power / USB capture only - no PCB layout"))\n(lib_symbols\n{libtext}\n)\n'
        if self.page==1:self.add('(sheet_instances (path "/" (page "1")))')
        (OUT/(self.name+'.kicad_sch')).write_text(header+'\n'.join(self.body)+'\n)\n')

CAP='Capacitor_SMD:C_0805_2012Metric';RES='Resistor_SMD:R_0805_2012Metric'
R1206='Resistor_SMD:R_1206_3216Metric';C1206='Capacitor_SMD:C_1206_3216Metric';C1210='Capacitor_SMD:C_1210_3225Metric'
def cap(s,ref,x,y,bid,value,net,fp=CAP,glob=True):s.passive('C',ref,x,y,bid,value,net,'GND',fp=fp,glob=glob)
def pull(s,ref,x,y,bid,rail,net):s.passive('R',ref,x,y,bid,'10k',rail,net,fp=RES,glob=True)
def flag(s,x,y,net,glob=False):
    ref='#FLG'+str(s.page)+str(s.serial)
    s.symbol('power:PWR_FLAG',ref,x,y,val='PWR_FLAG',show=((x,y-5),(x,y-5),''));s.net(ref,1,net,5.08,glob)

def capture():
    OUT.mkdir(parents=True,exist_ok=True)
    s=Sheet('board1','Board 1 - USB input and main power',1)
    s.text('USB-B INPUT AND ATTACHMENT RAMP',20,20,2)
    s.text('3.3 V MAIN BUCK',263,20,2)
    s.symbol('Connector:USB_B','J1',35,65,'B1-B005',fp='Connector_USB:USB_B_OST_USB-B1HSxx_Horizontal',show=((30,51),(30,54),'left'))
    s.symbol('TPS22810DBVT:TPS22810DBVT','U1',175,65,'B1-B044',show=((175,43),(175,46),''))
    s.symbol('Device:D','D1',70,85,'B1-B006',angle=270,fp='Diode_SMD:D_SOD-123F',show=((74,83),(74,86),'left'))
    s.symbol('Device:C','C1',95,85,'B1-B045',val='1u / 25V',fp=CAP)
    s.symbol('Device:R','R1',120,82,'B1-B047',val='1R / pulse',fp=R1206)
    s.symbol('Device:C','C2',120,103,'B1-B046',val='4u7 / 50V',fp=CAP)
    s.symbol('Device:C','C3',150,95,'B1-B048',val='47n',fp=CAP)
    rail_y=s.pt('J1',1)[1]
    s.wire(s.pt('J1',1),(150,rail_y),s.pt('U1',1))
    for ref in ['D1','C1','R1']:
        a=s.pt(ref,1);s.wire(a,(a[0],rail_y));s.junction((a[0],rail_y));s.mark(ref,[1],'VBUS_RAW')
    s.label('VBUS_RAW',(80,rail_y))
    s.wire(s.pt('U1',3),(150,65),(150,rail_y));s.junction((150,rail_y));s.mark('J1',[1],'VBUS_RAW');s.mark('U1',[1,3],'VBUS_RAW')
    s.wire(s.pt('R1',2),s.pt('C2',1));s.mark('R1',[2],'VBUS_DAMP');s.mark('C2',[1],'VBUS_DAMP')
    s.label('VBUS_DAMP',(120,92))
    for ref,pin in [('D1',2),('C1',2),('C2',2),('C3',2),('U1',2)]:s.net(ref,pin,'GND',5.08)
    s.wire(s.pt('J1',5),(32.46,82),(35,82),s.pt('J1',4));s.ground((35,82));s.mark('J1',[4,5],'GND')
    s.wire(s.pt('U1',4),(150,70.08),s.pt('C3',1));s.mark('U1',[4],'IN_CT');s.mark('C3',[1],'IN_CT');s.label('IN_CT',(150,80))
    s.wire(s.pt('U1',6),(245,rail_y));s.wire(s.pt('U1',5),(205,65),(205,rail_y));s.junction((205,rail_y));s.mark('U1',[5,6],'USB_5V');s.label('USB_5V',(215,rail_y),glob=True)
    for ref,x,bid,v in [('C4',220,'B1-B063','4u7'),('C5',243,'B1-B061','100n')]:
        s.symbol('Device:C',ref,x,85,bid,val=v,fp=CAP);s.wire(s.pt(ref,1),(x,rail_y));s.junction((x,rail_y));s.mark(ref,[1],'USB_5V');s.net(ref,2,'GND',5.08)
    s.text('C4/C5: place at FTDI VREGIN (U4 pin 40).',205,104,1.15)
    s.net('J1',2,'USB_DM',20.32,True);s.net('J1',3,'USB_DP',20.32,True)
    s.text('USB shield bonds directly to GND at entry.',20,112,1.15)
    s.text('USB DATA ESD',20,126,1.6)
    s.symbol('RCLAMP0504S.TCT:RCLAMP0504S.TCT','D2',65,158,'B1-B018',show=((78,138),(78,141),'left'))
    s.net('D2',1,'USB_DM',10.16,True);s.net('D2',3,'USB_DP',10.16,True);s.net('D2',2,'GND')
    for p in [4,5,6]:s.noconnect('D2',p)
    s.text('Pin 5 VREF unconnected: internal TVS mode.\nUnused channels 4/6 unconnected. Place at J1.\nRoute USB differential pair directly; avoid stubs.',20,179,1.1)
    s.symbol('TPS560430X3FDBVR:TPS560430X3FDBVR','U2',300,65,'B1-B012',show=((300,39),(300,42),''))
    s.wire((245,rail_y),s.pt('U2',5));s.mark('U2',[5],'USB_5V')
    s.symbol('Device:C','C6',270,85,'B1-B029',val='10u / 35V',fp=C1206);s.wire(s.pt('C6',1),(270,rail_y));s.mark('C6',[1],'USB_5V');s.junction((270,rail_y));s.net('C6',2,'GND')
    cap(s,'C9',290,115,'B1-B052','100n','USB_5V')
    s.symbol('Device:L','L1',345,65,'B1-B028',val='12uH',angle=90,fp='Inductor_SMD:L_Bourns_SRN6045TA')
    s.wire(s.pt('U2',6),s.pt('L1',1));s.mark('U2',[6],'BUCK_SW');s.mark('L1',[1],'BUCK_SW')
    s.symbol('Device:C','C8',327.94,48,'B1-B031',val='100n',angle=90,fp=CAP)
    s.wire(s.pt('U2',1),(315.24,48),s.pt('C8',1));s.mark('U2',[1],'BUCK_CB');s.mark('C8',[1],'BUCK_CB')
    s.wire(s.pt('C8',2),(335.28,48),(335.28,65));s.junction((335.28,65));s.mark('C8',[2],'BUCK_SW')
    s.label('BUCK_SW',(319,65));s.label('BUCK_CB',(315.24,48))
    s.wire(s.pt('L1',2),(380,65));s.mark('L1',[2],'3V3_SYS');s.label('3V3_SYS',(380,65),glob=True)
    s.symbol('Device:C','C7',375,85,'B1-B030',val='22u / 16V',fp=C1210);s.wire(s.pt('C7',1),(375,65));s.mark('C7',[1],'3V3_SYS');s.junction((375,65));s.net('C7',2,'GND')
    s.wire(s.pt('U2',3),(365,70.08),(365,65));s.junction((365,65));s.mark('U2',[3],'3V3_SYS');s.net('U2',2,'GND')
    s.net('U2',4,'BUCK_EN',7.62,True)
    s.text('Fixed X3F: FB senses output directly.\nKeep CB-SW loop short; quiet FB route.\nNo divider, catch diode or external compensation.',310,108,1.1)
    s.text('USB CONFIGURATION / SUSPEND CONTROL',155,133,1.6)
    s.symbol('MC74HC1G14DBVT1G:MC74HC1G14DBVT1G','U3',235,168,'B1-B015',show=((248,148),(248,151),''))
    s.net('U3',2,'PWREN_N',10.16,True);s.net('U3',4,'BUCK_EN',10.16,True);s.net('U3',5,'FTDI_3V3',5.08,True);s.net('U3',3,'GND');s.noconnect('U3',1)
    pull(s,'R2',180,166,'B1-B054','FTDI_3V3','PWREN_N')
    s.passive('R','R3',280,178,'B1-B055','47k','BUCK_EN','GND',fp=RES,glob=True)
    cap(s,'C10',310,178,'B1-B061','100n','FTDI_3V3')
    s.text('PWREN_N low: main rail ON, VCP buffers enabled.\nHigh / floating: main rail OFF (ADR-040).',155,199,1.15)
    s.text('POWER INDICATOR',343,133,1.5)
    s.symbol('Device:R','R4',360,158,'B1-B026',val='3k3',fp=RES);s.net('R4',1,'3V3_SYS',5.08,True)
    s.symbol('Device:LED','D3',360,177,'B1-B025',val='Orange',angle=90,fp='LED_SMD:LED_0603_1608Metric',show=((364,175),(364,178),'left'))
    s.wire(s.pt('R4',2),s.pt('D3',2));s.mark('R4',[2],'PWR_LED_A');s.mark('D3',[2],'PWR_LED_A');s.label('PWR_LED_A',(360,168));s.net('D3',1,'GND',5.08)
    s.add(f'(sheet (at 25 223) (size 105 30) (stroke (width 0) (type solid)) (fill (color 0 0 0 0)) (uuid {uid("usb-sheet")}) (property "Sheetname" "USB bridge and VCP" (at 25 222 0) {effects(1.27,"left bottom")}) (property "Sheetfile" "usb_bridge.kicad_sch" (at 25 254 0) {effects(1.27,"left top")}) (instances (project "board1" (path "/{uid("board1")}" (page "2")))))')
    s.text('USB_5V / USB_DM / USB_DP\nFTDI_3V3 / PWREN_N / 3V3_SYS\nCross-sheet connections use named global nets.',30,229,1.25)
    s.text('USB-only, active-PC bench operation. 500 mA configured input budget.\nPower/USB capture ends at GW_VCP_TX/RX/RTS_N/CTS_N.\nMCU, CAN, RS-485 and timing-header sections are not captured.\nNo external reset supervisor or CBUS recovery circuitry.',155,222,1.3)
    flag(s,160,266,'VBUS_RAW');flag(s,205,266,'GND');flag(s,250,266,'3V3_SYS',True)
    s.save()

    s=Sheet('usb_bridge','Board 1 - FT232HL, EEPROM and isolated VCP',2)
    s.text('INDEPENDENT USB BRIDGE',20,20,2)
    s.text('CONFIGURATION EEPROM',175,20,1.8)
    s.text('VCP POWER-OFF ISOLATION',270,20,1.8)
    s.symbol('Board1:FT232HL_BusPowered','U4',100,100,'B1-B004',val='FT232HL-REEL',fp='Package_QFP:LQFP-48_7x7mm_P0.5mm',show=((78,64),(112,64),''))
    for p,n in {40:'USB_5V',39:'FTDI_3V3',38:'FTDI_VCORE',37:'FTDI_VCCA',6:'USB_DM',7:'USB_DP',34:'FTDI_RESET_N',5:'FTDI_REF',45:'EECS',44:'EECLK',43:'EEDATA',1:'XTIN',2:'XTOUT'}.items():s.net('U4',p,n,20.32,n in ['USB_5V','FTDI_3V3','USB_DM','USB_DP'])
    for p,n in {13:'FTDI_TX',14:'FTDI_RX',15:'FTDI_RTS_N',16:'FTDI_CTS_N',21:'PWREN_N'}.items():s.net('U4',p,n,10.16,True)
    for p in [17,18,19,20,25,26,27,28,29,30,31,32,33]:s.noconnect('U4',p)
    for p in [3,8]:s.net('U4',p,'FTDI_VPHY' if p==3 else 'FTDI_VPLL',15.24)
    for p in [12,24,46]:s.net('U4',p,'FTDI_3V3',7.62,True)
    for p in [4,9,10,11,22,23,35,36,41,47,48]:
        pt=s.pt('U4',p);s.wire(pt,(pt[0],145.72));s.mark('U4',[p],'GND')
    s.wire((89.84,145.72),(115.24,145.72));s.ground((102.54,145.72))
    for p in [9,10,11,22,23,35,36,41,47]:s.junction((s.pt('U4',p)[0],145.72))
    s.net('U4',42,'GND',5.08)
    s.text('Unused ADBUS/ACBUS pins: no connection.\nACBUS5/6 recovery deferred to Rev B.\nVCCA and VCORE each bypass only; never join.',160,110,1.15)
    # Local crystal and reset/reference networks.
    s.symbol('Device:Crystal','Y1',35,135,'B1-B014',val='12MHz / CL18p',fp='Crystal:Crystal_SMD_HC49-SD')
    s.net('Y1',1,'XTIN',7.62);s.net('Y1',2,'XTOUT',7.62)
    cap(s,'C12',20,155,'B1-B058','27p C0G','XTIN',glob=False);cap(s,'C13',48,155,'B1-B058','27p C0G','XTOUT',glob=False)
    s.symbol('Device:R','R5',25,58,'B1-B051',val='10k',fp=RES);s.net('R5',1,'FTDI_3V3',3.81,True)
    s.symbol('Device:C','C14',25,91,'B1-B064',val='10n',fp=CAP);s.net('C14',2,'GND',3.81)
    s.wire(s.pt('R5',2),s.pt('C14',1));s.label('FTDI_RESET_N',(25,75));s.mark('R5',[2],'FTDI_RESET_N');s.mark('C14',[1],'FTDI_RESET_N')
    s.passive('R','R6',47,91,'B1-B057','12k 1%','FTDI_REF','GND',fp=RES)
    s.symbol('AT93C56B-SSHM-B:AT93C56B-SSHM-B','U5',215,75,'B1-B013',show=((228,44),(228,47),''))
    for p,n in {1:'EECS',2:'EECLK',3:'EEDATA',6:'FTDI_3V3',8:'FTDI_3V3'}.items():s.net('U5',p,n,7.62,p in[6,8])
    s.net('U5',5,'GND');s.noconnect('U5',7)
    s.symbol('Device:R','R7',246,72.46,'B1-B056',val='2k2',angle=90,fp=RES)
    s.wire(s.pt('U5',4),s.pt('R7',1));s.mark('U5',[4],'EE_DO');s.mark('R7',[1],'EE_DO');s.label('EE_DO',(232,72.46));s.net('R7',2,'EEDATA',5.08)
    pull(s,'R8',246,95,'B1-B065','FTDI_3V3','EE_DO')
    s.text('ORG=VCC: 128 x 16 words.\nEEDATA to DI; DO through 2k2.\n10k pull-up belongs on DO side.',170,136,1.15)
    # Reference-circuit capacitor population, intentionally omitting optional bulk after beads.
    s.text('FTDI LOCAL SUPPLY DECOUPLING',20,174,1.5)
    for ref,x,bid,v,n in [('C15',25,'B1-B063','4u7','FTDI_3V3'),('C16',52,'B1-B061','100n','FTDI_3V3'),('C17',85,'B1-B061','100n','FTDI_3V3'),('C18',115,'B1-B061','100n','FTDI_3V3'),('C19',145,'B1-B061','100n','FTDI_3V3'),('C20',180,'B1-B061','100n','FTDI_VCORE'),('C21',215,'B1-B061','100n','FTDI_VCCA'),('C11',246,'B1-B061','100n','FTDI_3V3')]:cap(s,ref,x,197,bid,v,n,glob=n=='FTDI_3V3')
    s.text('VCCD pin 39',20,211,1.1);s.text('VCCIO pins 12 / 24 / 46',82,211,1.1);s.text('38',177,211,1.1);s.text('37',212,211,1.1);s.text('U5 pin 8',239,211,1.1)
    for ref,x,y,n,cref in [('FB1',50,233,'FTDI_VPHY','C22'),('FB2',180,233,'FTDI_VPLL','C23')]:
        s.symbol('Device:FerriteBead',''+ref,x,y,'B1-B078',val='600R @ 100MHz',angle=90,fp='Inductor_SMD:L_0805_2012Metric',fields={'MPN':'BLM21AG601SN1D','Manufacturer':'Murata'})
        s.net(ref,1,'FTDI_3V3',10.16,True);s.net(ref,2,n,12.7)
        cap(s,cref,x+35,244,'B1-B061','100n',n,glob=False)
    s.text('Separate ferrite + 100n at VPHY pin 3 and VPLL pin 8.\nFTDI Fig.6.1 optional post-bead bulk not fitted; no DNP footprints.\nAll AGND/GND pins join the board ground plane.',20,261,1.1)
    flag(s,120,239,'FTDI_VPHY');flag(s,245,239,'FTDI_VPLL')
    # One quad buffer; both directions use receiving-domain defaults.
    gates=[(1,65,2,3,1,'FTDI_TX','GW_VCP_RX'),(2,108,5,6,4,'FTDI_RTS_N','GW_VCP_CTS_N'),(3,151,9,8,10,'GW_VCP_TX','FTDI_RX'),(4,194,12,11,13,'GW_VCP_RTS_N','FTDI_CTS_N')]
    for un,y,ap,yp,oe,inn,outn in gates:
        s.symbol('SN74LV125APWR:SN74LV125APWR','U6',310,y,'B1-B016',unit=un,show=((336,y-18),(336,y-15),''))
        s.net('U6',ap,inn,12.7,True);s.net('U6',yp,outn,12.7,True);s.net('U6',oe,'PWREN_N',5.08,True)
        pull(s,'R'+str(8+un),370,y,'B1-B079','3V3_SYS' if un<=2 else 'FTDI_3V3',outn)
    pull(s,'R13',270,151,'B1-B079','3V3_SYS','GW_VCP_TX')
    pull(s,'R14',270,194,'B1-B079','3V3_SYS','GW_VCP_RTS_N')
    s.symbol('SN74LV125APWR:SN74LV125APWR','U6',345,228,'B1-B016',unit=5,show=((361,213),(361,216),''))
    s.net('U6',14,'3V3_SYS',5.08,True);s.net('U6',7,'GND',5.08);cap(s,'C24',385,233,'B1-B036','100n','3V3_SYS')
    s.text('GW_* directions are from the MCU. TX/RX idle high; CTS_N inactive high.\nAll /OE pins directly use PWREN_N (ADR-040).\nThese four GW nets end at the next capture stage.',152,153,1.0)
    s.save()
    custom=copy.deepcopy(cache['Board1:FT232HL_BusPowered']);custom[1]='FT232HL_BusPowered'
    (OUT/'board1_symbols.kicad_sym').write_text('(kicad_symbol_lib (version 20220914) (generator ws_hardware_capture)\n'+dump(custom)+'\n)\n')
    project=json.loads(Path('/usr/share/kicad/template/kicad.kicad_pro').read_text())
    project['meta']['filename']='board1.kicad_pro';project['sheets']=[[uid('board1'),'USB input and power'],[uid('usb_bridge'),'USB bridge and VCP']]
    project['text_variables']={'ASSEMBLY_REV':'A-draft','CAPTURE_SCOPE':'Power and USB only'}
    (OUT/'board1.kicad_pro').write_text(json.dumps(project,indent=2)+'\n')
    # Export complete component/pin intent for checking the independently parsed KiCad netlist.
    manifest_real={r:v for r,v in manifest.items() if not r.startswith('#')}
    (OUT/'capture_manifest.json').write_text(json.dumps(manifest_real,indent=2)+'\n')
    print(f'Captured {len(manifest_real)} physical parts in two native schematic sheets.')

if __name__=='__main__':capture()

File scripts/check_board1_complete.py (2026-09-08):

#!/usr/bin/env python3
"""Check full Board 1 native connectivity and component records.

Exports KiCad XML and checks every physical symbol pin (including explicit NCs),
fields, footprint pad coverage, and BOM inventory. This is not ERC, pin-mux
qualification, footprint dimensional qualification, or hardware validation.

Optional kicad/schematic_bom_allocations.json records BOM rows whose procurement quantity
differs from the number of CAD symbols, for example purchased strip stock and
loose shunts. Each entry is keyed by BOM ID and must contain cad_count,
bom_quantity, and reason. An optional footprints list explicitly permits multiple
cut-strip/test-access footprints for one BOM row. These exceptions never waive
the symbol-to-manifest field or numbered-pad checks.
"""

import argparse
from collections import Counter, defaultdict
import csv
import json
import os
from pathlib import Path
import re
import subprocess
import tempfile
import xml.etree.ElementTree as ET

ROOT = Path(__file__).resolve().parents[1]
CAD = ROOT / 'boards/board1/kicad'


class CheckFailure(Exception):
    pass


def require(condition, message):
    if not condition:
        raise CheckFailure(message)


def sexpressions(text):
    """Read library tables/footprints without matching pad-like quoted text."""
    tokens = re.findall(r'"(?:\\.|[^"\\])*"|[()]|[^\s()]+', text)
    stack, roots = [], []
    for token in tokens:
        if token == '(':
            node = []
            (stack[-1] if stack else roots).append(node)
            stack.append(node)
        elif token == ')':
            require(bool(stack), 'Unbalanced S-expression')
            stack.pop()
        else:
            require(bool(stack), 'Token outside S-expression')
            stack[-1].append(json.loads(token) if token.startswith('"') else token)
    require(not stack, 'Unterminated S-expression')
    return roots


def children(node, key):
    return [item for item in node if isinstance(item, list) and item and item[0] == key]


def footprint_paths():
    """Resolve project-local libraries first, followed by installed libraries."""
    result = {}
    version = subprocess.check_output(['kicad-cli', '--version'], text=True).split('.')[0]
    standard = Path(os.environ.get(f'KICAD{version}_FOOTPRINT_DIR', '/usr/share/kicad/footprints'))
    for folder in standard.glob('*.pretty'):
        result[folder.stem] = folder
    variables = dict(os.environ, KIPRJMOD=str(CAD))
    variables.setdefault(f'KICAD{version}_FOOTPRINT_DIR', str(standard))
    for table in [Path.home() / '.config/kicad' / f'{version}.0' / 'fp-lib-table',
                  ROOT / 'fp-lib-table', CAD / 'fp-lib-table']:
        if not table.exists():
            continue
        for form in sexpressions(table.read_text()):
            for entry in children(form, 'lib'):
                name, uri = children(entry, 'name'), children(entry, 'uri')
                if name and uri:
                    expanded = re.sub(r'\$\{([^}]+)\}', lambda m: variables.get(m[1], m[0]), uri[0][1])
                    location = Path(expanded)
                    result[name[0][1]] = location if location.is_absolute() else table.parent / location
    return result


def exported_root(netlist=None):
    if netlist:
        return ET.parse(netlist).getroot()
    with tempfile.TemporaryDirectory(prefix='board1-check-') as directory:
        path = Path(directory) / 'board1.xml'
        subprocess.run(['kicad-cli', 'sch', 'export', 'netlist', '--format', 'kicadxml',
                        '-o', str(path), str(CAD / 'board1.kicad_sch')], check=True)
        return ET.parse(path).getroot()


def inventory(expected, bom, allocations):
    counts = Counter(spec['BOM_ID'] for spec in expected.values())
    require(set(allocations) <= set(bom), 'Allocation refers to an unknown BOM ID')
    for bid, row in bom.items():
        raw_quantity = row['quantity']
        require(raw_quantity.isdecimal(), f'{bid}: resolve BOM quantity {raw_quantity!r} for complete capture')
        quantity = int(raw_quantity)
        if bid in allocations:
            entry = allocations[bid]
            require(isinstance(entry.get('cad_count'), int) and entry['cad_count'] >= 0,
                    f'{bid}: allocation requires a nonnegative cad_count')
            require(entry.get('bom_quantity') == quantity and bool(entry.get('reason', '').strip()),
                    f'{bid}: allocation quantity/reason differs from BOM')
            require(counts[bid] == entry['cad_count'],
                    f'{bid}: {counts[bid]} CAD parts, allocation requires {entry["cad_count"]}')
        else:
            require(counts[bid] == quantity, f'{bid}: {counts[bid]} CAD parts, BOM quantity {quantity}')
    require(set(counts) <= set(bom), 'CAD contains unknown BOM IDs')


def preserved_power_usb(expected):
    """Keep the completed first-stage capture intact when adding board sheets."""
    original = json.loads((CAD / 'capture_manifest.json').read_text())
    require(len(original) == 52, 'Original power/USB manifest must contain its 52 physical parts')
    for ref, before in original.items():
        require(ref in expected, f'{ref}: preserved power/USB component is missing')
        after = expected[ref]
        # ADR-045 changes only these two MPNs; retain every other capture invariant.
        if ref in {'C12', 'C13'}:
            require(before['MPN'] == 'C0805C270F5GACTU', f'{ref}: unexpected historical MPN')
            before = dict(before, MPN='CC0805FRNPO9BN270')
        require({key: value for key, value in before.items() if key != 'sheet'}
                == {key: value for key, value in after.items() if key != 'sheet'},
                f'{ref}: completed power/USB component fields or pin mapping changed')
        require(after['sheet'] == ('power' if before['sheet'] == 'board1' else before['sheet']),
                f'{ref}: unexpected power/USB sheet relocation')
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

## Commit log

2026-09-07 Add Board 1 design baseline and project-local KiCad symbols
    [bom.csv, samc21_pin_allocation.xlsx]
2026-09-07 Complete Board 1 IC symbols and record TVS selections
    [bom.csv]
2026-09-07 Consolidate Board 1 design notes and record BOM closeout
    [bom.csv]
2026-09-07 Remove obsolete design research and clarify current ADR authority
    [bom.csv]
2026-09-07 Separate power scenarios and automate BOM cleanup checks
2026-09-07 Fix review findings in BOM references and drift audits
    [bom.csv]
2026-09-07 Cleanup and improve AGENTS.md
    [samc21_pin_allocation.xlsx]
2026-09-07 Finalize MCU headers
    [bom.csv, samc21_pin_allocation.xlsx]
2026-09-07 First draft finished
    [access.kicad_sch, board1.kicad_sch, bom.csv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]
2026-09-08 High-level layout done
    [access.kicad_sch, board1.kicad_pcb, board1.kicad_sch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]
